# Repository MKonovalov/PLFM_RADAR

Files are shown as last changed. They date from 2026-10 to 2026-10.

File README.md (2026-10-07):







# AERIS-10: Open Source Pulse Linear Frequency Modulated Phased Array Radar








AERIS-10 is an open-source, low-cost 10.5 GHz phased array radar system featuring Pulse Linear Frequency Modulated (LFM) modulation. Available in two versions (3km and 20km range, see [Basis of the published performance numbers](#-basis-of-the-published-performance-numbers) for the detection assumptions behind the range figures), it's designed for researchers, drone developers, and serious SDR enthusiasts who want to explore and experiment with phased array radar technology.

AERIS-10 Antenna Array

## 📡 Overview

The AERIS-10 project aims to democratize radar technology by providing a fully open-source, modular, and hackable radar system. Whether you're a university researcher, a drone startup, or an advanced maker, AERIS-10 offers a platform for experimenting with beamforming, pulse compression, Doppler processing, and target tracking.

## 🔬 Key Features

- **Open Source Hardware & Software** - Complete schematics, PCB layouts, firmware, and software available
- **Dual Version Availability**:
  - **AERIS-10N (Nexus)**: 3km range with 8x16 patch antenna array
  - **AERIS-10E (Extended)**: 20km range with 32x16 dielectric-filled slotted waveguide array
- **Full Electronic Beam Steering** - ±45° electronic steering in elevation and azimuth (characterised for the 8x16 patch array in `docs/AERIS_Antenna_Report.pdf`; the 32x16 waveguide array has no published element-pattern analysis yet — see the basis section below)
- **Advanced Signal Processing** - On-board FPGA handles pulse compression, Doppler FFT, MTI, and CFAR
- **Python GUI** - User-friendly interface with map integration
- **GPS/IMU Integration** - Real-time position and attitude correction
- **Modular Design** - Separate power management, frequency synthesis, and RF boards

## 🏗️ System Architecture

AERIS-10 System Diagram

### Hardware Components

The AERIS-10 main sub-systems are:

- **Power Management Board** - Supplies all necessary voltage levels to the electronics components with proper filtering and sequencing (sequencing ensured by the microcontroller)

- **Frequency Synthesizer Board** - Uses a high-performance Low Jitter Clock Generator (AD9523-1) that supplies phase-aligned clock references for:
  - RX and TX Frequency Synthesizers (ADF4382)
  - DAC
  - ADC
  - FPGA

- **Main Board** containing:
  - **DAC** - Generates the RADAR Chirps
  - **2x Microwave Mixers (LTC5552)** - For up-conversion and IF-down-conversion
  - **4x 4-Channel Phase Shifters (ADAR1000)** - For RX and TX chain beamforming
  - **16x Front End Chips (ADTR1107)** - Used for both Low Noise Amplifying (RX) and Power Amplifying (TX) stages
  - **XC7A50T FPGA** - Handles RADAR Signal Processing on the upstream FTG256 board:
    - PLFM Chirps generation via the DAC
    - Raw ADC data read
    - Hybrid Automatic Gain Control (AGC) — cross-layer FPGA/STM32/GUI loop
    - I/Q Baseband Down-Conversion
    - Decimation
    - Filtering
    - Forward FFT
    - Pulse Compression
    - Doppler, MTI and CFAR processing
    - USB Interface
  - **STM32F746xx Microcontroller** - Used for:
    - Power-up and power-down sequencing (see Power Management Excel File)
    - FPGA communication
    - Setup and Interface with:
      - Clock Generator (AD9523-1)
      - 2x Frequency Synthesizers (ADF4382)
      - 4x 4-Channel Phase Shifters (ADAR1000) for RADAR pulse sequencing
      - 2x ADS7830 8-channel I²C ADCs (Main Board, U88 @ 0x48 / U89 @ 0x4A) for 16x Idq measurement, one per PA channel, each sensed through a 5 mΩ shunt on the PA board and an INA241A3 current-sense amplifier (x50) on the Main Board
      - 2x DAC5578 8-channel I²C DACs (Main Board, U7 @ 0x48 / U69 @ 0x49) for 16x Vg control, one per PA channel; closed-loop calibrated at boot to the target Idq
      - GPS module (UM982) for GUI map centering and per-detection position tagging
      - GY-85 IMU for pitch/roll correction of target coordinates
      - BMP180 Barometer
      - Stepper Motor
      - 1x ADS7830 8-channel I²C ADC (Main Board, U10) reading 8 thermistors for thermal monitoring; a single GPIO (EN_DIS_COOLING) switches the cooling fans on when any channel exceeds the threshold
      - RF switches

- **16x Power Amplifier Boards** - Used only for AERIS-10E version, featuring 10Watt QPA2962 GaN amplifier for extended range

- **Antenna Arrays**:
  - **AERIS-10N (Nexus)** - 8x16 patch antenna array
  - **AERIS-10X (Extended)** - 32x16 dielectric-filled slotted waveguide antenna array

- **Miscellaneous Components**:
  - Slip-Ring
  - Stepper Motor and drivers
  - Cooling Fans
  - Enclosure

### Processing Pipeline

1. **Waveform Generation** - DAC creates LFM chirps
2. **Up/Down Conversion** - LTC5552 mixers handle frequency translation
3. **Beam Steering** - ADAR1000 phase shifters control 16 elements
4. **Signal Processing (FPGA)**:
   - Raw ADC data capture
   - I/Q baseband down-conversion
   - Decimation & filtering (CIC/FIR)
   - Pulse compression
   - Doppler FFT processing
   - MTI & CFAR detection
5. **System Management (STM32)**:
   - Power sequencing
   - Peripheral configuration
   - GPS/IMU integration
   - Stepper motor control
6. **Visualization (Python GUI)**:
   - Real-time target plotting
   - Map integration
   - Radar control interface

AERIS-10 Dashboard
<!-- V6 GIF removed — V6 is deprecated. V65 Tk and V7 PyQt6 are the active GUIs. -->

## 📊 Technical Specifications

| Parameter | AERIS-10N (Nexus) | AERIS-10X (Extended) |
|---|---|---|
| **Frequency** | 10.5 GHz | 10.5 GHz |
| **Max Range** | 3 km ¹ | 20 km ¹ |
| **Antenna** | 8x16 Patch Array | 32x16 Slotted Waveguide |
| **Beam Steering** | Electronic (±45°) ² | Electronic (±45°) ² |
| **Mechanical Scan** | 360° (stepper motor) | 360° (stepper motor) |
| **Output Power** | ~1W×16 | 10W×16 (GaN amplifier) |
| **Processing** | FPGA + STM32 | FPGA + STM32 |
| **Data Interface** | FT2232H USB 2.0 — ~40 MB/s ³ | FT2232H USB 2.0 — ~40 MB/s ³ |

## 📐 Basis of the published performance numbers

The figures above are specifications the design targets, not measured results from a
built unit.  They are only meaningful with their detection assumptions attached, so:

1. **Range.** The 3 km / 20 km figures are single-pulse-budget numbers for a **1 m² RCS**
   target at long dwell (many pulses integrated coherently).  Detection range scales as the
   fourth root of RCS and as the fourth root of integration time, so the same radar sees a
   **0.01 m² target (small drone) at roughly 6 km**, not 20 km.  Quote the target RCS and
   the dwell whenever you quote a range.  The repository carries no link-budget document
   that derives these numbers; `docs/AERIS_Antenna_Report.pdf` covers antenna gain and
   element pattern only.
2. **Beam steering.** ±45° with ~2–3 dB scan loss is the characterised result for the
   **8x16 patch array** (4.72 dBi element, 21.1 dB array factor, ~25.8 dBi realised gain,
   ~75–85° element half-power beamwidth).  Applying the same figure to the 32x16
   slotted-waveguide array is an extrapolation: no element pattern, grating-lobe analysis
   or measured scan loss is published for that array yet.
3. **Data interface.** The FT2232H interface runs at 60 MHz (≈40 MB/s), while the
   400 MSPS ADC produces ≈3.2 Gbit/s raw.  The link therefore carries **processed
   detections/Doppler products only — there is no raw IQ streaming path** at full rate.
4. **The waveguide array's dimensions do not agree inside its own spec.**
   `Dielectric_Filled_Waveguide_Array_Spec.docx` states an inter-column pitch of
   λ₀/2 ≈ 14.28 mm and a **panel height (16 columns) of 223 mm**.  Sixteen columns at
   that pitch span 16 × 14.28 = **228.5 mm**, and the centre-to-centre aperture is
   15 × 14.28 = **214.2 mm** — so 223 mm matches neither convention (5.5 mm and 8.8 mm
   apart respectively).  The spec's own directivity (27.73 dBi) and EIRP (54.8 dBW) are
   derived from A = 0.173 m × 0.223 m = 0.0385 m², i.e. they use the 223 mm height.
   The fabrication drawing has to say which convention it uses before a panel is cut:
   the directivity difference is only ~0.2 dB, so the performance number stands either
   way — it is the drawing that needs reconciling with the spec table.

   **Harmonic emissions.**  Wherever EIRP is quoted above, the harmonic figure belongs with it: the
   PA's 2nd and 3rd harmonics (21.0 and 31.5 GHz) are suppressed by the inline output filter, whose
   specification is in `docs/harmonic-filter.md`.  The chosen part rejects **≥40 dB across
   19.5–32 GHz**, against a requirement of ≥20 dB below carrier at the antenna port — so the design
   carries 20 dB of margin, and the *measured* figure is a first-article item recorded in
   `docs/bring-up-acceptance.md`.

## 🚀 Getting Started

### 🧹 Repository File Placement Policy

To keep the repository root clean and make artifacts easy to find, place generated files in the following locations:

- **Published reports (tracked, GitHub Pages):** `docs/`
  - Example: `docs/AERIS_Simulation_Report_v2.pdf`
- **Simulation-generated outputs (local, gitignored):** `5_Simulations/generated/`
  - Plots, scenario outputs, temporary analysis directories
- **FPGA/Vivado generated artifacts (local, gitignored):** `9_Firmware/9_2_FPGA/reports/`
  - VCD/VVP dumps, temporary CSVs, local report snapshots
- **Reusable FPGA automation scripts (tracked):** `9_Firmware/9_2_FPGA/scripts/`
  - TCL flows, helper scripts used by build/bring-up
- **Generated board artifacts (tracked):** `4_Schematics and Boards Layout/4_7_Production Files/Board_Artifacts/`
  - BOM/CPL CSVs, the DNP list, the inter-board rail map and the accepted-discrepancy baseline,
    all regenerated by `9_Firmware/tools/` and checked in CI

**Do not leave generated artifacts in the repository root.**

### Prerequisites

- Basic understanding of radar principles
- Experience with PCB assembly (for hardware build)
- Python 3.8+ for the GUI software
- FPGA development tools (Vivado) for signal processing modifications

### Hardware Assembly

1. **Order PCBs**: Production outputs are under `/4_Schematics and Boards Layout/4_7_Production Files`
2. **Source Components**: BOM/CPL files are co-located under `/4_Schematics and Boards Layout/4_7_Production Files`
3. **Assembly**: Use the schematics in `/4_Schematics and Boards Layout/4_6_Schematics` together with the production outputs above; a standalone assembly guide is not currently tracked
4. **Antenna**: Choose appropriate array files for your target variant
5. **Enclosure**: Mechanical drawings currently live in `/8_Utils/Mechanical_Drawings`

## 📜 License

This project is open-source but uses **different licenses for hardware and software** to ensure proper legal coverage.

### Hardware Documentation
The hardware design files—including:
- Schematics and PCB layouts (in `/4_Schematics and Boards Layout`)
- Bill of Materials (BOM) files
- Gerber files and manufacturing outputs
- Mechanical drawings and enclosure designs

are licensed under the **CERN Open Hardware Licence Version 2 – Permissive (CERN-OHL-P)** .

This is a hardware-specific license that:
- ✅ Clearly defines "Hardware," "Documentation," and "Products"
- ✅ Includes explicit patent protection for contributors and users
- ✅ Provides stronger liability limitations (important for high-power RF)
- ✅ Aligns with professional open-hardware standards (CERN, OSHWA)

You may use, modify, and sell products based on these designs, provided you:
- Maintain the original copyright notices
- Distribute any modified designs under the same license
- Make your modifications available in Source format

### Software and Firmware
The software components—including:
- FPGA code (VHDL/Verilog in `/9_Firmware`)
- Microcontroller firmware (STM32)
- Python GUI and utilities

remain under the **MIT License** for maximum flexibility.

### Full License Texts
- The complete CERN-OHL-P license text is in the `Licence` file (note the spelling — there is no `LICENSE` file)
- The MIT text covering `9_Firmware` (MCU firmware, FPGA RTL, tools) and the GUI/SDK is in `9_Firmware/LICENSE`

### Why This Change?
Originally, the entire project used the MIT license. The community (special thanks to gmaynez!) pointed out that MIT lacks legal protections needed for physical hardware. The switch to CERN-OHL-P ensures the project is properly protected while maintaining the same permissive spirit.

## 📚 Documentation

Comprehensive documentation is available in the `/docs` folder and served via GitHub Pages at [https://NawfalMotii79.github.io/PLFM_RADAR/docs/](https://NawfalMotii79.github.io/PLFM_RADAR/docs/):

- [System Architecture](/docs/architecture.html)
- [Implementation Log](/docs/implementation-log.html)
- [Hardware Bring-Up Guide](/docs/bring-up.html)
- [Test Reports](/docs/reports.html)
- [Release Notes](/docs/release-notes.html)

### 🔧 Regenerating the BOM and CPL

The production BOM/CPL for each board is generated from the Eagle board files rather than
transcribed by hand, so it can be checked instead of trusted:

```bash
python3 9_Firmware/tools/regenerate_bom.py . --check
```

`--check` exits non-zero when a placed part is missing from a committed BOM spreadsheet,
when a sheet lists a designator that is not on the board, or when a placed part has no
orderable value/MPN.  Run it before ordering boards.

## 🤝 Contributing

We welcome contributions! Please see our [Contributing Guidelines](/CONTRIBUTING.md) for details on repo layout, branch workflow, and basic PR checks.

Areas where help is especially appreciated:
- **RF Engineers**: Review designs, optimize antenna performance
- **FPGA Developers**: Optimize signal processing pipeline
- **Software Developers**: Enhance Python GUI and SDK
- **Beta Testers**: University researchers, drone startups, advanced makers

## 📞 Contact & Collaboration

I welcome serious inquiries from researchers, engineers, and potential collaborators. However, due to the high volume of interest in this project, please understand that I cannot guarantee a response to every message.

- **Technical questions or bug reports**: Please [open a GitHub issue](https://github.com/NawfalMotii79/PLFM_RADAR/issues) so the whole community can benefit from the discussion.
- **Collaboration, licensing, or business inquiries**: 📧 nawfal.motii.33 [at] gmail [dot] com

## 💰 Sponsors

PCBWay Sponsor Logo

---

**Star ⭐ this repository if you're interested in open-source radar technology!**

*Note: This is an active development project. Some features are still in progress. Check the issues page for known limitations and upcoming features.*

## 19,000 stars – Thank you

This project started in a small workshop in Morocco. Today, 19,000 engineers on GitHub have starred it.

I am genuinely humbled.

**What this tells me:**

- Open source radar matters
- Affordable sensing is needed
- Engineers want to build, not just buy

Thank you to everyone who starred, forked, opened issues, submitted PRs, and shared this project.

The work continues.

**Nawfal Motii**
ABAC INDUSTRY
(http://www.abacindustry.com)

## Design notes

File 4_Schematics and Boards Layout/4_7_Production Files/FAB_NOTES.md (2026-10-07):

# Fabrication and assembly notes (per board)

**Why this file exists.** The repo carries one good document — `PCBWay_Impedance_Note_RO4350B_h0p102mm.pdf`
— and no per-board statement of material, stackup, impedance or assembly requirements. A fab
or assembly PO that does not carry those requirements explicitly is a PO that will be built to
defaults. This file is the callout to attach to the PO; the PDF stays as the detailed
impedance note it already is.

Nothing here is new engineering: the numbers are read off the existing note and the board
files, so that the PO and the design cannot drift apart.

## 1. Boards, layers and material

Copper layer counts are read from each `.brd` (layer numbers ≤ 16), and match the quotations
obtained earlier from PCBWay.

| Board | File | Copper layers | Material callout | Notes |
|---|---|---|---|---|
| Main board | `RADAR_Main_Board.brd` | **10** (1–5, 12–16) | **Rogers RO4350B**, h = 0.102 mm | the RF board: carries the 10.5 GHz TX/RX paths, the ADC LVDS and the FPGA |
| Frequency synthesizer | `Clocks_Freq_Synth_board.brd` | **6** (1–3, 14–16) | FR-4 unless a controlled-impedance run is required | clocks to 3.6 GHz internal, 300/400 MHz outputs; LVDS pairs benefit from impedance control |
| Power amplifier | `RF_PA.brd` | **4** (1, 2, 15, 16) | **Rogers RO4350B, h = 0.102 mm** (decided; see below) | carries the 10.5 GHz RF in/out and the 22 V drain network |
| Power board | `PowerBoard.brd` | **2** (1, 16) | FR-4 | DC only |
| Patch antenna array | (gerbers only) | 4 | **to be re-specified on any redraw** (see below) | the radiating surface itself is at 10.5 GHz |

**Decided: the PA board moves to RO4350B.** Both RF boards were carrying 10.5 GHz with no
laminate callout. FR-4's loss tangent is ~0.02 at 10 GHz against RO4350B's ~0.0037, and — more
important for a 16-element array — FR-4's Dk varies meaningfully lot to lot, which lands
directly in the element-to-element phase calibration budget. The PA board is 4 layers at
60 × 35 mm, so the material delta is small against the array it feeds.

The PA board therefore uses the same stackup as the main board, and the controlled-impedance
section below applies to its RF traces as well. Its RF geometry should be re-solved for the
0.102 mm core rather than copied from the main board, because the trace widths depend on the
layer's distance to the reference plane.

**The patch array cannot be changed the same way**: it ships gerbers only, with no `.brd`, so
it cannot be re-spun from this repo at all. Any redraw must carry the laminate callout, and
until then its material is whatever those gerbers were cut on. That is recorded here rather
than silently inherited.

## 2. Controlled impedance (RF boards: main board and PA board)

From `PCBWay_Impedance_Note_RO4350B_h0p102mm.pdf`:

* Material RO4350B, dielectric thickness **h = 0.102 mm**;
* design Dk **3.66**, process Dk **3.48 ± 0.05** (IPC clamped);
* copper 35 µm base, ~40–45 µm finished;
* targets: **Z0 = 50 Ω ± 10 %** single-ended, **Zdiff = 100 Ω ± 8 %** differential;
* starting geometry (maskless microstrip): w = **0.204 mm**, diff-pair gap s = 0.26 mm.

**The design agrees with the note**: the main board's dominant top-layer trace width is
**0.204 mm** (2591 segments), with 0.2 mm on a further 2079 — a 2 % difference, inside the
±10 % target. Two widths coexist, so the PO should state a tolerance that covers both rather
than a single nominal.

## 3. Requirements to put in the PO (all boards)

1. **Coupon / TDR report is a deliverable.** The note already says the geometries are
   "starting points for PCBWay CAM to field-solve and tune with coupons" — make the coupon
   report part of the deliverable, not an option.
2. **Maskless RF traces** on the laminate boards (the note: "solder mask: none, maskless RF
   traces over air"). A mask over the RF layer changes the effective Dk and therefore the
   impedance; state it explicitly.
3. **Continuous reference plane** beneath the RF and LVDS routing — no splits or slots under
   a pair (the note's routing rule).
4. **Stackup drawing in the PO**, matched to the impedance note's h = 0.102 mm; a fab that
   substitutes a different prepreg thickness invalidates the geometry.
5. **Assembly**: `BOM_*.xlsx` + `CPL.xlsx` per board are the authoritative pair (both
   generated from the `.brd`), and `Board_Artifacts/DNP_list.csv` states what must not be
   fitted. Note that the PA board's `BOM.xlsx` and `BOM_PA.xlsx` both exist — the PO must name
   which one is authoritative.

## 4. Known deviations that the PO should not silently accept

* The patch-array board ships **gerbers only** (no `.brd`), so it cannot be re-spun from this
  repo without redrawing it; any change to the array is a new design, not an edit.
* `9_Firmware/9_2_FPGA` targets **XC7A100T** while the BOM lists the XC7A50T — the fab/assembly
  must be told which part is stuffed (the 50T cannot hold the integrated firmware).

## 5. Thermal path for the PA board (issue #5)

**Re-derived for the QPA1010** (issue #21): 16 devices at 24 V / 600 mA dissipate **230 W** standing
and **~397 W under drive**, which into a 40 °C ambient with an 85 °C case ceiling is **1.81 °C/W per
device** case-to-ambient in the binding (driven) case, or **0.113 °C/W for the array**.

**What the board provides:** 128 vias at 0.15 mm drill, of which ~104 sit in the densest cluster. A
0.15 mm plated via through 1.6 mm FR-4 is commonly taken at 80–120 °C/W, so the field is worth
**0.77–1.15 °C/W per device** — which leaves **~0.7–1.0 °C/W** for the interface and heatsink. A good
forced-air heatsink is 0.5–1 °C/W, so **forced air suffices**, where the previous device needed the
same field to work with no margin at all.

So the board path is adequate and nothing about it needs changing. What it does *not* do is leave room
for the thermal interface and the heatsink, and that is what the issue's mechanical items are for.
They belong in the PO, not in the layout:

- **A pedestal to the chassis** under each PA board, so the heat leaves through metal rather than
  through the board alone. Still worth having — it is the cheapest way to buy back margin — but it is
  now margin rather than a requirement, which is the change the device migration bought.
- **A copper coin under the device paddle** if the pedestal route is not taken, or if the acceptance
  soak shows the margin has gone. It is a fab option on the PA stackup (Rogers RO4350B, per #24) and
  must be in the PO — it cannot be added after the boards are made.

**How this is verified:** the acceptance soak at 10 % duty with a baseplate thermistor. The eight
thermistor channels and the firmware's 75 °C limit are already in place — see
`docs/temperature-channels.md` and `docs/bring-up-acceptance.md`.

**On the estimate above:** the per-via figure is a common rule of thumb for a 0.15 mm plated via, not
a measurement, and the count is from the board file rather than a thermal simulation. It is stated
with its basis for that reason — **the acceptance soak is what settles it**, and the note exists so
the soak has something to be compared against.

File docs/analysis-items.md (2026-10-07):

# The three analysis items: #5 (thermal requirement), #19 (inrush), #21 (migration)

These three are not bench steps waiting on hardware — they are questions with enough data in hand
to answer now. Each answer is a number or a choice, not a procedure.

## #5 — the thermal requirement, as a specification

The issue's finding is that nothing in the design or docs states a thermal requirement: no heatsink,
no airflow figure, no duty limit. The arithmetic sets one.

Per device, from the QPA2962 brief:

```
P_DISS  = 36.96 W      (VD = 22 V, IDQ = 1680 mA, no RF)
theta_JC = 2.83 degC/W
T_CH    = 189 degC     at T_BASE = 85 degC
```

**Re-derived for the QPA1010** (issue #21; the figures above are the QPA2962's and are kept only as
the comparison). The array is sixteen devices at 24 V and 600 mA quiescent, so **230.4 W** standing —
and **396.8 W** under drive, because driven dissipation (24.8 W) exceeds quiescent (14.4 W):

| | per device | array |
|---|---|---|
| dissipation, standing | 14.4 W | 230.4 W |
| dissipation, driven | **24.8 W** | **396.8 W** |
| allowed rise (85 − 40 °C) | 45 K | 45 K |
| required case-to-ambient θ, standing | **3.13 °C/W** | **0.195 °C/W** |
| required case-to-ambient θ, **driven** | **1.81 °C/W** | **0.113 °C/W** |

**Driven is the binding case** — the opposite of the old device, where quiescent was the larger
figure. A plan written against the standing number would be planning for 1.7× less dissipation than
the part actually produces under drive.

**What that means against the board.** The via field is worth ~0.77–1.15 °C/W per device, so against
the driven requirement of 1.81 °C/W it leaves roughly **0.7–1.0 °C/W** for the thermal interface and
the heatsink. A good forced-air heatsink is 0.5–1 °C/W, so **forced air suffices under drive** — and
at the radar's 10 % transmit duty, where the drain is pulsed per the datasheet's own test conditions
(PW = 100 µs, DC = 10 %), the average load is far lower again.

The old requirement was 1.22 °C/W per device that the same field met *with no margin*, and 0.076 °C/W
for the array which needed a liquid-cooled plate. **The migration removes that** — it is the single
largest practical consequence of the device change, and it is worth stating plainly because the
issue's own framing ("the binding constraint is arithmetic not copper") stops being true.

**Airflow.** The old 69 CFM / 7 CFM figures were derived against 592 W and no longer apply. The
requirement falls by roughly the ratio of the dissipations (2.6×), which puts it in the range of a
small fan rather than a blower — but the exact figure follows the chosen heatsink's own θ-versus-flow
curve, so it is stated as a scaling here and pinned when a heatsink is chosen.

The channel limit itself is not in doubt: `PA_THERMAL.h` now carries the QPA1010's θJC of 2.60 °C/W,
which puts the channel at 150 °C for an 85 °C case at the driven dissipation, and reaches the 200 °C
design limit only at a case of 135 °C. `test_pa_thermal.c` checks the model against the datasheet.

## #19 — the inrush, bounded, with the one number that decides it

The `+3V3_XO` rail carries the OCXO plus the rest of its domain, about **1.25 A** steady, on a
**TPS7A8300 rated 2 A** — roughly **62 % loaded before any warm-up transient**. So the headroom is
about **0.75 A**.

The 88 µF of bulk on that rail does **not** cover a warm-up surge, and it is worth showing why:

```
I*t/C = 500 mA * 1 ms / 88 uF = 5.7 V of droop
```

To hold a 1 ms surge to even 100 mV would need **5000 µF** — so bulk is not the answer here; the
regulator has to source it. That makes the deciding number the OCXO's warm-up current, which is not
in the datasheet's extractable text (the tables are images) and has to be read from the document or
asked of ECS.

**The requirement, stated so it can be checked:** total rail current during warm-up must stay
**≤ 2.0 A**, i.e. the OCXO's warm-up surge must not exceed about **0.75 A** above the rest of the
domain. If it does, the fix is a higher-current regulator for that domain, not more capacitance.

## #21 — the QPA1010 migration: it is not a drop-in, and it makes #5 harder

The candidate is a real part with published numbers:

| | QPA2962 (current) | QPA1010 (candidate) |
|---|---|---|
| band | 10.5 GHz operation | **7.9 – 11 GHz** — covers it |
| saturated output | ~10 W | **15 W** |
| technology | GaN | GaN on SiC |
| gate bias | negative, VGG then VD | same class — negative, gate then drain |

So the band is covered and the bias *sequence* is the same kind of thing the firmware already
implements (`PA_BIAS_SEQUENCE`, and the ADTR1107's documented order in `docs/power-up-order.md`).

**But it is not a like-for-like swap, and the interaction matters:** 50 % more saturated output
means **more dissipation**, not less — which tightens the #5 thermal requirement above rather than
easing it. Any decision to migrate should be made with that arithmetic in hand, not after.

**What the decision actually turns on** (and why it is the owner's, not mine):

1. **Export status.** The issue's premise is that the QPA2962 is export-restricted. Both parts are
   Qorvo GaN, so this has to be established for the QPA1010 specifically rather than assumed to be
   better — that is the whole point of the migration.
2. **Sourcing.** Sixteen devices; the migration is only worth doing if the replacement is actually
   obtainable in that quantity.
3. **Thermal headroom.** Whether the array can take the extra dissipation, which is the #5 choice
   above.

The bias-table port itself is the small part of the work: `PA_GATE_BIAS.h` expresses VGG as
`-(Rf/Rin)*(code/255)*VREF` with a −1.20 V floor, and a new device needs a new table and a new
floor — the mechanism is unchanged.

## Correction: #19's numbers, from the vendor datasheet

The issue was built on "the ECOC-2522 OCXO at ~1.2 A". The datasheet gives the figure directly, and it is
much lower:

| Parameter | Datasheet | At 3.3 V |
|---|---|---|
| Power consumption, at turn on | **3.6 W** | **1.09 A** |
| Power consumption, steady state | **1.4 W** | **0.42 A** |

So the rail is **21 % loaded steady and 55 % at turn-on** — not 62 % — against a 2 A regulator. The
acceptance criterion "no rail above ~70 % of its device rating" is met with room to spare, and there is no
current-limit droop to avoid.

Sequencing the OCXO alone is also not available: the padout is 1 = Voltage Control, 2 = V Ref,
3 = Supply Voltage, 4 = Output, 5 = Ground — **no enable pin**. It would need an added load switch, which
the numbers show is unnecessary.

Two earlier claims in this repository are corrected by the same table: that no vendor data was reachable,
and that the datasheet's tables were image-based. Both were wrong; the PDF extracts cleanly.

## #5 addendum: the airflow figure the issue asks for

The issue's "what is needed" list includes "a documented airflow figure". Computed for the array
(16 devices at 36.96 W = 591 W), with a 40 °C ambient, an 85 °C case target, and a 15 K rise allowed
in the air (ρ = 1.2 kg/m³, cp = 1005 J/kg·K):

| duty | dissipated | required airflow | θ case→ambient, array | per device |
|---|---|---|---|---|
| **10 % (the acceptance case)** | 59 W | **≈ 7 CFM** | **0.76 °C/W** | 12.2 °C/W |
| continuous | 591 W | **≈ 69 CFM** | 0.076 °C/W | 1.2 °C/W |

**Re-derived for the QPA1010** with the same formula and the same 15 K air rise:

| duty | dissipated | required airflow | θ case→ambient, array | per device |
|---|---|---|---|---|
| standing, drain up, no RF | 230 W | **≈ 27 CFM** | **0.20 °C/W** | 3.1 °C/W |
| driven, 15 W RF out | 397 W | **≈ 46 CFM** | **0.11 °C/W** | 1.8 °C/W |
| **10 % duty (the acceptance case)** | 23 W | **≈ 3 CFM** | **1.96 °C/W** | 31.3 °C/W |

**What that changes.** The continuous row is the one that mattered: the previous device needed
**69 CFM** at continuous duty, which is why the earlier conclusion was that the array needed
*liquid cooling or a very large forced-air assembly*. At **27 CFM** the QPA1010 is served by an
ordinary fan on a normal heatsink, and the acceptance case falls to about **3 CFM**.

So the airflow requirement is met by the simplest possible answer, and the pedestal/copper coin
the issue also asks for stop being prerequisites and become margin. The per-device column is the
figure to compare against the board's via field (~0.77–1.15 °C/W).

The acceptance soak is specified at **10 % duty**, and that row is the practical one: **a normal
heatsink with a small fan** (12 °C/W per device, ~7 CFM) meets it with margin. The continuous row is
what forces liquid cooling or a large forced-air assembly, and it is the reason the requirement has
to be stated as a choice rather than a single number.

The baseplate thermistor the issue also asks for is already provided for: the eight NTC channels on
the main board are external flying-lead probes on 3-pin headers (JP5/JP6/JP11/JP12/JP14/JP15/JP16/JP19),
so one can be attached to the baseplate and read by the MCU with no further hardware — see
`docs/temperature-channels.md`.

## #21 CORRECTION: the QPA1010 dissipates about HALF as much, not more

The earlier analysis in this file said the migration "tightens #5 rather than easing it", reasoning
from 15 W against 10 W. **That was wrong**, and the datasheet says so plainly.

| | QPA2962 (current) | QPA1010 (candidate) |
|---|---|---|
| Drain voltage (VD) | 22 V | **24 V** |
| Quiescent drain current (IDQ) | 1680 mA | **600 mA** |
| Gate voltage range (VG) | −1.2 to −2.5 V | **−2.9 to −1.5 V** |
| **Power dissipation, driven** | **36.96 W** | **17.7 W** |
| Channel temperature at TBASE = 85 °C | 189 °C | **131 °C** |
| θJC (derived from the two rows above) | 2.83 °C/W | **2.60 °C/W** |
| Power-added efficiency | 22 % | **38 %** |
| Saturated output | ~10 W | 15 W (42 dBm at PIN = 24 dBm) |
| Package | — | 24-lead 4.5 × 5.0 × 1.72 mm air-cavity laminate |
| Compliance | — | **Lead-free and RoHS compliant** |

The reason is efficiency: 38 % PAE against 22 % means that for **more** output power it dissipates
**less**. The QPA1010's own thermal row gives PDISS = 17.7 W at 41.4 dBm output, against the
QPA2962's 36.96 W.

**What that means for the array:**

| | QPA2962 | QPA1010 |
|---|---|---|
| array dissipation (×16), standing | 592 W | **230 W** |
| array dissipation (×16), driven | 473 W | **397 W** |
| required θ case→ambient, standing | 0.076 °C/W | **0.195 °C/W** |
| required θ case→ambient, **driven (binding)** | 0.095 °C/W | **0.113 °C/W** |
| required airflow | 69 CFM at 592 W | falls ~2.6×; see the re-derivation above |

**The 283 W in the earlier version of this table was wrong** — see the correction note below, which
explains where it came from. The figures here are recomputed from the QPA1010's own bias point.

So the migration would roughly **halve** the thermal load and make the #5 requirement considerably
easier — possibly bringing continuous duty within reach of air cooling rather than liquid cooling.
It also removes a procurement constraint: the part is RoHS compliant, which the FLP-1250 filter is
not (see `docs/harmonic-filter.md`).

Two other differences worth noting for the port: IDQ drops from 1680 mA to 600 mA, which changes the
bias table's operating point, and the gate range shifts to −2.9…−1.5 V. The *sequence* is unchanged
in kind — negative gate, then drain — which is what `PA_BIAS_SEQUENCE` and the ADTR1107's documented
order already implement.

## #21 — the decision inputs, researched

The issue's question is whether to migrate the PA from the QPA2962 to the QPA1010. Three of the four
inputs turn out to point the same way, and one of them is new.

### Export classification — from Qorvo's own ECCN tool, not a distributor

Qorvo publishes an ECCN lookup and its page is backed by a public endpoint
(`/api/pim/SearchEccnData?partNumber=…`), so this is the manufacturer's own classification:

| Orderable part | ECCN | HTS |
|---|---|---|
| `QPA2962`, `QPA2962S2`, `QPA2962TR7` | **3A001.B.2.C** | 8542330001 |
| `QPA1010TR7`, `QPA1010D` | **3A001.B.2.B.2** | 8542330001 |
| `QPA2962EVB`, `QPA1010PCB4B01` (evaluation boards) | **EAR99** | 9030820000 |

**Both parts are export-controlled.** The migration does not buy an easier classification; it moves
from the general clause to the one high-power X-band GaN amplifiers carry. Evidence for how the two
paragraphs are applied in practice: Amcom's 8 W 2–18 GHz, MACOM's X-band 12 W and Qorvo's own
TGA2625 all carry `3A001.b.2.b.2`, while broadband driver MMICs (Hittite's, `CMD304`, `MMA-172135D`)
carry `3A001.b.2.c`. **Stated as the manufacturer's classification plus the vendor pattern, not as
the letter of the regulation**, which was not read in full.

Worth noting for evaluation: **the evaluation boards are EAR99** even though the devices are not.

### Availability — and this one reverses the picture

At the time of checking:

- **`QPA2962` — Mouser: "Lifecycle: Restricted. Availability: This part number is not currently
  available from Mouser."** The incumbent is hard to obtain.
- **`QPA1010TR7` — DigiKey: "Buy now, ships today."** The candidate is in stock.

So the part in the current design is the one with the availability problem. That is a stronger
argument for evaluating the migration than either the thermal or the RoHS point.

### Minimum order

- the candidate's **packaged** variant is `QPA1010TR7` only — a **250-piece reel**;
- the current part offers `S2` (2), `(25)` and `TR7` (250) — small quantities, when available;
- a die option exists (`QPA1010D`, ≈ $292 each at 10 pieces, not stocked at DigiKey).

A 16-device array therefore means buying a 250-piece reel, or using die.

### The rest, from the earlier analysis

| | QPA2962 | QPA1010 |
|---|---|---|
| dissipation per device, standing | 36.96 W | **14.4 W** (24 V × 0.6 A quiescent) |
| dissipation per device, driven | 35.5 W | **24.8 W** (P_DC 39.8 W − 15 W RF, at 37.7 % PAE) |
| array, standing (×16) | 592 W | **230 W** |
| required θ, array (40 → 85 °C) | 0.076 °C/W | **0.196 °C/W** |
| required θ per device | 1.22 °C/W | **3.13 °C/W** |
| via field provides | 0.77–1.15 °C/W | 0.77–1.15 °C/W → **2.7–4× margin** |
| channel temperature at 85 °C base | 189 °C | **150 °C** (85 + 2.60 × 24.8) |

**Correction to an earlier figure in this document.** A previous version of this table said the
QPA1010 array dissipates **283 W**. That was wrong: 16 × 24 V × 0.6 A = **230 W** standing. The
error came from scaling the old device's array figure by a ratio rather than recomputing it from
the new device's own bias point — the same shortcut that the row-by-row figures above avoid. The
direction of the conclusion is unchanged (the migration roughly halves the standing load), but the
number quoted on issue #21 was not the number the arithmetic gives, and it is corrected here.

**And the safe planning figure changes side.** For the QPA2962 the *quiescent* dissipation (36.96 W)
exceeded the driven one (35.5 W), so quiescent was conservative. Here **driven (24.8 W) is nearly
twice quiescent (14.4 W)**, so driven is the figure to plan with. Anyone carrying the old habit
across would plan against half the real load — which is why `PA_THERMAL.h` now derives
`PA_PDISS_PLAN_W` as the larger of the two rather than naming one.

The device is also specified **pulsed** (PW = 100 µs, DC = 10 %), which is the radar's own duty, so
under a 10 % transmit the drain is pulsed and the average load is far below the standing figure.
| VD / IDQ | 22 V / 1680 mA | 24 V / 600 mA |
| gate range | −1.2 … −2.5 V | −2.9 … −1.5 V |
| RoHS | — | **compliant** (the chosen filter is not) |

### What the decision actually turns on

Migrating would **halve the thermal load**, remove the RoHS gap, and use a part that is **in stock**
rather than one that is not. Against that: a **new bias operating point** (a firmware change), a
**250-piece reel** minimum, and a **different ECCN sub-paragraph** — not an easier one.

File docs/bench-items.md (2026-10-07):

# The six "bench step" items: what research changed, and what is now in the design

These six issues were each classified as "the mechanism is implemented, the number needs
hardware". Research changed that for most of them — two of the three "no data available" claims
turned out to be wrong — and the rest are now instrumented so the bench step is a readout rather
than an experiment.

## #5 PA thermal — the datasheet has the number that was assumed unavailable

The issue said Qorvo's Rth was NDA-gated. It is in the brief, in the thermal section:

```
Thermal Resistance (theta_JC)  2.60 degC/W                    <- QPA1010, the chosen device
    T_BASE -40 to +85 degC, VD = 24 V, IDQ = 600 mA
    quiescent P_DISS = 24 x 0.6 = 14.4 W
    driven  P_DISS = 39.8 - 15 = 24.8 W   (P_DC 15 W / 37.7 % PAE, minus the RF that leaves)
```

The model is one multiplication above the case, so a measured case temperature converts to a channel
temperature directly. **For this device driven is the safe planning number, not quiescent** — the
opposite of the QPA2962, whose quiescent dissipation (36.96 W) exceeded its driven figure (35.5 W).
`PA_THERMAL.h` derives `PA_PDISS_PLAN_W` as the larger of the two rather than naming one, so the
direction cannot be got wrong by habit.

**What that says about the design.** The channel limit (200 °C design) is reached at a case
temperature of **135 °C**, and the datasheet's own T_BASE maximum of 85 °C binds long before it. At
the firmware's 75 °C sensor limit the channel sits at `75 + 2.60 x 24.8 = 139 °C`, well inside.
`test_pa_thermal.c` checks the model against the datasheet, so the numbers cannot drift.

**A real bug it exposed.** The PA over-temperature check read:

```c
int Max_Temp = 25;      // ...while the comment beside it said ">75 C"
```

25 °C would trip constantly — or, since no board populates the sensors, never. It now reads 75,
which the physics supports (75 + 2.60 x 24.8 = 139 °C channel, inside the limit).

**The remaining gap is hardware, and it is specific:** the firmware declares eight sensors
(`Temperature_1..8`) and **no board has one**. That is what this issue needs: eight case
thermistors (one per PA pair, matching the firmware's eight variables) and a decision on how they
reach the MCU, because the harness has no spare position. That decision is the owner's, not mine
to guess.

## #7 harmonic filtering — the level is characterized, so it can be read rather than measured

The brief carries a harmonics section: 2nd and 3rd harmonic versus P_OUT versus temperature,
versus V_D and versus I_DQ. So the required filter order follows from plots that already exist —
the numbers are in the PDF's graphs rather than in its text layer, so they have to be read by eye,
but that is a different task from "build the board and measure it".

The requirement stands as written (≥ 35 dB at 21.0 and 31.5 GHz), and the interface is
unchanged: one inline SMA-to-SMA filter per element between `J2` and the antenna, no board
change. With the PA's own harmonic level read off the plots, the order is a calculation rather
than a bench campaign.

## #19 OCXO inrush — the vendor and the datasheet are located

The part is **ECS Inc. ECOC-2522-100.000-3HC**, and its datasheet is at
`ecsxtal.com/store/pdf/ECOC-2522.pdf`. The claim that no vendor data was reachable is no longer
true. The parameter table does not survive text extraction (the PDF's tables are image-based), so
the steady and warm-up currents have to be read from the document rather than parsed.

The design-side answer, computed: the `+3V3_XO` rail carries 88 µF of added bulk on a
TPS7A8300 rated 3 A. Inrush into that bulk is bounded by the regulator's current limit — roughly
`3 A / 88 µF = 34 V/ms`, so the rail reaches 3.3 V in about 0.1 ms. What the bulk *cannot* cover
is a sustained warm-up surge: at 500 mA for 1 ms the droop is `I·t/C = 5.7 V`. So the honest
statement is that the inrush is bounded but the OCXO's warm-up profile decides whether the bulk
is adequate — which is exactly the bench capture this issue asks for, now with a located source
and a computed requirement rather than a guess.

## #20 the supply order — verifiable in the design, once the rails can be sensed

The order is documented, cited and locked by `test_adar_power_order.c`, so what remains is
observing it on real hardware. The ADAR rails are generated by TPS562208 bucks (`U6`, `U7`,
`U13`), which have **no PG pin**, so the existing rail-good monitoring cannot see them.

Making the order self-verifying needs rail sensing: two free MCU ADC channels with dividers on
`+3V3_ADAR12` and `-5V0_ADAR12`, sampled during the sequence. That turns the scope capture into a
telemetry field. It is specified here rather than implemented because it adds two nets and a
wiring decision, and because the firmware already asserts the order that the test protects.

## #13 dropped strobe — now a self-test, not an assumption

`StrobeAck_SelfTest_*` raises a strobe at bring-up and watches for the acknowledgement, retrying
three times (a chirp already in flight will legitimately drop one). The result appears in
telemetry as `StrobeAckPath`. The *functional* case — a strobe dropped mid-chirp — remains what
the miss counter is for, and a bench check can force it by issuing two strobes back to back.

## #14 the ADC answers — now a self-test with known values

The single hopeful read of `0x2A` is replaced by a read of two registers whose defaults the
datasheet states: `0x00 CHIP_PORT_CONFIG = 0x18` and `0x2A OVR_CONFIG = 0x01`. Nothing is
written, so the test is safe at any time, and a dead bus shows up as all-zero or all-one rather
than as a plausible-looking value. Telemetry reports both readings and the verdict as
`ADC_SPI` / `ADC_OVR`.

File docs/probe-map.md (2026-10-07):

# Probe map

Generated by `9_Firmware/tools/probe_map.py` from the board netlists - do not edit.

No board in this repo carries a test point (issue #15), so the access points
below are **existing pins**: a harness connector where one is on the net,
otherwise the part pin. Rail nominals are parsed from the net names; signal
levels come from the bank the driving pin sits in.

Rail tolerance used for acceptance: **+/-5 % (probe acceptance; the regulators themselves are tighter)**.

## Main board

| Rail | Nominal | Probe at |
|---|---|---|
| `+1V0_FPGA` | +1.0 V | X8 pin S (harness connector) |
| `+1V8_CLOCK` | +1.8 V | X17 pin S (harness connector) |
| `+1V8_CLOCK_F` | +1.8 V | L1.2 |
| `+1V8_FPGA` | +1.8 V | X10 pin S (harness connector) |
| `+2V5_FPGA` | +2.5 V | X57 pin S (harness connector) |
| `+3V3` | +3.3 V | X24 pin S (harness connector) |
| `+3V3_ADAR12` | +3.3 V | X20 pin S (harness connector) |
| `+3V3_ADAR1_F` | +3.3 V | L11.2 |
| `+3V3_ADAR2_F` | +3.3 V | L12.2 |
| `+3V3_ADAR34` | +3.3 V | X21 pin S (harness connector) |
| `+3V3_ADAR3_F` | +3.3 V | L13.2 |
| `+3V3_ADAR4_F` | +3.3 V | L14.2 |
| `+3V3_ADTR` | +3.3 V | X4 pin S (harness connector) |
| `+3V3_AN` | +3.3 V | X9 pin S (harness connector) |
| `+3V3_AN1_F` | +3.3 V | L15.2 |
| `+3V3_AN2_F` | +3.3 V | L16.2 |
| `+3V3_AN3_F` | +3.3 V | L17.2 |
| `+3V3_AN4_F` | +3.3 V | L18.2 |
| `+3V3_AN5_F` | +3.3 V | L21.2 |
| `+3V3_AN6_F` | +3.3 V | L23.2 |
| `+3V3_FPGA` | +3.3 V | X16 pin S (harness connector) |
| `+3V3_VDD_SW` | +3.3 V | X12 pin S (harness connector) |
| `+3V4` | +3.4 V | X54 pin S (harness connector) |
| `+5V0_0` | +5.0 V | X18 pin S (harness connector) |
| `+5V0_PA_1` | +5.0 V | X14 pin S (harness connector) |
| `+5V0_PA_2` | +5.0 V | X5 pin S (harness connector) |
| `+5V0_PA_3` | +5.0 V | X7 pin S (harness connector) |
| `+5V5_PA` | +5.5 V | X55 pin S (harness connector) |
| `-3V3_SW` | -3.3 V | X6 pin S (harness connector) |
| `-3V4` | -3.4 V | X11 pin S (harness connector) |
| `-5V0_ADAR12` | -5.0 V | X13 pin S (harness connector) |
| `-5V0_ADAR34` | -5.0 V | X15 pin S (harness connector) |
| `-5V5_PA` | -5.5 V | X19 pin S (harness connector) |

| Signal | Levels | Driven by | Probe at | Note |
|---|---|---|---|---|
| `ADC_PWRD` | 0 / 2.5 V | U42 (bank 14, LVCMOS25) via R36 | U42.IO_L23N_T3_A02_D18_14 | ADC power-down; bank 14 is 2.5 V after the bank-14 change |
| `M3S_VCTRL` | 0 / 3.3 V | U42 (bank 15, LVCMOS33) | U42.IO_L24N_T3_RS0_15 | common control for 16 RF switch VCTRL pins |
| `VG_1 ... VG_16` | -4.99 V at reset (DAC code 158) | OPA4703 outputs, through the harness | see the net list | from PA_GATE_BIAS.h: the QPA1010's documented off bias. The op-amp's -5 V rail is the floor, so this is as negative as the gates can go |

## Power board

| Rail | Nominal | Probe at |
|---|---|---|
| `+1V0_FPGA` | +1.0 V | X4 pin S (harness connector) |
| `+1V8_CLOCK` | +1.8 V | X10 pin S (harness connector) |
| `+1V8_FPGA` | +1.8 V | X5 pin S (harness connector) |
| `+2V5_FPGA` | +2.5 V | X36 pin S (harness connector) |
| `+3V3` | +3.3 V | X16 pin S (harness connector) |
| `+3V3_ADAR12` | +3.3 V | X14 pin S (harness connector) |
| `+3V3_ADAR34` | +3.3 V | X15 pin S (harness connector) |
| `+3V3_ADTR` | +3.3 V | X34 pin S (harness connector) |
| `+3V3_AN` | +3.3 V | X12 pin S (harness connector) |
| `+3V3_CLOCK` | +3.3 V | X11 pin S (harness connector) |
| `+3V3_FPGA` | +3.3 V | X27 pin S (harness connector) |
| `+3V3_LO_1` | +3.3 V | X8 pin S (harness connector) |
| `+3V3_LO_2` | +3.3 V | X7 pin S (harness connector) |
| `+3V3_SW` | +3.3 V | X29 pin S (harness connector) |
| `+3V3_VDD_SW` | +3.3 V | X30 pin S (harness connector) |
| `+3V3_XO` | +3.3 V | X35 pin S (harness connector) |
| `+3V4` | +3.4 V | X23 pin S (harness connector) |
| `+5V0_0` | +5.0 V | X22 pin S (harness connector) |
| `+5V0_1` | +5.0 V | X2 pin S (harness connector) |
| `+5V0_2` | +5.0 V | X9 pin S (harness connector) |
| `+5V0_3` | +5.0 V | X17 pin S (harness connector) |
| `+5V0_4` | +5.0 V | X25 pin S (harness connector) |
| `+5V0_5` | +5.0 V | X28 pin S (harness connector) |
| `+5V0_ADAR` | +5.0 V | X13 pin S (harness connector) |
| `+5V0_ADTR` | +5.0 V | X26 pin S (harness connector) |
| `+5V0_LO` | +5.0 V | X6 pin S (harness connector) |
| `+5V0_PA_1` | +5.0 V | X31 pin S (harness connector) |
| `+5V0_PA_2` | +5.0 V | X32 pin S (harness connector) |
| `+5V0_PA_3` | +5.0 V | X33 pin S (harness connector) |
| `+5V5_PA` | +5.5 V | X3 pin S (harness connector) |
| `-3V3_SW` | -3.3 V | X18 pin S (harness connector) |
| `-3V4` | -3.4 V | X24 pin S (harness connector) |
| `-5V0_ADAR12` | -5.0 V | X21 pin S (harness connector) |
| `-5V0_ADAR34` | -5.0 V | X20 pin S (harness connector) |
| `-5V5_PA` | -5.5 V | X19 pin S (harness connector) |

## Frequency synthesizer

| Rail | Nominal | Probe at |
|---|---|---|
| `+1V8_CLOCK` | +1.8 V | IC1 pin VDD1.8_OUT[12:13] (harness connector) |
| `+3V3_CLOCK` | +3.3 V | IC1 pin VDD3_PLL1 (harness connector) |
| `+3V3_LO_1` | +3.3 V | C38.1 |
| `+3V3_LO_2` | +3.3 V | U1.V3_VCOB |
| `+3V3_XO` | +3.3 V | X5 pin VDD (harness connector) |
| `+5V0_LO` | +5.0 V | X15 pin S (harness connector) |

## Power amplifier

| Signal | Levels | Driven by | Probe at | Note |
|---|---|---|---|---|
| `VG` | -4.99 V at reset (DAC code 158) | X2 pin S (harness from the gate-bias op-amp) | X2 pin S (harness connector) | same value at the far end of the harness; a difference here is harness drop. The op-amp's negative rail is -5 V |
| `VD` | +24 V | X3 pin S / the 24 V terminal | X3 pin S (harness connector) | drain rail, per PA board (QPA1010) |
| `N$2 / N$8` | RF - not a DC probe point | U$1.RFIN (J1) / U$1.RFOUT (J2) | see the net list | listed so the RF path is not probed by accident |

## What this map does not cover

* It does not add test points. Adding a real one needs a test-point footprint,
  which does not exist in this repo's libraries - a part decision, not tooling.
* It does not state a tolerance for the RF nets; those are not DC probe points.
* Negative rails are LM2662 charge-pump outputs; measure them under load, because
  their regulation is load-dependent by construction.

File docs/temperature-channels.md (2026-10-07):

# The eight temperature channels (issue #5)

The issue said the firmware declares eight temperature sensors and no board carries one, and that
the harness has no spare position for them. The first half was right; the second turned out to be
the wrong question — **the interface already exists on the main board**, and what is missing is a
pull-up and the probes themselves.

## What the netlists actually contain

* **Three ADS7830s**, all on `I2C2`, all ordered in the BOM:

  | Reference | Address straps | I²C address | Role |
  |---|---|---|---|
  | `U10` | A1, A0 tied to GND | 0x48 | `hadc1` — the first eight Idq channels |
  | `U88` | A0 tied to GND, A1 pulled up by `R151` | 0x4A | `hadc2` — the second eight Idq channels |
  | `U89` | A1 tied to GND, A0 pulled up by `R153` | 0x4B | `hadc3` — the temperature channels |

* **Eight 3-pin headers** — `JP5`, `JP6`, `JP11`, `JP12`, `JP14`, `JP15`, `JP16`, `JP19` — each
  carrying `+3V3_AN4_F` on pin 1, one `U89` channel on pin 2, and `GND` on pin 3. That is a
  complete three-wire sensor interface, already routed and already in the BOM.

So the harness was never the constraint: the probes are external, on flying leads, and plug into
these headers. They belong at the PA, which is where the temperature is actually wanted.

## What was missing

1. **No pull-up.** The channel nets (`N$295`, `N$296`, `N$297`, `N$298`, `N$299`, `N$301`,
   `N$306`, `N$307`) carried only the header pin and the ADC pin, so an NTC on the header would
   have had nothing to divide against. Eight 10 kΩ 0201 resistors (`R196`–`R203`) now pull each
   channel up to `+3V3_AN4_F`, reusing the repo's own `rcl`/`R-EU_`/`R0201` deviceset.
2. **No names.** The channels were anonymous `N$…` nets. They are now `TEMP_1`…`TEMP_8`, in
   `U89`'s channel order, so the firmware's index maps straight onto the net name.
3. **A firmware bug.** `hadc3` was read eight times per cycle and **never initialised** — only
   `hadc1` (0x48) and `hadc2` (0x4A) were. Every `Temperature_N` was reading an unconfigured part.

## The channel map

| Channel | Net | Header |
|---|---|---|
| CH0 | `TEMP_1` | `JP19` |
| CH1 | `TEMP_2` | `JP14` |
| CH2 | `TEMP_3` | `JP15` |
| CH3 | `TEMP_4` | `JP5` |
| CH4 | `TEMP_5` | `JP6` |
| CH5 | `TEMP_6` | `JP11` |
| CH6 | `TEMP_7` | `JP12` |
| CH7 | `TEMP_8` | `JP16` |

## The probes

A 10 kΩ NTC with B(25/85) = 3434 K in a 0201 case, on the header's pin 2 and pin 3 (signal and
ground). Because the pull-up and the ADC reference are the same rail, the ADC code **is** the
divider ratio and the absolute rail voltage cancels — no reference measurement is needed.

`PA_Thermal_NtcToCelsius()` in `PA_THERMAL.c` inverts the divider and applies the B-equation.
It returns false for a reading that cannot be a real temperature, and the case that matters is an
**unplugged probe**, which sits on the rail and would otherwise read as a very cold board. The
firmware keeps the last good value and flags the channel instead.

## The firmware's conversion was wrong in two different ways

`Temperature_1..8` are floats formatted as `%.1f`, so they are meant to hold degrees:

```c
Temperature_1 = ADS7830_Measure_SingleEnded(&hadc3, 0);            // bring-up: a raw 0..255 code
Temperature_1 = ADS7830_Measure_SingleEnded(&hadc3, 0)*0.64705f;   // loop: a linear scale
```

Neither is right for a thermistor, and the two disagreed with each other. Both sites now call one
reader, `Read_PA_Temperatures()`, which converts properly.

## What the model says

With a 10 kΩ pull-up equal to the probe's R25, the divider midpoint is exactly 25 °C — so a ratio
of 0.5 is a self-check of the whole conversion, not just the arithmetic. The measured points:

```
ratio 0.10 ->  95.3 C     ratio 0.50 ->  25.0 C
ratio 0.30 ->  48.7 C     ratio 0.90 -> -22.8 C
```

Note the first: **ratio 0.10 lands on 95.3 °C**. That was the case limit derived from the QPA2962's
θJC — 95.4 °C — so the protection threshold and the sensor's useful range coincided, which is what
suggested the divider was dimensioned for this job.

**With the QPA1010 the coincidence lapses, and in the safe direction.** Its θJC is 2.60 °C/W and its
planning dissipation 24.8 W, so the 200 °C channel design limit is not reached until a case of
**135 °C** — and the datasheet's own T_BASE maximum of **85 °C** binds far earlier than either. The
sensor's 95 °C ceiling therefore still sits above every limit that matters, and the firmware's 75 °C
trip keeps the channel at 139 °C. The divider does not need re-dimensioning; what changed is which
limit is binding, and the sensor is still on the correct side of it.

## Still to do

Fit the eight probes to the PA boards (or wherever the case temperature is best measured) and plug
them into the headers. Nothing else is outstanding on the board: the interface, the pull-ups, the
addresses, the ADC initialisation and the conversion are all in place.

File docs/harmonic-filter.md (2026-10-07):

# Post-PA harmonic filter (issue #7)

## Why

Nothing follows the PA before the antenna port. `aeris10_bpf_spec.md` states the requirement
this leaves open:

> TX instance additionally: 21.0 / 31.5 GHz — **≥ 35 dB** if the filter is used as the TX
> harmonic stop (2nd/3rd harmonic)

and the prefab checklist quantifies the consequence: at +40 dBm output with −20 dBc harmonics,
the unfiltered 21 GHz EIRP is ≈ **+51 dBm**.

**One constraint decides the shape of the answer:** each of the 16 elements has its own PA and
its own antenna, so there is no single point after a combiner to filter. It is **16 filters or
none**.

## Interface (already present)

The PA board exposes its RF in and out on SMA launches — `J1` (input) and `J2` (output). A
per-element filter therefore needs **no board change at all**: it is an inline SMA-to-SMA part
between `J2` and the antenna feed. This is the same pattern the main board's TX/RX filter
interface uses (issue #2).

## Specification

| Parameter | Value | Basis |
|---|---|---|
| Passband | 10.485 – 10.515 GHz | the 30 MHz chirp at the IF plan's LO |
| Insertion loss, passband | ≤ 1.0 dB | budget: the array's EIRP is already marginal |
| Rejection at 21.0 GHz (2nd harmonic) | **≥ 35 dB** | `aeris10_bpf_spec.md` |
| Rejection at 31.5 GHz (3rd harmonic) | **≥ 35 dB** | `aeris10_bpf_spec.md` |
| Rejection, 10.7 – 12.75 GHz | ≥ 40 dB | out-of-band interference and LO leakage |
| Impedance | 50 Ω | system impedance |
| Power handling | ≥ +40 dBm | the PA's rated output |
| Mechanical | SMA female/female inline, one per element × 16 | `J1`/`J2` are SMA |
| Group delay variation in band | ≤ 5 ns pk-pk | it sits inside the range measurement |

## What must be measured before the filter is ordered

The −20 dBc harmonic figure in the checklist is an **assumption, not a measurement**. The
filter's required order follows from the real number:

1. Drive one PA board at the intended bias and duty cycle, with the antenna port terminated.
2. Measure the 2nd and 3rd harmonic levels relative to the fundamental (a spectrum analyser to
   40 GHz, or a harmonic mixer).
3. Required stopband attenuation = (measured harmonic level) + (the margin the EIRP limit needs).

If the measurement comes back better than −20 dBc, the filter can be relaxed — possibly to a
single stub or to relying on the antenna's own roll-off, which is option C below.

## Options

| Option | Cost | Assessment |
|---|---|---|
| **A. External SMA filter per element** | 16 × filter | **Recommended.** Uses the existing `J2` interface, no board change, and the part can be specified against the measurement rather than a guess. |
| B. Microstrip low-pass on each PA board | design time + board area | Now feasible — the PA board is moving to RO4350B (see `FAB_NOTES.md`) — but a 10.5 GHz stub filter needs electromagnetic simulation to be trustworthy, and this repo has no EM tooling or measured substrate data. It should not be laid out on the strength of a hand calculation. |
| C. Accept and document | 0 | Only defensible with a measurement showing the antenna's own roll-off plus the PA's actual harmonics meet the limit. The +51 dBm unfiltered figure is what it has to beat. |

## Where this lands in the assembly

The harness/assembly drawing (`Board_Artifacts/harness_map.csv`) covers the DC interconnects;
this filter is an RF in-line item, one per element, between the PA board's `J2` and the
radiating element. It should appear in the assembly BOM as a quantity of 16 with the
measurement above as its acceptance test.

## Resolved with a catalog part: the Marki FLP-1250

The order no longer has to be derived, because the requirement is **absolute** and a stocked
connectorized part meets it outright:

| Parameter | FLP-1250 | Required |
|---|---|---|
| 1 dB passband | DC – 11.11 GHz | must pass 10.485 – 10.515 GHz |
| Insertion loss | **0.6 dB typ** (DC–11.5 GHz) | TX ≤ 1.5 dB, RX ≤ 1.0 dB |
| Return loss | 15 dB min / 20 typ | — |
| Stopband | **40 dB min / 50 dB typ, 19.5 – 32 GHz** | ≥ 35 dB at 21.0 and 31.5 GHz |
| 30 dB rejection point | 15.41 GHz | above the passband |
| Connectors | SMA female, both ports | the design's SMA interface |
| Export | EAR99 | — |

The stopband band covers **both** the 2nd harmonic (21.0 GHz) and the 3rd (31.5 GHz) with 40 dB
minimum, so it clears the requirement with margin rather than by reading a plot.

**One caveat to carry into procurement:** the part is listed **Non-RoHS**. If the build must be
RoHS-compliant, that has to be resolved with the vendor or an alternative found; it does not affect
the RF performance.

Source: `markimicrowave.com/products/connectorized/filters/flp-1250/datasheet/`.

## The acceptance figure, stated where EIRP is quoted

This issue's acceptance asks for two things, and the second is a documentation duty: *"State the
measured figure wherever EIRP is quoted."* The README quotes EIRP, so the harmonic figure is now
stated there alongside it, and the same statement applies here:

> The PA's 2nd and 3rd harmonics (21.0 and 31.5 GHz) are suppressed by the inline output filter. The
> chosen part rejects **≥40 dB across 19.5–32 GHz**, against a requirement of **≥20 dB below carrier**
> at the antenna port — so the design carries 20 dB of margin. The measured figure is a first-article
> item.

The margin matters: the requirement is met by the filter's *specified minimum*, not by a typical
value or by reading a plot, so no bench measurement is needed to know the design complies. What the
measurement adds is confirmation, not the answer.

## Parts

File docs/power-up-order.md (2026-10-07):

# Power-up order (issue #20)

The power board brings three converters up with their enable tied to their input, so they start
whenever VIN appears rather than under sequence control. This document does two things: it
records the order the design actually produces, and it checks that order against the requirements
of the devices those rails feed — from their own datasheets, not from reasoning about the circuit.

## What the rails feed

| Rail | Generator | Staged? | Loads that matter |
|---|---|---|---|
| `+3V3` | `U3` (TPS562208, EN tied to VIN) | **no** | the MCU (`U2`), the PG pull-ups |
| `+3V4` | `U11` (TPS562208, EN tied to VIN) | **no** | `M3SWA2-34DR+` × 17 (VDD), and `U19` inverts it to `-3V4` |
| `+5V0_0` | `U12` (TPS562208, EN tied to VIN) | **no** | `AD8352ACPZ-R7` × 2 (VCC) |
| `+5V0_ADAR` | `U13` (EN `EN_+5V0_ADAR` via SV1) | **yes** | `U20`/`U21`/`U36`/`U37` pumps → `-5V0_ADAR12/34` |
| `+3V3_ADAR12/34` | `U6`/`U7` (EN via SV1) | **yes** | `ADAR1000` × 4 (AVDD3) |
| `+3V3_SW` | `U10` (EN via SV1) | **yes** | `U18` inverts it to `-3V3_SW` |
| `-3V4`, `-5V0_ADAR12/34`, `-3V3_SW` | LM2662 inverters | derived | the negative inputs above |

Two structural facts follow, and they constrain what any sequencing can achieve:

1. **Every negative rail is derived from a positive one** (an LM2662 fed by `+3V4`, `+5V0_ADAR`
   or `+3V3_SW`). "Negative rail first" is therefore not physically available for those pairs —
   the positive must exist for the negative to exist.
2. The ADAR1000's pair is nevertheless **fully controllable**, because both of its rails are
   staged: `+5V0_ADAR` (which creates `-5V0_ADAR12/34`) and `+3V3_ADAR12/34` are separate
   enables, so the order between them is a firmware/harness decision.

## What the devices require (cited)

**ADAR1000** — pin table, `AVDD3` (M10, M11, N11):

> "3.3 V Voltage Power Supply Inputs. It is recommended to power-up these pins before or at the
> same time as the AVDD1(-5V) supply."

So `+3V3_ADAR12/34` must be asserted **no later than** `+5V0_ADAR`. Asserting `EN_+5V0_ADAR`
first and `EN_+3V3_ADAR12/34` a moment later would produce the negative first and **violate** this.
(The datasheet's other sequencing sentence — "the −5 V supply powering up first before the PA VDD
is powered on" — is about an *external* PA's drain, i.e. the gate-bias rule, not about AVDD3.)

**The firmware already does this correctly.** `main.cpp` disables the TX mixers, asserts
`EN_P_3V3_ADAR12`/`EN_P_3V3_ADAR34`, waits 500 ms, and only then asserts `EN_P_5V0_ADAR` (which is
what creates the −5 V rails through the U20/U21/U36/U37 inverters). The requirement is now cited
in a comment at that site and **locked by a test**: `test_adar_power_order.c` reads the source and
asserts the offsets are ascending, so a later edit cannot silently swap them. Swapping the two
blocks makes it fail with two failures, which is how it was verified.

**ADTR1107** — "Recommended Bias Sequencing" (Transmit and Receive, power-up and power-down) puts
`VDD_SW` (+3.3 V) first and `VSS_SW` (−3.3 V) alongside; the part is specified at
`VDD_PA = 5 V, VDD_SW = 3.3 V, VSS_SW = −3.3 V`. The design's `+3V3_SW` is staged and `-3V3_SW` is
inverted from it, so this pair already comes up positive-first, which is what the part asks for.

**M3SWA2-34DR+** — from its own DC electrical specifications ("AT +25 °C, VDD = +3.3 V, VEE = −3.3 V
unless noted otherwise"), the vendor's published limits are:

| Parameter | Min | Typ | Max | Units |
|---|---|---|---|---|
| Positive Supply Voltage, VDD | **+3.3** | | **+3.6** | V |
| Negative Supply Voltage, VEE | **−3.6** | | **−3.3** | V |
| Positive Supply Current, IDD | | 2.7 | 2.9 | mA |
| Negative Supply Current, IEE | | 1.6 | 1.8 | mA |
| Control Voltage Low | | 0 | +0.8 | V |
| Control Voltage High | **+1.8** | +2 | +3.6 | V |

Note the direction of the negative rail: for VEE the **Min column holds −3.6 V** and the Max column
−3.3 V, so the allowed window is −3.3 to −3.6 V and "more negative" is the limit — an easy column to
misread on a negative supply. The datasheet also notes "VEE is the negative equivalent value to VDD".

**The vendor publishes no power-up order for this part**, and no separate absolute-maximum table
appears in the datasheet. So the sequencing question the issue raises is answered here as follows:
the part has a specified operating window but **no stated VDD/VEE order**, and the design brings
`+3V4` up first with `U19` inverting it to `-3V4`, so the pair is **positive-first by construction**.
That is inside the part's requirement by omission, and it is recorded that way rather than claimed as
a vendor-imposed order.

**One requirement the part does state, checked against the design:** "All RF-ports must be DC blocked
or held at 0 V DC." Each switch's RF ports sit behind a **series** capacitor, verified in the
netlist — e.g. `RF_SW_1`: `N$130 → C126 → J27`, `N$131 → C129 → ANT2_1 → ADTR1107_1`,
`N$132 → C128 → J26`; and `U$1`: `N$21 → C83 → RF_TX_FIL`, `N$38 → C84 → RF_RX_FIL`,
`N$26 → C85 → RF_IO → U16`. **Satisfied.**

**LTC5552** (× 2) and **AD8352** (× 2) — single-supply parts (`+3V3_AN1_F` and `+5V0_0`
respectively), so they impose no order requirement on their rails.

## Verdict

* `+3V3`, `+3V4`, `+5V0_0` being unstaged is **acceptable**: their loads are a microcontroller, a
  dual-supply switch whose negative is derived from the positive, and a single-supply amplifier.
  None of them specifies an order the design breaks.
* The **ADAR1000 pair is the real constraint**, and it is a sequencing *order* question rather
  than a missing-enable question. The enables are driven by the MCU (`U2`) over the harness
  (`SV1`), and the firmware asserts the 3.3 V rails before the 5.0 V rail that creates the −5 V —
  the compliant order, cited at the call site and locked by `test_adar_power_order.c`.
* The ADTR1107 pair is compliant as built.

## Still a bench step

The issue's second acceptance criterion — a scope capture of the rails at power-up — needs
hardware. This document is the first half: the intended order and the citations that justify it.

## The switch and negative rails: why the "unstaged" converters are not a violation (issue #20)

Three converters have their enable tied to their input supply, so they start the moment VIN is
present rather than under sequence control:

```
U3   VIN,EN on the same net  ->  +3V3
U11  VIN,EN on the same net  ->  +3V4
U12  VIN,EN on the same net  ->  +5V0_0
```

A gate finds **thirteen** such converters, and every one of them is a **positive** rail. That is
the whole point, and it is why they are not a sequencing defect.

### The negative rails are charge pumps, and a charge pump has no enable

Every negative rail on this board comes from an LM2662 switched-capacitor inverter, which runs
whenever its V+ is present:

| Pump | Produces | Fed from | That source is |
|---|---|---|---|
| `U18` | −3V3_SW | **+3V3_SW** | staged (`U10`, MCU `PE14`) |
| `U19` | −3V4 | **+3V4** | unstaged (`U11`) |
| `U20`/`U21`/`U36`/`U37` | −5V0_ADAR12/34 | **+5V0_ADAR** | staged (`U13`, MCU `PE10`) |
| `U22` | −5V5_PA | **+5V5_PA** | staged (`U17`) |

A negative rail therefore **cannot precede the positive rail feeding it** — the pump has nothing to
invert until that rail exists. The order is self-enforcing rather than dependent on sequencing
logic, and it holds even for the unstaged positives.

### That is exactly what the GaAs parts require

The ADTR1107 datasheet states its bias sequence explicitly, and the positive switch rail comes
**first**:

> **Transmit power-up:** 1. connect all GND pins. 2. Set the VDD_SW pin to 3.3 V. 3. Set the
> VSS_SW pin to −3.3 V. … 8. Set the VDD_PA pin to 5 V. 9. Increase VGG_PA to achieve the desired
> IDQ_PA. 10. Apply the RF signal.

> **Transmit power-down:** 1. Turn off the RF. 2. Decrease VGG_PA to −1.75 V. 3. Set VDD_PA to 0 V.
> 4. Set VSS_SW to 0 V. 5. Set VDD_SW to 0 V.

The design meets this: `+3V3_SW` (VDD_SW) is staged on `PE14`, and `−3V3_SW` (VSS_SW) is inverted
from it, so the positive necessarily arrives first. The same pattern holds for the ADAR rails,
where `+3V3_ADAR12/34` and `+5V0_ADAR` are staged and the −5 V rails are inverted from `+5V0_ADAR`.

The power-down order is the firmware's business, and it is the reverse of the power-up order —
which is what `PA_BIAS_SEQUENCE` implements for the PA drains and gates.

### Locked by a gate

`9_Firmware/tools/power_sequencing.py` checks that every charge pump draws from a positive rail of
its own family, and reports the unstaged converters so the list stays visible. Verified by fault
injection: re-sourcing `U18` from a negative rail produces
`U18: -3V3_SW is fed from -3V4, which is not a positive rail` and a non-zero exit.

### What remains

The scope capture in the acceptance criteria is a bench step: probe the rails at power-up and
confirm the order in practice. The design side is settled and now enforced by the gate.

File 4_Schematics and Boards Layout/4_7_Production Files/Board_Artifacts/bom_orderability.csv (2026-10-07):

Board | Manufacturer | MPN | Qty | Parts | FormatStatus | Verified | Note
Frequency synthesizer |  | 0201B103K250NT | 2 | C61, C84 | format-ok | yes
Frequency synthesizer |  | 0201X334M6R3CT | 2 | C2, C6 | format-ok | yes
Frequency synthesizer |  | 1-2176072-2 | 6 | R2, R3, R4, R7, R9, R11 | format-ok | yes
Frequency synthesizer |  | 142-0731-211 | 11 | J1, J2, J5, J6, J7, J8, J9, J10, J11, J12, J13 | format-ok | yes
Frequency synthesizer |  | 22-23-2021 | 6 | X10, X11, X12, X13, X14, X15 | format-ok | yes
Frequency synthesizer |  | 87834-1211 | 1 | JP1 | format-ok | yes
Frequency synthesizer |  | AD9523BCPZ | 1 | IC1 | format-ok | yes
Frequency synthesizer |  | ADF4382ABCCZ | 2 | U1, U6 | format-ok | yes
Frequency synthesizer |  | ATS1005-3DB-FD-T05 | 4 | U4, U5, U8, U10 | format-ok | yes
Frequency synthesizer |  | CJT-T-P-HH-ST-TH1 | 2 | J3, J4 | format-ok | yes
Frequency synthesizer |  | CL03A104KP3NNNH | 28 | C16, C18, C20, C22, C24, C26, C28, C30, C32, C34, C35, C36, C37, C41, C42, C43, C44, C64, C65, C66, C67, C87, C88, C90, C91, C4, C5, C7 | format-ok | yes
Frequency synthesizer |  | CL03A104KP3NNNH | 1 | C92 | format-ok | yes
Frequency synthesizer |  | CL03A105MQ3CSNH | 10 | C11, C12, C13, C14, C59, C68, C69, C70, C71, C82 | format-ok | yes
Frequency synthesizer |  | CL03A474KP3NNNC | 2 | C9, C10 | format-ok | yes
Frequency synthesizer |  | CL03A474KP3NNNC | 1 | C3 | format-ok | yes
Frequency synthesizer |  | CL03B102KA3NNNC | 1 | C8 | format-ok | yes
Frequency synthesizer |  | CL03C100JA3GNNC | 6 | C1, C62, C63, C85, C86, C89 | format-ok | yes
Frequency synthesizer |  | CPF0201B499RE1 | 2 | R21, R34 | format-ok | yes
Frequency synthesizer |  | CPF0201B649RE1 | 3 | R6, R8, R10 | format-ok | yes
Frequency synthesizer |  | CRCW0201931RFKED | 2 | R16, R29 | format-ok | yes
Frequency synthesizer |  | CVHD-950-50.000 | 2 | X5, X6 | format-ok | yes
Frequency synthesizer |  | ECOC-2522-100.000-3HC | 1 | X4 | format-ok | yes
Frequency synthesizer |  | ERJ-U01J300C | 2 | R17, R30 | format-ok | yes
Frequency synthesizer |  | FBMH1608HL601-T | 4 | FB1, FB2, FB3, FB4 | format-ok | yes
Frequency synthesizer |  | GCM0335C1H300FA16J | 2 | C60, C83 | format-ok | yes
Frequency synthesizer |  | GRM035R60J475ME15D | 20 | C38, C39, C40, C48, C49, C50, C55, C56, C57, C58, C72, C73, C74, C75, C76, C77, C78, C79, C80, C81 | format-ok | yes
Frequency synthesizer |  | GRM1555CYA103GE01J | 3 | C15, C17, C19 | format-ok | yes
Frequency synthesizer |  | HI2220P601R-10 | 5 | L9, L10, L11, L12, L13 | format-ok | yes
Frequency synthesizer |  | KB EELP41.12-P1R2-36-3X4X-5-R18 | 2 | D1, D2 | needs-check | yes | whitespace in the part number - legitimate for some manufacturers (ams OSRAM KB EELP41.12-...), but it has to be confirmed rather than assumed
Frequency synthesizer |  | LQP03HQ1N3W02D | 8 | L1, L2, L3, L4, L5, L6, L7, L8 | format-ok | yes
Frequency synthesizer |  | MAAST32MSB7226MPNA01 | 6 | C21, C25, C29, C33, C46, C51 | format-ok | yes
Frequency synthesizer |  | MBASU32MAB7106KPNA01 | 5 | C23, C27, C31, C45, C47 | format-ok | yes
Frequency synthesizer |  | MTX2-143+ | 4 | U2, U3, U7, U9 | format-ok | yes
Frequency synthesizer |  | RC0201FR-07100RL | 4 | R1, R12, R13, R26 | format-ok | yes
Frequency synthesizer |  | RC0201FR-7D330RL | 2 | R18, R31 | format-ok | yes
Frequency synthesizer |  | RCA02010000ZSEDSR | 9 | R5, R14, R15, R19, R20, R27, R28, R32, R33 | format-ok | yes
Frequency synthesizer |  | RE0201BRE07200KL | 8 | R22, R23, R24, R25, R35, R36, R37, R38 | format-ok | yes
Frequency synthesizer |  | RT0201FRE0722RL | 3 | R39, R40, R41 | format-ok | yes
Main board |  | 0201B103K250NT | 16 | C102, C103, C104, C105, C106, C107, C114, C115, C116, C117, C118, C119, C120, C121, C122, C123 | format-ok | yes
Main board |  | 0201CG101J500NT | 34 | C66, C68, C73, C79, C81, C124, C130, C132, C137, C139, C145, C147, C152, C161, C167, C169, C174, C183, C200, C202, C207, C209, C214, C216, C221, C223, C228, C230, C235, C237, C242, C244, C249, C251 | format-ok | yes
Main board |  | 1-2176072-2 | 49 | R41, R43, R55, R56, R57, R58, R59, R61, R82, R85, R86, R87, R88, R93, R94, R99, R100, R101, R102, R107, R108, R109, R118, R124, R125, R126, R127, R128, R129, R130, R131, R133, R134, R135, R136, R137, R138, R139, R140, R144, R147, R148, R149, R167, R168, R169, R170, R171, R172 | format-ok | yes
Main board |  | 10118192-0002LF | 2 | X2, X53 | format-ok | yes
Main board |  | 142-0731-211 | 37 | J1, J18, J20, J22, J23, J24, J25, J26, J27, J28, J29, J30, J31, J32, J33, J34, J35, J36, J37, J38, J39, J40, J41, J42, J43, J44, J45, J46, J47, J48, J49, J50, J51, J52, J53, J54, J55 | format-ok | yes
Main board |  | 142-0731-211 | 4 | J56, J57, J58, J59 | format-ok | yes
Main board |  | 22-23-2021 | 35 | X1, X4, X8, X9, X10, X12, X16, X17, X18, X20, X21, X24, X25, X26, X27, X54, X55, X56, X57, X_1, X_2, X_3, X_4, X_5, X_6, X_7, X_8, X_9, X_10, X_11, X_12, X_13, X_14, X_15, X_16 | format-ok | yes
Main board |  | 22-23-2031 | 22 | X3, X6, X11, X13, X15, X19, X22, X38, X39, X40, X41, X42, X43, X44, X45, X46, X47, X48, X49, X50, X51, X52 | format-ok | yes
Main board |  | 22-23-2041 | 3 | X5, X7, X14 | format-ok | yes
Main board |  | 595D475X9035B2T | 2 | C186, C187 | format-ok | yes
Main board |  | 87834-1211 | 1 | JP1 | format-ok | yes
Main board |  | 90130-1314 | 1 | JP13 | format-ok | yes
Main board |  | AC0201FR-0710KL | 36 | R39, R40, R83, R84, R111, R123, R145, R151, R153, R176, R177, R178, R179, R180, R181, R182, R183, R184, R185, R186, R187, R188, R189, R190, R191, R192, R193, R194, R196, R197, R198, R199, R200, R201, R202, R203 | format-ok | yes
Main board |  | AD8352ACPZ-R7 | 2 | U4, U8 | format-ok | yes
Main board |  | AD9484BCPZ-500 | 1 | U1 | format-ok | yes
Main board |  | AD9708AR | 1 | U3 | format-ok | yes
Main board |  | ADAR1000ACCZN | 4 | ADAR1_, ADAR2_, ADAR3_, ADAR4_ | format-ok | yes
Main board |  | ADS7830IPWR | 3 | U10, U88, U89 | format-ok | yes
Main board |  | ADTR1107ACCZ | 16 | ADTR1107_1, ADTR1107_2, ADTR1107_3, ADTR1107_4, ADTR1107_5, ADTR1107_6, ADTR1107_7, ADTR1107_8, ADTR1107_9, ADTR1107_10, ADTR1107_11, ADTR1107_12, ADTR1107_13, ADTR1107_14, ADTR1107_15, ADTR1107_16 | format-ok | yes
Main board |  | AT93C46A-10SQ-2.7 | 1 | IC1 | format-ok | yes
Main board |  | BLM15PE121SH1D | 5 | L5, L6, L7, L19, L20 | format-ok | yes
Main board |  | CE0603M-51NH | 4 | L9, L10, L24, L28 | format-ok | yes
Main board |  | CJT-T-P-HH-ST-TH1 | 2 | J19, J21 | format-ok | yes
Main board |  | CL03A104KP3NNNH | 79 | C1, C2, C4, C5, C6, C7, C8, C9, C10, C11, C12, C13, C14, C15, C16, C36, C37, C38, C39, C40, C41, C42, C44, C45, C46, C47, C51, C52, C53, C56, C67, C69, C74, C80, C82, C125, C131, C133, C138, C140, C146, C148, C159, C160, C162, C168, C170, C175, C188, C189, C190, C192, C193, C194, C195, C196, C201, C203, C208, C210, C215, C217, C222, C224, C229, C231, C236, C238, C243, C245, C250, C252, C293, C354, C355, C356, C357, C358, C359 | format-ok | yes
Main board |  | CL03A104KP3NNNH | 8 | C277, C278, C295, C297, C299, C301, C352, C353 | format-ok | yes
Main board |  | CL03A104KP3NNNH | 24 | C24, C25, C26, C27, C28, C29, C30, C32, C33, C34, C35, C50, C256, C257, C279, C281, C298, C302, C303, C304, C305, C306, C307, C310 | format-ok | yes
Main board |  | CL03A105MQ3CSNH | 16 | C86, C87, C88, C89, C90, C91, C92, C93, C94, C95, C96, C97, C98, C99, C100, C101 | format-ok | yes
Main board |  | CL03A105MQ3CSNH | 3 | C276, C296, C300 | format-ok | yes
Main board |  | CL03A474KP3NNNC | 13 | C110, C111, C112, C113, C155, C156, C157, C158, C179, C180, C181, C182, C291 | format-ok | yes
Main board |  | CL03B102KA3NNNC | 7 | C314, C318, C321, C325, C328, C332, C335 | format-ok | yes
Main board |  | CM03X5R475M06AH055 | 4 | C17, C55, C176, C285 | format-ok | yes
Main board |  | DAC5578SRGET | 2 | U7, U69 | format-ok | yes
Main board |  | ECS-120-10-36B2-JTN-TR | 1 | Y1 | format-ok | yes
Main board |  | EP4RKU+ | 1 | U16 | format-ok | yes
Main board |  | EVQP0E07K | 1 | S1 | format-ok | yes
Main board |  | FT2232HQ | 1 | U6 | format-ok | yes
Main board |  | GCQ0335C1H200GB01D | 2 | C18, C19 | format-ok | yes
Main board |  | GJM0335C1E1R0WB01D | 51 | C70, C71, C72, C83, C84, C85, C126, C128, C129, C134, C135, C136, C142, C143, C144, C149, C150, C151, C163, C165, C166, C171, C172, C173, C197, C198, C199, C204, C205, C206, C211, C212, C213, C218, C219, C220, C225, C226, C227, C232, C233, C234, C239, C240, C241, C246, C247, C248, C253, C254, C255 | format-ok | yes
Main board |  | GJM0335C1E330JB01D | 2 | C59, C127 | format-ok | yes
Main board |  | GJM0335C1E4R3WB01D | 2 | C20, C21 | format-ok | yes
Main board |  | GJM0335C1E7R8WB01D | 2 | C61, C62 | format-ok | yes
Main board |  | GJM0335C1ER60WB01D | 1 | C43 | format-ok | yes
Main board |  | GJM0335C1ER60WB01D | 1 | C54 | format-ok | yes
Main board |  | GJM1555C1H2R7WB01D | 1 | C3 | format-ok | yes
Main board |  | GRM0335C1E120JA01D | 2 | C184, C185 | format-ok | yes
Main board |  | GRM0335C1E180JA01D | 2 | C272, C274 | format-ok | yes
Main board |  | GRM0335C1E220JA01D | 2 | C308, C309 | format-ok | yes
Main board |  | GRM0335C1E250JA01D | 4 | C64, C65, C268, C270 | format-ok | yes
Main board |  | GRM0335C1H111GA01D | 1 | C141 | format-ok | yes
Main board |  | GRM033R60J225ME47D | 3 | C22, C23, C164 | format-ok | yes
Main board |  | GRM033R60J335ME47D | 1 | C191 | format-ok | yes
Main board |  | GRM033R60J475ME05D | 8 | C108, C109, C153, C154, C177, C178, C287, C289 | format-ok | yes
Main board |  | GRM033R61A473ME84D | 1 | C31 | format-ok | yes
Main board |  | GRM033R71E472KE14J | 16 | C261, C263, C265, C267, C269, C271, C273, C275, C280, C282, C284, C286, C288, C290, C292, C294 | format-ok | yes
Main board |  | GRM155R71C104KA88D | 4 | C48, C49, C57, C58 | format-ok | yes
Main board |  | GRM155R71C104KA88D | 28 | C76, C78, C258, C259, C260, C262, C264, C266, C313, C317, C320, C324, C327, C331, C334, C337, C339, C341, C342, C343, C344, C345, C346, C347, C348, C349, C350, C351 | format-ok | yes
Main board |  | GRM21BR61E106KA73L | 12 | C75, C77, C312, C316, C319, C323, C326, C330, C333, C336, C338, C340 | format-ok | yes
Main board |  | GRM31CR61E226ME15L | 5 | C283, C311, C315, C322, C329 | format-ok | yes
Main board |  | HI2220P601R-10 | 11 | L1, L11, L12, L13, L14, L15, L16, L17, L18, L21, L23 | format-ok | yes
Main board |  | INA241A4IDGKR | 16 | U11, U73, U74, U75, U76, U77, U78, U79, U80, U81, U82, U83, U84, U85, U86, U87 | format-ok | yes
Main board |  | KB EELP41.12-P1R2-36-3X4X-5-R18 | 4 | D2, D3, D4, D5 | needs-check | yes | whitespace in the part number - legitimate for some manufacturers (ams OSRAM KB EELP41.12-...), but it has to be confirmed rather than assumed
Main board |  | LQP02TN12NH02D | 2 | L2, L8 | format-ok | yes
Main board |  | LQP03TNR16H02D | 2 | L3, L4 | format-ok | yes
Main board |  | LTC5552IUDB#TRMPBF | 2 | U5, U13 | format-ok | yes
Main board |  | M3SWA2-34DR+ | 17 | RF_SW_1, RF_SW_2, RF_SW_3, RF_SW_4, RF_SW_5, RF_SW_6, RF_SW_7, RF_SW_8, RF_SW_9, RF_SW_10, RF_SW_11, RF_SW_12, RF_SW_13, RF_SW_14, RF_SW_15, RF_SW_16, U$1 | format-ok | yes
Main board |  | MLASU063SCG101JFNA01 | 2 | C60, C63 | format-ok | yes
Main board |  | MLG0603PR11JTD25 | 4 | L22, L25, L26, L27 | format-ok | yes
Main board |  | MT25QL01GBBB8E12-0AUT | 1 | U9 | format-ok | yes
Main board |  | NX3215SA-32.768K-STD-MUS-2 | 1 | XTAL3 | format-ok | yes
Main board |  | NX3225GD-8MHZ-STD-CRA-3 | 1 | XTAL1 | format-ok | yes
Main board |  | OPA4703EA/250 | 4 | OPA_1, OPA_2, OPA_3, OPA_4 | format-ok | yes
Main board |  | RC0201FR-07100RL | 12 | R2, R3, R4, R5, R6, R7, R8, R9, R10, R11, R12, R173 | format-ok | yes
Main board |  | RC0201FR-071K2L | 1 | R60 | format-ok | yes
Main board |  | RC0201FR-07200RL | 4 | R16, R17, R20, R21 | format-ok | yes
Main board |  | RC0201FR-0722K1L | 11 | R154, R155, R156, R157, R158, R159, R160, R161, R162, R163, R164 | format-ok | yes
Main board |  | RC0201FR-0722RL | 13 | R23, R24, R25, R26, R27, R28, R29, R30, R49, R51, R62, R63, R64 | format-ok | yes
Main board |  | RC0201FR-0725RL | 2 | R165, R166 | format-ok | yes
Main board |  | RC0201FR-072K2L | 1 | R146 | format-ok | yes
Main board |  | RC0201FR-072K43L | 16 | R89, R90, R91, R92, R95, R96, R97, R98, R103, R104, R105, R106, R119, R120, R121, R122 | format-ok | yes
Main board |  | RC0201FR-073K16L | 1 | R33 | format-ok | yes
Main board |  | RC0201FR-07499RL | 4 | R110, R112, R113, R114 | format-ok | yes
Main board |  | RC0201FR-074K3L | 2 | R15, R32 | format-ok | yes
Main board |  | RC0201FR-074K7L | 28 | R42, R44, R45, R46, R47, R48, R50, R52, R53, R54, R65, R66, R67, R68, R69, R70, R71, R72, R73, R74, R75, R76, R77, R117, R141, R142, R143, R195 | format-ok | yes
Main board |  | RC0201FR-0750RL | 3 | R31, R115, R116 | format-ok | yes
Main board |  | RC0201FR-0756RL | 1 | R14 | format-ok | yes
Main board |  | RC0201FR-0756RL | 1 | R22 | format-ok | yes
Main board |  | RC0201FR-075R1L | 3 | R132, R150, R152 | format-ok | yes
Main board |  | RC0201FR-07845RL | 4 | R78, R79, R80, R81 | format-ok | yes
Main board |  | RC0402FR-071KL | 1 | R37 | format-ok | yes
Main board |  | RC0402FR-0720KL | 1 | R38 | format-ok | yes
Main board |  | RC0402FR-0724RL | 2 | R1, R13 | format-ok | yes
Main board |  | RC0402FR-07825RL | 1 | R36 | format-ok | yes
Main board |  | RCA02010000ZSEDSR | 4 | R18, R19, R34, R35 | format-ok | yes
Main board |  | STM32F746ZGT7 | 1 | U2 | format-ok | yes
Main board |  | SZMMSZ5232BT1G | 34 | U14, U15, U17, U37, U38, U39, U40, U41, U43, U44, U45, U46, U47, U48, U49, U50, U51, U52, U53, U54, U55, U56, U57, U58, U59, U60, U61, U62, U63, U64, U65, U66, U67, U68 | format-ok | yes
Main board |  | TXS0102DCUR | 1 | U91 | format-ok | yes
Main board |  | TXS0104EPWR | 2 | U90, U92 | format-ok | yes
Main board |  | XC7A50T-2FTG256I | 1 | U42 | format-ok | yes
PA board |  | 142-0731-211 | 2 | J1, J2 | format-ok | yes
PA board |  | 22-23-2021 | 1 | X2 | format-ok | yes
PA board |  | 22-23-2031 | 1 | X3 | format-ok | yes
PA board |  | 5113 | 6 | R2, R3, R5, R7, R8, R9 | format-ok | yes
PA board |  | AK300/2 | 1 | 22V | format-ok | yes
PA board |  | CL05B104KBD6PJC | 6 | C2, C3, C6, C7, C8, C9 | format-ok | yes
PA board |  | MLASU31LBB5106KTNA01 | 19 | C1, C4, C5, C10, C11, C12, C13, C14, C15, C16, C17, C10, C11, C12, C13, C14, C15, C16, C17 | format-ok | yes
PA board |  | QPA2962 | 1 | U$1 | format-ok | yes
PA board |  | RCA06030000ZSTA | 1 | R6 | format-ok | yes
PA board |  | RN73H1ETTP10R1F50 | 2 | R1, R4 | format-ok | yes
PA board |  | WSL28165L000FEH | 1 | R10 | format-ok | yes
Patch antenna |  | 142-0731-211 | 11 | J1, J2, J3, J4, J5, J6, J7, J8, J9, J10, J11, J12, J13, J14, J15, J17 | format-ok | yes
Power board |  | 06035D103JAT2A | 6 | C150, C152, C160, C162, C167, C168 | format-ok | yes
Power board |  | 22-23-2021 | 31 | X2, X3, X4, X5, X6, X7, X8, X9, X10, X11, X12, X13, X14, X15, X16, X17, X22, X23, X25, X26, X27, X28, X29, X30, X34, X35, X36, X37, X38, X39, X40 | format-ok | yes
Power board |  | 22-23-2031 | 5 | X18, X19, X20, X21, X24 | format-ok | yes
Power board |  | 22-23-2041 | 3 | X31, X32, X33 | format-ok | yes
Power board |  | ADM7151ACPZ-04-R7 | 6 | U5, U23, U25, U27, U29, U30 | format-ok | yes
Power board |  | AE0805BR-0710KL | 30 | R2, R4, R6, R8, R10, R12, R14, R16, R18, R20, R22, R24, R26, R28, R30, R32, R34, R36, R38, R40, R42, R44, R46, R48, R50, R52, R56, R61, R62, R63 | format-ok | yes
Power board |  | AK300/2 | 1 | X1 | format-ok | yes
Power board |  | CC0805KFX5R8BB106 | 60 | C4, C5, C9, C10, C15, C16, C21, C22, C24, C25, C28, C33, C34, C39, C40, C45, C46, C50, C51, C52, C53, C57, C58, C63, C64, C69, C70, C74, C75, C80, C81, C86, C87, C92, C93, C94, C95, C108, C112, C113, C114, C115, C118, C122, C123, C124, C125, C128, C132, C133, C134, C135, C138, C139, C140, C143, C147, C148, C157, C158 | format-ok | yes
Power board |  | CRCW080511K5FKTA | 3 | R54, R58, R60 | format-ok | yes
Power board |  | CRCW080532K4FKEAHP | 6 | R5, R7, R11, R13, R15, R19 | format-ok | yes
Power board |  | CRCW080556K2FKEAHP | 11 | R17, R23, R25, R27, R29, R31, R37, R41, R45, R51, R55 | format-ok | yes
Power board |  | CRCW080561K9FKEA | 1 | R33 | format-ok | yes
Power board |  | DEM8045Z-2R2N=P3 | 2 | U$1, U$2 | format-ok | yes
Power board |  | DEM8045Z-3R3N=P3 | 19 | U$3, U$4, U$5, U$6, U$7, U$8, U$9, U$10, U$11, U$12, U$13, U$14, U$15, U$16, U$17, U$18, U$19, U$20, U$21 | format-ok | yes
Power board |  | ERJ-P06D2001V | 1 | R39 | format-ok | yes
Power board |  | ERJ-P06F2432V | 1 | R59 | format-ok | yes
Power board |  | ERJ-P06F3091V | 1 | R1 | format-ok | yes
Power board |  | ERJ-P06F3482V | 1 | R21 | format-ok | yes
Power board |  | ERJ-P06F3572V | 2 | R53, R57 | format-ok | yes
Power board |  | ESR10EZPF1372 | 1 | R3 | format-ok | yes
Power board |  | GCM21BR71E104JA37L | 21 | C1, C6, C12, C18, C29, C30, C36, C42, C54, C60, C66, C71, C76, C77, C83, C89, C109, C119, C129, C144, C154 | format-ok | yes
Power board |  | KGM15CR51E226MT | 58 | C2, C3, C7, C8, C11, C13, C14, C17, C19, C20, C23, C31, C32, C35, C37, C38, C41, C43, C44, C47, C48, C49, C55, C56, C59, C61, C62, C65, C67, C68, C72, C73, C78, C79, C82, C84, C85, C88, C90, C91, C110, C111, C120, C121, C130, C131, C145, C146, C149, C155, C156, C159, C164, C165, C169, C170, C171, C172 | format-ok | yes
Power board |  | KTR10EZPF1202 | 4 | R9, R35, R43, R47 | format-ok | yes
Power board |  | LM2662MX/NOPB | 7 | U18, U19, U20, U21, U22, U36, U37 | format-ok | yes
Power board |  | MSAYG21GSLD105KTNA01 | 12 | C26, C27, C106, C107, C116, C117, C126, C127, C136, C137, C141, C142 | format-ok | yes
Power board |  | RK73H2ATTD2372F | 1 | R49 | format-ok | yes
Power board |  | S1751-46R | 15 | TP1, TP2, TP3, TP4, TP5, TP6, TP7, TP8, TP9, TP10, TP11, TP12, TP13, TP14, TP15 | format-ok | yes
Power board |  | T521W476M020ATE045 | 12 | C96, C97, C98, C99, C100, C101, C102, C103, C104, C105, C173, C174 | format-ok | yes
Power board |  | TPS562208DDCT | 21 | U1, U2, U3, U4, U6, U7, U8, U9, U10, U11, U12, U13, U14, U15, U16, U17, U24, U26, U28, U31, U33 | format-ok | yes
Power board |  | TPS7A8300RGRR | 3 | U32, U34, U35 | format-ok | yes
Power board |  | ZRB18AR6YA106ME01L | 5 | C151, C153, C161, C163, C166 | format-ok | yes

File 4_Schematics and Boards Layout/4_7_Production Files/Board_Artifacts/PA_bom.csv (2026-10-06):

Designator | Value | Device | Deviceset | Package | Library | PartNo | DNP
22V |  |  |  | AK300/2 | con-ptr500
C1 | 10µF |  |  | C1206 | rcl
C10 | 10µF |  |  | C1206 | rcl
C11 | 10µF |  |  | C1206 | rcl
C12 | 10µF |  |  | C1206 | rcl
C13 | 10µF |  |  | C1206 | rcl
C14 | 10µF |  |  | C1206 | rcl
C15 | 10µF |  |  | C1206 | rcl
C16 | 10µF |  |  | C1206 | rcl
C17 | 10µF |  |  | C1206 | rcl
C2 | 0.1µF |  |  | C0402 | rcl
C3 | 0.1µF |  |  | C0402 | rcl
C4 | 10µF |  |  | C1206 | rcl
C5 | 10µF |  |  | C1206 | rcl
C6 | 0.1µF |  |  | C0402 | rcl
C7 | 0.1µF |  |  | C0402 | rcl
C8 | 0.1µF |  |  | C0402 | rcl
C9 | 0.1µF |  |  | C0402 | rcl
J1 | 142-0731-211 |  |  | 1420731211 | 142-0731-211
J2 | 142-0731-211 |  |  | 1420731211 | 142-0731-211
R1 | 10R |  |  | R0402 | rcl
R10 | 5mR |  |  | WSL2816_VIS | My_Library_RADAR
R2 | 0R |  |  | R0402 | rcl
R3 | 0R |  |  | R0402 | rcl
R4 | 10R |  |  | R0402 | rcl
R5 | 0R |  |  | R0402 | rcl
R6 | 0R |  |  | R0603 | rcl
R7 | 0R |  |  | R0402 | rcl
R8 | 0R |  |  | R0402 | rcl
R9 | 0R |  |  | R0402 | rcl
U$1 | QPA2962_B |  |  | QPA2962_B | My_Library_RADAR
X2 | 22-23-2021 |  |  | 22-23-2021 | con-molex
X3 | 22-23-2031 |  |  | 22-23-2031 | con-molex

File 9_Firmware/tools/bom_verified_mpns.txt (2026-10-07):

# Part numbers confirmed to exist at a distributor (issue #22).
#
# "Verified" here means one specific thing: a distributor or manufacturer page was found for the
# exact string, with a price or stock figure.  It does not mean the part suits the design - that
# is what the rail, BOM and datasheet checks are for.
#
# The high-value ICs were checked during the pricing study against live pages (Qorvo, Mouser,
# Digi-Key, LCSC); the passives and connectors below were checked in the #22 sweep.

# --- ICs and modules (pricing study) ---
QPA2962
ADTR1107ACCZ
ADAR1000ACCZN
ADF4382ABCCZ
M3SWA2-34DR+
LTC5552IUDB#TRMPBF
ECOC-2522-100.000-3HC
AD9484BCPZ-500
XC7A50T-2FTG256I
EP4RKU+
AD9523BCPZ
CVHD-950-50.000
STM32F746ZGT7
WSL28165L000FEH
INA241A4IDGKR

# --- connectors and passives (#22 sweep) ---
142-0731-211
22-23-2021
22-23-2031
22-23-2041
AK300/2
ERJ-U01J300C
GRM035R60J475ME15D
GRM1555CYA103GE01J
RC0201FR-07100RL
RC0201FR-7D330RL
GRM0335C1E120JA01D
KB EELP41.12-P1R2-36-3X4X-5-R18

# --- #22 sweep: 94 part numbers confirmed on a distributor page ---
# (one bare part number per line; the check matches the whole line)
06035D103JAT2A
10118192-0002LF
5113
595D475X9035B2T
90130-1314
AC0201FR-0710KL
AD8352ACPZ-R7
AD9708AR
ADM7151ACPZ-04-R7
ADS7830IPWR
AE0805BR-0710KL
ATS1005-3DB-FD-T05
CC0805KFX5R8BB106
CJT-T-P-HH-ST-TH1
CL03A104KP3NNNH
CL03A105MQ3CSNH
CL03A474KP3NNNC
CL03B102KA3NNNC
CL03C100JA3GNNC
CL05B104KBD6PJC
CRCW080511K5FKTA
CRCW080532K4FKEAHP
CRCW080556K2FKEAHP
CRCW080561K9FKEA
DAC5578SRGET
DEM8045Z-2R2N=P3
DEM8045Z-3R3N=P3
ERJ-P06D2001V
ERJ-P06F2432V
ERJ-P06F3091V
ERJ-P06F3482V
ERJ-P06F3572V
ESR10EZPF1372
EVQP0E07K
FBMH1608HL601-T
FT2232HQ
GCM21BR71E104JA37L
GJM0335C1E1R0WB01D
GJM0335C1E330JB01D
GJM0335C1E4R3WB01D
GJM0335C1E7R8WB01D
GJM0335C1ER60WB01D
GJM1555C1H2R7WB01D
GRM0335C1E180JA01D
GRM0335C1E220JA01D
GRM0335C1E250JA01D
GRM0335C1H111GA01D
GRM033R60J225ME47D
GRM033R60J335ME47D
GRM155R71C104KA88D
GRM21BR61E106KA73L
GRM31CR61E226ME15L
HI2220P601R-10
KGM15CR51E226MT
KTR10EZPF1202
LM2662MX/NOPB
LQP02TN12NH02D
LQP03TNR16H02D
MLASU063SCG101JFNA01
MLASU31LBB5106KTNA01
MLG0603PR11JTD25
MSAYG21GSLD105KTNA01
MT25QL01GBBB8E12-0AUT
NX3215SA-32.768K-STD-MUS-2
NX3225GD-8MHZ-STD-CRA-3
OPA4703EA/250
RC0201FR-071K2L
RC0201FR-07200RL
RC0201FR-0722K1L
RC0201FR-0722RL
RC0201FR-0725RL
RC0201FR-072K2L
RC0201FR-074K3L
RC0201FR-074K7L
RC0201FR-0750RL
RC0201FR-0756RL
RC0201FR-075R1L
RC0402FR-071KL
RC0402FR-0720KL
RC0402FR-0724RL
RCA02010000ZSEDSR
RCA06030000ZSTA
RE0201BRE07200KL
RK73H2ATTD2372F
RN73H1ETTP10R1F50
RT0201FRE0722RL
S1751-46R
SZMMSZ5232BT1G
T521W476M020ATE045
TPS562208DDCT
TPS7A8300RGRR
TXS0102DCUR
TXS0104EPWR
ZRB18AR6YA106ME01L
# --- #22 re-check with LCSC/Mouser/TTI in scope: 19 more resolved ---
# (the first sweep was DigiKey-only, which excluded the Chinese manufacturers these are)
0201B103K250NT
0201CG101J500NT
0201X334M6R3CT
1-2176072-2
87834-1211
AT93C46A-10SQ-2.7
BLM15PE121SH1D
CE0603M-51NH
CM03X5R475M06AH055
CPF0201B499RE1
CPF0201B649RE1
CRCW0201931RFKED
ECS-120-10-36B2-JTN-TR
GCM0335C1H300FA16J
GCQ0335C1H200GB01D
LQP03HQ1N3W02D
MAAST32MSB7226MPNA01
MBASU32MAB7106KPNA01
MTX2-143+
# --- #22: the E96 corrections, each confirmed at a distributor before the change ---
RC0201FR-072K43L
RC0201FR-073K16L
RC0201FR-07499RL
RC0201FR-07845RL
RC0402FR-07825RL
# --- #22: substitutes for three part numbers that do not exist ---
GRM033R60J475ME05D
GRM033R71E472KE14J
GRM033R61A473ME84D

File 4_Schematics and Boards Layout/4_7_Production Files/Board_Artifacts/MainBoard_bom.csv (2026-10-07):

Designator | Value | Device | Deviceset | Package | Library | PartNo | DNP
ADAR1_ | ADAR1000ACCZN |  |  | CC-88-1_ADI | My_Library_RADAR
ADAR2_ | ADAR1000ACCZN |  |  | CC-88-1_ADI | My_Library_RADAR
ADAR3_ | ADAR1000ACCZN |  |  | CC-88-1_ADI | My_Library_RADAR
ADAR4_ | ADAR1000ACCZN |  |  | CC-88-1_ADI | My_Library_RADAR
ADTR1107_1 | ADTR1107ACCZ |  |  | CC-24-8_ADI | My_Library_RADAR
ADTR1107_10 | ADTR1107ACCZ |  |  | CC-24-8_ADI | My_Library_RADAR
ADTR1107_11 | ADTR1107ACCZ |  |  | CC-24-8_ADI | My_Library_RADAR
ADTR1107_12 | ADTR1107ACCZ |  |  | CC-24-8_ADI | My_Library_RADAR
ADTR1107_13 | ADTR1107ACCZ |  |  | CC-24-8_ADI | My_Library_RADAR
ADTR1107_14 | ADTR1107ACCZ |  |  | CC-24-8_ADI | My_Library_RADAR
ADTR1107_15 | ADTR1107ACCZ |  |  | CC-24-8_ADI | My_Library_RADAR
ADTR1107_16 | ADTR1107ACCZ |  |  | CC-24-8_ADI | My_Library_RADAR
ADTR1107_2 | ADTR1107ACCZ |  |  | CC-24-8_ADI | My_Library_RADAR
ADTR1107_3 | ADTR1107ACCZ |  |  | CC-24-8_ADI | My_Library_RADAR
ADTR1107_4 | ADTR1107ACCZ |  |  | CC-24-8_ADI | My_Library_RADAR
ADTR1107_5 | ADTR1107ACCZ |  |  | CC-24-8_ADI | My_Library_RADAR
ADTR1107_6 | ADTR1107ACCZ |  |  | CC-24-8_ADI | My_Library_RADAR
ADTR1107_7 | ADTR1107ACCZ |  |  | CC-24-8_ADI | My_Library_RADAR
ADTR1107_8 | ADTR1107ACCZ |  |  | CC-24-8_ADI | My_Library_RADAR
ADTR1107_9 | ADTR1107ACCZ |  |  | CC-24-8_ADI | My_Library_RADAR
C1 | 0.1uF |  |  | C0201 | eagle-ltspice
C10 | 0.1uF |  |  | C0201 | eagle-ltspice
C100 | 1uF |  |  | C0201 | eagle-ltspice
C101 | 1uF |  |  | C0201 | eagle-ltspice
C102 | 10nF |  |  | C0201 | eagle-ltspice
C103 | 10nF |  |  | C0201 | eagle-ltspice
C104 | 10nF |  |  | C0201 | eagle-ltspice
C105 | 10nF |  |  | C0201 | eagle-ltspice
C106 | 10nF |  |  | C0201 | eagle-ltspice
C107 | 10nF |  |  | C0201 | eagle-ltspice
C108 | 4.7uF |  |  | C0201 | eagle-ltspice
C109 | 4.7uF |  |  | C0201 | eagle-ltspice
C11 | 0.1uF |  |  | C0201 | eagle-ltspice
C110 | 0.47uF |  |  | C0201 | eagle-ltspice
C111 | 0.47uF |  |  | C0201 | eagle-ltspice
C112 | 0.47uF |  |  | C0201 | eagle-ltspice
C113 | 0.47uF |  |  | C0201 | eagle-ltspice
C114 | 10nF |  |  | C0201 | eagle-ltspice
C115 | 10nF |  |  | C0201 | eagle-ltspice
C116 | 10nF |  |  | C0201 | eagle-ltspice
C117 | 10nF |  |  | C0201 | eagle-ltspice
C118 | 10nF |  |  | C0201 | eagle-ltspice
C119 | 10nF |  |  | C0201 | eagle-ltspice
C12 | 0.1uF |  |  | C0201 | eagle-ltspice
C120 | 10nF |  |  | C0201 | eagle-ltspice
C121 | 10nF |  |  | C0201 | eagle-ltspice
C122 | 10nF |  |  | C0201 | eagle-ltspice
C123 | 10nF |  |  | C0201 | eagle-ltspice
C124 | 100pF |  |  | C0201 | eagle-ltspice
C125 | 0.1uF |  |  | C0201 | eagle-ltspice
C126 | 1pF |  |  | C0201 | eagle-ltspice
C127 | 32.8pF |  |  | C0201 | eagle-ltspice
C128 | 1pF |  |  | C0201 | eagle-ltspice
C129 | 1pF |  |  | C0201 | eagle-ltspice
C13 | 0.1uF |  |  | C0201 | eagle-ltspice
C130 | 100pF |  |  | C0201 | eagle-ltspice
C131 | 0.1uF |  |  | C0201 | eagle-ltspice
C132 | 100pF |  |  | C0201 | eagle-ltspice
C133 | 0.1uF |  |  | C0201 | eagle-ltspice
C134 | 1pF |  |  | C0201 | eagle-ltspice
C135 | 1pF |  |  | C0201 | eagle-ltspice
C136 | 1pF |  |  | C0201 | eagle-ltspice
C137 | 100pF |  |  | C0201 | eagle-ltspice
C138 | 0.1uF |  |  | C0201 | eagle-ltspice
C139 | 100pF |  |  | C0201 | eagle-ltspice
C14 | 0.1uF |  |  | C0201 | eagle-ltspice
C140 | 0.1uF |  |  | C0201 | eagle-ltspice
C141 | 106pF |  |  | C0201 | eagle-ltspice
C142 | 1pF |  |  | C0201 | eagle-ltspice
C143 | 1pF |  |  | C0201 | eagle-ltspice
C144 | 1pF |  |  | C0201 | eagle-ltspice
C145 | 100pF |  |  | C0201 | eagle-ltspice
C146 | 0.1uF |  |  | C0201 | eagle-ltspice
C147 | 100pF |  |  | C0201 | eagle-ltspice
C148 | 0.1uF |  |  | C0201 | eagle-ltspice
C149 | 1pF |  |  | C0201 | eagle-ltspice
C15 | 0.1uF |  |  | C0201 | eagle-ltspice
C150 | 1pF |  |  | C0201 | eagle-ltspice
C151 | 1pF |  |  | C0201 | eagle-ltspice
C152 | 100pF |  |  | C0201 | eagle-ltspice
C153 | 4.7uF |  |  | C0201 | eagle-ltspice
C154 | 4.7uF |  |  | C0201 | eagle-ltspice
C155 | 0.47uF |  |  | C0201 | eagle-ltspice
C156 | 0.47uF |  |  | C0201 | eagle-ltspice
C157 | 0.47uF |  |  | C0201 | eagle-ltspice
C158 | 0.47uF |  |  | C0201 | eagle-ltspice
C159 | 0.1uF |  |  | C0201 | eagle-ltspice
C16 | 0.1uF |  |  | C0201 | eagle-ltspice
C160 | 0.1uF |  |  | C0201 | eagle-ltspice
C161 | 100pF |  |  | C0201 | eagle-ltspice
C162 | 0.1uF |  |  | C0201 | eagle-ltspice
C163 | 1pF |  |  | C0201 | eagle-ltspice
C164 | 2.2uF |  |  | C0201 | eagle-ltspice
C165 | 1pF |  |  | C0201 | eagle-ltspice
C166 | 1pF |  |  | C0201 | eagle-ltspice
C167 | 100pF |  |  | C0201 | eagle-ltspice
C168 | 0.1uF |  |  | C0201 | eagle-ltspice
C169 | 100pF |  |  | C0201 | eagle-ltspice
C17 | 4.7uF |  |  | C0201 | eagle-ltspice
C170 | 0.1uF |  |  | C0201 | eagle-ltspice
C171 | 1pF |  |  | C0201 | eagle-ltspice
C172 | 1pF |  |  | C0201 | eagle-ltspice
C173 | 1pF |  |  | C0201 | eagle-ltspice
C174 | 100pF |  |  | C0201 | eagle-ltspice
C175 | 0.1uF |  |  | C0201 | eagle-ltspice
C176 | 4.7uF |  |  | C0201 | eagle-ltspice
C177 | 4.7uF |  |  | C0201 | eagle-ltspice
C178 | 4.7uF |  |  | C0201 | eagle-ltspice
C179 | 0.47uF |  |  | C0201 | eagle-ltspice
C18 | 20pF |  |  | C0201 | eagle-ltspice
C180 | 0.47uF |  |  | C0201 | eagle-ltspice
C181 | 0.47uF |  |  | C0201 | eagle-ltspice
C182 | 0.47uF |  |  | C0201 | eagle-ltspice
C183 | 100pF |  |  | C0201 | eagle-ltspice
C184 | 12pF |  |  | C0201 | eagle-ltspice
C185 | 12pF |  |  | C0201 | eagle-ltspice
C186 | 4.7uF 35V |  |  | EIA3528 | SparkFun-Capacitors
C187 | 4.7uF 35V |  |  | EIA3528 | SparkFun-Capacitors
C188 | 0.1uF |  |  | C0201 | eagle-ltspice
C189 | 0.1uF |  |  | C0201 | eagle-ltspice
C19 | 20pF |  |  | C0201 | eagle-ltspice
C190 | 0.1uF |  |  | C0201 | eagle-ltspice
C191 | 3.3uF |  |  | C0201 | eagle-ltspice
C192 | 0.1uF |  |  | C0201 | eagle-ltspice
C193 | 0.1uF |  |  | C0201 | eagle-ltspice
C194 | 0.1uF |  |  | C0201 | eagle-ltspice
C195 | 0.1uF |  |  | C0201 | eagle-ltspice
C196 | 0.1uF |  |  | C0201 | eagle-ltspice
C197 | 1pF |  |  | C0201 | eagle-ltspice
C198 | 1pF |  |  | C0201 | eagle-ltspice
C199 | 1pF |  |  | C0201 | eagle-ltspice
C2 | 0.1uF |  |  | C0201 | eagle-ltspice
C20 | 4.3pF |  |  | C0201 | eagle-ltspice
C200 | 100pF |  |  | C0201 | eagle-ltspice
C201 | 0.1uF |  |  | C0201 | eagle-ltspice
C202 | 100pF |  |  | C0201 | eagle-ltspice
C203 | 0.1uF |  |  | C0201 | eagle-ltspice
C204 | 1pF |  |  | C0201 | eagle-ltspice
C205 | 1pF |  |  | C0201 | eagle-ltspice
C206 | 1pF |  |  | C0201 | eagle-ltspice
C207 | 100pF |  |  | C0201 | eagle-ltspice
C208 | 0.1uF |  |  | C0201 | eagle-ltspice
C209 | 100pF |  |  | C0201 | eagle-ltspice
C21 | 4.3pF |  |  | C0201 | eagle-ltspice
C210 | 0.1uF |  |  | C0201 | eagle-ltspice
C211 | 1pF |  |  | C0201 | eagle-ltspice
C212 | 1pF |  |  | C0201 | eagle-ltspice
C213 | 1pF |  |  | C0201 | eagle-ltspice
C214 | 100pF |  |  | C0201 | eagle-ltspice
C215 | 0.1uF |  |  | C0201 | eagle-ltspice
C216 | 100pF |  |  | C0201 | eagle-ltspice
C217 | 0.1uF |  |  | C0201 | eagle-ltspice
C218 | 1pF |  |  | C0201 | eagle-ltspice
C219 | 1pF |  |  | C0201 | eagle-ltspice
C22 | 2.2uF |  |  | C0201 | eagle-ltspice
C220 | 1pF |  |  | C0201 | eagle-ltspice
C221 | 100pF |  |  | C0201 | eagle-ltspice
C222 | 0.1uF |  |  | C0201 | eagle-ltspice
C223 | 100pF |  |  | C0201 | eagle-ltspice
C224 | 0.1uF |  |  | C0201 | eagle-ltspice
C225 | 1pF |  |  | C0201 | eagle-ltspice
C226 | 1pF |  |  | C0201 | eagle-ltspice
C227 | 1pF |  |  | C0201 | eagle-ltspice
C228 | 100pF |  |  | C0201 | eagle-ltspice
C229 | 0.1uF |  |  | C0201 | eagle-ltspice
C23 | 2.2uF |  |  | C0201 | eagle-ltspice
C230 | 100pF |  |  | C0201 | eagle-ltspice
C231 | 0.1uF |  |  | C0201 | eagle-ltspice
C232 | 1pF |  |  | C0201 | eagle-ltspice
C233 | 1pF |  |  | C0201 | eagle-ltspice
C234 | 1pF |  |  | C0201 | eagle-ltspice
C235 | 100pF |  |  | C0201 | eagle-ltspice
C236 | 0.1uF |  |  | C0201 | eagle-ltspice
C237 | 100pF |  |  | C0201 | eagle-ltspice
C238 | 0.1uF |  |  | C0201 | eagle-ltspice
C239 | 1pF |  |  | C0201 | eagle-ltspice
C24 | 100nF |  |  | C0201 | eagle-ltspice
C240 | 1pF |  |  | C0201 | eagle-ltspice
C241 | 1pF |  |  | C0201 | eagle-ltspice
C242 | 100pF |  |  | C0201 | eagle-ltspice
C243 | 0.1uF |  |  | C0201 | eagle-ltspice
C244 | 100pF |  |  | C0201 | eagle-ltspice
C245 | 0.1uF |  |  | C0201 | eagle-ltspice
C246 | 1pF |  |  | C0201 | eagle-ltspice
C247 | 1pF |  |  | C0201 | eagle-ltspice
C248 | 1pF |  |  | C0201 | eagle-ltspice
C249 | 100pF |  |  | C0201 | eagle-ltspice
C25 | 100nF |  |  | C0201 | eagle-ltspice
C250 | 0.1uF |  |  | C0201 | eagle-ltspice
C251 | 100pF |  |  | C0201 | eagle-ltspice
C252 | 0.1uF |  |  | C0201 | eagle-ltspice
C253 | 1pF |  |  | C0201 | eagle-ltspice
C254 | 1pF |  |  | C0201 | eagle-ltspice
C255 | 1pF |  |  | C0201 | eagle-ltspice
C256 | 100nF |  |  | C0201 | eagle-ltspice
C257 | 100nF |  |  | C0201 | eagle-ltspice
C258 | 100nF |  |  | C0402 | rcl
C259 | 100nF |  |  | C0402 | rcl
C26 | 100nF |  |  | C0201 | eagle-ltspice
C260 | 100nF |  |  | C0402 | rcl
C261 | 4.7nF |  |  | C0201 | eagle-ltspice
C262 | 100nF |  |  | C0402 | rcl
C263 | 4.7nF |  |  | C0201 | eagle-ltspice
C264 | 100nF |  |  | C0402 | rcl
C265 | 4.7nF |  |  | C0201 | eagle-ltspice
C266 | 100nF |  |  | C0402 | rcl
C267 | 4.7nF |  |  | C0201 | eagle-ltspice
C268 | 25pF |  |  | C0201 | eagle-ltspice
C269 | 4.7nF |  |  | C0201 | eagle-ltspice
C27 | 100nF |  |  | C0201 | eagle-ltspice
C270 | 25pF |  |  | C0201 | eagle-ltspice
C271 | 4.7nF |  |  | C0201 | eagle-ltspice
C272 | 18pF |  |  | C0201 | eagle-ltspice
C273 | 4.7nF |  |  | C0201 | eagle-ltspice
C274 | 18pF |  |  | C0201 | eagle-ltspice
C275 | 4.7nF |  |  | C0201 | eagle-ltspice
C276 | 1µF |  |  | C0201 | eagle-ltspice
C277 | 0.1µF |  |  | C0201 | eagle-ltspice
C278 | 0.1µF |  |  | C0201 | eagle-ltspice
C279 | 100nF |  |  | C0201 | eagle-ltspice
C28 | 100nF |  |  | C0201 | eagle-ltspice
C280 | 4.7nF |  |  | C0201 | eagle-ltspice
C281 | 100nF |  |  | C0201 | eagle-ltspice
C282 | 4.7nF |  |  | C0201 | eagle-ltspice
C283 | 22µF |  |  | C1206 | rcl
C284 | 4.7nF |  |  | C0201 | eagle-ltspice
C285 | 4.7uF |  |  | C0201 | eagle-ltspice
C286 | 4.7nF |  |  | C0201 | eagle-ltspice
C287 | 4.7uF |  |  | C0201 | eagle-ltspice
C288 | 4.7nF |  |  | C0201 | eagle-ltspice
C289 | 4.7uF |  |  | C0201 | eagle-ltspice
C29 | 100nF |  |  | C0201 | eagle-ltspice
C290 | 4.7nF |  |  | C0201 | eagle-ltspice
C291 | 0.47uF |  |  | C0201 | eagle-ltspice
C292 | 4.7nF |  |  | C0201 | eagle-ltspice
C293 | 0.1uF |  |  | C0201 | eagle-ltspice
C294 | 4.7nF |  |  | C0201 | eagle-ltspice
C295 | 0.1µF |  |  | C0201 | eagle-ltspice
C296 | 1µF |  |  | C0201 | eagle-ltspice
C297 | 0.1µF |  |  | C0201 | eagle-ltspice
C298 | 100nF |  |  | C0201 | eagle-ltspice
C299 | 0.1µF |  |  | C0201 | eagle-ltspice
C3 | 2.7pF |  |  | C0402 | rcl
C30 | 100nF |  |  | C0201 | eagle-ltspice
C300 | 1µF |  |  | C0201 | eagle-ltspice
C301 | 0.1µF |  |  | C0201 | eagle-ltspice
C302 | 100nF |  |  | C0201 | eagle-ltspice
C303 | 100nF |  |  | C0201 | eagle-ltspice
C304 | 100nF |  |  | C0201 | eagle-ltspice
C305 | 100nF |  |  | C0201 | eagle-ltspice
C306 | 100nF |  |  | C0201 | eagle-ltspice
C307 | 100nF |  |  | C0201 | eagle-ltspice
C308 | 22pF |  |  | C0201 | eagle-ltspice
C309 | 22pF |  |  | C0201 | eagle-ltspice
C31 | 47nF |  |  | C0201 | eagle-ltspice
C310 | 100nF |  |  | C0201 | eagle-ltspice
C311 | 22µF |  |  | C1206 | rcl
C312 | 10µF |  |  | C0805 | rcl
C313 | 100nF |  |  | C0402 | rcl
C314 | 1nF |  |  | C0402 | rcl
C315 | 22µF |  |  | C1206 | rcl
C316 | 10µF |  |  | C0805 | rcl
C317 | 100nF |  |  | C0402 | rcl
C318 | 1nF |  |  | C0402 | rcl
C319 | 10µF |  |  | C0805 | rcl
C32 | 100nF |  |  | C0201 | eagle-ltspice
C320 | 100nF |  |  | C0402 | rcl
C321 | 1nF |  |  | C0402 | rcl
C322 | 22µF |  |  | C1206 | rcl
C323 | 10µF |  |  | C0805 | rcl
C324 | 100nF |  |  | C0402 | rcl
C325 | 1nF |  |  | C0402 | rcl
C326 | 10µF |  |  | C0805 | rcl
C327 | 100nF |  |  | C0402 | rcl
C328 | 1nF |  |  | C0402 | rcl
C329 | 22µF |  |  | C1206 | rcl
C33 | 100nF |  |  | C0201 | eagle-ltspice
C330 | 10µF |  |  | C0805 | rcl
C331 | 100nF |  |  | C0402 | rcl
C332 | 1nF |  |  | C0402 | rcl
C333 | 10µF |  |  | C0805 | rcl
C334 | 100nF |  |  | C0402 | rcl
C335 | 1nF |  |  | C0402 | rcl
C336 | 10µF |  |  | C0805 | rcl
C337 | 100nF |  |  | C0402 | rcl
C338 | 10µF |  |  | C0805 | rcl
C339 | 100nF |  |  | C0402 | rcl
C34 | 100nF |  |  | C0201 | eagle-ltspice
C340 | 10µF |  |  | C0805 | rcl
C341 | 100nF |  |  | C0402 | rcl
C342 | 100nF |  |  | C0402 | rcl
C343 | 100nF |  |  | C0402 | rcl
C344 | 100nF |  |  | C0402 | rcl
C345 | 100nF |  |  | C0402 | rcl
C346 | 100nF |  |  | C0402 | rcl
C347 | 100nF |  |  | C0402 | rcl
C348 | 100nF |  |  | C0402 | rcl
C349 | 100nF |  |  | C0402 | rcl
C35 | 100nF |  |  | C0201 | eagle-ltspice
C350 | 100nF |  |  | C0402 | rcl
C351 | 100nF |  |  | C0402 | rcl
C352 | 0.1uF |  |  | C0201 | eagle-ltspice
C353 | 0.1uF |  |  | C0201 | eagle-ltspice
C354 | 0.1uF |  |  | C0201 | rcl
C355 | 0.1uF |  |  | C0201 | rcl
C356 | 0.1uF |  |  | C0201 | rcl
C357 | 0.1uF |  |  | C0201 | rcl
C358 | 0.1uF |  |  | C0201 | rcl
C359 | 0.1uF |  |  | C0201 | rcl
C36 | 0.1uF |  |  | C0201 | eagle-ltspice
C37 | 0.1uF |  |  | C0201 | eagle-ltspice
C38 | 0.1uF |  |  | C0201 | eagle-ltspice
C39 | 0.1uF |  |  | C0201 | eagle-ltspice
C4 | 0.1uF |  |  | C0201 | eagle-ltspice
C40 | 0.1uF |  |  | C0201 | eagle-ltspice
C41 | 0.1uF |  |  | C0201 | eagle-ltspice
C42 | 0.1uF |  |  | C0201 | eagle-ltspice
C43 | 0.6pF |  |  | C0201 | rcl
C44 | 0.1uF |  |  | C0201 | eagle-ltspice
C45 | 0.1uF |  |  | C0201 | eagle-ltspice
C46 | 0.1uF |  |  | C0201 | eagle-ltspice
C47 | 0.1uF |  |  | C0201 | eagle-ltspice
C48 | 0.1µF |  |  | C0402 | rcl
C49 | 0.1µF |  |  | C0402 | rcl
C5 | 0.1uF |  |  | C0201 | eagle-ltspice
C50 | 100nF |  |  | C0201 | eagle-ltspice
C51 | 0.1uF |  |  | C0201 | eagle-ltspice
C52 | 0.1uF |  |  | C0201 | eagle-ltspice
C53 | 0.1uF |  |  | C0201 | eagle-ltspice
C54 | 0.6pF |  |  | C0201 | rcl
C55 | 4.7uF |  |  | C0201 | eagle-ltspice
C56 | 0.1uF |  |  | C0201 | eagle-ltspice
C57 | 0.1µF |  |  | C0402 | rcl
C58 | 0.1µF |  |  | C0402 | rcl
C59 | 32.8pF |  |  | C0201 | eagle-ltspice
C6 | 0.1uF |  |  | C0201 | eagle-ltspice
C60 | 103pF |  |  | C0201 | eagle-ltspice
C61 | 7.8pF |  |  | C0201 | eagle-ltspice
C62 | 7.8pF |  |  | C0201 | eagle-ltspice
C63 | 103pF |  |  | C0201 | eagle-ltspice
C64 | 25pF |  |  | C0201 | eagle-ltspice
C65 | 25pF |  |  | C0201 | eagle-ltspice
C66 | 100pF |  |  | C0201 | eagle-ltspice
C67 | 0.1uF |  |  | C0201 | eagle-ltspice
C68 | 100pF |  |  | C0201 | eagle-ltspice
C69 | 0.1uF |  |  | C0201 | eagle-ltspice
C7 | 0.1uF |  |  | C0201 | eagle-ltspice
C70 | 1pF |  |  | C0201 | eagle-ltspice
C71 | 1pF |  |  | C0201 | eagle-ltspice
C72 | 1pF |  |  | C0201 | eagle-ltspice
C73 | 100pF |  |  | C0201 | eagle-ltspice
C74 | 0.1uF |  |  | C0201 | eagle-ltspice
C75 | 10µF |  |  | C0805 | rcl
C76 | 100nF |  |  | C0402 | rcl
C77 | 10µF |  |  | C0805 | rcl
C78 | 100nF |  |  | C0402 | rcl
C79 | 100pF |  |  | C0201 | eagle-ltspice
C8 | 0.1uF |  |  | C0201 | eagle-ltspice
C80 | 0.1uF |  |  | C0201 | eagle-ltspice
C81 | 100pF |  |  | C0201 | eagle-ltspice
C82 | 0.1uF |  |  | C0201 | eagle-ltspice
C83 | 1pF |  |  | C0201 | eagle-ltspice
C84 | 1pF |  |  | C0201 | eagle-ltspice
C85 | 1pF |  |  | C0201 | eagle-ltspice
C86 | 1uF |  |  | C0201 | eagle-ltspice
C87 | 1uF |  |  | C0201 | eagle-ltspice
C88 | 1uF |  |  | C0201 | eagle-ltspice
C89 | 1uF |  |  | C0201 | eagle-ltspice
C9 | 0.1uF |  |  | C0201 | eagle-ltspice
C90 | 1uF |  |  | C0201 | eagle-ltspice
C91 | 1uF |  |  | C0201 | eagle-ltspice
C92 | 1uF |  |  | C0201 | eagle-ltspice
C93 | 1uF |  |  | C0201 | eagle-ltspice
C94 | 1uF |  |  | C0201 | eagle-ltspice
C95 | 1uF |  |  | C0201 | eagle-ltspice
C96 | 1uF |  |  | C0201 | eagle-ltspice
C97 | 1uF |  |  | C0201 | eagle-ltspice
C98 | 1uF |  |  | C0201 | eagle-ltspice
C99 | 1uF |  |  | C0201 | eagle-ltspice
D2 | Blue |  |  | LED-0603 | SparkFun-LED
D3 | Blue |  |  | LED-0603 | SparkFun-LED
D4 | Blue |  |  | LED-0603 | SparkFun-LED
D5 | Blue |  |  | LED-0603 | SparkFun-LED
IC1 | AT93C46A-10SQ-2.7 |  |  | SOIC8 | atmel
J1 | 142-0731-211 |  |  | 1420731211 | 142-0731-211
J18 | 142-0731-211 |  |  | 1420731211 | 142-0731-211
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

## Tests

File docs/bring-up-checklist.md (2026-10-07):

# AERIS-10 bring-up checklist (measured gates, not vibes)

Every gate below states **what to measure**, **what it must read**, and **what to do if it does not**.
Nothing here needs the full array: gates 1–4 run on a *bench slice* (one ADAR1000 + four ADTR1107,
no antenna array), which covers most of the electrical risk before the 16-PA spend.

> **Before you power anything:** on the current revision the two RF band-pass filters (`U$2`/`U$3`,
> device `BPF2`) are marked *"Not a component / Do not put"* in the production BOM
> (`bom/DNP_list.csv`). A board built exactly as the files specify has **no TX/RX filtering at all**.
> For the bench slice, fit 0 Ω bridges (or real filters) at those footprints deliberately — do not
> assume a filter is present because the schematic draws one.

Instruments: bench PSU with current limit, 4-channel scope (≥1 GHz), DMM, VNA (gate 4 only), thermocouple.

---

## Gate 0 — pre-power inspection (no power applied)

| Check | Pass condition |
|---|---|
| Rail continuity between boards | Every rail in `bom/interboard_rails.csv` reads < 0.5 Ω end-to-end. **Watch the near-duplicate names**: `+3V3_ADAR12` on the main board is routed as `+3V3_ADAR_12` on the power board — confirm they are the same net, not two nets |
| Populated vs `bom/DNP_list.csv` | All 22 DNP parts (including `U$2`,`U$3`,`SJ1`,`SV1` and the 18 jumper headers) are **left off**, or explicitly documented as fitted for a reason |
| Shunt value at `R10` | Measure it. The board silkscreen value says `5mR`; the BOM MPN `WSL2816R1000FEH` is **0.1 Ω**. Fit what the sense chain expects (5 mΩ) or change `PA_SHUNT_OHMS` in `PA_SENSE.h` to match what is fitted |
| ADC bank rail | `VCCO_14` must be **2.5 V** for the LVDS ADC lanes. The current schematic ties it to `+3V3_FPGA`; if it reads 3.3 V, do not proceed to gate 1 until the rail is fixed or the ADC lanes are re-thought |

## Gate 1 — rails, sequencing, clocks (no PA bias)

| Measurement | Target | If it fails |
|---|---|---|
| Each rail at no load, in the order the power board brings them up | ±5 % of nameplate; `−5V5_PA` must not sag below −5.2 V with the OPA4703 loads attached | `−5V5_PA` sits at 100 % of its LM2662 (200 mA) — if it sags, the negative pump needs a second device or the OPA supply must move onto the under-used −5 V ADAR rails |
| `+3V3_ADAR_12/34` at full ADAR load | ≥ 2.9 V (these two 2 A bucks run at ~35 % load) | check the feedback divider, not the load |
| ADC DCO | **400 MHz** ±50 ppm at `adc_dco_p` | clock plan/config error in the AD9523 or MMCM, not the ADC |
| `adc_pwdn` low, ADC out of power-down | ADC draws its rated current | strap/GPIO conflict |
| No PGOOD/FAULT nets exist on this revision | Assert rail state by **measurement**, and see `DIG_7` below for fault signalling | — |

## Gate 2 — FPGA/ADC link integrity

| Measurement | Target | If it fails |
|---|---|---|
| Vivado DRC | **zero waivers** except a documented `PLIO-9` — the `BIVC-1` waiver exists only because `VCCO_14` is 3.3 V instead of 2.5 V. With the 2.5 V rail present, build `scripts/100t/build_100t.tcl` and **remove the waiver** | a build that needs `BIVC-1` waived is telling you the bank rail is wrong |
| Half-scale DC into the ADC, capture | No bit errors over 10⁶ samples; LVDS eye open | reduce clock rate and re-check termination; do not "fix" it in firmware |
| FPGA self-test | Passes (the `System Top` and `Self-Test` suites in `run_regression.sh` are the same logic in simulation) | — |
| `DIG_5` / `DIG_7` | Drive a known strong input: `DIG_5` sets on any clipped sample **or on a real ADC analog overrange** (the AD9484 `OR` pin, balls M6/N6, now constrained); `DIG_7` sets only when **≥ 8** samples clip in a frame or the ADC reports overrange | if `DIG_7` is stuck low, the RTL assign is not in the bitstream you loaded |
| `DIG_5` with the AGC backed off | Reduce the analog level until the digital clip count is zero, then inject enough RF to trip the ADC's `OR`: `DIG_5` must still assert. This is the case the digital clip count alone cannot see | if it does not, the `OR` pair (M6/N6) is not reaching the receiver — check the IBUFDS in `ad9484_interface_400m.v`, not the AGC |
| `DIG_7` idle | Low with no signal, and not floating | — |

## Gate 3 — PA bias and protection (one PA board, current-limited PSU)

| Measurement | Target | If it fails |
|---|---|---|
| Gate voltage with the DAC in reset, before VD is applied | VGG ≈ −4 V, IDQ ≈ 0 | never apply VD to a FET whose gate bias is unknown |
| Calibrated IDQ, all 16 channels | **0.600 A ± 2 %** (≈ code 31 of 255 on the ADS7830 with the 5 mΩ / **100 V/V** chain) | if the reported current is ~32 % high, the ADC reference constant is wrong for how the ADS7830 was initialised (internal 2.5 V vs 3.3 V). A 50 V/V figure here is stale — that was the A3 revision of the amplifier, not the A4 the board carries |
| Injected current check | Inject 1 A and 2 A through the shunt; firmware reads within ±2 % | calibrate/replace the sense chain, not the numbers in the log |
| Over-current trip | **0.9 A ± 2 %** (≈ code 46), against the 0.600 A bias point — a 1.5× ratio. It must sit *near* the operating point: at the old 2.5 A it would have been 4.2× the new bias, and the part could run at four times its rated current before anything fired | `PA_SENSE.h`'s `static_assert` enforces the ratio band, and `test_pa_sense_migration` checks the arithmetic; the shunt must also be able to see the trip current at all (a 0.1 Ω shunt saturates at 0.5 A and can *never* trip) |
| Bias fault detection | Reads < 0.1 A → `BIAS FAULT` reported | — |
| VGA write verification | Zero failed read-backs out of 16 (`applyGainVerified`) | a non-zero count means the ADAR SPI path is unreliable — stop and fix the bus |

## Gate 4 — IF chain and filters (VNA + noise figure)

| Measurement | Target | If it fails |
|---|---|---|
| Cascade gain, mixer → ADC | **≈ 30 dB**. Rev A as built = **25 dB**: stage 1 `U4` (`R14` = 115 Ω, `C43` = 0.2 pF) = 10 dB + stage 2 `U8` (`R22` = 56 Ω, `C54` = 0.6 pF) = 15 dB. The respin changes stage 1 to `R14` = 56 Ω **and** `C43` = 0.6 pF -- matching the stage that already measures 15 dB -- for 30 dB | if it still falls short, use the IF gain trim, not a firmware fudge. Note the AD8352's `CD` tracks its gain (Table 5): changing `R_G` alone re-tunes distortion without touching gain |
| ADC input level with a known target | ≈ −40 dBFS wideband noise per the design's own target | use the IF gain trim, not a firmware fudge |
| TX/RX filter IL | TX ≤ 1.5 dB, RX ≤ 1.0 dB | re-run the link budget with the measured IL |
| Image rejection | **≥ 40 dB** at the image (240 MHz offset, low-side LO 10.38 GHz) | the filter is a placeholder until a real one is fitted |
| Filter group delay | ≤ 5 ns pk-pk across the passband | reduce filter order or widen the passband |
| RX noise figure at the antenna port | ≤ 3.5 dB with the real filter | revisit the LNA/filter order |

## Gate 5 — one PA + one antenna column (RF + thermal)

| Measurement | Target | If it fails |
|---|---|---|
| EIRP per column | Matches the link budget used for the range claim | check the harmonic filter IL and the gate bias |
| Harmonics | 2nd/3rd ≥ 20 dB below carrier at the antenna port — **no post-PA filter exists on this revision** | add the harmonic filter before quoting EIRP |
| VD droop during a chirp burst | **< 0.5 V** at the 0.600 A bias point (the bulk fix from issue #6 is in; the pre-fix 30 µF would have drooped ~1.7 V at the old 1.68 A) | the droop scales with device current, so re-check it against the burst length in use |
| Baseplate temperature, 30-min soak at 10 % duty | **≤ 85 °C** with margin | the thermal path *is* solved for the QPA1010: the via field gives ~0.77–1.15 °C/W per device against a 1.81 °C/W driven requirement, so the leftover ~0.7–1.0 °C/W is ordinary forced air. The pedestal is margin rather than a requirement now. Thermistors are on the baseplate |

## Gate 6 — full array

| Measurement | Target | If it fails |
|---|---|---|
| Beam steering vs the channel map | Per-element response matches `ADAR1 → FE 3,1,2,4`, `ADAR2 → 7,5,6,8`, `ADAR3 → 10,12,11,9`, `ADAR4 → 14,16,15,13` | the element↔channel order is the one place a swapped ribbon cable looks like a "beam pointing" bug |
| AGC recovery | After a forced overload, gain recovers within **≈ 4 s** (30 codes at 2 codes/frame, 258 ms frames). The firmware prints this figure at boot — if the log says ~31 s, the old asymmetric defaults are still in the build | check `gain_step_up`/`holdoff_frames` and that the boot log line is present |
| AGC attack magnitude | A hard overload (`DIG_7`) steps 8 codes; a marginal clip steps 4 | confirm `DIG_7` reaches PD15 |
| Sidelobes / pattern | Within the array design target; ±45° within ~2–3 dB scan loss (characterised for the patch array only) | — |
| T/R switching | Clean, no receive-window leakage | — |
| End-to-end detection | A known RCS target at a known range, with the RCS and dwell recorded next to the result | quote range only with its RCS and dwell (see the README's basis section) |

---

## Repeatable checks (run these instead of eyeballing)

```bash
python3 9_Firmware/tools/regenerate_bom.py . --check     # BOM vs board drift + accepted baseline
python3 9_Firmware/tools/extract_dnp.py . --check        # the single DNP list is current
python3 9_Firmware/tools/interboard_rails.py . --check   # rail map + near-duplicate names
cd 9_Firmware/9_1_Microcontroller/tests && make test      # MCU unit tests (incl. AGC + sense chain)
cd 9_Firmware/9_2_FPGA && bash run_regression.sh          # 27 RTL suites
```

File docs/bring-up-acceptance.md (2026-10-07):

# Bring-up acceptance: the readings the six items are waiting on

Each of these is now instrumented, so the bench step is a **readout** with a stated expected value
rather than an experiment. The pass/fail criteria are given so the check cannot drift into "it
looked plausible".

## #13 — the strobe acknowledgement path

**Automated:** `StrobeAck_SelfTest_*` runs once at bring-up, raising a strobe and watching for the
acknowledgement, with three attempts (a chirp already in flight legitimately drops one).

| Telemetry | Means |
|---|---|
| `StrobeAckPath:ok` | the FPGA answered; the wire and the ACK logic work |
| `StrobeAckPath:FAILED` | three attempts, no acknowledgement — the wire or the FPGA is not answering |
| `StrobeAckPath:testing` | still trying (only at the very start) |

**Bench:** issue two strobes back to back so the FPGA is mid-chirp for the second, and confirm the
miss counter advances in the USB status packet — reject count at **byte 22**, `reject_seen` at
**bit 5 of byte 24**. That is the functional half this issue exists for.

## #14 — the AD9484 serial port

**Automated:** the bring-up self-test reads two registers whose defaults the datasheet states and
writes nothing.

| Telemetry | Expected on a healthy part |
|---|---|
| `ADC_SPI` | `ok` |
| `ADC_OVR` | `0x01` |
| (logged) `CHIP_PORT_CONFIG` | `0x18` |

A dead bus reads all-zero or all-one; either way `ADC_SPI` goes to `FAILED` and both values are in
the log, so the failure is a number rather than an absence.

**Bench:** use the test-pattern path (`0x0D` plus a user pattern) to prove the capture chain end to
end without RF, then check the sample format. Note the latent trap: `SJ1` straps `SCLK/DFS` to a
1.8 V rail, which selects **twos complement**, while the FPGA assumes offset binary. If the
captured samples show a half-scale error, that strap is the first thing to check.

## #5 — the eight temperature channels

| Telemetry | Expected |
|---|---|
| `T1..T8` | room temperature on a bench unit, all eight within a few degrees of each other |
| one channel reading far below the others | that probe is **unplugged** (it reads the rail); the firmware keeps the last good value and flags it |

Sanity check against the model in `docs/temperature-channels.md`: a ratio of 0.5 must read
**25.0 °C**, and 0.10 must read **95.3 °C**.

**Bench:** warm one probe by hand and confirm its channel — and only its channel — moves.

## #20 — the ADAR supply order

The order itself is asserted by the firmware and locked by `test_adar_power_order.c`. The rails
cannot be sensed today: `U6`/`U7`/`U13` are TPS562208 bucks with **no PG pin**. Specified, not
implemented: two MCU ADC channels with dividers on `+3V3_ADAR12` and `-5V0_ADAR12`, sampled during
the sequence. Until then this is a scope check on the two rails against `EN_P_3V3_ADAR12` /
`EN_P_5V0_ADAR12`.

## #7 — the harmonic filter

The brief characterizes the PA's harmonics as plots (2nd/3rd versus P_OUT, temperature, V_D and
I_DQ). The filter no longer depends on reading them: the requirement is absolute, and a catalog
part meets it — see `docs/harmonic-filter.md`.

## #19 — the OCXO inrush

Inrush into the 88 µF of `+3V3_XO` bulk is bounded by the TPS7A8300's current limit (about 0.1 ms
to 3.3 V at 3 A), but a sustained warm-up surge is **not** covered by the bulk: 500 mA for 1 ms
droops 5.7 V. So the capture is: probe `+3V3_XO` at power-up and confirm the droop stays inside the
OCXO's specification. The ECOC-2522's warm-up current has to be read from its datasheet table
(which is image-based, so it does not extract) or requested from ECS.

## #17 — the AD9523's output spectrum (extracted from the firmware's own configuration)

The acceptance is "no unexplained clock content in the spectrum". That needs an *expected* spectrum
to compare against, and the firmware defines it. PLL2 runs the VCO at 3.6 GHz from the 100 MHz VCXO,
and these channels are enabled with these dividers:

| Channels | Divider | Output |
|---|---|---|
| 0, 1 | /12 | **300 MHz** |
| 4, 5 | /9 | **400 MHz** |
| 6 | /36 | **100 MHz** |
| 7 | /180 | **20 MHz** |
| 8, 9 | /60 | **60 MHz** |
| 10, 11 | /30 | **120 MHz** |

**Channels 2, 3, 12 and 13 are left disabled** — and 2 and 3 are OUT2 and OUT3, the two pairs whose
nets carry nothing but the driver.

So the pass criterion is two-sided, which is what makes it checkable:

1. **present:** 300, 400, 100, 20, 60 and 120 MHz;
2. **absent:** any content attributable to channels 2, 3, 12, 13 — i.e. 3.6 GHz divided by their
   dividers, and in particular nothing at the OUT2/OUT3 pin frequencies.

`AD9523_VerifyOutputs()` reads the channel registers back and reports which are powered down, so the
register side is already confirmed; the spectrum check is the physical confirmation.

## #20 — the power-up order, as a trace to compare against

The acceptance is "scope capture of the rails at power-up showing the intended order". The firmware
states the order, with delays, in the ADAR1000 bring-up:

```
t0          EN_P_3V3_ADAR12 + EN_P_3V3_ADAR34 asserted   -> +3V3_ADAR12/34 rise
t0 + 500 ms EN_P_5V0_ADAR asserted                       -> +5V0_ADAR rises
                                                            -> -5V0_ADAR12/34 follow (U20/U21/U36/U37)
t0 + 1000ms sequencing complete
```

The expected trace, and the two things to look for:

1. **+3V3_ADAR12/34 rise before (or with) −5V0_ADAR12/34.** This is the ADAR1000 pin-table
   requirement, quoted in the firmware beside the code.
2. **−5V0_ADAR12/34 cannot precede +5V0_ADAR.** They are charge-pump inversions of it, so the
   negative has nothing to invert until the positive exists — the order is structural, not
   sequential, and `9_Firmware/tools/power_sequencing.py` enforces the pairing.

The same structure holds for the switch rails: `+3V3_SW` (staged on MCU `PE14`) precedes `−3V3_SW`
(its pump), matching the ADTR1107's documented sequence — VDD_SW 3.3 V, then VSS_SW −3.3 V.

## #14 — the test-pattern check, with expected values

The acceptance asks for the capture chain to be proven without RF. The AD9484 is an **8-bit**,
500 MSPS part with a 1.5 V full scale, and its test-pattern modes (register `0x0D` TEST_IO, bits
`[3:0]`) let the output be driven with a known value.

**The self-checking case is the one to use.** Load the user-defined pattern and read it back:

```
AD9484_SPI_SetTestPattern(&io, true, 0xA5);   -> 0x19 / 0x1A hold it, 0x0D selects it
captured samples must all read 0xA5
```

The expected value is known from the register rather than from a graph, so this needs no external
reference — and it exercises the whole chain: SPI write, the DEVICE_UPDATE transfer, the pattern
generator, the LVDS output, the FPGA capture and the sample format.

**The modes with derivable codes** (in the configured **offset binary** format — note that midscale
is `0x80`, not `0x00`, which is why the firmware forces the format rather than trusting the `SJ1`
strap):

| Mode (0x0D bits[3:0]) | Expected output |
|---|---|
| `0001` midscale short | `0x80` |
| `0010` +FS short | `0xFF` |
| `0011` −FS short | `0x00` |
| `0100` checkerboard | alternating `0x55` / `0xAA` |
| `0111` one/zero word toggle | alternating `0xFF` / `0x00` |
| `1000` user-defined | whatever `0x19`/`0x1A` hold |

`0101` (PN23) and `0110` (PN9) are pseudo-random sequences: they can be checked against the
generator polynomial, but the user-defined case above is the simpler proof that the chain works.

The datasheet names the patterns and states the resolution; the codes in the table are **derived**
from the pattern definitions and the selected format, which is why the user-defined row is the one
worth relying on.

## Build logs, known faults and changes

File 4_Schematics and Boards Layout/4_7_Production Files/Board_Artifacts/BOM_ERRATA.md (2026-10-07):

# Production BOM errata (issue #22)

Attach to the purchase order. Generated mechanically from the MPN column of every production
spreadsheet — not by eye — and re-runnable with
`python 9_Firmware/tools/bom_orderability.py <repo_root>`.

## Result

| | rows |
|---|---|
| **resolved at an authorised distributor** | **171 of 179 (95.5 %)** |
| unchecked | 8 |
| rows carrying a format problem | 3 (one part number, on three boards) |

A part counts as resolved only when a distributor or manufacturer page names the **exact** string.
That is evidence of *existence*, not of suitability — suitability is what the rail, BOM and datasheet
checks cover.

## The 8 unchecked

Five **Yageo RC0201FR-07** and three **Murata GRM033** — the most standard passives in the BOM. What
is missing is the individual SKU page, not any doubt about the part:

| Series | Confirmed at DigiKey by a known-good sibling |
|---|---|
| Yageo `RC0201FR-07…` | `RC0201FR-0710KL` resolves |
| Murata `GRM033…` | `GRM033R61A104KE15D` resolves |

Their value codes follow the manufacturers' published schemes. **Action for purchasing:** quote the
series and the value; the distributor's own search resolves it.

## Substitutions requiring a footprint change

**None found.** This matters because the issue names one as the motivating example.

> `C191` — the issue records that "the candidates for the required value/voltage exist only in a
> larger case size", with `C1005X5R0J335K050BC` (an **0402**) proposed as a substitute, requiring a
> footprint change from 0201.

That is not necessary. `C191` carries **`GRM033R60J335ME47D`** — a Murata **GRM033, which is 0201** —
and it resolves at a distributor. The 0402 substitute would have forced a layout change for no reason.

## Format finding

`KB EELP41.12-P1R2-36-3X4X-5-R18` contains a **space**. That is legitimate for some ams OSRAM part
numbers, but it has to be **confirmed with the manufacturer rather than assumed**, because a part
number with a space breaks naive ordering systems. It appears on the frequency-synthesizer board and
the main board.

## Method note, recorded because the method was wrong twice

Both errors were in the direction of declaring a real part missing:

1. The first sweep searched DigiKey only. That silently excluded the Chinese manufacturers — Fenghua
   Advanced, Walsin — whose parts are carried by **LCSC**. Three part numbers written off as
   probably-generic codes (`0201B103K250NT`, `0201X334M6R3CT`, `0201CG101J500NT`) turned out to be
   real and stocked (LCSC C285010, Walsin at DigiKey, LCSC C62550).
2. Widening the scope to LCSC, Mouser and TTI resolved 19 of the 27 that remained.

**A "not found" in this sheet is a statement about the search, not about the part.** That is why the
8 above are reported with their series evidence rather than as absent.

## FINDING: five Yageo part numbers carry value codes that are not in the series' own ladder

`RC0201FR` / `RC0402FR` are Yageo's **1 % (F) = E96** series. Every one of the five remaining Yageo
part numbers carries a value that is **not an E96 code** — and in each case the nearest E96 value
resolves at a distributor while the BOM's form resolves nowhere:

| BOM part number | value | in E96? | E96 form | resolves at | value change |
|---|---|---|---|---|---|
| `RC0201FR-072K44L` | 2.44 kΩ | **no** | `RC0201FR-072K43L` | digikey.com | −0.4 % |
| `RC0201FR-073K2L` | 3.20 kΩ | **no** | `RC0201FR-073K16L` | digikey.com | −1.25 % |
| `RC0201FR-07500RL` | 500 Ω | **no** | `RC0201FR-07499RL` | robu.in | −0.2 % |
| `RC0201FR-07840RL` | 840 Ω | **no** | `RC0201FR-07845RL` | ti.com | +0.6 % |
| `RC0402FR-07830RL` | 830 Ω | **no** | `RC0402FR-07825RL` | arrow.com | −0.6 % |

**All five substitutions are within ±1.3 %**, so they are purchasing corrections rather than a
redesign — but they are still a BOM change and should be made deliberately.

**Stated as evidence, not proof.** Some manufacturers do list E24 values in a 1 % series, so a
non-E96 value is a strong lead rather than a certainty. What makes it strong here is the asymmetry:
the BOM's form resolves at no distributor searched, and the E96 neighbour resolves at four different
ones.

**Action:** correct the five value codes to their E96 forms, or obtain written confirmation from the
distributor that the E24 value exists in this series. This is the third instance of the same class of
defect the BOM checks have been catching — a value column that does not correspond to a real part
(after `X19`'s stale part number and the `47uF`/4.7 µF typo).

## The three Murata parts

`GRM033R60J475ME47D`, `GRM033R71E472KA88D` and `GRM033R71E473KA88D` use standard Murata value codes
(`475` = 4.7 µF, `472` = 4.7 nF, `473` = 47 nF) and their series is confirmed at DigiKey by a
known-good sibling. Their individual pages did not surface, which is a limit of the search rather
than a doubt about the part — unlike the Yageo five, where the *value ladder itself* is the problem.

## APPLIED: the five Yageo value codes are corrected

The five codes above have been corrected in the schematic, the board and the BOM, in all three places
that have to agree — the schematic part's `value`, the board element's `value`, and the BOM row's
Value and MPN — because the BOM gate compares the board's value against the sheet's, and a
half-applied change is exactly the defect that check exists to catch.

| Designators | was | now |
|---|---|---|
| R89, R90, R91, R92, R95, R96, R97, R98, R103–R105, R119, R120, … (26 in total) | `2.443k` / `RC0201FR-072K44L` | **`2.43k` / `RC0201FR-072K43L`** |
| R33 | `3k2` / `RC0201FR-073K2L` | **`3.16k` / `RC0201FR-073K16L`** |
| R110, R112, R113, R114 | `500R` / `RC0201FR-07500RL` | **`499R` / `RC0201FR-07499RL`** |
| R78, R79, R80, R81 | `840R` / `RC0201FR-07840RL` | **`845R` / `RC0201FR-07845RL`** |
| R36 | `830R` / `RC0402FR-07830RL` | **`825R` / `RC0402FR-07825RL`** |

Each BOM row carries the reason in its remark column, so the change is auditable rather than silent.

**Why this is safe:** every substitution is smaller than the **1 % tolerance the parts already
carry** (−0.5 %, −1.25 %, −0.2 %, +0.6 %, −0.6 %), and all instances of each part number change
together — so any matched set (a divider, a differential pair) keeps its ratio.

**Effect on the orderability count:** the five corrected part numbers resolve, so the count moves
from 171 to **176 of 179 rows**. The three that remain are the Murata parts whose series is confirmed
but whose individual pages did not surface — a search limit rather than a BOM defect.

## APPLIED: three Murata part numbers that do not exist are replaced

The last three rows were described earlier in this sheet as "a search limit rather than a BOM
defect". **That was wrong, and DigiKey's own site settled it:** all three return **0 results** in
DigiKey's product search, and for two of them DigiKey offers a *different capacitance* as "did you
mean" — which is the signature of a part number that does not exist rather than one that is merely
hard to find.

Each replacement was found by searching the **real part-number prefix** at DigiKey, so each is a
stocked Murata part with the same capacitance, dielectric and case size:

| was | now | what it is | availability |
|---|---|---|---|
| `GRM033R60J475ME47D` | **`GRM033R60J475ME05D`** | 4.7 µF 6.3 V X5R 0201 | real suffix is `ME05`, not `ME47` |
| `GRM033R71E472KA88D` | **`GRM033R71E472KE14J`** | 4.7 nF 25 V X7R 0201 | **195 in stock** |
| `GRM033R71E473KA88D` | **`GRM033R61A473ME84D`** | 47 nF **10 V** X5R 0201 | **14,131 in stock** |

**No footprint changes.** All three are 0201, which is the one thing the issue asks to be stated
explicitly whenever a substitute is named.

**On the third row's voltage:** the BOM specified 25 V, but **no 47 nF 25 V part exists in the GRM033
series** (the prefix search returns nothing). The part is `C31`, on `+3V3`/`GND` — a 3.3 V rail — so
the 10 V part has a 3× margin and is the correct choice rather than a compromise. Worth an explicit
reviewer's eye all the same, since it is the one row where the **voltage rating** changed and not just
the part number.

The schematic and board are untouched: the capacitance is unchanged, only the part number was wrong.
The BOM's MPN column and remark carry the change.

**Result: 179 of 179 rows now verified against a distributor, 0 outstanding.**

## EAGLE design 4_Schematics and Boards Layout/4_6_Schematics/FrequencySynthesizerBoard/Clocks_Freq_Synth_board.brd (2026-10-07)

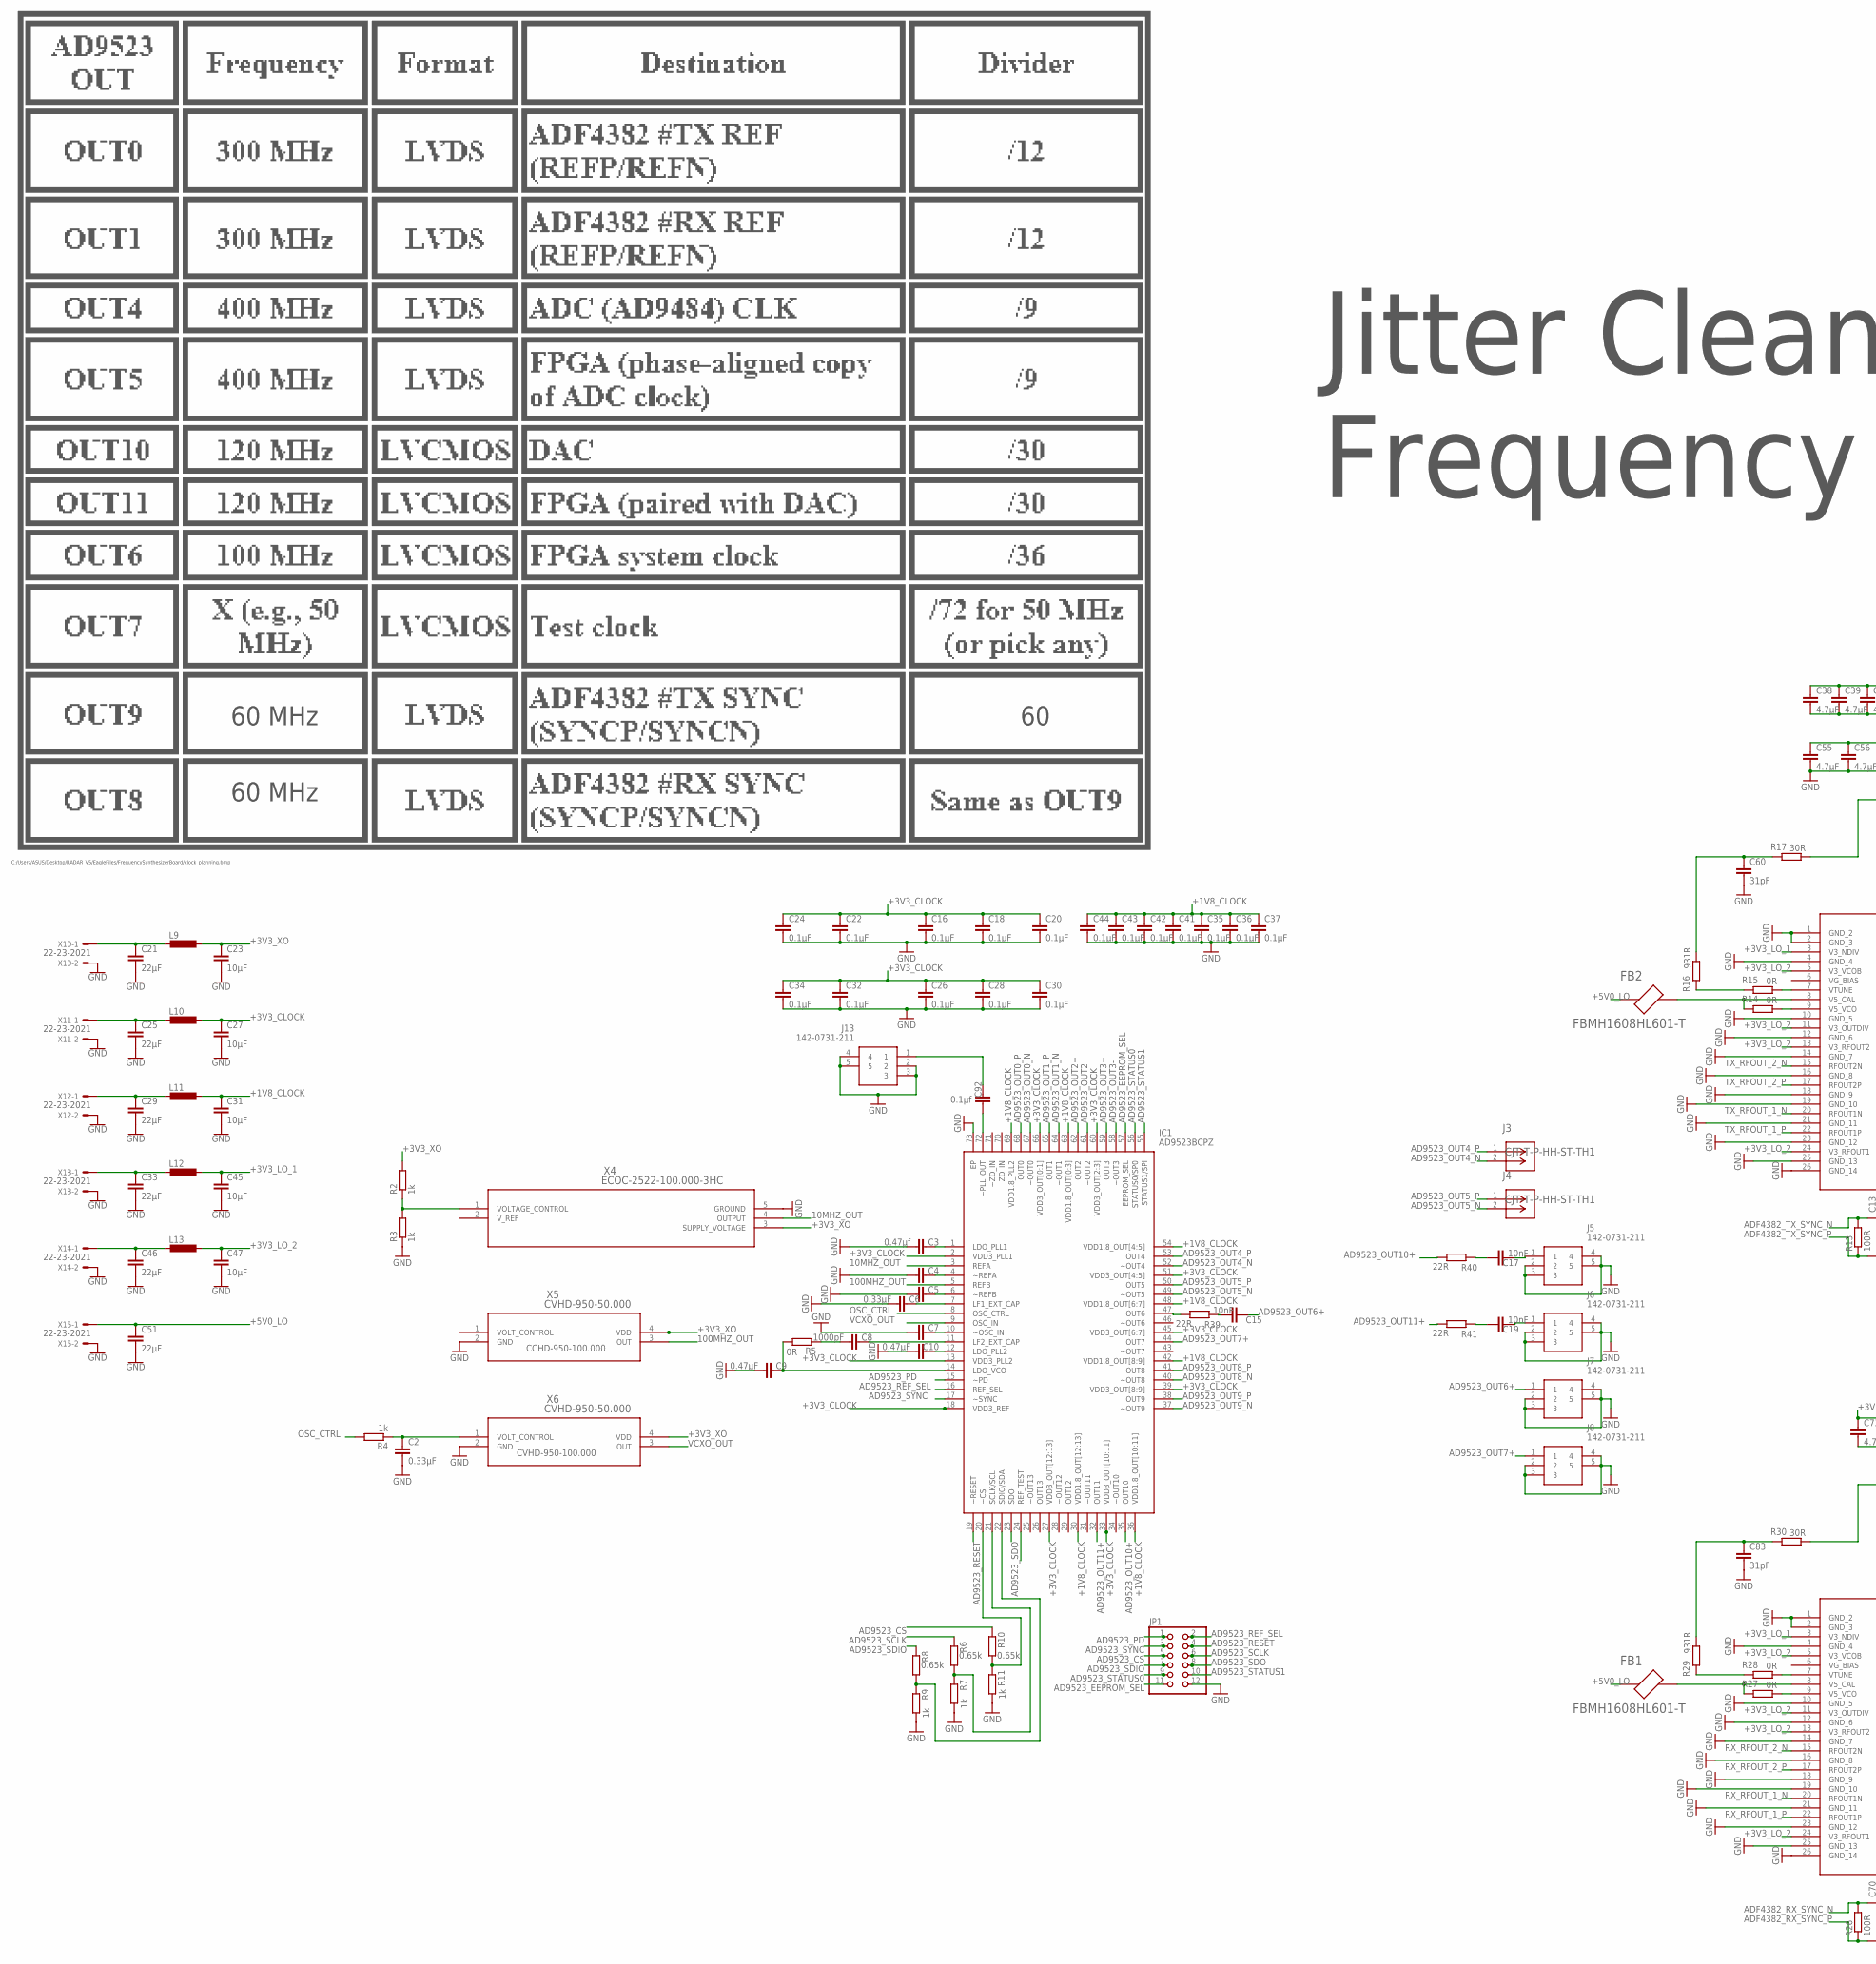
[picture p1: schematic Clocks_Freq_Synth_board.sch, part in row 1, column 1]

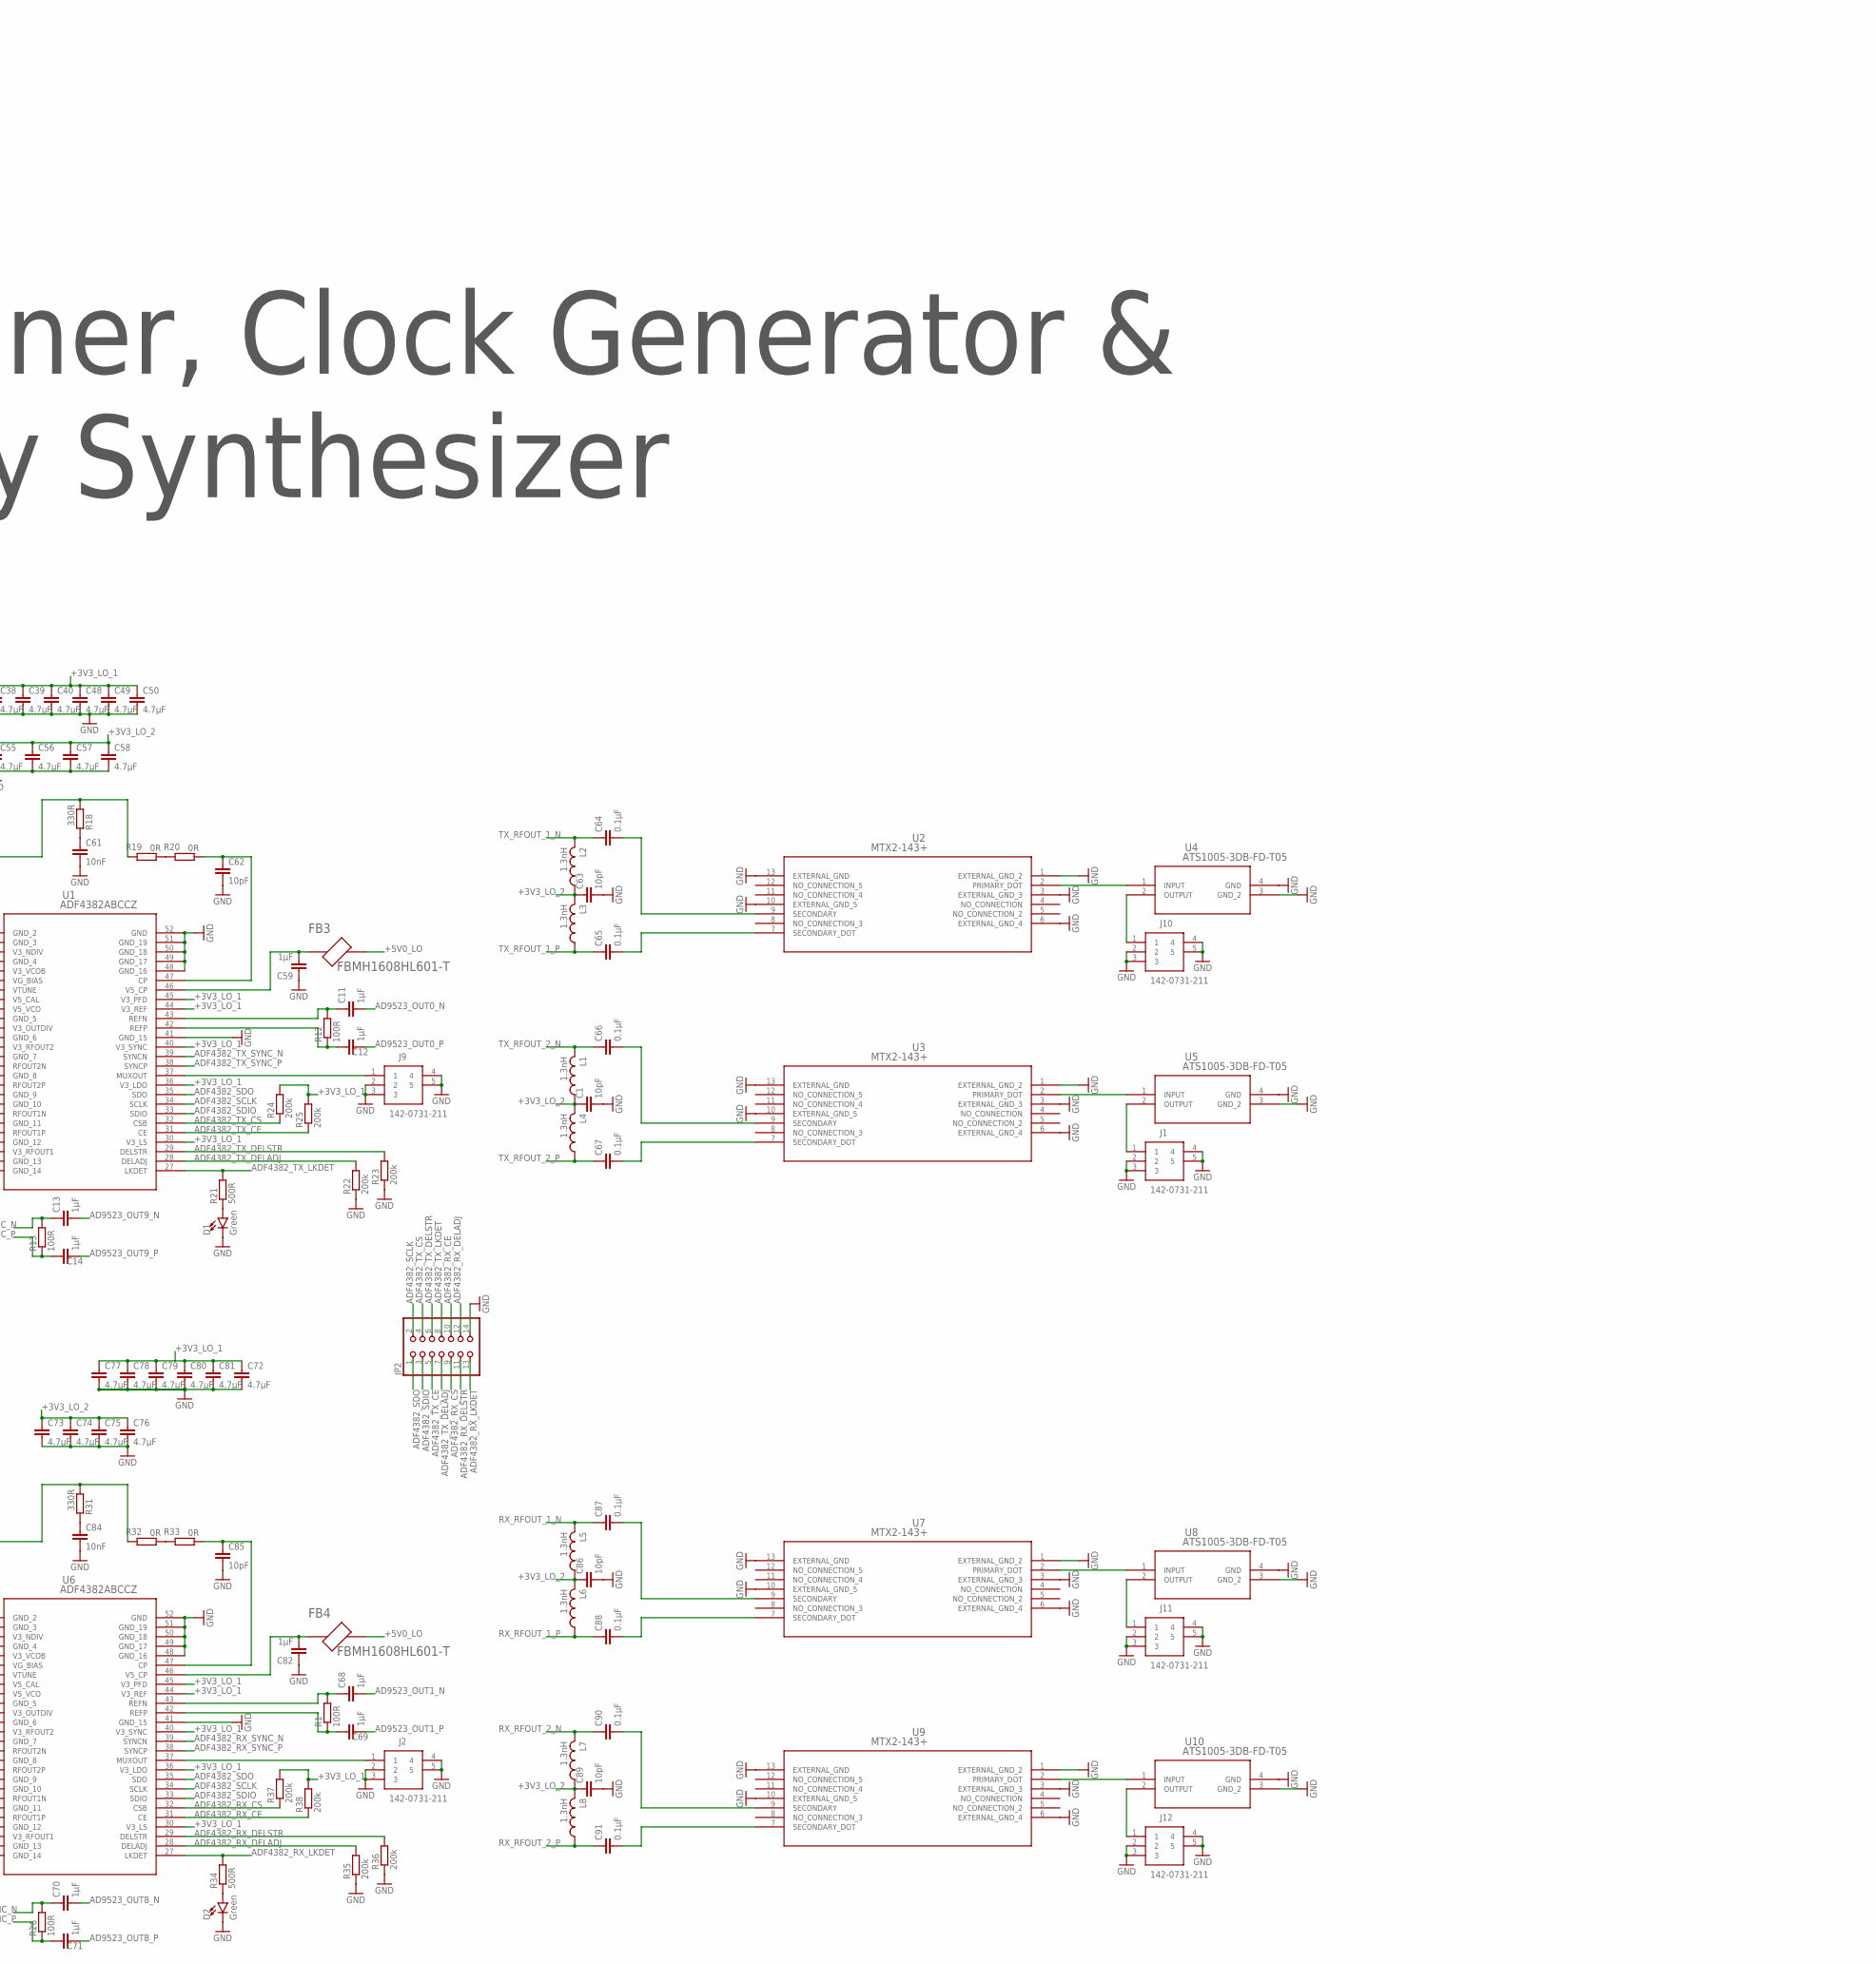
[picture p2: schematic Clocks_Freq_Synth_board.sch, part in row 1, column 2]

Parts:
C1, C62, C63, C85, C86, C89: 10pF; C0201
C2, C6: 0.33µF; C0201
C3: 0.47µf; C0201
C4, C5, C7: C-EUC0201; C0201
C8: 1000pF; C0201
C9, C10: 0.47µF; C0201
C11, C12, C13, C14, C59, C68, C69, C70, C71, C82: 1µF; C0201
C15, C17, C19: 10nF; C0402
C16, C18, C20, C22, C24, C26, C28, C30, C32, C34, C35, C36, C37, C41, C42, C43, C44, C64, C65, C66, C67, C87, C88, C90, C91: 0.1µF; C0201
C21, C25, C29, C33, C46, C51: 22µF; C1210
C23, C27, C31, C45, C47: 10µF; C1210
C38, C39, C40, C48, C49, C50, C55, C56, C57, C58, C72, C73, C74, C75, C76, C77, C78, C79, C80, C81: 4.7µF; C0201
C60, C83: 31pF; C0201
C61, C84: 10nF; C0201
C92: 0.1µf; C0201
D1, D2: Green; LED-0603
FB1, FB2, FB3, FB4: FBMH1608HL601-T; BEADC1608X90N
IC1: AD9523BCPZ; QFN50P1000X1000X100-73N
J1, J2, J5, J6, J7, J8, J9, J10, J11, J12, J13: 142-0731-211; 1420731211
J3, J4: CJT-T-P-HH-ST-TH1; CONN_CJT-T-P-XX-ST-TH1_SAI
JP1: PINHD-2X6; 2X06
JP2: PINHD-2X7; 2X07
L1, L2, L3, L4, L5, L6, L7, L8: 1.3nH; L0201
L9, L10, L11, L12, L13: L-EUL5650M; L5650M
R1, R12, R13, R26: 100R; R0201
R2, R3, R4, R7, R9, R11: 1k; R0201
R5, R14, R15, R19, R20, R27, R28, R32, R33: 0R; R0201
R6, R8, R10: 0.65k; R0201
R16, R29: 931R; R0201
R17, R30: 30R; R0201
R18, R31: 330R; R0201
R21, R34: 500R; R0201
R22, R23, R24, R25, R35, R36, R37, R38: 200k; R0201
R39, R40, R41: 22R; R0201
U1, U6: ADF4382ABCCZ; CC-48-10_ADI
U2, U3, U7, U9: MTX2-143+; DQ1225_MNC
U4, U5, U8, U10: ATS1005-3DB-FD-T05; SMT_DB-FD-T05_SUS
X4: ECOC-2522-100.000-3HC; SMD5_ECOC-2522_25P4X22_ECS
X5, X6: CVHD-950-50.000; SMD4_CVHD-950_CRX
X10, X11, X12, X13, X14, X15: 22-23-2021

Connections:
10MHZ_OUT: IC1.3 (REFA), X4.4 (OUTPUT)
100MHZ_OUT: IC1.5 (REFB), X5.3 (OUT)
+1V8_CLOCK: C31.1, C35.1, C36.1, C37.1, C41.1, C42.1, C43.1, C44.1, IC1.30 (VDD1.8_OUT[12:13]), IC1.36 (VDD1.8_OUT[10:11]), IC1.42 (VDD1.8_OUT[8:9]), IC1.48 (VDD1.8_OUT[6:7]), IC1.54 (VDD1.8_OUT[4:5]), IC1.63 (VDD1.8_OUT[0:3]), IC1.69 (VDD1.8_PLL2), L11.1
+3V3_CLOCK: C16.1, C18.1, C20.1, C22.1, C24.1, C26.1, C27.1, C28.1, C30.1, C32.1, C34.1, IC1.2 (VDD3_PLL1), IC1.13 (VDD3_PLL2), IC1.18 (VDD3_REF), IC1.27 (VDD3_OUT[12:13]), IC1.33 (VDD3_OUT[10:11]), IC1.39 (VDD3_OUT[8:9]), IC1.45 (VDD3_OUT[6:7]), IC1.51 (VDD3_OUT[4:5]), IC1.60 (VDD3_OUT[2:3]), IC1.66 (VDD3_OUT[0:1]), L10.1
+3V3_LO_1: C38.1, C39.1, C40.1, C45.1, C48.1, C49.1, C50.1, C72.1, C77.1, C78.1, C79.1, C80.1, C81.1, L12.1, R24.2, R25.2, R37.2, R38.2, U1.3 (V3_NDIV), U1.30 (V3_LS), U1.36 (V3_LDO), U1.40 (V3_SYNC), U1.44 (V3_REF), U1.45 (V3_PFD), U6.3 (V3_NDIV), U6.30 (V3_LS), U6.36 (V3_LDO), U6.40 (V3_SYNC), U6.44 (V3_REF), U6.45 (V3_PFD)
+3V3_LO_2: C1.1, C47.1, C55.1, C56.1, C57.1, C58.1, C63.1, C73.1, C74.1, C75.1, C76.1, C86.1, C89.1, L1.1, L2.1, L3.2, L4.2, L5.1, L6.2, L7.1, L8.2, L13.1, U1.5 (V3_VCOB), U1.11 (V3_OUTDIV), U1.13 (V3_RFOUT2), U1.24 (V3_RFOUT1), U6.5 (V3_VCOB), U6.11 (V3_OUTDIV), U6.13 (V3_RFOUT2), U6.24 (V3_RFOUT1)
+3V3_XO: C23.1, L9.1, R2.2, X4.3 (SUPPLY_VOLTAGE), X5.4 (VDD), X6.4 (VDD)
+5V0_LO: C51.1, FB1.1, FB2.1, FB3.2, FB4.2, X15.1
AD9523_CS: JP1.5, R10.1
AD9523_EEPROM_SEL: IC1.57 (EEPROM_SEL), JP1.11
AD9523_OUT0_N: C11.2, IC1.67 (~OUT0)
AD9523_OUT0_P: C12.2, IC1.68 (OUT0)
AD9523_OUT1_N: C68.2, IC1.64 (~OUT1)
AD9523_OUT1_P: C69.2, IC1.65 (OUT1)
AD9523_OUT2+: IC1.62 (OUT2)
AD9523_OUT2-: IC1.61 (~OUT2)
AD9523_OUT3+: IC1.59 (OUT3)
AD9523_OUT3-: IC1.58 (~OUT3)
AD9523_OUT4_N: IC1.52 (~OUT4), J3.2
AD9523_OUT4_P: IC1.53 (OUT4), J3.1
AD9523_OUT5_N: IC1.49 (~OUT5), J4.2
AD9523_OUT5_P: IC1.50 (OUT5), J4.1
AD9523_OUT6+: C15.2, J7.1
AD9523_OUT6_DRV: IC1.47 (OUT6), R39.1
AD9523_OUT6_SER: C15.1, R39.2
AD9523_OUT7+: IC1.44 (OUT7), J8.1
AD9523_OUT8_N: C70.2, IC1.40 (~OUT8)
AD9523_OUT8_P: C71.2, IC1.41 (OUT8)
AD9523_OUT9_N: C13.2, IC1.37 (~OUT9)
AD9523_OUT9_P: C14.2, IC1.38 (OUT9)
AD9523_OUT10+: IC1.35 (OUT10), R40.1
AD9523_OUT10_SER: C17.1, R40.2
AD9523_OUT11+: IC1.32 (OUT11), R41.1
AD9523_OUT11_SER: C19.1, R41.2
AD9523_PD: IC1.15 (~PD), JP1.1
AD9523_REF_SEL: IC1.16 (REF_SEL), JP1.2
AD9523_RESET: IC1.19 (~RESET), JP1.4
AD9523_SCLK: JP1.6, R6.1
AD9523_SDIO: JP1.7, R8.1
AD9523_SDO: IC1.23 (SDO), JP1.8
AD9523_STATUS0: IC1.56 (STATUS0/SP0), JP1.9
AD9523_STATUS1: IC1.55 (STATUS1/SPI), JP1.10
AD9523_SYNC: IC1.17 (~SYNC), JP1.3
ADF4382_RX_CE: JP2.10, R38.1, U6.31 (CE)
ADF4382_RX_CS: JP2.9, R37.1, U6.32 (CSB)
ADF4382_RX_DELADJ: JP2.12, R35.2, U6.28 (DELADJ)
ADF4382_RX_DELSTR: JP2.11, R36.2, U6.29 (DELSTR)
ADF4382_RX_LKDET: JP2.13, R34.2, U6.27 (LKDET)
ADF4382_RX_SYNC_N: C70.1, R26.2, U6.39 (SYNCN)
ADF4382_RX_SYNC_P: C71.1, R26.1, U6.38 (SYNCP)
ADF4382_SCLK: JP2.2, U1.34 (SCLK), U6.34 (SCLK)
ADF4382_SDIO: JP2.3, U1.33 (SDIO), U6.33 (SDIO)
ADF4382_SDO: JP2.1, U1.35 (SDO), U6.35 (SDO)
ADF4382_TX_CE: JP2.5, R25.1, U1.31 (CE)
ADF4382_TX_CS: JP2.4, R24.1, U1.32 (CSB)
ADF4382_TX_DELADJ: JP2.7, R22.2, U1.28 (DELADJ)
ADF4382_TX_DELSTR: JP2.6, R23.2, U1.29 (DELSTR)
ADF4382_TX_LKDET: JP2.8, R21.2, U1.27 (LKDET)
ADF4382_TX_SYNC_N: C13.1, R13.2, U1.39 (SYNCN)
ADF4382_TX_SYNC_P: C14.1, R13.1, U1.38 (SYNCP)
GND: C1.2, C2.2, C3.1, C4.1, C5.1, C6.1, C7.1, C9.1, C10.1, C16.2, C18.2, C20.2, C21.2, C22.2, C23.2, C24.2, C25.2, C26.2, C27.2, C28.2, C29.2, C30.2, C31.2, C32.2, C33.2, C34.2, C35.2, C36.2, C37.2, C38.2, C39.2, C40.2, C41.2, C42.2, C43.2, C44.2, C45.2, C46.2, C47.2, C48.2, C49.2, C50.2, C51.2, C55.2, C56.2, C57.2, C58.2, C59.1, C60.2, C61.2, C62.2, C63.2, C72.2, C73.2, C74.2, C75.2, C76.2, C77.2, C78.2, C79.2, C80.2, C81.2, C82.1, C83.2, C84.2, C85.2, C86.2, C89.2, D1.C, D2.C, IC1.73 (EP), J1.2, J1.3, J1.4, J1.5, J2.2, J2.3, J2.4, J2.5, J5.2, J5.3, J5.4, J5.5, J6.2, J6.3, J6.4, J6.5, J7.2, J7.3, J7.4, J7.5, J8.2, J8.3, J8.4, J8.5, J9.2, J9.3, J9.4, J9.5, J10.2, J10.3, J10.4, J10.5, J11.2, J11.3, J11.4, J11.5, J12.2, J12.3, J12.4, J12.5, J13.2, J13.3, J13.4, J13.5, JP1.12, JP2.14, R3.1, R7.2, R9.2, R11.2, R22.1, R23.1, R35.1, R36.1, U1.1 (GND_2), U1.2 (GND_3), U1.4 (GND_4), U1.10 (GND_5), U1.12 (GND_6), U1.14 (GND_7), U1.16 (GND_8), U1.18 (GND_9), U1.19 (GND_10), U1.21 (GND_11), U1.23 (GND_12), U1.25 (GND_13), U1.26 (GND_14), U1.41 (GND_15), U1.48 (GND_16), U1.49 (GND_17), U1.50 (GND_18), U1.51 (GND_19), U1.52 (GND), U2.1 (EXTERNAL_GND_2), U2.3 (EXTERNAL_GND_3), U2.6 (EXTERNAL_GND_4), U2.10 (EXTERNAL_GND_5), U2.13 (EXTERNAL_GND), U3.1 (EXTERNAL_GND_2), U3.3 (EXTERNAL_GND_3), U3.6 (EXTERNAL_GND_4), U3.10 (EXTERNAL_GND_5), U3.13 (EXTERNAL_GND), U4.3 (GND_2), U4.4 (GND), U5.3 (GND_2), U5.4 (GND), U6.1 (GND_2), U6.2 (GND_3), U6.4 (GND_4), U6.10 (GND_5), U6.12 (GND_6), U6.14 (GND_7), U6.16 (GND_8), U6.18 (GND_9), U6.19 (GND_10), U6.21 (GND_11), U6.23 (GND_12), U6.25 (GND_13), U6.26 (GND_14), U6.41 (GND_15), U6.48 (GND_16), U6.49 (GND_17), U6.50 (GND_18), U6.51 (GND_19), U6.52 (GND), U7.1 (EXTERNAL_GND_2), U7.3 (EXTERNAL_GND_3), U7.6 (EXTERNAL_GND_4), U7.10 (EXTERNAL_GND_5), U7.13 (EXTERNAL_GND), U8.3 (GND_2), U8.4 (GND), U9.1 (EXTERNAL_GND_2), U9.3 (EXTERNAL_GND_3), U9.6 (EXTERNAL_GND_4), U9.10 (EXTERNAL_GND_5), U9.13 (EXTERNAL_GND), U10.3 (GND_2), U10.4 (GND), X4.5 (GROUND), X5.2 (GND), X6.2 (GND), X10.2, X11.2, X12.2, X13.2, X14.2, X15.2
unnamed: R2.1, R3.2, X4.1 (VOLTAGE_CONTROL)
unnamed: C2.1, R4.1, X6.1 (VOLT_CONTROL)
unnamed: C3.2, IC1.1 (LDO_PLL1)
unnamed: C6.2, IC1.7 (LF1_EXT_CAP)
unnamed: C4.2, IC1.4 (~REFA)
unnamed: C5.2, IC1.6 (~REFB)
unnamed: C7.2, IC1.10 (~OSC_IN)
unnamed: C8.2, IC1.11 (LF2_EXT_CAP)
unnamed: C8.1, R5.1
unnamed: C9.2, IC1.14 (LDO_VCO), R5.2
unnamed: C10.2, IC1.12 (LDO_PLL2)
unnamed: IC1.21 (SCLK/SCL), R6.2, R7.1
unnamed: IC1.22 (SDIO/SDA), R8.2, R9.1
unnamed: IC1.20 (~CS), R10.2, R11.1
unnamed: C11.1, R12.2, U1.43 (REFN)
unnamed: C12.1, R12.1, U1.42 (REFP)
unnamed: C61.1, R18.2
unnamed: R14.1, U1.9 (V5_VCO)
unnamed: FB2.2, R14.2, U1.8 (V5_CAL)
unnamed: C59.2, FB3.1, U1.46 (V5_CP)
unnamed: R19.1, R20.2
unnamed: R15.1, U1.7 (VTUNE)
unnamed: R15.2, R16.2
unnamed: C60.1, R16.1, R17.2
unnamed: R17.1, R18.1, R19.2
unnamed: C62.1, R20.1, U1.47 (CP)
unnamed: U2.2 (PRIMARY_DOT), U4.1 (INPUT)
unnamed: C65.2, U2.7 (SECONDARY_DOT)
unnamed: J10.1, U4.2 (OUTPUT)
unnamed: C64.2, U2.9 (SECONDARY)
unnamed: C67.2, U3.7 (SECONDARY_DOT)
unnamed: C66.2, U3.9 (SECONDARY)
unnamed: U3.2 (PRIMARY_DOT), U5.1 (INPUT)
unnamed: J1.1, U5.2 (OUTPUT)
unnamed: D1.A, R21.1
unnamed: J9.1, U1.37 (MUXOUT)
unnamed: C68.1, R1.2, U6.43 (REFN)
unnamed: C69.1, R1.1, U6.42 (REFP)
unnamed: R27.1, U6.9 (V5_VCO)
unnamed: FB1.2, R27.2, U6.8 (V5_CAL)
unnamed: C82.2, FB4.1, U6.46 (V5_CP)
unnamed: C84.1, R31.2
unnamed: R32.1, R33.2
unnamed: R28.1, U6.7 (VTUNE)
unnamed: R28.2, R29.2
unnamed: C83.1, R29.1, R30.2
unnamed: R30.1, R31.1, R32.2
unnamed: C85.1, R33.1, U6.47 (CP)
unnamed: D2.A, R34.1
unnamed: J2.1, U6.37 (MUXOUT)
unnamed: C88.2, U7.7 (SECONDARY_DOT)
unnamed: C87.2, U7.9 (SECONDARY)
unnamed: U7.2 (PRIMARY_DOT), U8.1 (INPUT)
unnamed: J11.1, U8.2 (OUTPUT)
unnamed: C91.2, U9.7 (SECONDARY_DOT)
unnamed: C90.2, U9.9 (SECONDARY)
unnamed: U9.2 (PRIMARY_DOT), U10.1 (INPUT)
unnamed: J12.1, U10.2 (OUTPUT)
unnamed: C92.1, IC1.72 (~PLL_OUT)
unnamed: C92.2, J13.1
unnamed: C17.2, J5.1
unnamed: C19.2, J6.1
unnamed: C21.1, L9.2, X10.1
unnamed: C25.1, L10.2, X11.1
unnamed: C29.1, L11.2, X12.1
unnamed: C33.1, L12.2, X13.1
unnamed: C46.1, L13.2, X14.1
OSC_CTRL: IC1.8 (OSC_CTRL), R4.2
RX_RFOUT_1_N: C87.1, L5.2, U6.20 (RFOUT1N)
RX_RFOUT_1_P: C88.1, L6.1, U6.22 (RFOUT1P)
RX_RFOUT_2_N: C90.1, L7.2, U6.15 (RFOUT2N)
RX_RFOUT_2_P: C91.1, L8.1, U6.17 (RFOUT2P)
TX_RFOUT_1_N: C64.1, L2.2, U1.20 (RFOUT1N)
TX_RFOUT_1_P: C65.1, L3.1, U1.22 (RFOUT1P)
TX_RFOUT_2_N: C66.1, L1.2, U1.15 (RFOUT2N)
TX_RFOUT_2_P: C67.1, L4.1, U1.17 (RFOUT2P)
VCXO_OUT: IC1.9 (OSC_IN), X6.3 (OUT)

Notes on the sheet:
CCHD-950-100.000
CVHD-950-100.000
Jitter Cleaner, Clock Generator & Frequency Synthesizer
C:/Users/ASUS/Desktop/RADAR_V5/EagleFiles/FrequencySynthesizerBoard/clock_planning.bmp
60 MHz

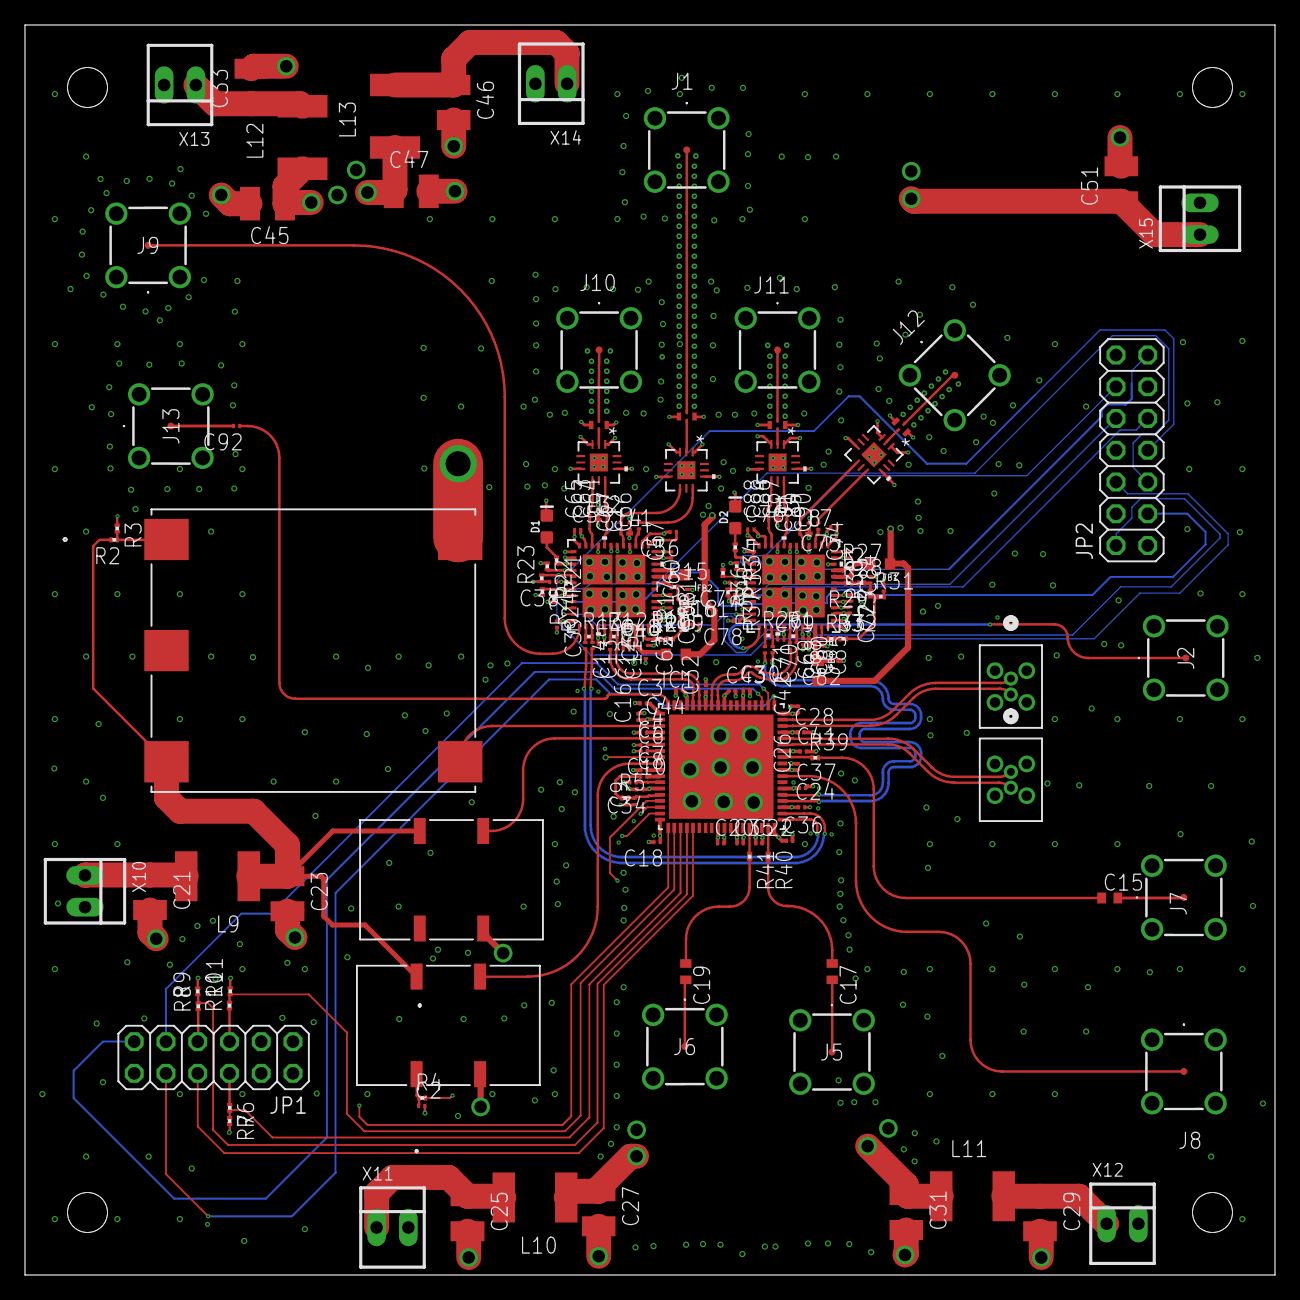
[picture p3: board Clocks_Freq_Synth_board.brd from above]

Board: 6 copper layers, 100.0 x 100.0 mm, 184 parts (0 on the bottom side), 134 nets.

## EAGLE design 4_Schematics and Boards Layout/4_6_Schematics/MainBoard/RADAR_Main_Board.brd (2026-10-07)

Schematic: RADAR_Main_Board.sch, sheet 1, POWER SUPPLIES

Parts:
C75, C77, C312, C316, C319, C323, C326, C330, C333, C336, C338, C340: 10µF; C0805
C76, C78, C258, C259, C260, C262, C264, C266, C313, C317, C320, C324, C327, C331, C334, C337, C339, C341, C342, C343, C344, C345, C346, C347, C348, C349, C350, C351: 100nF; C0402
C283, C311, C315, C322, C329: 22µF; C1206
C314, C318, C321, C325, C328, C332, C335: 1nF; C0402
J56, J57, J58, J59: 142-0731-211; 1420731211
L1, L11, L12, L13, L14, L15, L16, L17, L18, L21, L23: L-EUL5650M; L5650M
R174, R175: 0R; R0201
X1, X4, X8, X9, X10, X12, X16, X17, X18, X20, X21, X24, X54, X55, X56: 22-23-2021

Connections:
+1V0_FPGA: X8.1; also elsewhere on the board
+1V8_CLOCK: C311.1, L1.1, X17.1
+1V8_FPGA: X10.1; also elsewhere on the board
+3V3: X24.1; also elsewhere on the board
+3V3_ADAR1_F: C316.1, C317.1, C318.1, L11.2; also elsewhere on the board
+3V3_ADAR2_F: C319.1, C320.1, C321.1, L12.2; also elsewhere on the board
+3V3_ADAR3_F: C323.1, C324.1, C325.1, L13.2; also elsewhere on the board
+3V3_ADAR4_F: C326.1, C327.1, C328.1, L14.2; also elsewhere on the board
+3V3_ADAR12: C315.1, L11.1, L12.1, X20.1
+3V3_ADAR34: C322.1, L13.1, L14.1, X21.1
+3V3_ADTR: X4.1; also elsewhere on the board
+3V3_AN: C283.1, C329.1, L15.1, L16.1, L17.1, L18.1, L21.1, L23.1, X9.1, X56.1; also elsewhere on the board
+3V3_AN1_F: C330.1, C331.1, C332.1, L15.2; also elsewhere on the board
+3V3_AN2_F: C333.1, C334.1, C335.1, L16.2; also elsewhere on the board
+3V3_AN3_F: C75.1, C76.1, C336.1, C337.1, L17.2; also elsewhere on the board
+3V3_AN4_F: C77.1, C78.1, C338.1, C339.1, C340.1, C341.1, L18.2; also elsewhere on the board
+3V3_AN5_F: C258.1, C259.1, C260.1, C262.1, C342.1, C343.1, C344.1, C345.1, L21.2; also elsewhere on the board
+3V3_AN6_F: C264.1, C266.1, C346.1, C347.1, C348.1, C349.1, C350.1, C351.1, L23.2; also elsewhere on the board
+3V3_FPGA: X16.1; also elsewhere on the board
+3V3_VDD_SW: X12.1; also elsewhere on the board
+3V4: X1.1, X54.1; also elsewhere on the board
+5V0_0: X18.1; also elsewhere on the board
+5V5_PA: X55.1; also elsewhere on the board

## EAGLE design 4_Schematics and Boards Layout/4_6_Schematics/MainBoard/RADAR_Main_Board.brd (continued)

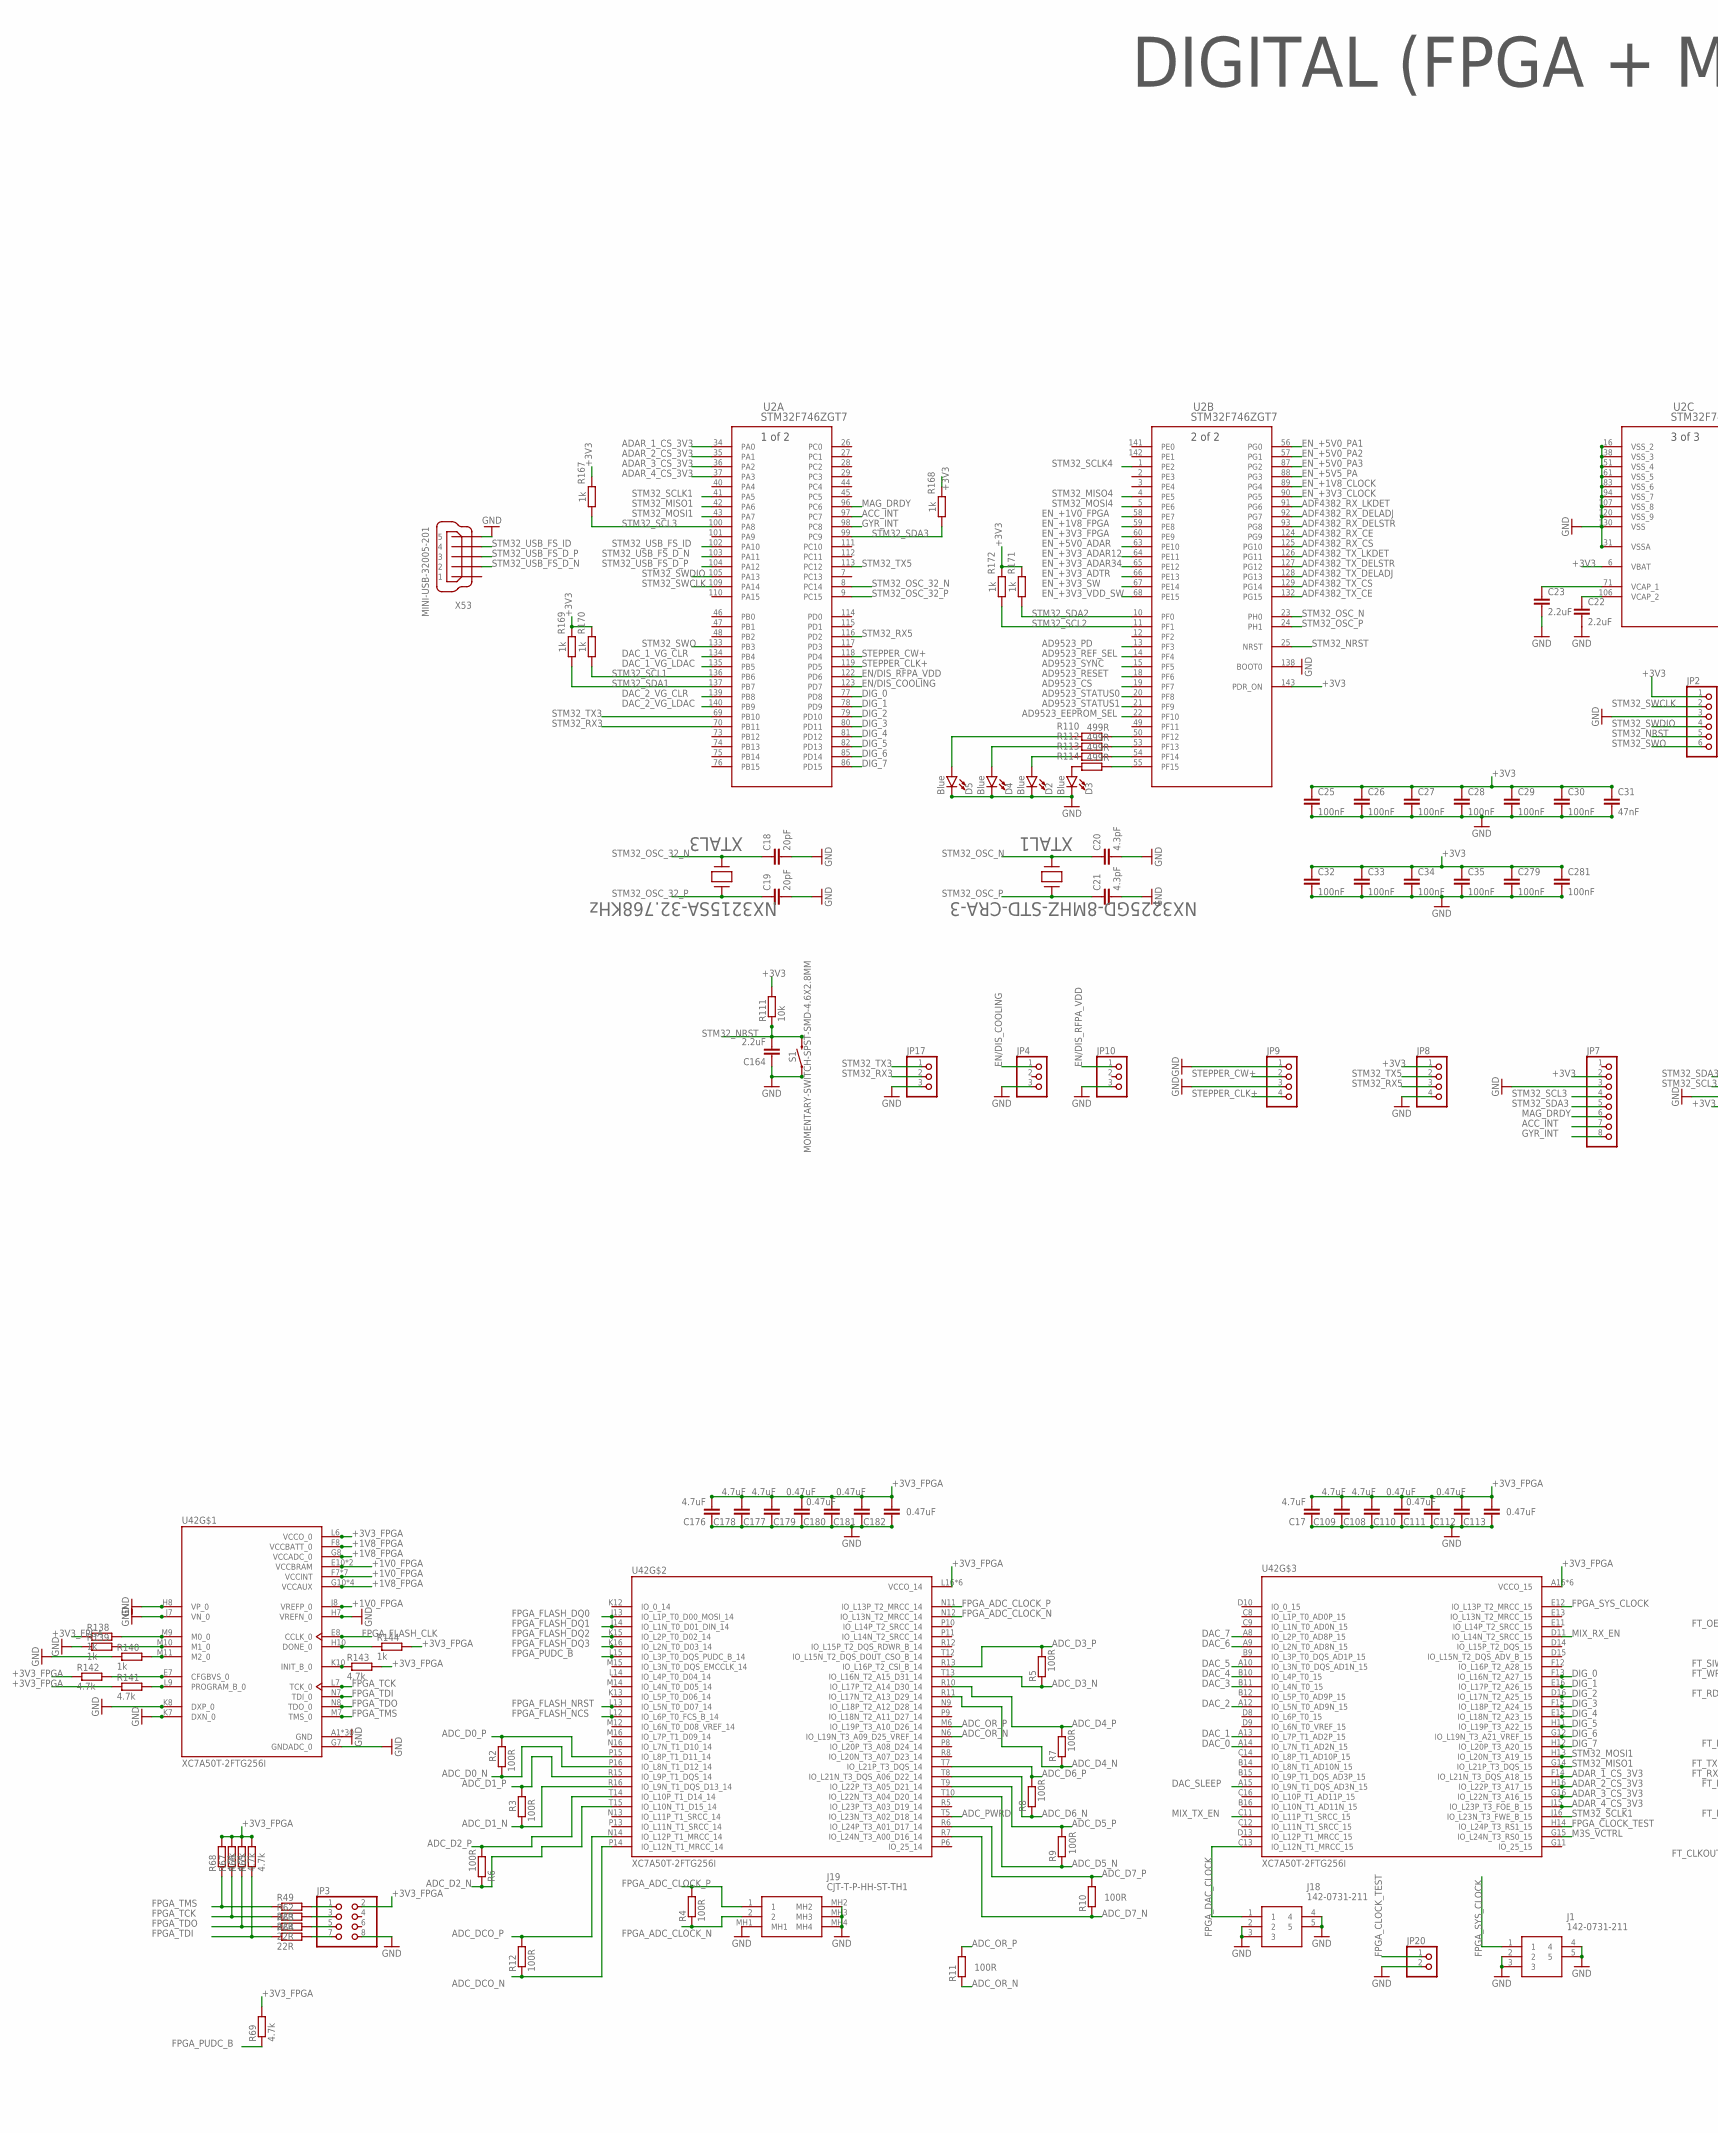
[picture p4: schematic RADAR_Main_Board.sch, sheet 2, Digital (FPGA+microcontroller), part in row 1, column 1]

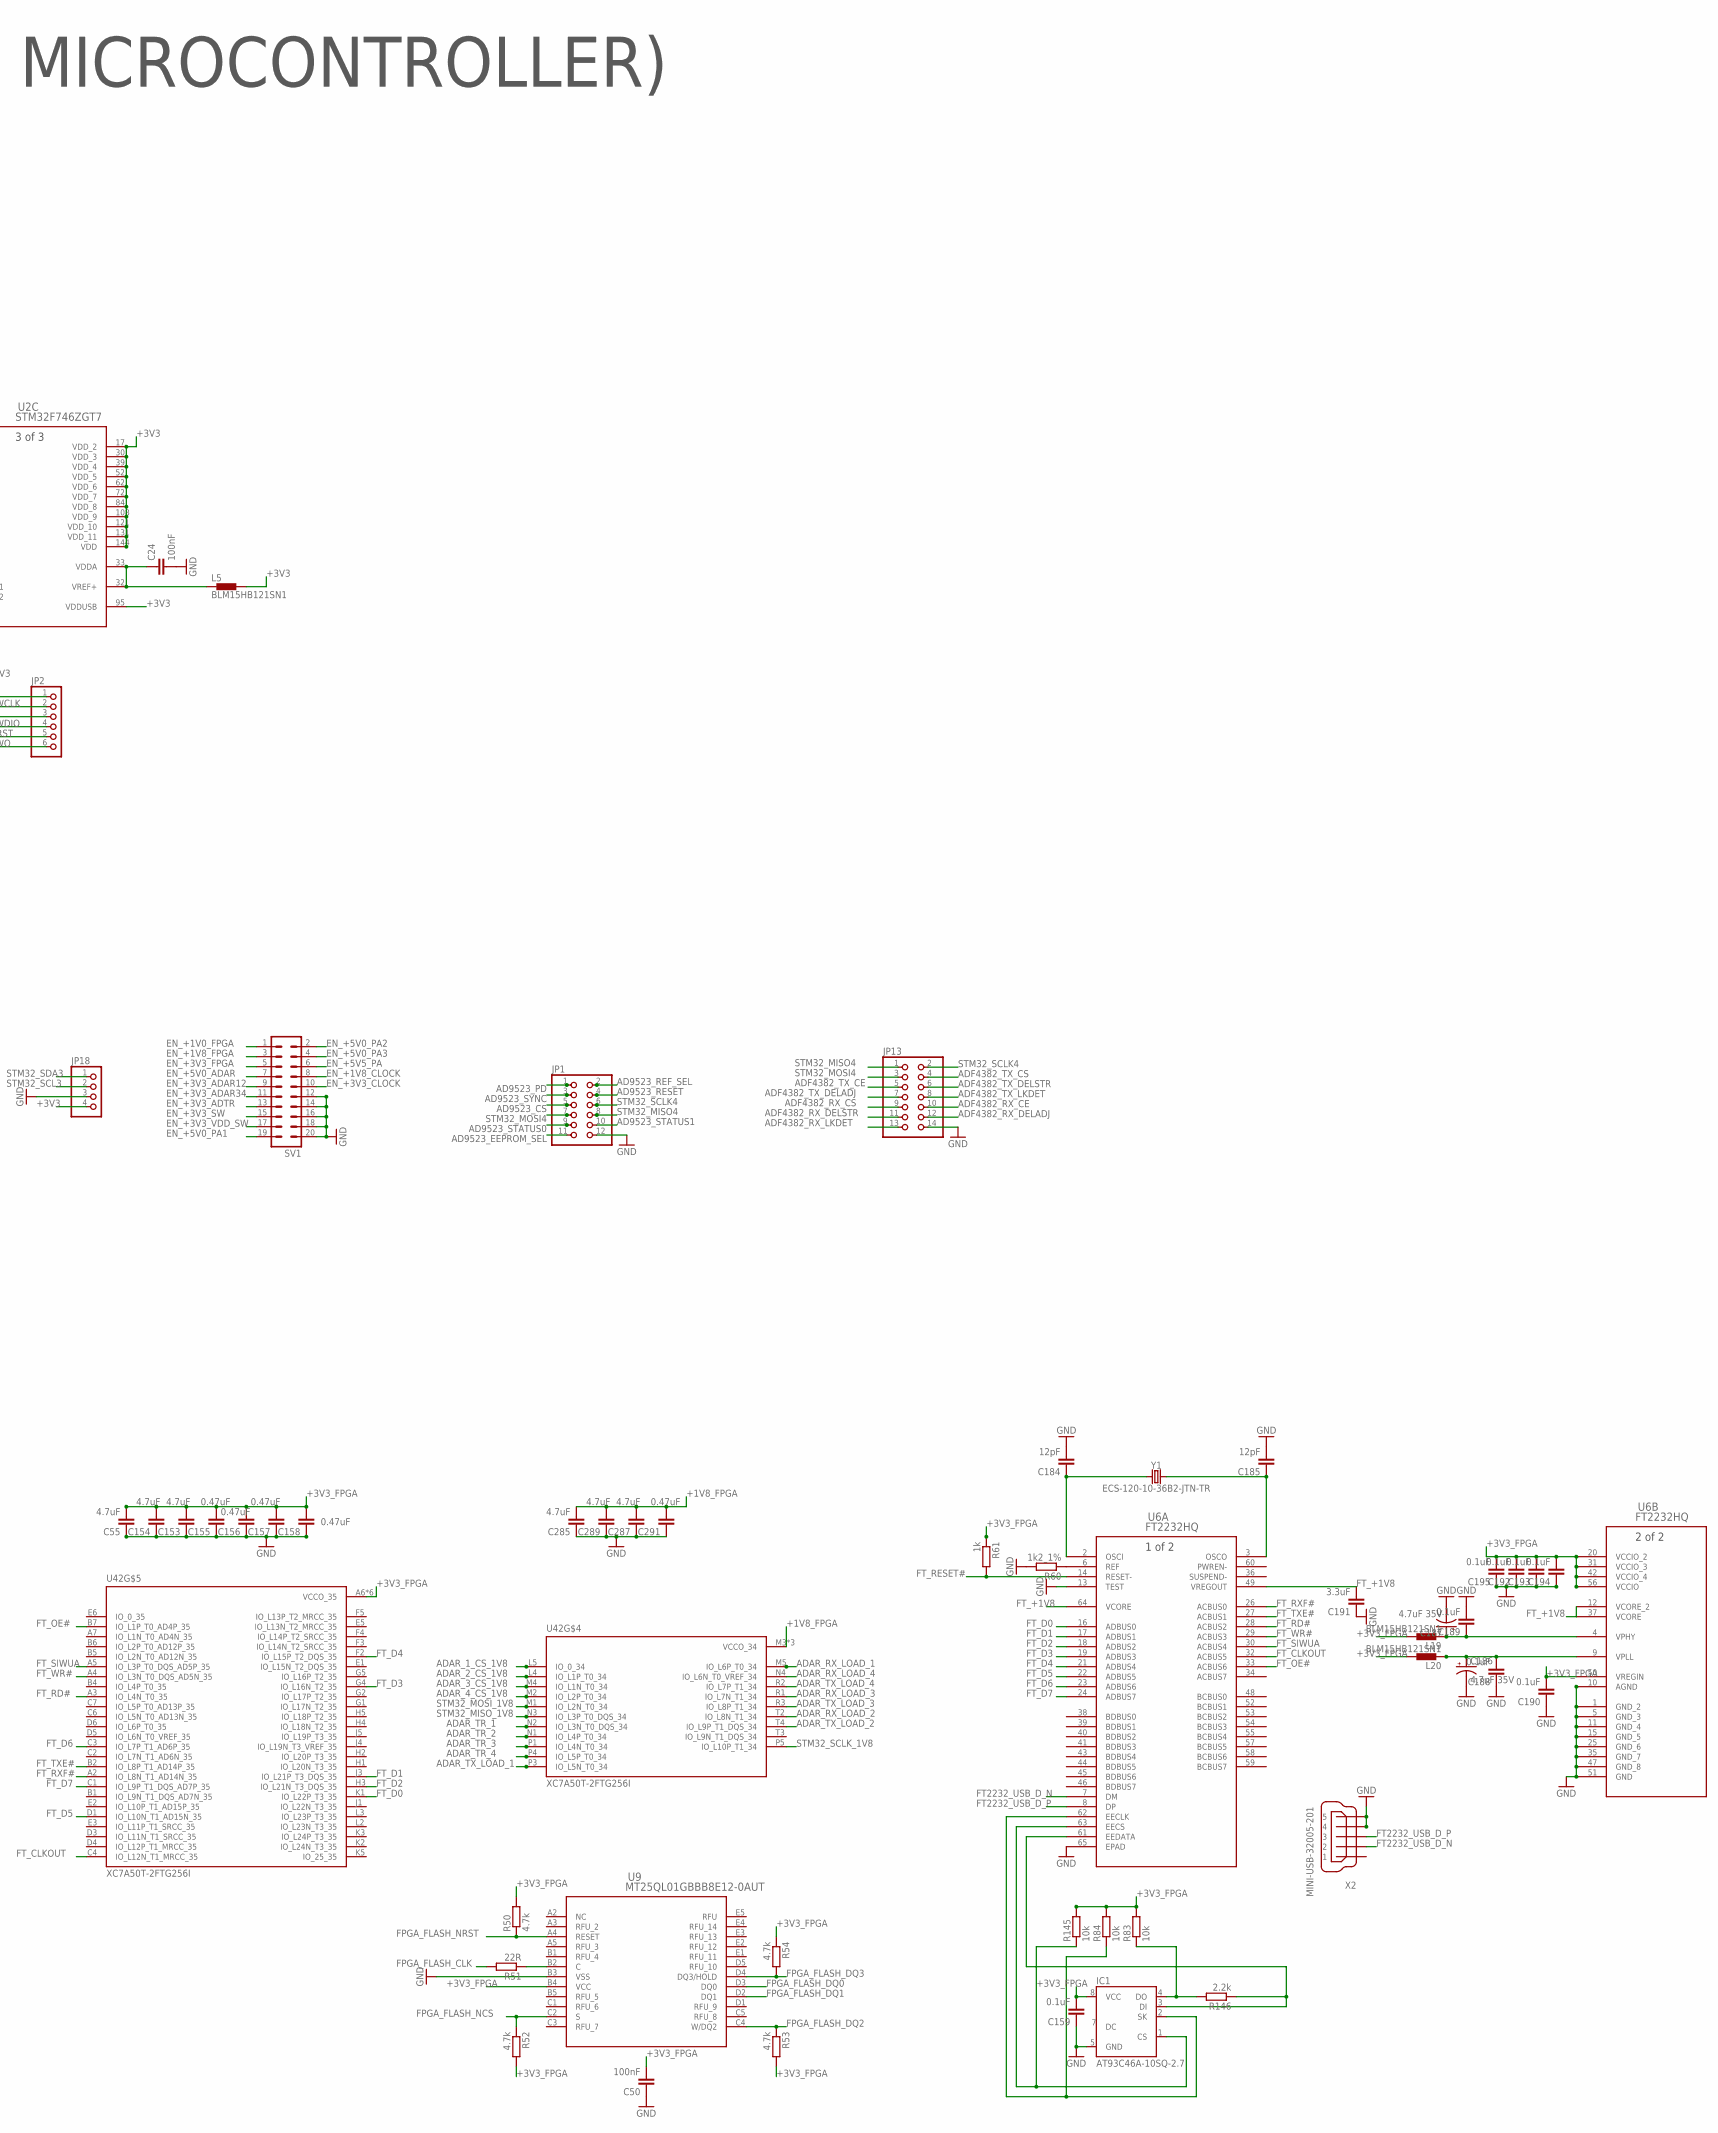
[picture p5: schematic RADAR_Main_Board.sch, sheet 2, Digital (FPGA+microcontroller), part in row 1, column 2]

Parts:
C17, C55, C108, C109, C153, C154, C176, C177, C178, C285, C287, C289: 4.7uF; C0201
C18, C19: 20pF; C0201
C20, C21: 4.3pF; C0201
C22, C23, C164: 2.2uF; C0201
C24, C25, C26, C27, C28, C29, C30, C32, C33, C34, C35, C50, C279, C281: 100nF; C0201
C31: 47nF; C0201
C110, C111, C112, C113, C155, C156, C157, C158, C179, C180, C181, C182, C291: 0.47uF; C0201
C159, C188, C189, C190, C192, C193, C194, C195: 0.1uF; C0201
C184, C185: 12pF; C0201
C186, C187: 4.7uF 35V; EIA3528
C191: 3.3uF; C0201
D2, D3, D4, D5: Blue; LED-0603
IC1: AT93C46A-10SQ-2.7; SOIC8
J1, J18: 142-0731-211; 1420731211
J19: CJT-T-P-HH-ST-TH1; CJTTPHHSTTH1
JP1: PINHD-2X6; 2X06
JP2: PINHD-1X6; 1X06
JP3: PINHD-2X4; 2X04
JP4, JP10, JP17: PINHD-1X3; 1X03
JP7: PINHD-1X8; 1X08
JP8, JP9, JP18: PINHD-1X4; 1X04
JP13: PINHD-2X7; 2X07
JP20: PINHD-1X2; 1X02
L5, L19, L20: BLM15HB121SN1; 0402
R2, R3, R4, R5, R6, R7, R8, R9, R10, R11, R12: 100R; R0201
R49, R51, R62, R63, R64: 22R; R0201
R50, R52, R53, R54, R65, R66, R67, R68, R69, R141, R142, R143: 4.7k; R0201
R60: 1k2_1%; R0201
R61, R138, R139, R140, R144, R167, R168, R169, R170, R171, R172: 1k; R0201
R83, R84, R111, R145: 10k; R0201
R110, R112, R113, R114: 499R; R0201
R146: 2.2k; R0201
S1: MOMENTARY-SWITCH-SPST-SMD-4.6X2.8MM; TACTILE_SWITCH_SMD_4.6X2.8MM
SV1: MA10-2
U2: STM32F746ZGT7; LQFP-144_STM
U6: FT2232HQ; 64QFN_FT2232HQ_FTD
U9: MT25QL01GBBB8E12-0AUT; BGA24_MT25QL_MRN
U42: XC7A50T-2FTG256I; BGA256C100P16X16_1700X1700X155
X2, X53: MINI-USB-32005-201; 32005-201
XTAL1: NX3225GD-8MHZ-STD-CRA-3; XTAL_NX3225GD-8MHZ-STD-CRA-3_N
XTAL3: NX3215SA-32.768KHz; XTAL_NX3225GD-8MHZ-STD-CRA-3_N
Y1: ECS-120-10-36B2-JTN-TR; CRYSTAL-SMD-2X2.5MM

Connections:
+1V0_FPGA: U42.E10 (VCCBRAM), U42.F7 (VCCINT), U42.F9 (VCCINT), U42.F11 (VCCBRAM), U42.G6 (VCCINT), U42.H9 (VCCINT), U42.J6 (VCCINT), U42.J8 (VREFP_0), U42.K9 (VCCINT), U42.L8 (VCCINT); also elsewhere on the board
+1V8_FPGA: C285.2, C287.2, C289.2, C291.2, U42.F8 (VCCBATT_0), U42.G8 (VCCADC_0), U42.G10 (VCCAUX), U42.J10 (VCCAUX), U42.K11 (VCCAUX), U42.L10 (VCCAUX), U42.M3 (VCCO_34), U42.R4 (VCCO_34), U42.T1 (VCCO_34); also elsewhere on the board
+3V3: C25.1, C26.1, C27.1, C28.1, C29.1, C30.1, C31.1, C32.1, C33.1, C34.1, C35.1, C279.1, C281.1, JP2.1, JP7.2, JP8.1, JP18.4, L5.2, R111.2, R167.1, R168.1, R169.1, R170.1, R171.1, R172.1, U2.6 (VBAT), U2.17 (VDD_2), U2.30 (VDD_3), U2.39 (VDD_4), U2.52 (VDD_5), U2.62 (VDD_6), U2.72 (VDD_7), U2.84 (VDD_8), U2.95 (VDDUSB), U2.108 (VDD_9), U2.121 (VDD_10), U2.131 (VDD_11), U2.143 (PDR_ON), U2.144 (VDD); also elsewhere on the board
+3V3_FPGA: C17.2, C50.2, C55.2, C108.2, C109.2, C110.2, C111.2, C112.2, C113.2, C153.2, C154.2, C155.2, C156.2, C157.2, C158.2, C159.2, C176.2, C177.2, C178.2, C179.2, C180.2, C181.2, C182.2, C190.2, C192.2, C193.2, C194.2, C195.2, IC1.8 (VCC), JP3.2, L19.2, L20.2, R50.2, R52.2, R53.2, R54.1, R61.1, R65.2, R66.2, R67.2, R68.2, R69.2, R83.2, R84.2, R138.1, R141.1, R142.1, R143.2, R144.2, R145.2, U6.20 (VCCIO_2), U6.31 (VCCIO_3), U6.42 (VCCIO_4), U6.50 (VREGIN), U6.56 (VCCIO), U9.B4 (VCC), U42.A6 (VCCO_35), U42.A16 (VCCO_15), U42.B3 (VCCO_35), U42.B13 (VCCO_15), U42.C10 (VCCO_15), U42.D7 (VCCO_35), U42.E4 (VCCO_35), U42.E14 (VCCO_15), U42.F1 (VCCO_35), U42.H15 (VCCO_15), U42.J2 (VCCO_35), U42.J12 (VCCO_15), U42.L6 (VCCO_0); also elsewhere on the board
ACC_INT: JP7.7, U2.97 (PC7)
AD9523_CS: JP1.5, U2.19 (PF7)
AD9523_EEPROM_SEL: JP1.11, U2.22 (PF10)
AD9523_PD: JP1.1, U2.13 (PF3)
AD9523_REF_SEL: JP1.2, U2.14 (PF4)
AD9523_RESET: JP1.4, U2.18 (PF6)
AD9523_STATUS0: JP1.9, U2.20 (PF8)
AD9523_STATUS1: JP1.10, U2.21 (PF9)
AD9523_SYNC: JP1.3, U2.15 (PF5)
ADAR_1_CS_1V8: U42.L5 (IO_0_34); also elsewhere on the board
ADAR_1_CS_3V3: U2.34 (PA0), U42.F14 (IO_L21N_T3_DQS_A18_15)
ADAR_2_CS_1V8: U42.L4 (IO_L1P_T0_34); also elsewhere on the board
ADAR_2_CS_3V3: U2.35 (PA1), U42.H16 (IO_L22P_T3_A17_15)
ADAR_3_CS_1V8: U42.M4 (IO_L1N_T0_34); also elsewhere on the board
ADAR_3_CS_3V3: U2.36 (PA2), U42.G16 (IO_L22N_T3_A16_15)
ADAR_4_CS_1V8: U42.M2 (IO_L2P_T0_34); also elsewhere on the board
ADAR_4_CS_3V3: U2.37 (PA3), U42.J15 (IO_L23P_T3_FOE_B_15)
ADAR_RX_LOAD_1: U42.M5 (IO_L6P_T0_34); also elsewhere on the board
ADAR_RX_LOAD_2: U42.T2 (IO_L8N_T1_34); also elsewhere on the board
ADAR_RX_LOAD_3: U42.R1 (IO_L7N_T1_34); also elsewhere on the board
ADAR_RX_LOAD_4: U42.N4 (IO_L6N_T0_VREF_34); also elsewhere on the board
ADAR_TR_1: U42.N2 (IO_L3N_T0_DQS_34); also elsewhere on the board
ADAR_TR_2: U42.N1 (IO_L4P_T0_34); also elsewhere on the board
ADAR_TR_3: U42.P1 (IO_L4N_T0_34); also elsewhere on the board
ADAR_TR_4: U42.P4 (IO_L5P_T0_34); also elsewhere on the board
ADAR_TX_LOAD_1: U42.P3 (IO_L5N_T0_34); also elsewhere on the board
ADAR_TX_LOAD_2: U42.T4 (IO_L9P_T1_DQS_34); also elsewhere on the board
ADAR_TX_LOAD_3: U42.R3 (IO_L8P_T1_34); also elsewhere on the board
ADAR_TX_LOAD_4: U42.R2 (IO_L7P_T1_34); also elsewhere on the board
ADC_D0_N: R2.1, U42.P16 (IO_L8N_T1_D12_14); also elsewhere on the board
ADC_D0_P: R2.2, U42.P15 (IO_L8P_T1_D11_14); also elsewhere on the board
ADC_D1_N: R3.1, U42.R16 (IO_L9N_T1_DQS_D13_14); also elsewhere on the board
ADC_D1_P: R3.2, U42.R15 (IO_L9P_T1_DQS_14); also elsewhere on the board
ADC_D2_N: R6.1, U42.T15 (IO_L10N_T1_D15_14); also elsewhere on the board
ADC_D2_P: R6.2, U42.T14 (IO_L10P_T1_D14_14); also elsewhere on the board
ADC_D3_N: R5.1, U42.T13 (IO_L16N_T2_A15_D31_14); also elsewhere on the board
ADC_D3_P: R5.2, U42.R13 (IO_L16P_T2_CSI_B_14); also elsewhere on the board
ADC_D4_N: R7.1, U42.R11 (IO_L17N_T2_A13_D29_14); also elsewhere on the board
ADC_D4_P: R7.2, U42.R10 (IO_L17P_T2_A14_D30_14); also elsewhere on the board
ADC_D5_N: R9.1, U42.T10 (IO_L22N_T3_A04_D20_14); also elsewhere on the board
ADC_D5_P: R9.2, U42.T9 (IO_L22P_T3_A05_D21_14); also elsewhere on the board
ADC_D6_N: R8.1, U42.T8 (IO_L21N_T3_DQS_A06_D22_14); also elsewhere on the board
ADC_D6_P: R8.2, U42.T7 (IO_L21P_T3_DQS_14); also elsewhere on the board
ADC_D7_N: R10.1, U42.R7 (IO_L24N_T3_A00_D16_14); also elsewhere on the board
ADC_D7_P: R10.2, U42.R6 (IO_L24P_T3_A01_D17_14); also elsewhere on the board
ADC_DCO_N: R12.1, U42.P14 (IO_L12N_T1_MRCC_14); also elsewhere on the board
ADC_DCO_P: R12.2, U42.N14 (IO_L12P_T1_MRCC_14); also elsewhere on the board
ADC_OR_N: R11.1, U42.N6 (IO_L19N_T3_A09_D25_VREF_14); also elsewhere on the board
ADC_OR_P: R11.2, U42.M6 (IO_L19P_T3_A10_D26_14); also elsewhere on the board
ADC_PWRD: U42.T5 (IO_L23N_T3_A02_D18_14); also elsewhere on the board
ADF4382_RX_CE: JP13.10, U2.124 (PG9)
ADF4382_RX_CS: JP13.9, U2.125 (PG10)
ADF4382_RX_DELADJ: JP13.12, U2.92 (PG7)
ADF4382_RX_DELSTR: JP13.11, U2.93 (PG8)
ADF4382_RX_LKDET: JP13.13, U2.91 (PG6)
ADF4382_TX_CE: JP13.5, U2.132 (PG15)
ADF4382_TX_CS: JP13.4, U2.129 (PG14)
ADF4382_TX_DELADJ: JP13.7, U2.128 (PG13)
ADF4382_TX_DELSTR: JP13.6, U2.127 (PG12)
ADF4382_TX_LKDET: JP13.8, U2.126 (PG11)
DAC_0: U42.A14 (IO_L7N_T1_AD2N_15); also elsewhere on the board
DAC_1: U42.A13 (IO_L7P_T1_AD2P_15); also elsewhere on the board
DAC_1_VG_CLR: U2.134 (PB4); also elsewhere on the board
DAC_1_VG_LDAC: U2.135 (PB5); also elsewhere on the board
DAC_2: U42.A12 (IO_L5N_T0_AD9N_15); also elsewhere on the board
DAC_2_VG_CLR: U2.139 (PB8); also elsewhere on the board
DAC_2_VG_LDAC: U2.140 (PB9); also elsewhere on the board
DAC_3: U42.B11 (IO_L4N_T0_15); also elsewhere on the board
DAC_4: U42.B10 (IO_L4P_T0_15); also elsewhere on the board
DAC_5: U42.A10 (IO_L3N_T0_DQS_AD1N_15); also elsewhere on the board
DAC_6: U42.A9 (IO_L2N_T0_AD8N_15); also elsewhere on the board
DAC_7: U42.A8 (IO_L2P_T0_AD8P_15); also elsewhere on the board
DAC_SLEEP: U42.A15 (IO_L9N_T1_DQS_AD3N_15); also elsewhere on the board
DIG_0: U2.77 (PD8), U42.F13 (IO_L16N_T2_A27_15)
DIG_1: U2.78 (PD9), U42.E16 (IO_L17P_T2_A26_15)
DIG_2: U2.79 (PD10), U42.D16 (IO_L17N_T2_A25_15)
DIG_3: U2.80 (PD11), U42.F15 (IO_L18P_T2_A24_15)
DIG_4: U2.81 (PD12), U42.E15 (IO_L18N_T2_A23_15)
DIG_5: U2.82 (PD13), U42.H11 (IO_L19P_T3_A22_15)
DIG_6: U2.85 (PD14), U42.G12 (IO_L19N_T3_A21_VREF_15)
DIG_7: U2.86 (PD15), U42.H12 (IO_L20P_T3_A20_15)
EN/DIS_COOLING: JP4.1, U2.123 (PD7)
EN/DIS_RFPA_VDD: JP10.1, U2.122 (PD6)
EN_+1V0_FPGA: SV1.1, U2.58 (PE7)
EN_+1V8_CLOCK: SV1.8, U2.89 (PG4)
EN_+1V8_FPGA: SV1.3, U2.59 (PE8)
EN_+3V3_ADAR12: SV1.9, U2.64 (PE11)
EN_+3V3_ADAR34: SV1.11, U2.65 (PE12)
EN_+3V3_ADTR: SV1.13, U2.66 (PE13)
EN_+3V3_CLOCK: SV1.10, U2.90 (PG5)
EN_+3V3_FPGA: SV1.5, U2.60 (PE9)
EN_+3V3_SW: SV1.15, U2.67 (PE14)
EN_+3V3_VDD_SW: SV1.17, U2.68 (PE15)
EN_+5V0_ADAR: SV1.7, U2.63 (PE10)
EN_+5V0_PA1: SV1.19, U2.56 (PG0)
EN_+5V0_PA2: SV1.2, U2.57 (PG1)
EN_+5V0_PA3: SV1.4, U2.87 (PG2)
EN_+5V5_PA: SV1.6, U2.88 (PG3)
FPGA_ADC_CLOCK_N: J19.2, R4.1, U42.N12 (IO_L13N_T2_MRCC_14)
FPGA_ADC_CLOCK_P: J19.1, R4.2, U42.N11 (IO_L13P_T2_MRCC_14)
FPGA_CLOCK_TEST: JP20.1, U42.H14 (IO_L24P_T3_RS1_15)
FPGA_DAC_CLOCK: J18.1, U42.C13 (IO_L12N_T1_MRCC_15)
FPGA_DONE: R144.1, U2.44 (PC4), U42.H10 (DONE_0)
FPGA_FLASH_CLK: R51.2, U42.E8 (CCLK_0)
FPGA_FLASH_DQ0: U42.J13 (IO_L1P_T0_D00_MOSI_14); also elsewhere on the board
FPGA_FLASH_DQ1: U42.J14 (IO_L1N_T0_D01_DIN_14); also elsewhere on the board
FPGA_FLASH_DQ2: R53.1, U42.K15 (IO_L2P_T0_D02_14); also elsewhere on the board
FPGA_FLASH_DQ3: R54.2, U42.K16 (IO_L2N_T0_D03_14); also elsewhere on the board
FPGA_FLASH_NCS: R52.1, U42.L12 (IO_L6P_T0_FCS_B_14); also elsewhere on the board
FPGA_FLASH_NRST: R50.1, U42.L13 (IO_L5N_T0_D07_14); also elsewhere on the board
FPGA_PUDC_B: R69.1, U42.L15 (IO_L3P_T0_DQS_PUDC_B_14)
FPGA_SYS_CLOCK: J1.1, U42.E12 (IO_L13P_T2_MRCC_15)
FPGA_TCK: R62.1, R67.1, U42.L7 (TCK_0)
FPGA_TDI: R64.1, R65.1, U42.N7 (TDI_0)
FPGA_TDO: R63.1, R66.1, U42.N8 (TDO_0)
FPGA_TMS: R49.1, R68.1, U42.M7 (TMS_0)
FT2232_USB_D_N: U6.7 (DM), X2.2
FT2232_USB_D_P: U6.8 (DP), X2.3
FT_+1V8: C191.2, U6.12 (VCORE_2), U6.37 (VCORE), U6.49 (VREGOUT), U6.64 (VCORE)
FT_CLKOUT: U6.32 (ACBUS5), U42.C4 (IO_L12N_T1_MRCC_35)
FT_D0: U6.16 (ADBUS0), U42.K1 (IO_L22P_T3_35)
FT_D1: U6.17 (ADBUS1), U42.J3 (IO_L21P_T3_DQS_35)
FT_D2: U6.18 (ADBUS2), U42.H3 (IO_L21N_T3_DQS_35)
FT_D3: U6.19 (ADBUS3), U42.G4 (IO_L16N_T2_35)
FT_D4: U6.21 (ADBUS4), U42.F2 (IO_L15P_T2_DQS_35)
FT_D5: U6.22 (ADBUS5), U42.D1 (IO_L10N_T1_AD15N_35)
FT_D6: U6.23 (ADBUS6), U42.C3 (IO_L7P_T1_AD6P_35)
FT_D7: U6.24 (ADBUS7), U42.C1 (IO_L9P_T1_DQS_AD7P_35)
FT_OE#: U6.33 (ACBUS6), U42.B7 (IO_L1P_T0_AD4P_35)
FT_RD#: U6.28 (ACBUS2), U42.A3 (IO_L4N_T0_35)
FT_RESET#: R61.2, U6.14 (RESET-)
FT_RXF#: U6.26 (ACBUS0), U42.A2 (IO_L8N_T1_AD14N_35)
FT_SIWUA: U6.30 (ACBUS4), U42.A5 (IO_L3P_T0_DQS_AD5P_35)
FT_TXE#: U6.27 (ACBUS1), U42.B2 (IO_L8P_T1_AD14P_35)
FT_WR#: U6.29 (ACBUS3), U42.A4 (IO_L3N_T0_DQS_AD5N_35)
GYR_INT: JP7.8, U2.98 (PC8)
M3S_VCTRL: U42.G15 (IO_L24N_T3_RS0_15); also elsewhere on the board
MAG_DRDY: JP7.6, U2.96 (PC6)
MIX_RX_EN: U42.D11 (IO_L14N_T2_SRCC_15); also elsewhere on the board
MIX_TX_EN: U42.C11 (IO_L11P_T1_SRCC_15); also elsewhere on the board
unnamed: C23.1, U2.71 (VCAP_1)
unnamed: C22.1, U2.106 (VCAP_2)
unnamed: C24.1, L5.1, U2.32 (VREF+), U2.33 (VDDA)
unnamed: R51.1, U9.B2 (C)
unnamed: JP3.1, R49.2
unnamed: JP3.3, R62.2
unnamed: JP3.5, R63.2
unnamed: JP3.7, R64.2
unnamed: R110.2, U2.50 (PF12)
unnamed: IC1.4 (DO), R83.1, R146.2
unnamed: R112.2, U2.53 (PF13)
unnamed: D3.A, R114.1
unnamed: R113.2, U2.54 (PF14)
unnamed: R114.2, U2.55 (PF15)
unnamed: D2.A, R113.1
unnamed: D4.A, R112.1
unnamed: D5.A, R110.1
unnamed: R138.2, U42.M9 (M0_0)
unnamed: R139.2, U42.M10 (M1_0)
unnamed: R140.2, U42.M11 (M2_0)
unnamed: R141.2, U42.L9 (PROGRAM_B_0)
unnamed: R142.2, U42.E7 (CFGBVS_0)
unnamed: R143.1, U42.K10 (INIT_B_0)
unnamed: R60.1, U6.6 (REF)
unnamed: C184.1, U6.2 (OSCI), Y1.P1 (1)
unnamed: C185.1, U6.3 (OSCO), Y1.P3 (2)
unnamed: C186.A (+), C188.2, L20.1, U6.9 (VPLL)
unnamed: C187.A (+), C189.1, L19.1, U6.4 (VPHY)
unnamed: IC1.1 (CS), R145.1, U6.63 (EECS)
unnamed: IC1.2 (SK), R84.1, U6.62 (EECLK)
unnamed: IC1.3 (DI), R146.1, U6.61 (EEDATA)
STEPPER_CLK+: JP9.4, U2.119 (PD5)
STEPPER_CW+: JP9.2, U2.118 (PD4)
STM32_MISO1: U2.42 (PA6), U42.G14 (IO_L21P_T3_DQS_15)
STM32_MISO4: JP1.8, JP13.1, U2.4 (PE5)
STM32_MISO_1V8: U42.N3 (IO_L3P_T0_DQS_34); also elsewhere on the board
STM32_MOSI1: U2.43 (PA7), U42.H13 (IO_L20N_T3_A19_15)
STM32_MOSI4: JP1.7, JP13.3, U2.5 (PE6)
STM32_MOSI_1V8: U42.M1 (IO_L2N_T0_34); also elsewhere on the board
STM32_NRST: C164.2, JP2.5, R111.1, S1.3 (2), S1.4 (2), U2.25 (NRST)
STM32_OSC_32_N: C18.1, U2.8 (PC14), XTAL3.2
STM32_OSC_32_P: C19.1, U2.9 (PC15), XTAL3.1
STM32_OSC_N: C20.1, U2.23 (PH0), XTAL1.2
STM32_OSC_P: C21.1, U2.24 (PH1), XTAL1.1
STM32_RX3: JP17.2, U2.70 (PB11)
STM32_RX5: JP8.3, U2.116 (PD2)
STM32_SCL1: R170.2, U2.136 (PB6); also elsewhere on the board
STM32_SCL2: R172.2, U2.11 (PF1); also elsewhere on the board
STM32_SCL3: JP7.4, JP18.2, R167.2, U2.100 (PA8)
STM32_SCLK1: U2.41 (PA5), U42.J16 (IO_L23N_T3_FWE_B_15)
STM32_SCLK4: JP1.6, JP13.2, U2.1 (PE2)
STM32_SCLK_1V8: U42.P5 (IO_L10P_T1_34); also elsewhere on the board
STM32_SDA1: R169.2, U2.137 (PB7); also elsewhere on the board
STM32_SDA2: R171.2, U2.10 (PF0); also elsewhere on the board
STM32_SDA3: JP7.5, JP18.1, R168.2, U2.99 (PC9)
STM32_SWCLK: JP2.2, U2.109 (PA14)
STM32_SWDIO: JP2.4, U2.105 (PA13)
STM32_SWO: JP2.6, U2.133 (PB3)
STM32_TX3: JP17.1, U2.69 (PB10)
STM32_TX5: JP8.2, U2.113 (PC12)
STM32_USB_FS_D_N: U2.103 (PA11), X53.2
STM32_USB_FS_D_P: U2.104 (PA12), X53.3
STM32_USB_FS_ID: U2.102 (PA10), X53.4

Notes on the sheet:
DIGITAL (FPGA + MICROCONTROLLER)

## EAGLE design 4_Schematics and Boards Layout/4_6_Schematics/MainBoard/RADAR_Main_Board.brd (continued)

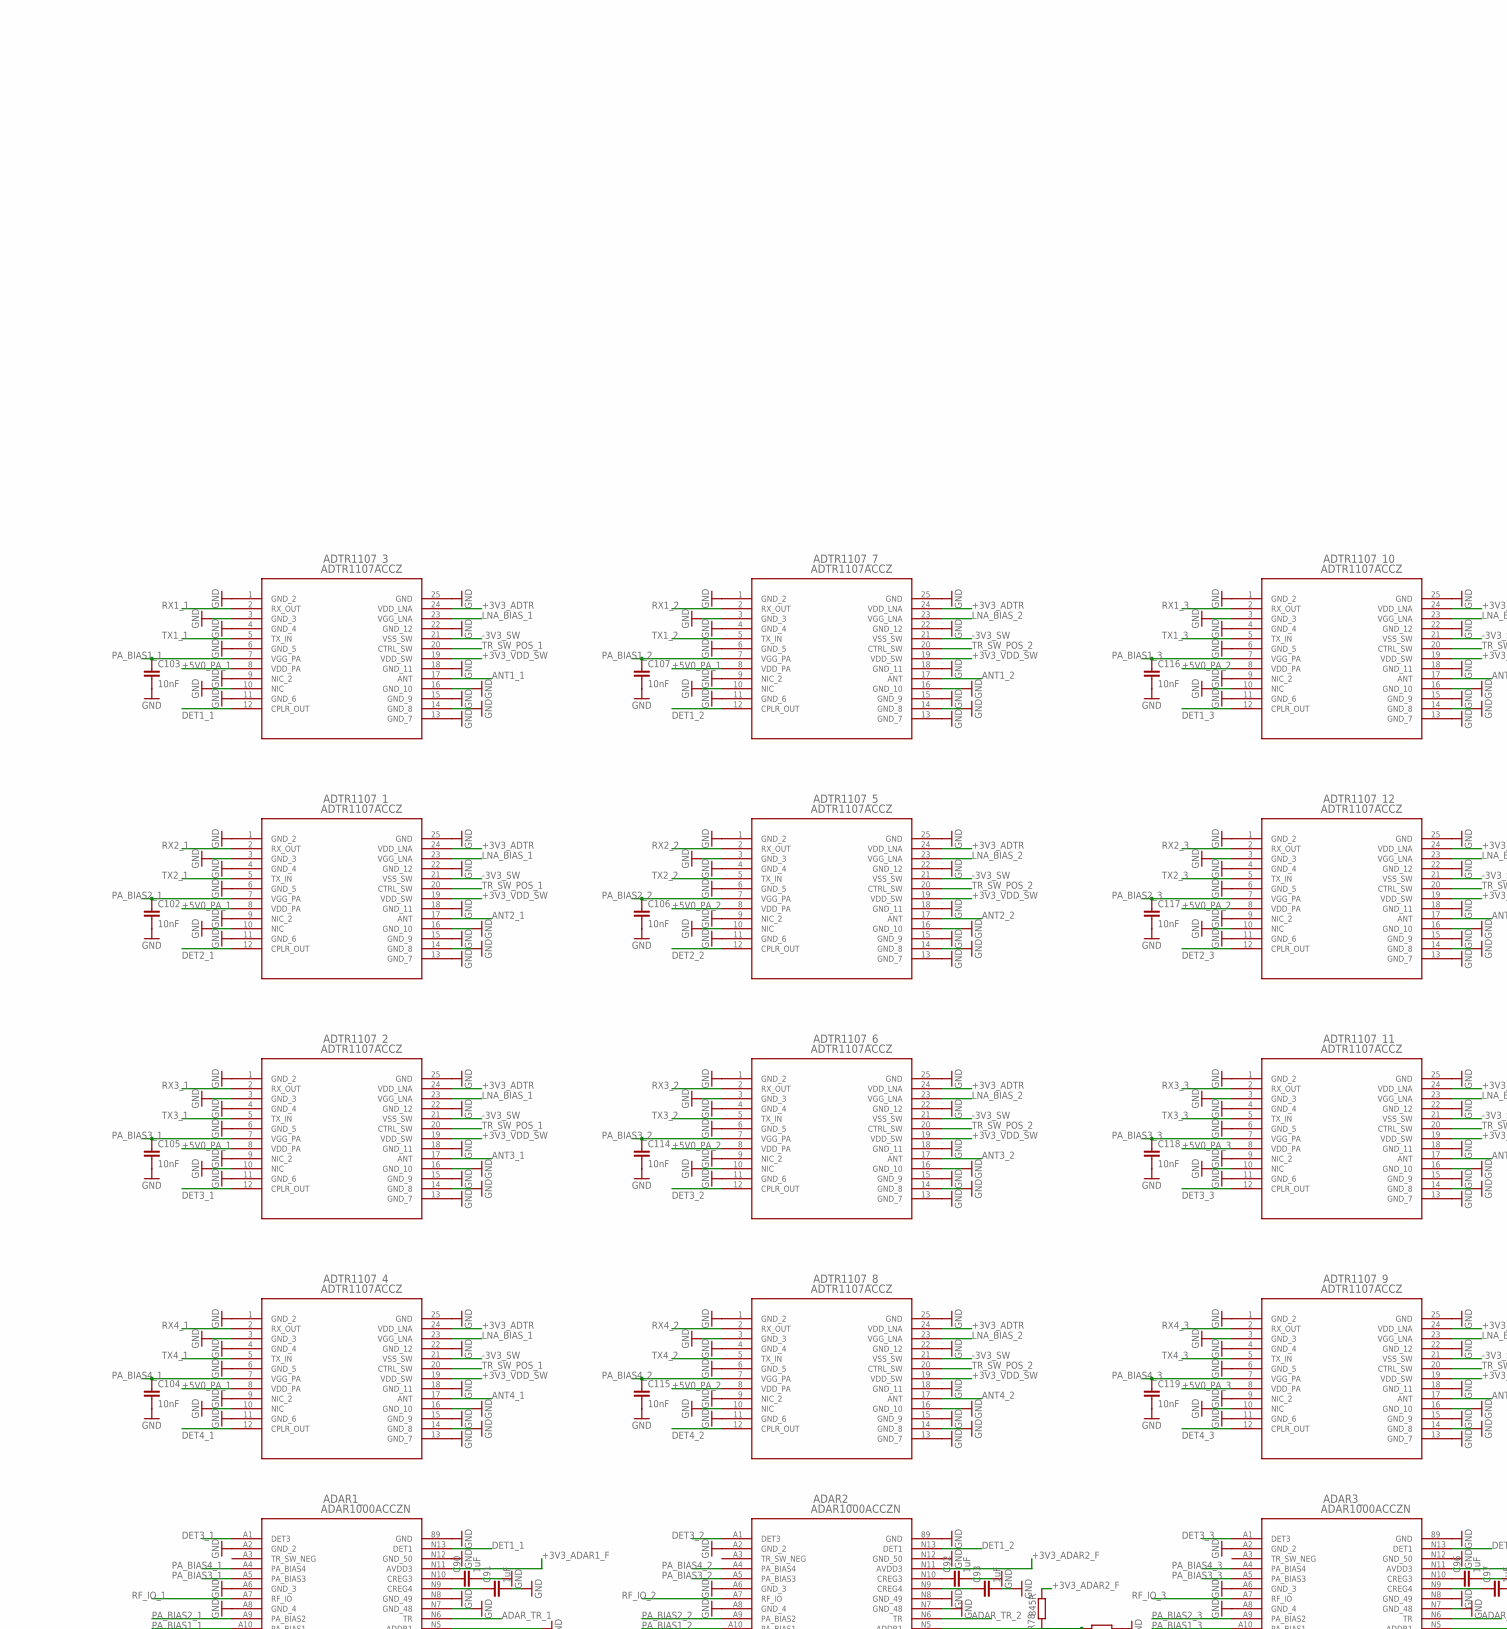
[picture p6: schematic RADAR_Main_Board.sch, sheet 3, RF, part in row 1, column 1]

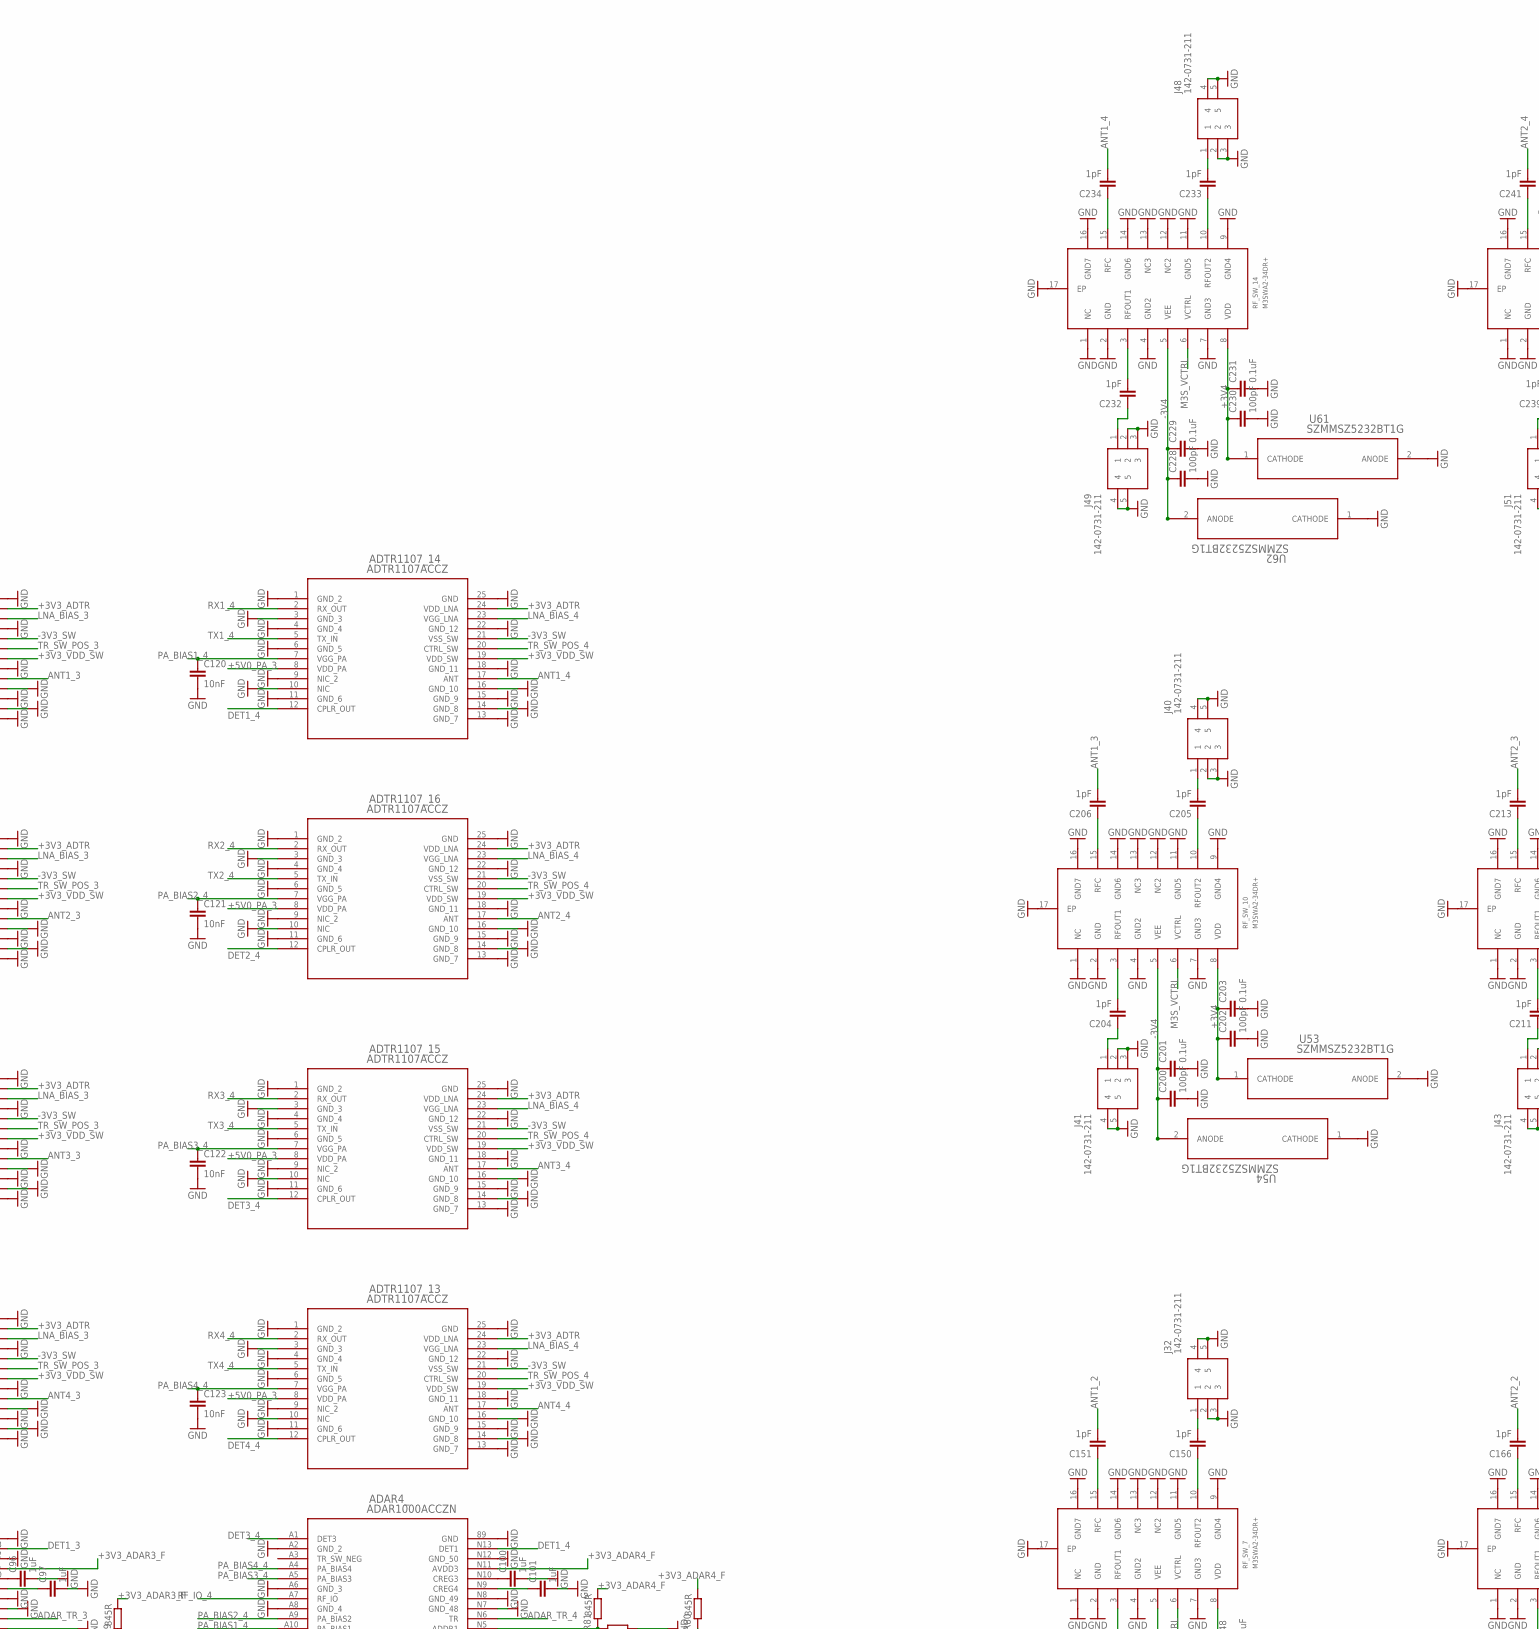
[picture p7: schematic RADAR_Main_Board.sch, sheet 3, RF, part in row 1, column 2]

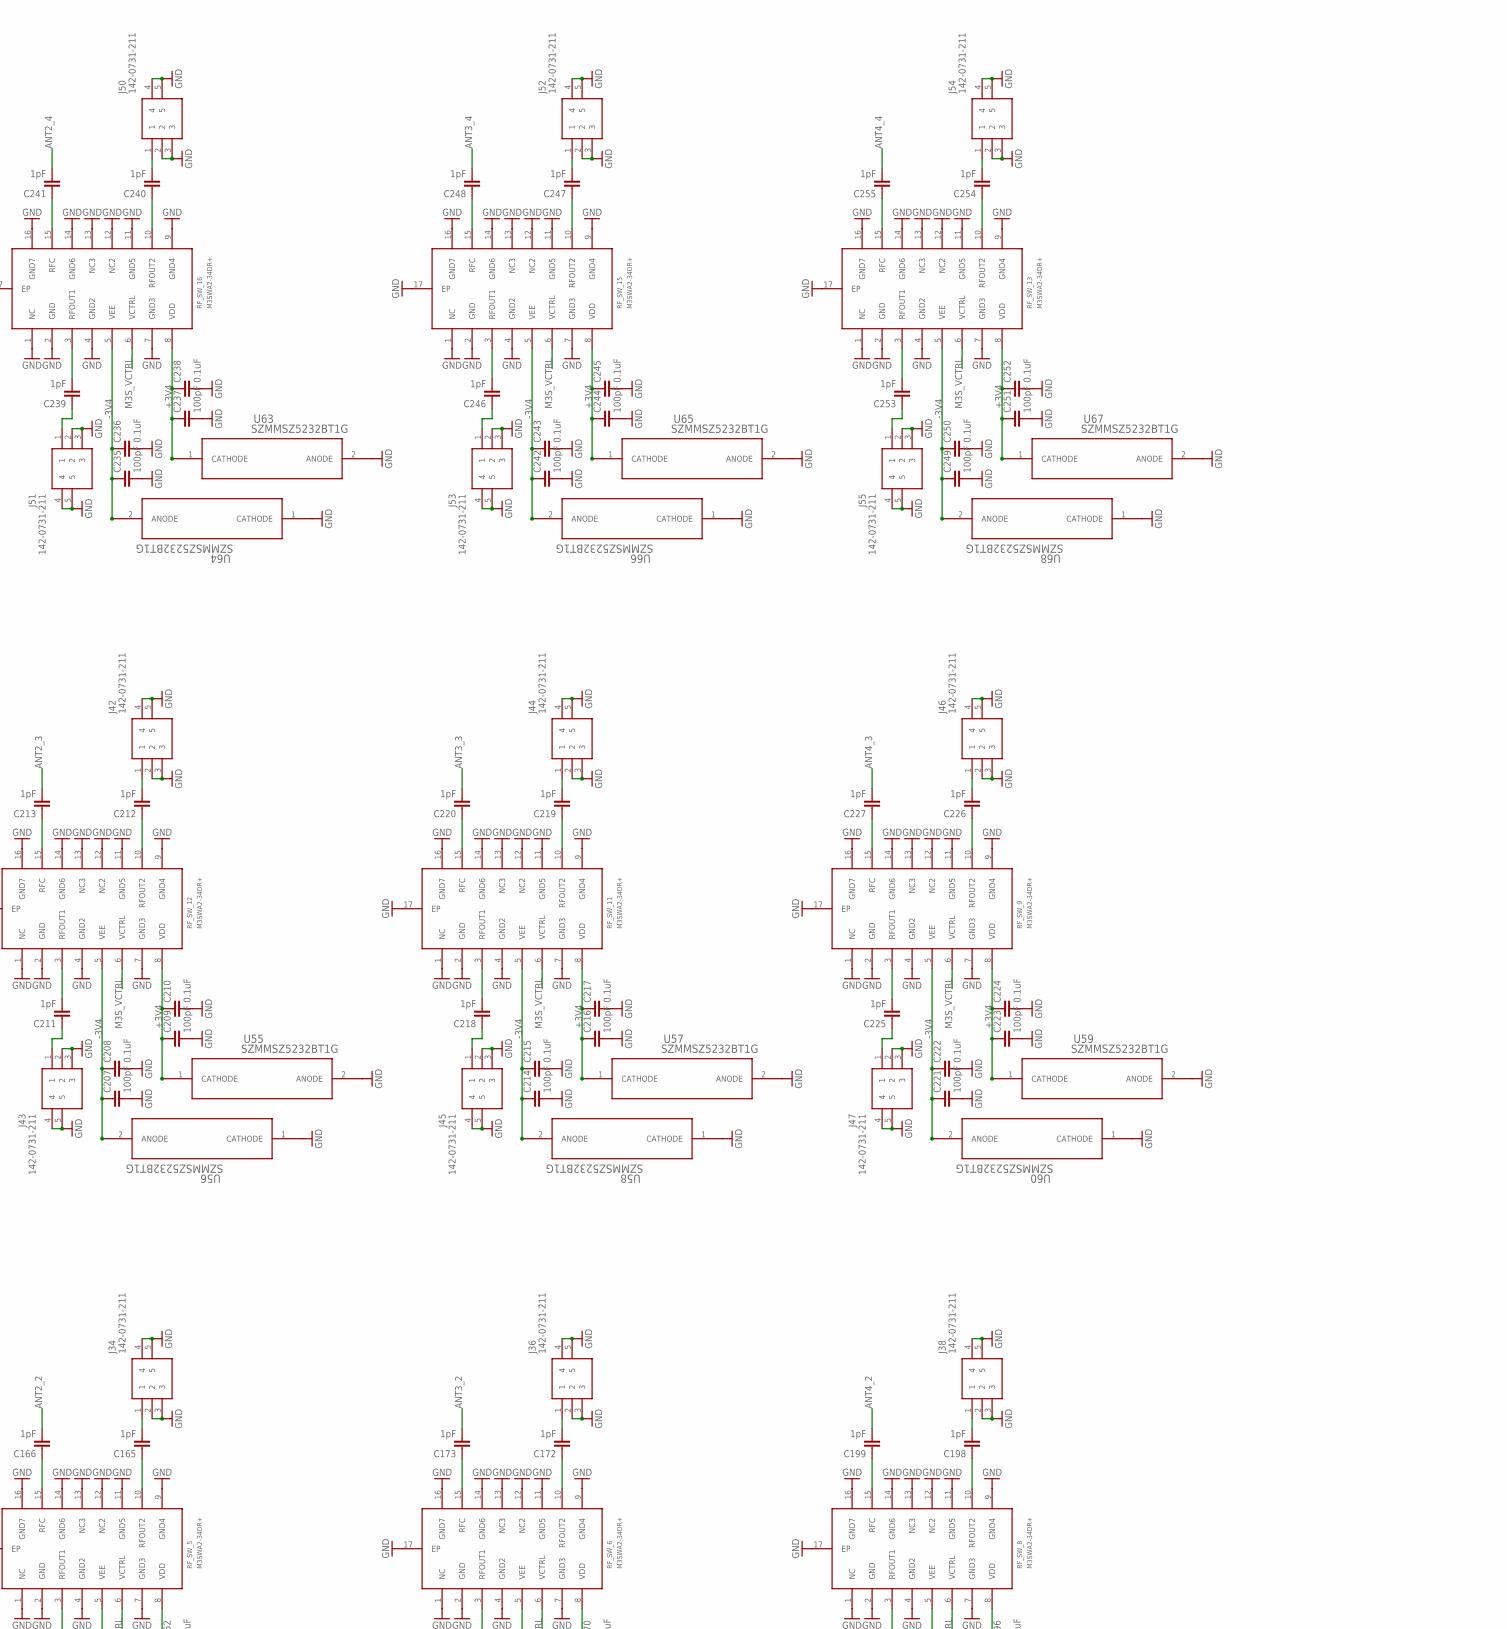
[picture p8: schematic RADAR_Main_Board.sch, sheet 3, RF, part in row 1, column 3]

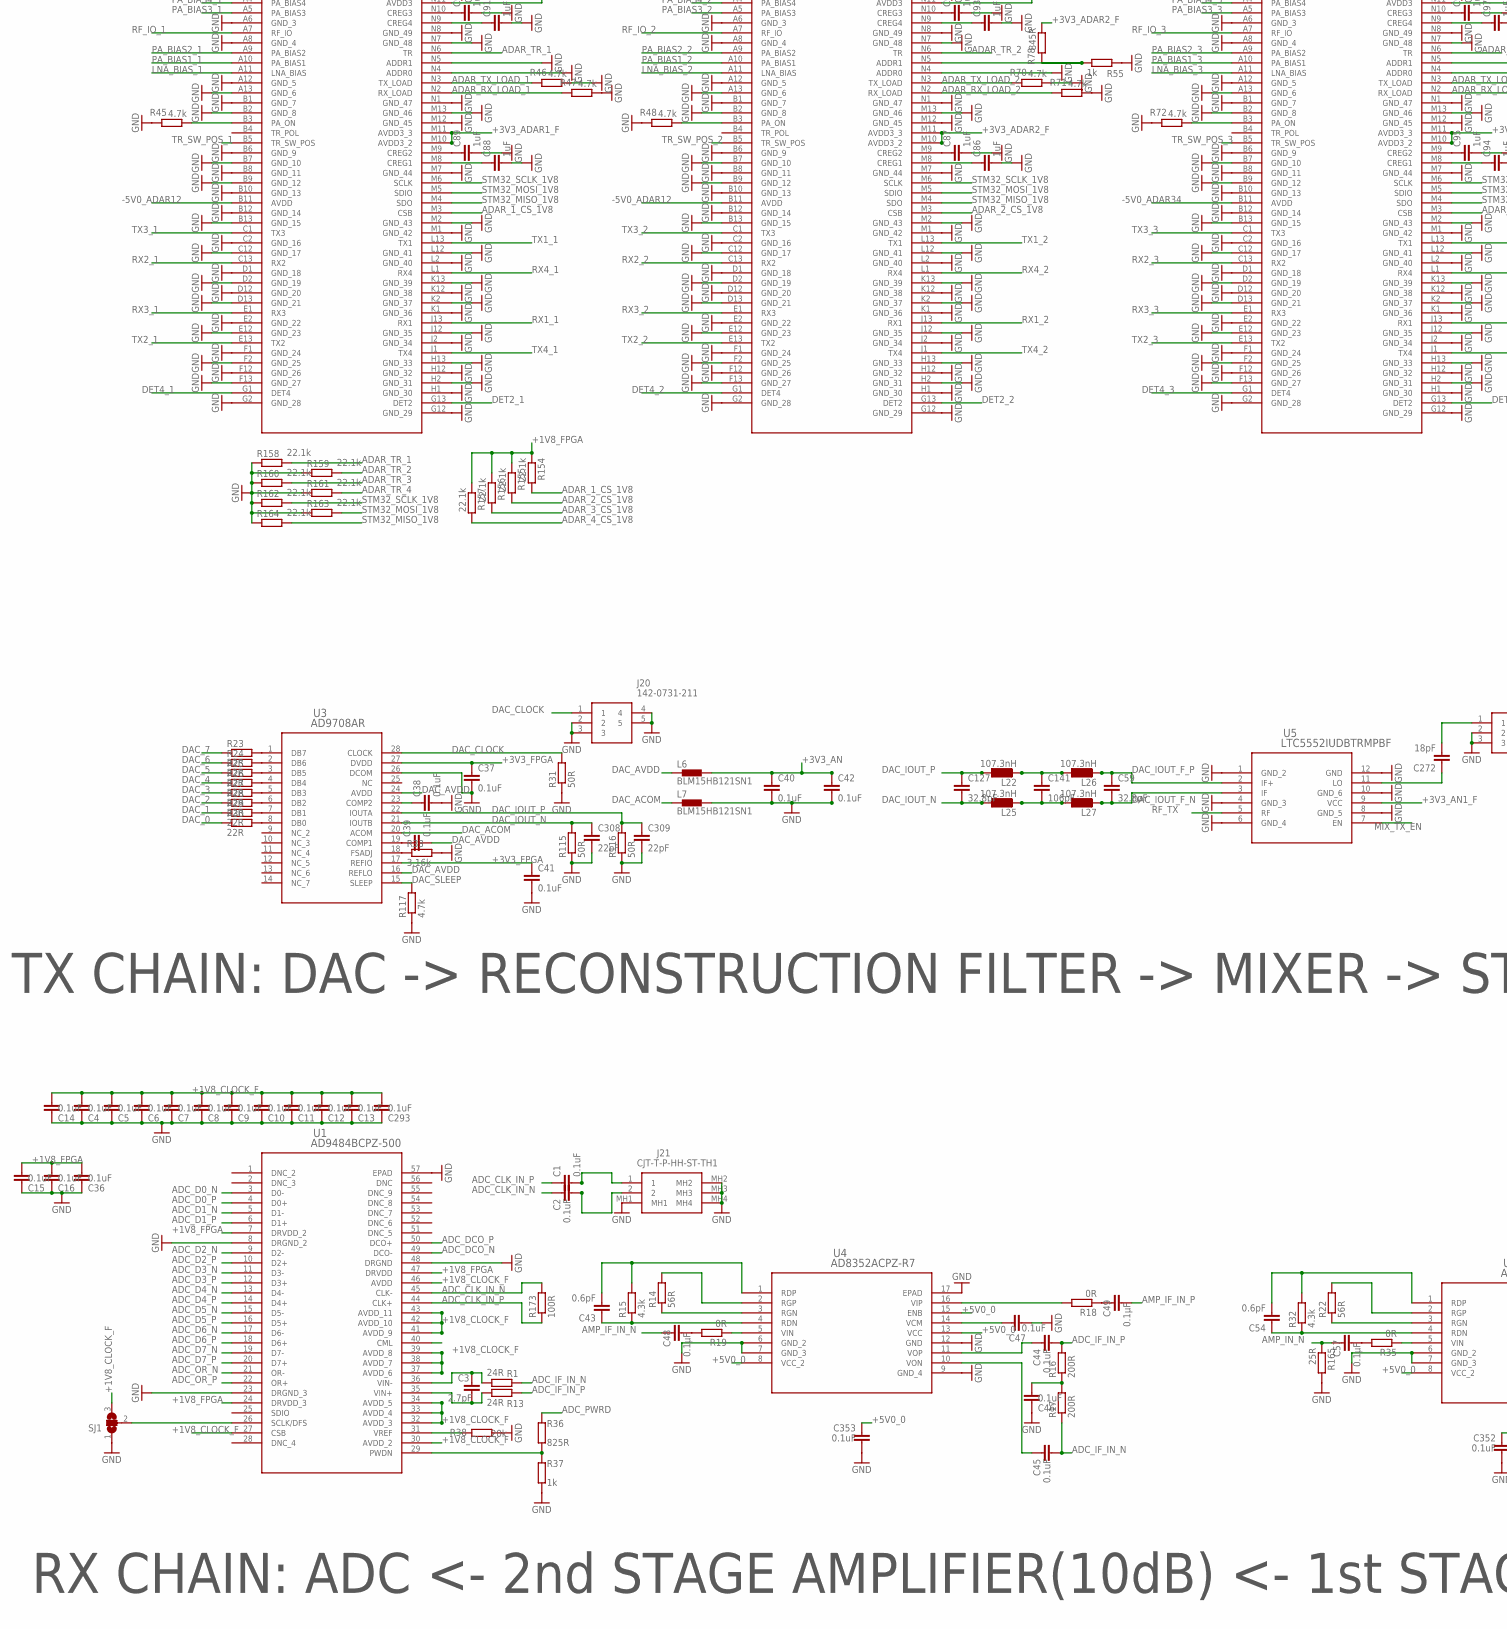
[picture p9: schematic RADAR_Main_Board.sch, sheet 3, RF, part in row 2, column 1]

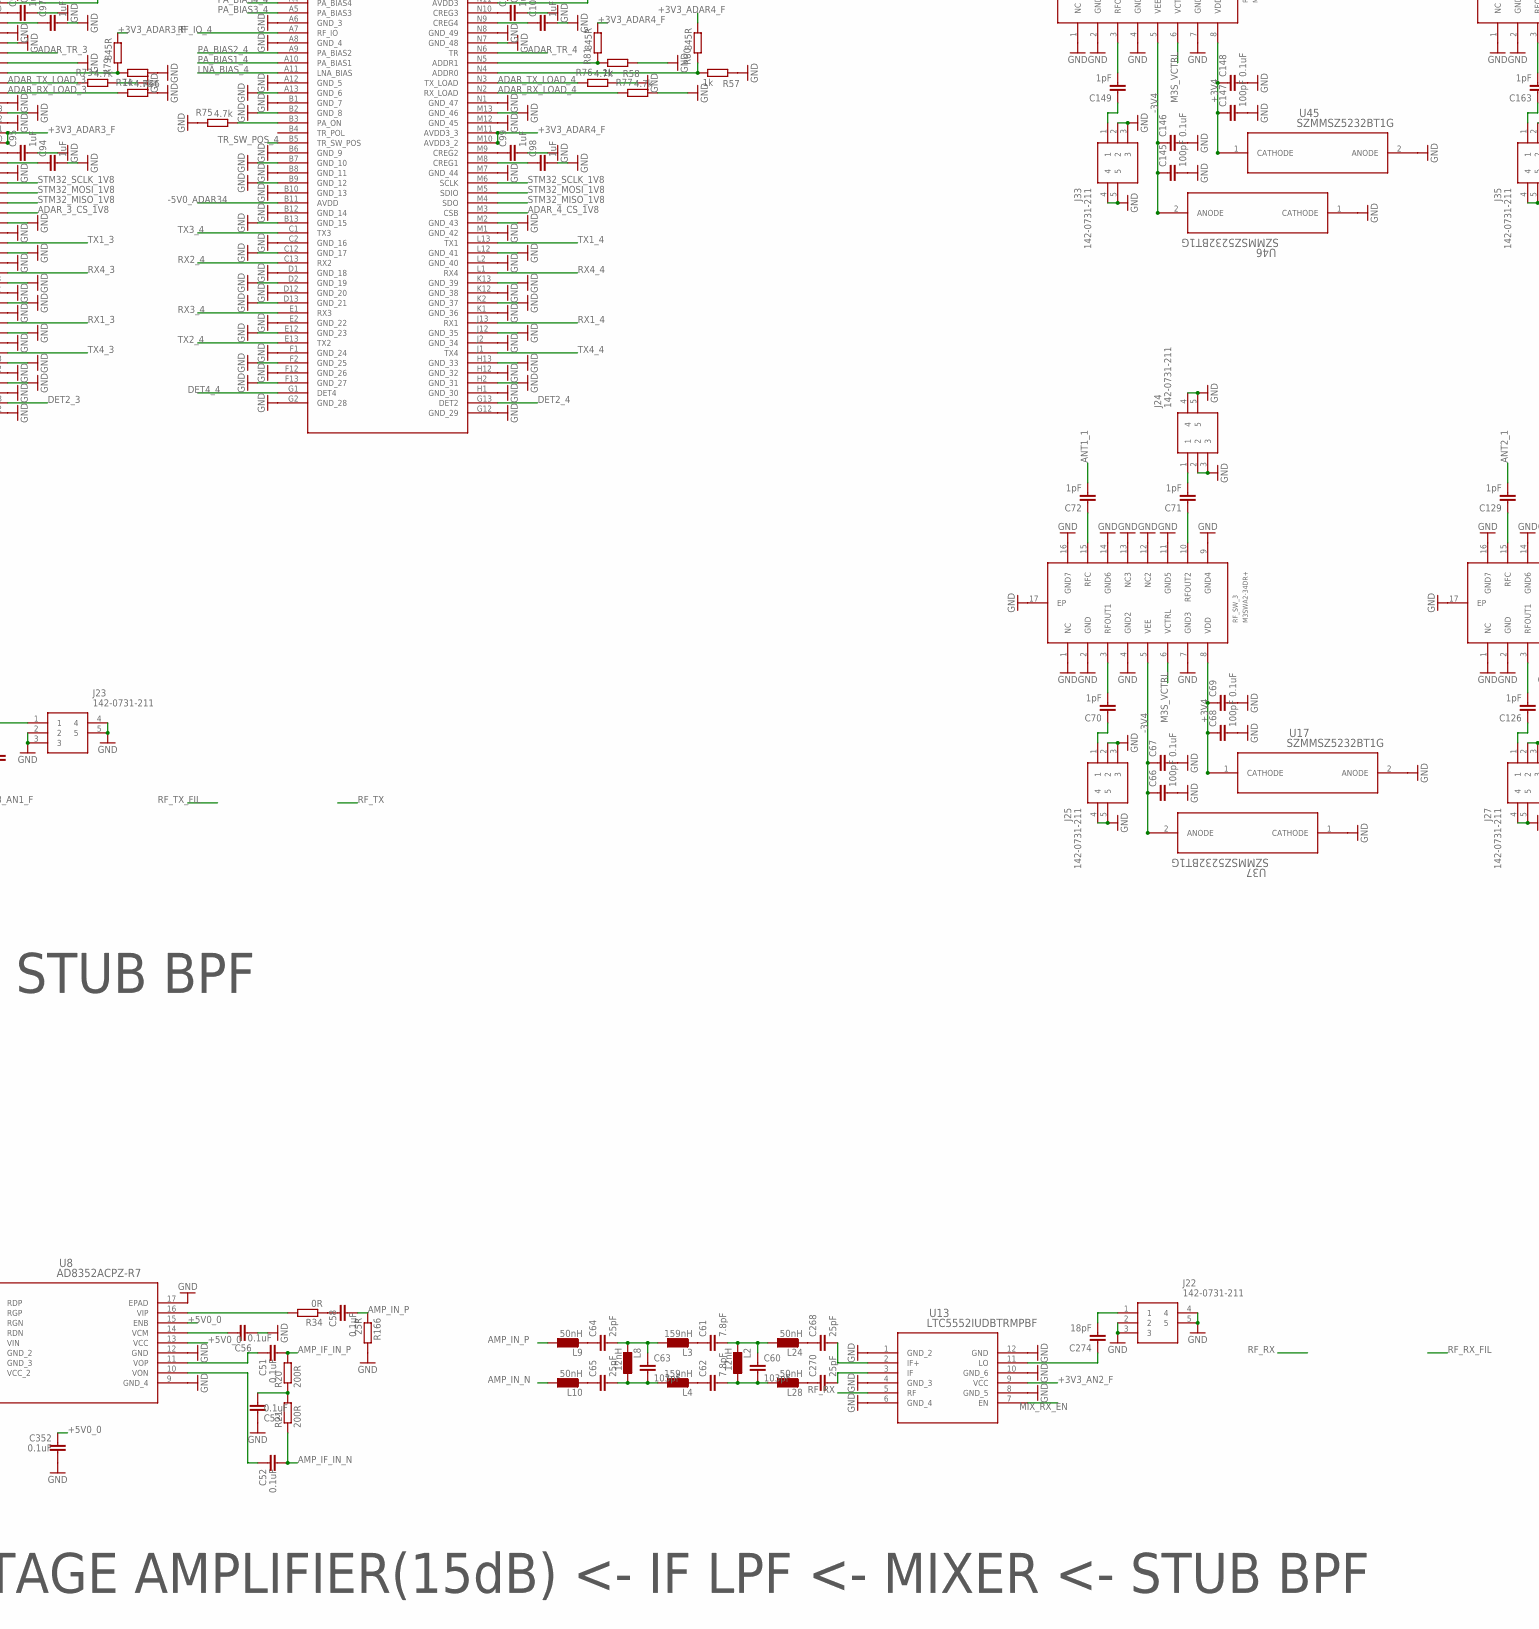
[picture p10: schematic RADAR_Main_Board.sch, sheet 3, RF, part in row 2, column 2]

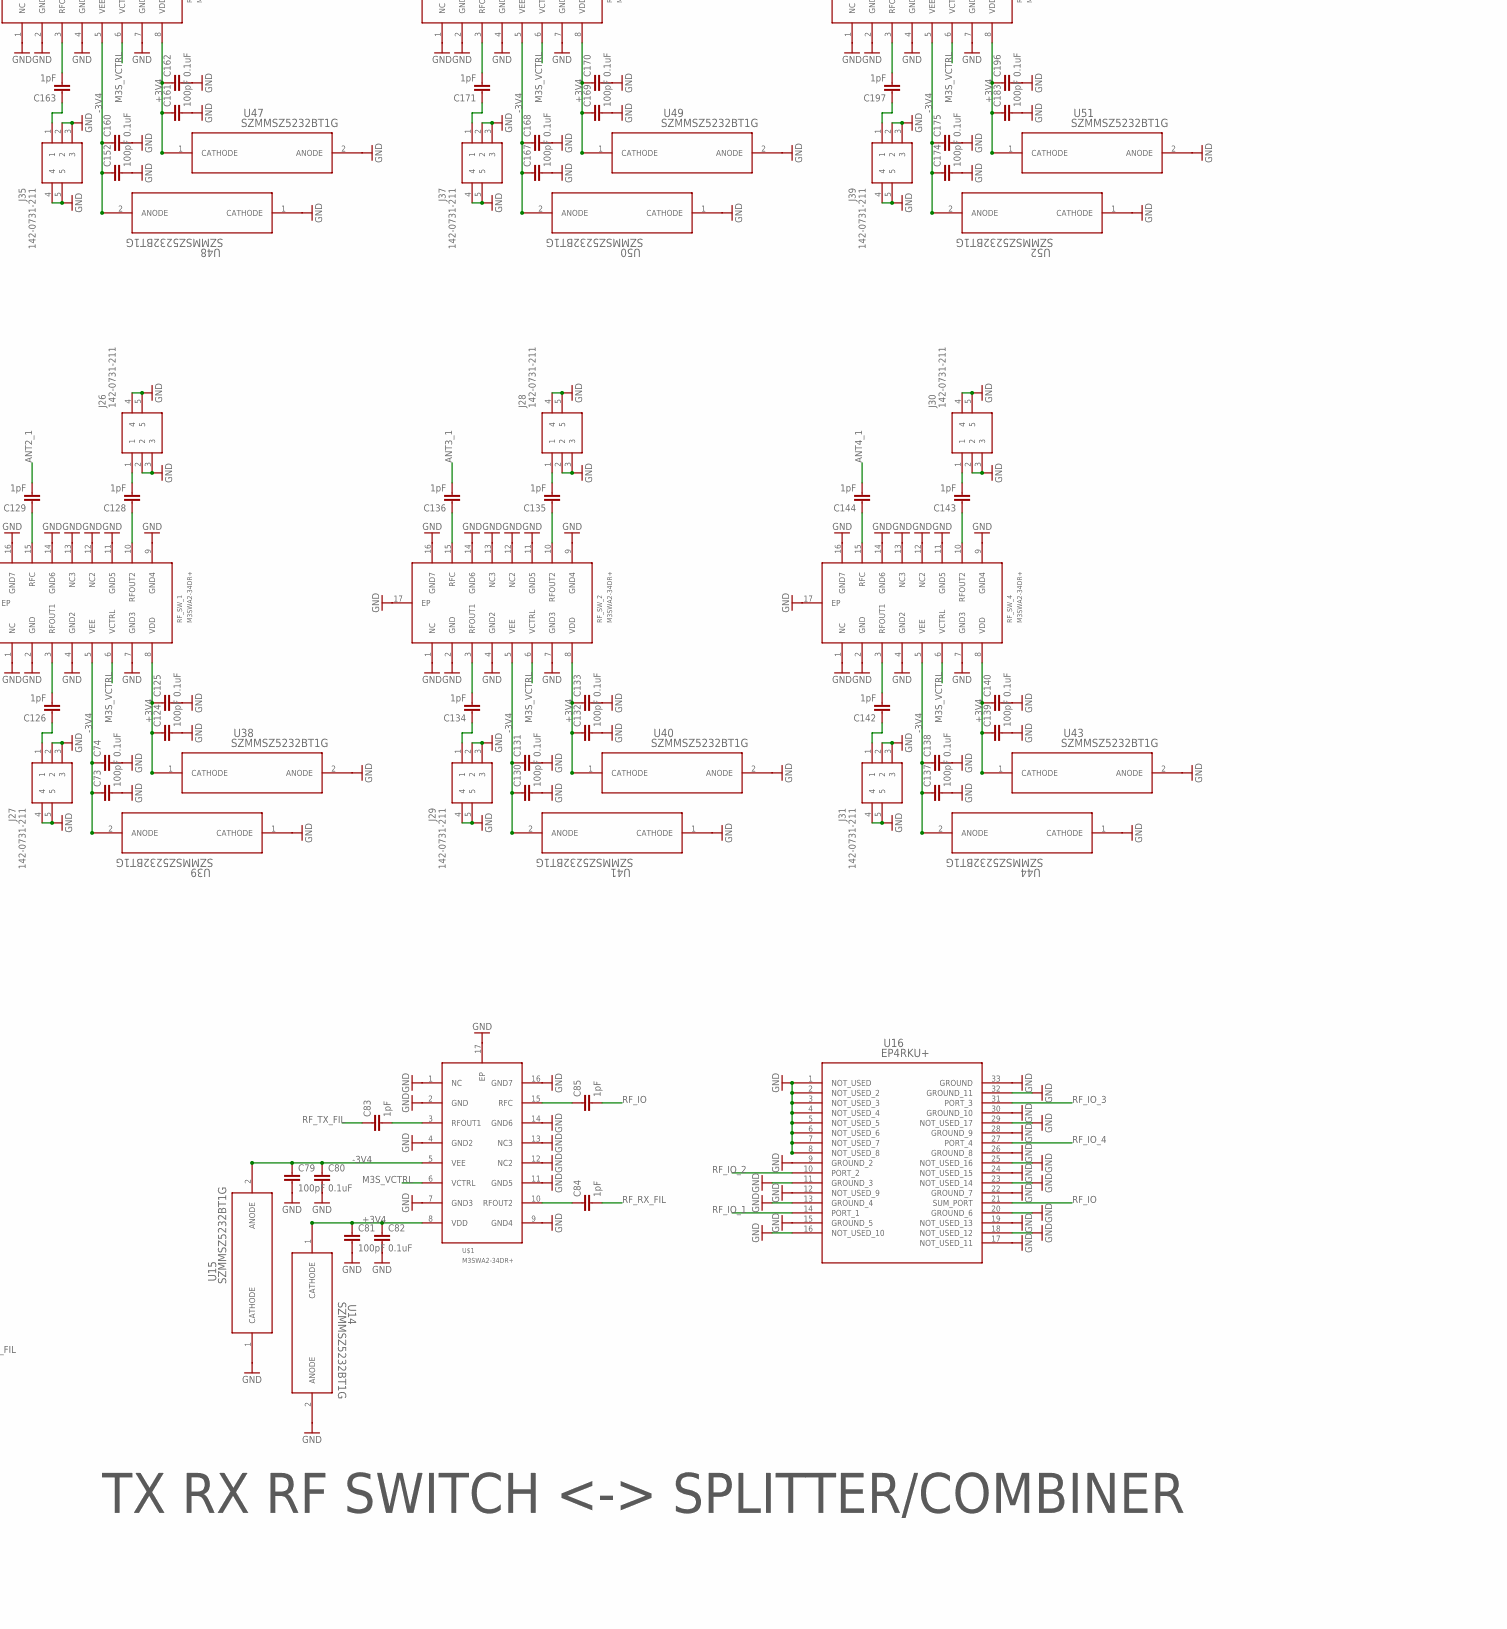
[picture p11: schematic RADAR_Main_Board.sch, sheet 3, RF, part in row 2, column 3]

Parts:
ADAR1_, ADAR2_, ADAR3_, ADAR4_: ADAR1000ACCZN; CC-88-1_ADI
ADTR1107_1, ADTR1107_2, ADTR1107_3, ADTR1107_4, ADTR1107_5, ADTR1107_6, ADTR1107_7, ADTR1107_8, ADTR1107_9, ADTR1107_10, ADTR1107_11, ADTR1107_12, ADTR1107_13, ADTR1107_14, ADTR1107_15, ADTR1107_16: ADTR1107ACCZ; CC-24-8_ADI
C1, C2, C4, C5, C6, C7, C8, C9, C10, C11, C12, C13, C14, C15, C16, C36, C37, C38, C39, C40, C41, C42, C44, C45, C46, C47, C51, C52, C53, C56, C67, C69, C74, C80, C82, C125, C131, C133, C138, C140, C146, C148, C160, C162, C168, C170, C175, C196, C201, C203, C208, C210, C215, C217, C222, C224, C229, C231, C236, C238, C243, C245, C250, C252, C293, C352, C353: 0.1uF; C0201
C3: 2.7pF; C0402
C43, C54: 0.6pF; C0201
C48, C49, C57, C58: 0.1µF; C0402
C59, C127: 32.8pF; C0201
C60, C63: 103pF; C0201
C61, C62: 7.8pF; C0201
C64, C65, C268, C270: 25pF; C0201
C66, C68, C73, C79, C81, C124, C130, C132, C137, C139, C145, C147, C152, C161, C167, C169, C174, C183, C200, C202, C207, C209, C214, C216, C221, C223, C228, C230, C235, C237, C242, C244, C249, C251: 100pF; C0201
C70, C71, C72, C83, C84, C85, C126, C128, C129, C134, C135, C136, C142, C143, C144, C149, C150, C151, C163, C165, C166, C171, C172, C173, C197, C198, C199, C204, C205, C206, C211, C212, C213, C218, C219, C220, C225, C226, C227, C232, C233, C234, C239, C240, C241, C246, C247, C248, C253, C254, C255: 1pF; C0201
C86, C87, C88, C89, C90, C91, C92, C93, C94, C95, C96, C97, C98, C99, C100, C101: 1uF; C0201
C102, C103, C104, C105, C106, C107, C114, C115, C116, C117, C118, C119, C120, C121, C122, C123: 10nF; C0201
C141: 106pF; C0201
C272, C274: 18pF; C0201
C308, C309: 22pF; C0201
J20, J22, J23, J24, J25, J26, J27, J28, J29, J30, J31, J32, J33, J34, J35, J36, J37, J38, J39, J40, J41, J42, J43, J44, J45, J46, J47, J48, J49, J50, J51, J52, J53, J54, J55: 142-0731-211; 1420731211
J21: CJT-T-P-HH-ST-TH1; CJTTPHHSTTH1
L2, L8: 12nH; L0201
L3, L4: 159nH; L0201
L6, L7: BLM15HB121SN1; 0402
L9, L10, L24, L28: 50nH; L0201
L22, L25, L26, L27: 107.3nH; L0201
R1, R13: 24R; R0402
R14, R22: 56R; R0201
R15, R32: 4.3k; R0201
R16, R17, R20, R21: 200R; R0201
R18, R19, R34, R35: 0R; R0201
R23, R24, R25, R26, R27, R28, R29, R30: 22R; R0201
R31, R115, R116: 50R; R0201
R33: 3.16k; R0201
R36: 825R; R0402
R37: 1k; R0402
R38: 20k; R0402
R45, R46, R47, R48, R70, R71, R72, R73, R74, R75, R76, R77, R117: 4.7k; R0201
R55, R56, R57, R58: 1k; R0201
R78, R79, R80, R81: 845R; R0201
R154, R155, R156, R157, R158, R159, R160, R161, R162, R163, R164: 22.1k; R0201
R165, R166: 25R; R0201
R173: 100R; R0201
RF_SW_1, RF_SW_2, RF_SW_3, RF_SW_4, RF_SW_5, RF_SW_6, RF_SW_7, RF_SW_8, RF_SW_9, RF_SW_10, RF_SW_11, RF_SW_12, RF_SW_13, RF_SW_14, RF_SW_15, RF_SW_16: M3SWA2-34DR+; 16_QFN
SJ1: SJ2W; SJ_2
U1: AD9484BCPZ-500; CP_56_5_ADI
U3: AD9708AR; RW_28_ADI
U4, U8: AD8352ACPZ-R7; CP_16_3_ADI
U5, U13: LTC5552IUDBTRMPBF; UDB_12_ADI
U14, U15, U17, U37, U38, U39, U40, U41, U43, U44, U45, U46, U47, U48, U49, U50, U51, U52, U53, U54, U55, U56, U57, U58, U59, U60, U61, U62, U63, U64, U65, U66, U67, U68: SZMMSZ5232BT1G; SOD-123_ONS
U16: EP4RKU+; DG1677-2_MNC
U$1: M3SWA2-34DR+; 16_QFN

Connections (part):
+1V8_FPGA: C15.2, C16.2, C36.2, R154.1, R155.1, R156.1, R157.1, U1.7 (DRVDD_2), U1.24 (DRVDD_3), U1.47 (DRVDD); also elsewhere on the board
+3V3_ADAR1_F: ADAR1_.M10 (AVDD3_2), ADAR1_.M11 (AVDD3_3), ADAR1_.N11 (AVDD3); also elsewhere on the board
+3V3_ADAR2_F: ADAR2_.M10 (AVDD3_2), ADAR2_.M11 (AVDD3_3), ADAR2_.N11 (AVDD3), R78.1; also elsewhere on the board
+3V3_ADAR3_F: ADAR3_.M10 (AVDD3_2), ADAR3_.M11 (AVDD3_3), ADAR3_.N11 (AVDD3), R79.1; also elsewhere on the board
+3V3_ADAR4_F: ADAR4_.M10 (AVDD3_2), ADAR4_.M11 (AVDD3_3), ADAR4_.N11 (AVDD3), R80.1, R81.1; also elsewhere on the board
+3V3_ADTR: ADTR1107_1.24 (VDD_LNA), ADTR1107_2.24 (VDD_LNA), ADTR1107_3.24 (VDD_LNA), ADTR1107_4.24 (VDD_LNA), ADTR1107_5.24 (VDD_LNA), ADTR1107_6.24 (VDD_LNA), ADTR1107_7.24 (VDD_LNA), ADTR1107_8.24 (VDD_LNA), ADTR1107_9.24 (VDD_LNA), ADTR1107_10.24 (VDD_LNA), ADTR1107_11.24 (VDD_LNA), ADTR1107_12.24 (VDD_LNA), ADTR1107_13.24 (VDD_LNA), ADTR1107_14.24 (VDD_LNA), ADTR1107_15.24 (VDD_LNA), ADTR1107_16.24 (VDD_LNA); also elsewhere on the board
+3V3_AN: C40.1, C42.1, L6.2; also elsewhere on the board
+3V3_AN1_F: U5.9 (VCC); also elsewhere on the board
+3V3_AN2_F: U13.9 (VCC); also elsewhere on the board
+3V3_FPGA: C37.1, C41.1, U3.17 (REFIO), U3.27 (DVDD); also elsewhere on the board
+3V3_VDD_SW: ADTR1107_1.19 (VDD_SW), ADTR1107_2.19 (VDD_SW), ADTR1107_3.19 (VDD_SW), ADTR1107_4.19 (VDD_SW), ADTR1107_5.19 (VDD_SW), ADTR1107_6.19 (VDD_SW), ADTR1107_7.19 (VDD_SW), ADTR1107_8.19 (VDD_SW), ADTR1107_9.19 (VDD_SW), ADTR1107_10.19 (VDD_SW), ADTR1107_11.19 (VDD_SW), ADTR1107_12.19 (VDD_SW), ADTR1107_13.19 (VDD_SW), ADTR1107_14.19 (VDD_SW), ADTR1107_15.19 (VDD_SW), ADTR1107_16.19 (VDD_SW); also elsewhere on the board
+3V4: C68.1, C69.1, C81.1, C82.1, C124.1, C125.1, C132.1, C133.1, C139.1, C140.1, C147.1, C148.1, C161.1, C162.1, C169.1, C170.1, C183.1, C196.1, C202.1, C203.1, C209.1, C210.1, C216.1, C217.1, C223.1, C224.1, C230.1, C231.1, C237.1, C238.1, C244.1, C245.1, C251.1, C252.1, RF_SW_1.8 (VDD), RF_SW_2.8 (VDD), RF_SW_3.8 (VDD), RF_SW_4.8 (VDD), RF_SW_5.8 (VDD), RF_SW_6.8 (VDD), RF_SW_7.8 (VDD), RF_SW_8.8 (VDD), RF_SW_9.8 (VDD), RF_SW_10.8 (VDD), RF_SW_11.8 (VDD), RF_SW_12.8 (VDD), RF_SW_13.8 (VDD), RF_SW_14.8 (VDD), RF_SW_15.8 (VDD), RF_SW_16.8 (VDD), U14.1 (CATHODE), U17.1 (CATHODE), U38.1 (CATHODE), U40.1 (CATHODE), U43.1 (CATHODE), U45.1 (CATHODE), U47.1 (CATHODE), U49.1 (CATHODE), U51.1 (CATHODE), U53.1 (CATHODE), U55.1 (CATHODE), U57.1 (CATHODE), U59.1 (CATHODE), U61.1 (CATHODE), U63.1 (CATHODE), U65.1 (CATHODE), U67.1 (CATHODE), U$1.8 (VDD); also elsewhere on the board
+5V0_0: C352.1, C353.1, U4.8 (VCC_2), U4.13 (VCC), U4.15 (ENB), U8.8 (VCC_2), U8.13 (VCC), U8.15 (ENB); also elsewhere on the board
+5V0_PA_1: ADTR1107_1.8 (VDD_PA), ADTR1107_2.8 (VDD_PA), ADTR1107_3.8 (VDD_PA), ADTR1107_4.8 (VDD_PA), ADTR1107_7.8 (VDD_PA); also elsewhere on the board
+5V0_PA_2: ADTR1107_5.8 (VDD_PA), ADTR1107_6.8 (VDD_PA), ADTR1107_8.8 (VDD_PA), ADTR1107_10.8 (VDD_PA), ADTR1107_12.8 (VDD_PA); also elsewhere on the board
+5V0_PA_3: ADTR1107_9.8 (VDD_PA), ADTR1107_11.8 (VDD_PA), ADTR1107_13.8 (VDD_PA), ADTR1107_14.8 (VDD_PA), ADTR1107_15.8 (VDD_PA), ADTR1107_16.8 (VDD_PA); also elsewhere on the board
-3V3_SW: ADTR1107_1.21 (VSS_SW), ADTR1107_2.21 (VSS_SW), ADTR1107_3.21 (VSS_SW), ADTR1107_4.21 (VSS_SW), ADTR1107_5.21 (VSS_SW), ADTR1107_6.21 (VSS_SW), ADTR1107_7.21 (VSS_SW), ADTR1107_8.21 (VSS_SW), ADTR1107_9.21 (VSS_SW), ADTR1107_10.21 (VSS_SW), ADTR1107_11.21 (VSS_SW), ADTR1107_12.21 (VSS_SW), ADTR1107_13.21 (VSS_SW), ADTR1107_14.21 (VSS_SW), ADTR1107_15.21 (VSS_SW), ADTR1107_16.21 (VSS_SW); also elsewhere on the board
-3V4: C66.1, C67.1, C73.1, C74.1, C79.1, C80.1, C130.1, C131.1, C137.1, C138.1, C145.1, C146.1, C152.1, C160.1, C167.1, C168.1, C174.1, C175.1, C200.1, C201.1, C207.1, C208.1, C214.1, C215.1, C221.1, C222.1, C228.1, C229.1, C235.1, C236.1, C242.1, C243.1, C249.1, C250.1, RF_SW_1.5 (VEE), RF_SW_2.5 (VEE), RF_SW_3.5 (VEE), RF_SW_4.5 (VEE), RF_SW_5.5 (VEE), RF_SW_6.5 (VEE), RF_SW_7.5 (VEE), RF_SW_8.5 (VEE), RF_SW_9.5 (VEE), RF_SW_10.5 (VEE), RF_SW_11.5 (VEE), RF_SW_12.5 (VEE), RF_SW_13.5 (VEE), RF_SW_14.5 (VEE), RF_SW_15.5 (VEE), RF_SW_16.5 (VEE), U15.2 (ANODE), U37.2 (ANODE), U39.2 (ANODE), U41.2 (ANODE), U44.2 (ANODE), U46.2 (ANODE), U48.2 (ANODE), U50.2 (ANODE), U52.2 (ANODE), U54.2 (ANODE), U56.2 (ANODE), U58.2 (ANODE), U60.2 (ANODE), U62.2 (ANODE), U64.2 (ANODE), U66.2 (ANODE), U68.2 (ANODE), U$1.5 (VEE); also elsewhere on the board
-5V0_ADAR12: ADAR1_.B11 (AVDD), ADAR2_.B11 (AVDD); also elsewhere on the board
-5V0_ADAR34: ADAR3_.B11 (AVDD), ADAR4_.B11 (AVDD); also elsewhere on the board
ADAR_1_CS_1V8: ADAR1_.M3 (CSB), R154.2; also elsewhere on the board
ADAR_2_CS_1V8: ADAR2_.M3 (CSB), R155.2; also elsewhere on the board
ADAR_3_CS_1V8: ADAR3_.M3 (CSB), R156.2; also elsewhere on the board
ADAR_4_CS_1V8: ADAR4_.M3 (CSB), R157.2; also elsewhere on the board
ADAR_RX_LOAD_1: ADAR1_.N2 (RX_LOAD), R47.2; also elsewhere on the board
ADAR_RX_LOAD_2: ADAR2_.N2 (RX_LOAD), R71.2; also elsewhere on the board
ADAR_RX_LOAD_3: ADAR3_.N2 (RX_LOAD), R74.2; also elsewhere on the board
ADAR_RX_LOAD_4: ADAR4_.N2 (RX_LOAD), R77.2; also elsewhere on the board
ADAR_TR_1: ADAR1_.N6 (TR), R158.2; also elsewhere on the board
ADAR_TR_2: ADAR2_.N6 (TR), R159.2; also elsewhere on the board
ADAR_TR_3: ADAR3_.N6 (TR), R160.2; also elsewhere on the board
ADAR_TR_4: ADAR4_.N6 (TR), R161.2; also elsewhere on the board
ADAR_TX_LOAD_1: ADAR1_.N3 (TX_LOAD), R46.2; also elsewhere on the board
ADAR_TX_LOAD_2: ADAR2_.N3 (TX_LOAD), R70.2; also elsewhere on the board
ADAR_TX_LOAD_3: ADAR3_.N3 (TX_LOAD), R73.2; also elsewhere on the board
ADAR_TX_LOAD_4: ADAR4_.N3 (TX_LOAD), R76.2; also elsewhere on the board
ADC_CLK_IN_N: C2.1, R173.2, U1.45 (CLK-)
ADC_CLK_IN_P: C1.1, R173.1, U1.44 (CLK+)
ADC_D0_N: U1.3 (D0-); also elsewhere on the board
ADC_D0_P: U1.4 (D0+); also elsewhere on the board
ADC_D1_N: U1.5 (D1-); also elsewhere on the board
ADC_D1_P: U1.6 (D1+); also elsewhere on the board
ADC_D2_N: U1.9 (D2-); also elsewhere on the board
ADC_D2_P: U1.10 (D2+); also elsewhere on the board
ADC_D3_N: U1.11 (D3-); also elsewhere on the board
ADC_D3_P: U1.12 (D3+); also elsewhere on the board
ADC_D4_N: U1.13 (D4-); also elsewhere on the board
ADC_D4_P: U1.14 (D4+); also elsewhere on the board
ADC_D5_N: U1.15 (D5-); also elsewhere on the board
ADC_D5_P: U1.16 (D5+); also elsewhere on the board
ADC_D6_N: U1.17 (D6-); also elsewhere on the board
ADC_D6_P: U1.18 (D6+); also elsewhere on the board
ADC_D7_N: U1.19 (D7-); also elsewhere on the board
ADC_D7_P: U1.20 (D7+); also elsewhere on the board
ADC_DCO_N: U1.49 (DCO-); also elsewhere on the board
ADC_DCO_P: U1.50 (DCO+); also elsewhere on the board
ADC_IF_IN_N: C45.2, R1.2, R17.1
ADC_IF_IN_P: C44.2, R13.2, R16.2
ADC_OR_N: U1.21 (OR-); also elsewhere on the board
ADC_OR_P: U1.22 (OR+); also elsewhere on the board
ADC_PWRD: R36.2; also elsewhere on the board
AMP_IF_IN_N: C48.1, C52.2, R21.1
AMP_IF_IN_P: C49.2, C51.2, R20.2
AMP_IN_N: C57.1, L10.1, R165.1
AMP_IN_P: C58.2, L9.1, R166.1
ANT1_1: ADTR1107_3.17 (ANT), C72.2
ANT1_2: ADTR1107_7.17 (ANT), C151.2
ANT1_3: ADTR1107_10.17 (ANT), C206.2
ANT1_4: ADTR1107_14.17 (ANT), C234.2
ANT2_1: ADTR1107_1.17 (ANT), C129.2
ANT2_2: ADTR1107_5.17 (ANT), C166.2
ANT2_3: ADTR1107_12.17 (ANT), C213.2
ANT2_4: ADTR1107_16.17 (ANT), C241.2
ANT3_1: ADTR1107_2.17 (ANT), C136.2
ANT3_2: ADTR1107_6.17 (ANT), C173.2
ANT3_3: ADTR1107_11.17 (ANT), C220.2
ANT3_4: ADTR1107_15.17 (ANT), C248.2
ANT4_1: ADTR1107_4.17 (ANT), C144.2
ANT4_2: ADTR1107_8.17 (ANT), C199.2
ANT4_3: ADTR1107_9.17 (ANT), C227.2
ANT4_4: ADTR1107_13.17 (ANT), C255.2
DAC_0: R30.1; also elsewhere on the board
DAC_1: R29.1; also elsewhere on the board
DAC_2: R28.1; also elsewhere on the board
DAC_3: R27.1; also elsewhere on the board
DAC_4: R26.1; also elsewhere on the board
DAC_5: R25.1; also elsewhere on the board
DAC_6: R24.1; also elsewhere on the board
DAC_7: R23.1; also elsewhere on the board
DAC_ACOM: L7.1, U3.20 (ACOM)
DAC_AVDD: C39.2, L6.1, U3.16 (REFLO), U3.24 (AVDD)
DAC_CLOCK: J20.1, R31.2, U3.28 (CLOCK)
DAC_IOUT_F_N: C59.2, L27.2, U5.3 (IF)
DAC_IOUT_F_P: C59.1, L26.2, U5.2 (IF+)
DAC_IOUT_N: C127.2, C308.1, L25.1, R115.2, U3.21 (IOUTB)
DAC_IOUT_P: C127.1, C309.1, L22.1, R116.2, U3.22 (IOUTA)
DAC_SLEEP: R117.2, U3.15 (SLEEP); also elsewhere on the board
DET1_1: ADAR1_.N13 (DET1), ADTR1107_3.12 (CPLR_OUT)
DET1_2: ADAR2_.N13 (DET1), ADTR1107_7.12 (CPLR_OUT)
DET1_3: ADAR3_.N13 (DET1), ADTR1107_10.12 (CPLR_OUT)
DET1_4: ADAR4_.N13 (DET1), ADTR1107_14.12 (CPLR_OUT)
DET2_1: ADAR1_.G13 (DET2), ADTR1107_1.12 (CPLR_OUT)
DET2_2: ADAR2_.G13 (DET2), ADTR1107_5.12 (CPLR_OUT)
DET2_3: ADAR3_.G13 (DET2), ADTR1107_12.12 (CPLR_OUT)
DET2_4: ADAR4_.G13 (DET2), ADTR1107_16.12 (CPLR_OUT)
DET3_1: ADAR1_.A1 (DET3), ADTR1107_2.12 (CPLR_OUT)
DET3_2: ADAR2_.A1 (DET3), ADTR1107_6.12 (CPLR_OUT)
DET3_3: ADAR3_.A1 (DET3), ADTR1107_11.12 (CPLR_OUT)
DET3_4: ADAR4_.A1 (DET3), ADTR1107_15.12 (CPLR_OUT)
DET4_1: ADAR1_.G1 (DET4), ADTR1107_4.12 (CPLR_OUT)
DET4_2: ADAR2_.G1 (DET4), ADTR1107_8.12 (CPLR_OUT)
DET4_3: ADAR3_.G1 (DET4), ADTR1107_9.12 (CPLR_OUT)
DET4_4: ADAR4_.G1 (DET4), ADTR1107_13.12 (CPLR_OUT)
LNA_BIAS_1: ADAR1_.A11 (LNA_BIAS), ADTR1107_1.23 (VGG_LNA), ADTR1107_2.23 (VGG_LNA), ADTR1107_3.23 (VGG_LNA), ADTR1107_4.23 (VGG_LNA)
LNA_BIAS_2: ADAR2_.A11 (LNA_BIAS), ADTR1107_5.23 (VGG_LNA), ADTR1107_6.23 (VGG_LNA), ADTR1107_7.23 (VGG_LNA), ADTR1107_8.23 (VGG_LNA)
LNA_BIAS_3: ADAR3_.A11 (LNA_BIAS), ADTR1107_9.23 (VGG_LNA), ADTR1107_10.23 (VGG_LNA), ADTR1107_11.23 (VGG_LNA), ADTR1107_12.23 (VGG_LNA)
LNA_BIAS_4: ADAR4_.A11 (LNA_BIAS), ADTR1107_13.23 (VGG_LNA), ADTR1107_14.23 (VGG_LNA), ADTR1107_15.23 (VGG_LNA), ADTR1107_16.23 (VGG_LNA)
M3S_VCTRL: RF_SW_1.6 (VCTRL), RF_SW_2.6 (VCTRL), RF_SW_3.6 (VCTRL), RF_SW_4.6 (VCTRL), RF_SW_5.6 (VCTRL), RF_SW_6.6 (VCTRL), RF_SW_7.6 (VCTRL), RF_SW_8.6 (VCTRL), RF_SW_9.6 (VCTRL), RF_SW_10.6 (VCTRL), RF_SW_11.6 (VCTRL), RF_SW_12.6 (VCTRL), RF_SW_13.6 (VCTRL), RF_SW_14.6 (VCTRL), RF_SW_15.6 (VCTRL), RF_SW_16.6 (VCTRL), U$1.6 (VCTRL); also elsewhere on the board
MIX_RX_EN: U13.7 (EN); also elsewhere on the board
MIX_RX_N: C270.2, U13.3 (IF)
MIX_RX_P: C268.2, U13.2 (IF+)
MIX_TX_EN: U5.7 (EN); also elsewhere on the board
unnamed: C2.2, J21.2
unnamed: C1.2, J21.1
unnamed: C3.1, R1.1, U1.36 (VIN-)
unnamed: C43.2, R15.2, U4.1 (RDP)
unnamed: R23.2, U3.1 (DB7)
unnamed: R24.2, U3.2 (DB6)
unnamed: R25.2, U3.3 (DB5)
unnamed: R26.2, U3.4 (DB4)
unnamed: R27.2, U3.5 (DB3)
unnamed: C43.1, R15.1, U4.4 (RDN)
unnamed: R28.2, U3.6 (DB2)
unnamed: R38.2, U1.31 (VREF)
unnamed: R29.2, U3.7 (DB1)
unnamed: R30.2, U3.8 (DB0)
unnamed: C272.1, U5.11 (LO)
unnamed: C83.2, U$1.3 (RFOUT1)
unnamed: R33.1, U3.18 (FSADJ)
unnamed: C272.2, J23.1
unnamed: C274.2, J22.1
unnamed: C85.1, U$1.15 (RFC)
unnamed: R14.1, U4.3 (RGN)
unnamed: C38.1, U3.23 (COMP2)
unnamed: C84.1, U$1.10 (RFOUT2)
unnamed: ADAR1_.B3 (PA_ON), R45.1
unnamed: ADAR2_.B3 (PA_ON), R48.1
unnamed: R36.1, R37.2, U1.29 (PWDN)
unnamed: ADAR2_.M9 (CREG2), C87.1
unnamed: C3.2, R13.1, U1.35 (VIN+)
unnamed: ADAR2_.M8 (CREG1), C86.1
unnamed: ADAR2_.N10 (CREG3), C92.1
unnamed: R14.2, U4.2 (RGP)
unnamed: R19.1, U4.5 (VIN)
unnamed: R18.2, U4.16 (VIP)
unnamed: C47.2, U4.14 (VCM)
unnamed: ADAR2_.N9 (CREG4), C93.1
unnamed: C44.1, U4.11 (VOP)
unnamed: ADAR3_.B3 (PA_ON), R72.1
unnamed: C61.1, L3.2
unnamed: ADAR3_.M9 (CREG2), C95.1
unnamed: ADAR3_.M8 (CREG1), C94.1
unnamed: ADAR3_.N10 (CREG3), C96.1
unnamed: C62.1, L4.2
unnamed: ADAR3_.N9 (CREG4), C97.1
unnamed: ADAR4_.B3 (PA_ON), R75.1
unnamed: C45.1, U4.10 (VON)
unnamed: ADAR1_.N9 (CREG4), C91.1
unnamed: C46.2, R16.1, R17.2
unnamed: ADAR4_.M9 (CREG2), C99.1
unnamed: ADAR4_.M8 (CREG1), C98.1
unnamed: ADAR4_.N10 (CREG3), C100.1
unnamed: C64.1, L9.2
unnamed: C274.1, U13.11 (LO)
unnamed: C48.2, R19.2
unnamed: C70.2, RF_SW_3.3 (RFOUT1)
unnamed: ADAR4_.N9 (CREG4), C101.1
unnamed: ADAR1_.M9 (CREG2), C89.1
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

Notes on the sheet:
TX CHAIN: DAC -> RECONSTRUCTION FILTER -> MIXER -> STUB BPF
RX CHAIN: ADC <- 2nd STAGE AMPLIFIER(10dB) <- 1st STAGE AMPLIFIER(15dB) <- IF LPF <- MIXER <- STUB BPF
TX RX RF SWITCH <-> SPLITTER/COMBINER

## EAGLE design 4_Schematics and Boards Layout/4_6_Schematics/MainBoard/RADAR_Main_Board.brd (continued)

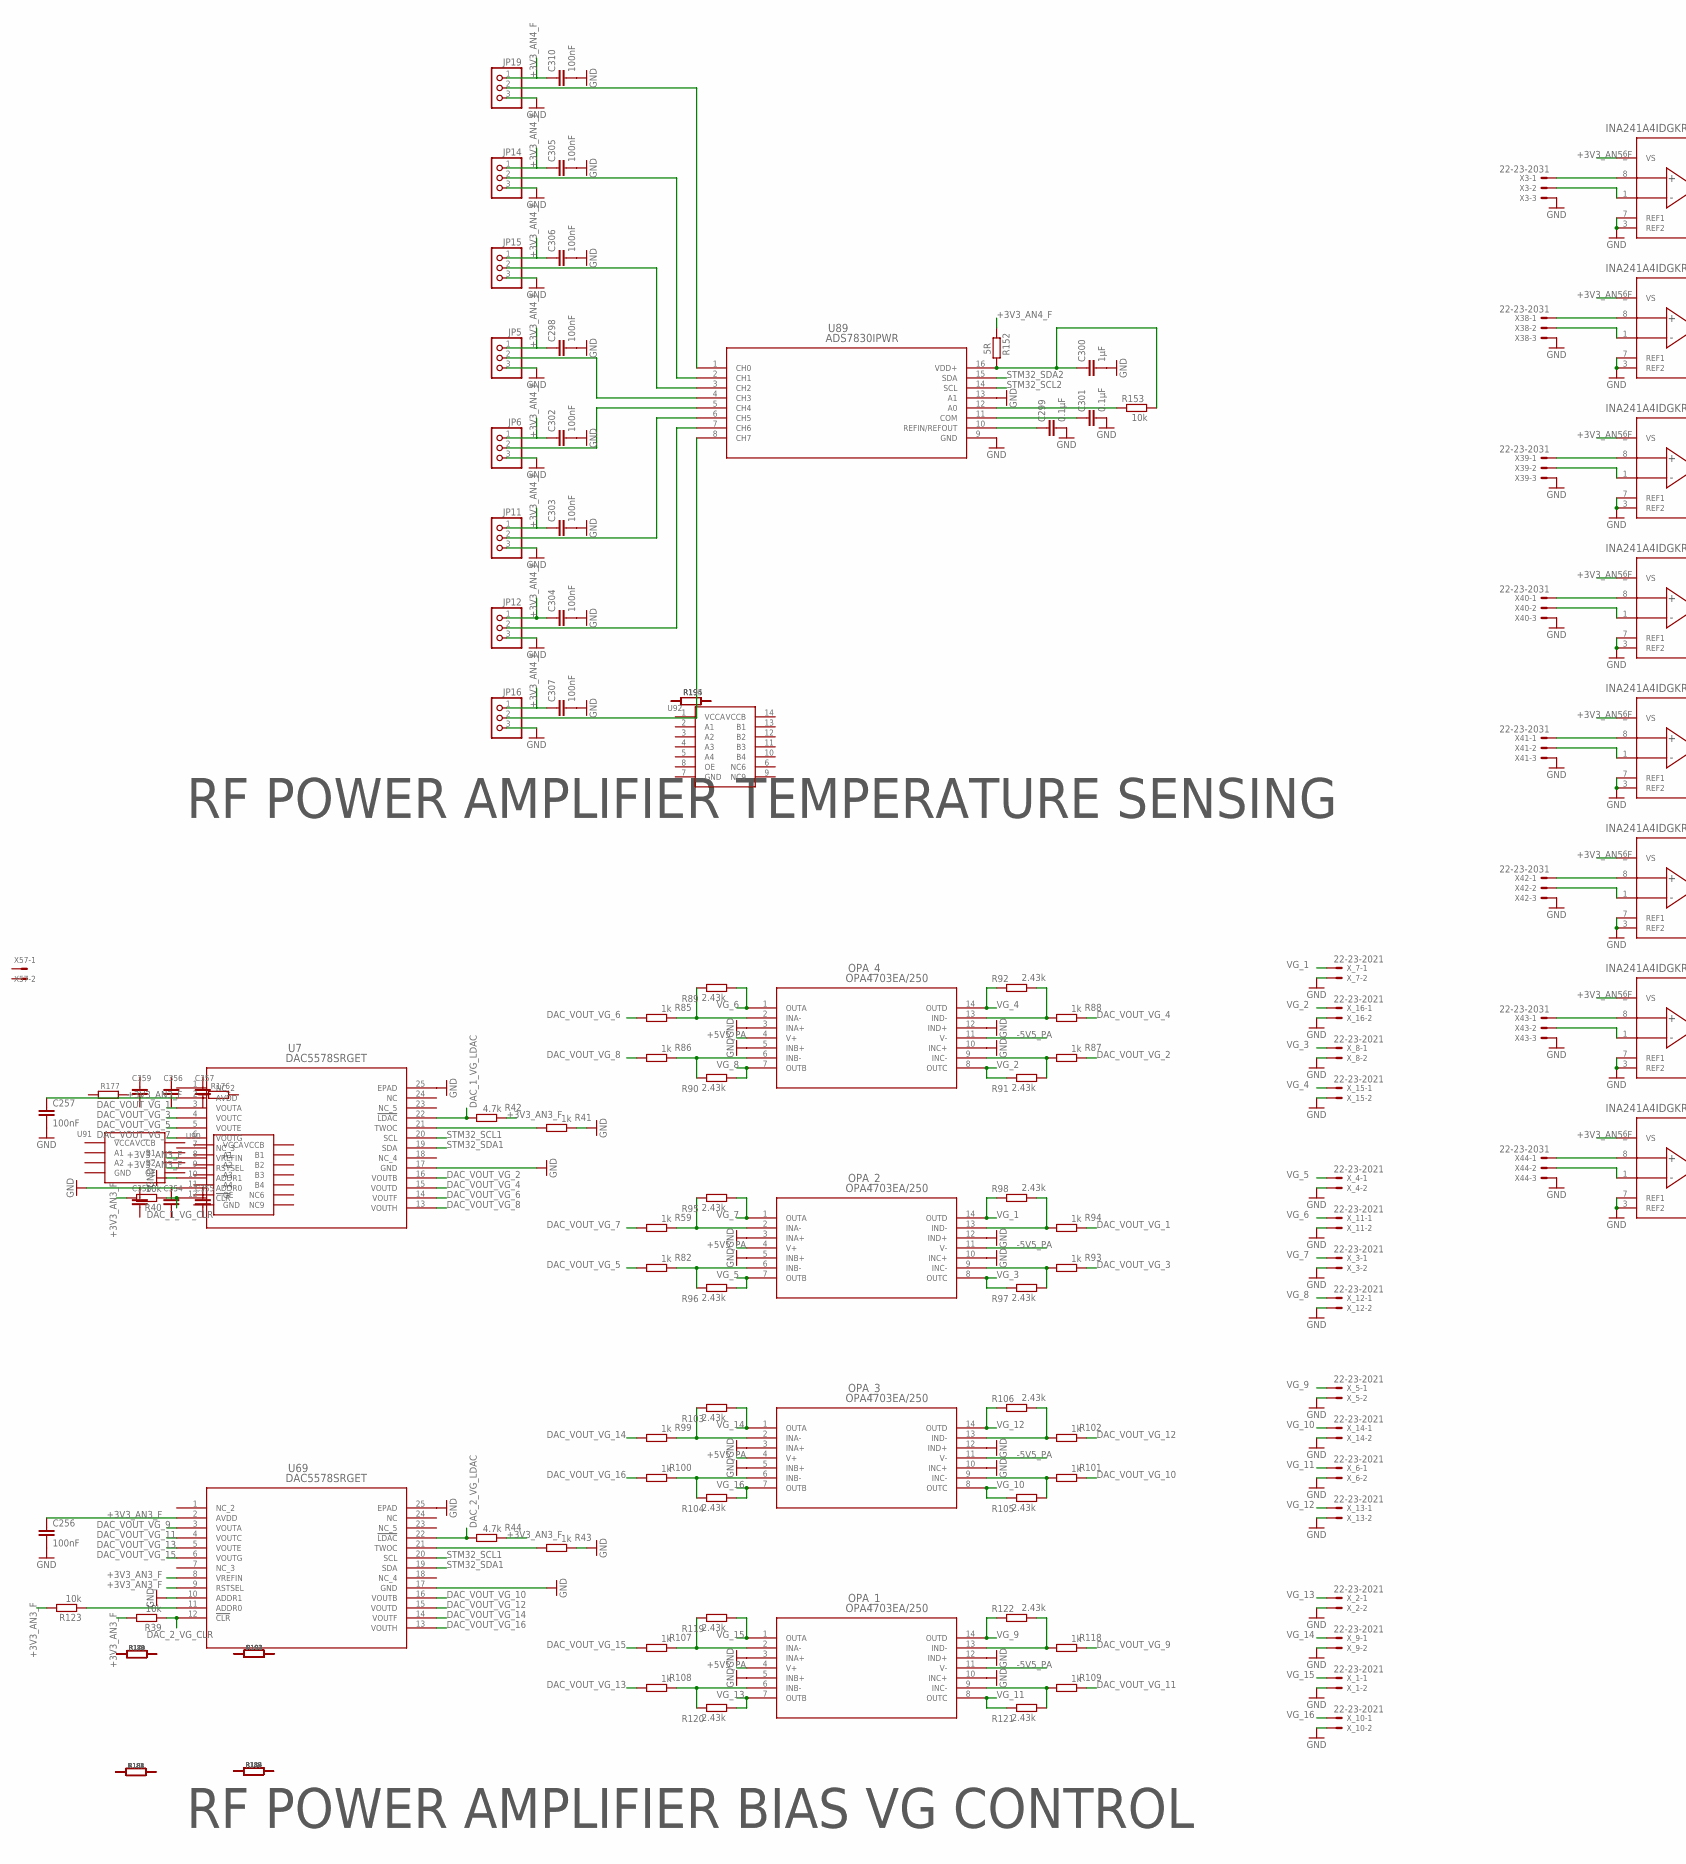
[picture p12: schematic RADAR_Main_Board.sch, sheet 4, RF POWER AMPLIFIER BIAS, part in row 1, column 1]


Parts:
C256, C257, C298, C302, C303, C304, C305, C306, C307, C310: 100nF; C0201
C261, C263, C265, C267, C269, C271, C273, C275, C280, C282, C284, C286, C288, C290, C292, C294: 4.7nF; C0201
C276, C296, C300: 1µF; C0201
C277, C278, C295, C297, C299, C301: 0.1µF; C0201
C354, C355, C356, C357, C358, C359: 0.1uF; C0201
JP5, JP6, JP11, JP12, JP14, JP15, JP16, JP19: PINHD-1X3; 1X03
OPA_1, OPA_2, OPA_3, OPA_4: OPA4703EA/250; PW14
R39, R40, R123, R151, R153, R176, R177, R178, R179, R180, R181, R182, R183, R184, R185, R186, R187, R188, R189, R190, R191, R192, R193, R194: 10k; R0201
R41, R43, R59, R82, R85, R86, R87, R88, R93, R94, R99, R100, R101, R102, R107, R108, R109, R118, R124, R125, R126, R127, R128, R129, R130, R131, R133, R134, R135, R136, R137, R147, R148, R149: 1k; R0201
R42, R44, R195: 4.7k; R0201
R89, R90, R91, R92, R95, R96, R97, R98, R103, R104, R105, R106, R119, R120, R121, R122: 2.43k; R0201
R132, R150, R152: 5R; R0201
U7, U69: DAC5578SRGET; RGE24_2P7X2P7
U10, U88, U89: ADS7830IPWR; PW16
U11, U73, U74, U75, U76, U77, U78, U79, U80, U81, U82, U83, U84, U85, U86, U87: INA241A4IDGKRDGK0008A-MFG; DGK0008A-MFG
U92: TXS0104EPWR; PW0014A-MFG
X3, X38, X39, X40, X41, X42, X43, X44, X45, X46, X47, X48, X49, X50, X51, X52: 22-23-2031
X_1, X_2, X_3, X_4, X_5, X_6, X_7, X_8, X_9, X_10, X_11, X_12, X_13, X_14, X_15, X_16: 22-23-2021

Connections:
+1V8_FPGA: U92.VCCA; also elsewhere on the board
+3V3: U92.VCCB; also elsewhere on the board
+3V3_AN3_F: C256.1, C257.1, R39.2, R40.2, R42.1, R44.1, R123.2, U7.2 (AVDD), U7.8 (VREFIN), U7.9 (RSTSEL), U69.2 (AVDD), U69.8 (VREFIN), U69.9 (RSTSEL); also elsewhere on the board
+3V3_AN4_F: C298.1, C302.1, C303.1, C304.1, C305.1, C306.1, C307.1, C310.1, JP5.1, JP6.1, JP11.1, JP12.1, JP14.1, JP15.1, JP16.1, JP19.1, R132.1, R150.1, R152.1; also elsewhere on the board
+3V3_AN5_F: U11.6 (VS), U73.6 (VS), U74.6 (VS), U75.6 (VS), U76.6 (VS), U77.6 (VS), U78.6 (VS), U79.6 (VS); also elsewhere on the board
+3V3_AN6_F: U80.6 (VS), U81.6 (VS), U82.6 (VS), U83.6 (VS), U84.6 (VS), U85.6 (VS), U86.6 (VS), U87.6 (VS); also elsewhere on the board
+5V5_PA: OPA_1.4 (V+), OPA_2.4 (V+), OPA_3.4 (V+), OPA_4.4 (V+); also elsewhere on the board
ADC_SPI_CSB: U92.A1; also elsewhere on the board
ADC_SPI_SDIO: U92.A3; also elsewhere on the board
DAC_1_VG_CLR: R40.1, U7.12 (!CLR); also elsewhere on the board
DAC_1_VG_LDAC: R42.2, U7.22 (!LDAC); also elsewhere on the board
DAC_2_VG_CLR: R39.1, U69.12 (!CLR); also elsewhere on the board
DAC_2_VG_LDAC: R44.2, U69.22 (!LDAC); also elsewhere on the board
DAC_VOUT_VG_1: R94.1, U7.3 (VOUTA)
DAC_VOUT_VG_2: R87.1, U7.16 (VOUTB)
DAC_VOUT_VG_3: R93.1, U7.4 (VOUTC)
DAC_VOUT_VG_4: R88.1, U7.15 (VOUTD)
DAC_VOUT_VG_5: R82.2, U7.5 (VOUTE)
DAC_VOUT_VG_6: R85.2, U7.14 (VOUTF)
DAC_VOUT_VG_7: R59.2, U7.6 (VOUTG)
DAC_VOUT_VG_8: R86.2, U7.13 (VOUTH)
DAC_VOUT_VG_9: R118.1, U69.3 (VOUTA)
DAC_VOUT_VG_10: R101.1, U69.16 (VOUTB)
DAC_VOUT_VG_11: R109.1, U69.4 (VOUTC)
DAC_VOUT_VG_12: R102.1, U69.15 (VOUTD)
DAC_VOUT_VG_13: R108.2, U69.5 (VOUTE)
DAC_VOUT_VG_14: R99.2, U69.14 (VOUTF)
DAC_VOUT_VG_15: R107.2, U69.6 (VOUTG)
DAC_VOUT_VG_16: R100.2, U69.13 (VOUTH)
MCU_ADC_CSB: U92.B1; also elsewhere on the board
MCU_ADC_SCLK: U92.B2; also elsewhere on the board
MCU_ADC_SDIO: U92.B3; also elsewhere on the board
unnamed: R123.1, U69.11 (ADDR0)
unnamed: R43.2, U69.21 (TWOC)
unnamed: OPA_4.2 (INA-), R85.1, R89.1
unnamed: U11.8 (IN+), X3.1
unnamed: OPA_4.6 (INB-), R86.1, R90.1
unnamed: U11.1 (IN-), X3.2
unnamed: R124.2, U11.5 (OUT)
unnamed: C261.2, R124.1, U10.1 (CH0)
unnamed: U73.8 (IN+), X38.1
unnamed: OPA_4.9 (INC-), R87.2, R91.2
unnamed: U73.1 (IN-), X38.2
unnamed: R125.2, U73.5 (OUT)
unnamed: OPA_4.13 (IND-), R88.2, R92.2
unnamed: C263.2, R125.1, U10.2 (CH1)
unnamed: U74.8 (IN+), X39.1
unnamed: U74.1 (IN-), X39.2
unnamed: R126.2, U74.5 (OUT)
unnamed: R41.2, U7.21 (TWOC)
unnamed: OPA_2.2 (INA-), R59.1, R95.1
unnamed: C265.2, R126.1, U10.3 (CH2)
unnamed: OPA_2.6 (INB-), R82.1, R96.1
unnamed: U75.8 (IN+), X40.1
unnamed: U75.1 (IN-), X40.2
unnamed: R127.2, U75.5 (OUT)
unnamed: OPA_2.9 (INC-), R93.2, R97.2
unnamed: C267.2, R127.1, U10.4 (CH3)
unnamed: U76.8 (IN+), X41.1
unnamed: OPA_2.13 (IND-), R94.2, R98.2
unnamed: U76.1 (IN-), X41.2
unnamed: R128.2, U76.5 (OUT)
unnamed: C269.2, R128.1, U10.5 (CH4)
unnamed: U77.8 (IN+), X42.1
unnamed: U77.1 (IN-), X42.2
unnamed: R129.2, U77.5 (OUT)
unnamed: OPA_3.2 (INA-), R99.1, R103.1
unnamed: C271.2, R129.1, U10.6 (CH5)
unnamed: OPA_3.6 (INB-), R100.1, R104.1
unnamed: U78.8 (IN+), X43.1
unnamed: U78.1 (IN-), X43.2
unnamed: R130.2, U78.5 (OUT)
unnamed: OPA_3.9 (INC-), R101.2, R105.2
unnamed: C273.2, R130.1, U10.7 (CH6)
unnamed: U79.8 (IN+), X44.1
unnamed: OPA_3.13 (IND-), R102.2, R106.2
unnamed: U79.1 (IN-), X44.2
unnamed: R131.2, U79.5 (OUT)
unnamed: C275.2, R131.1, U10.8 (CH7)
unnamed: C277.1, U10.10 (REFIN/REFOUT)
unnamed: C276.1, R132.2, U10.16 (VDD+)
unnamed: C278.1, U10.11 (COM)
unnamed: OPA_1.2 (INA-), R107.1, R119.1
unnamed: U80.8 (IN+), X45.1
unnamed: OPA_1.6 (INB-), R108.1, R120.1
unnamed: U80.1 (IN-), X45.2
unnamed: R133.2, U80.5 (OUT)
unnamed: C280.2, R133.1, U88.1 (CH0)
unnamed: OPA_1.9 (INC-), R109.2, R121.2
unnamed: U81.8 (IN+), X46.1
unnamed: U81.1 (IN-), X46.2
unnamed: OPA_1.13 (IND-), R118.2, R122.2
unnamed: R134.2, U81.5 (OUT)
unnamed: C282.2, R134.1, U88.2 (CH1)
unnamed: U82.8 (IN+), X47.1
unnamed: U82.1 (IN-), X47.2
unnamed: R135.2, U82.5 (OUT)
unnamed: C284.2, R135.1, U88.3 (CH2)
unnamed: U83.8 (IN+), X48.1
unnamed: U83.1 (IN-), X48.2
unnamed: R136.2, U83.5 (OUT)
unnamed: C286.2, R136.1, U88.4 (CH3)
unnamed: U84.8 (IN+), X49.1
unnamed: U84.1 (IN-), X49.2
unnamed: R137.2, U84.5 (OUT)
unnamed: C288.2, R137.1, U88.5 (CH4)
unnamed: U85.8 (IN+), X50.1
unnamed: U85.1 (IN-), X50.2
unnamed: R147.2, U85.5 (OUT)
unnamed: C290.2, R147.1, U88.6 (CH5)
unnamed: U86.8 (IN+), X51.1
unnamed: U86.1 (IN-), X51.2
unnamed: R148.2, U86.5 (OUT)
unnamed: C292.2, R148.1, U88.7 (CH6)
unnamed: U87.8 (IN+), X52.1
unnamed: U87.1 (IN-), X52.2
unnamed: R149.2, U87.5 (OUT)
unnamed: C294.2, R149.1, U88.8 (CH7)
unnamed: C295.1, U88.10 (REFIN/REFOUT)
unnamed: C296.1, R150.2, R151.2, U88.16 (VDD+)
unnamed: C297.1, U88.11 (COM)
unnamed: R151.1, U88.13 (A1)
unnamed: R153.1, U89.12 (A0)
unnamed: C299.1, U89.10 (REFIN/REFOUT)
unnamed: C300.1, R152.2, R153.2, U89.16 (VDD+)
unnamed: C301.1, U89.11 (COM)
N$U92_OE: U92.OE; also elsewhere on the board
STM32_SCL1: U7.20 (SCL), U69.20 (SCL); also elsewhere on the board
STM32_SCL2: U10.14 (SCL), U88.14 (SCL), U89.14 (SCL); also elsewhere on the board
STM32_SDA1: U7.19 (SDA), U69.19 (SDA); also elsewhere on the board
STM32_SDA2: U10.15 (SDA), U88.15 (SDA), U89.15 (SDA); also elsewhere on the board
TEMP_1: JP19.2, U89.1 (CH0); also elsewhere on the board
TEMP_2: JP14.2, U89.2 (CH1); also elsewhere on the board
TEMP_3: JP15.2, U89.3 (CH2); also elsewhere on the board
TEMP_4: JP5.2, U89.4 (CH3); also elsewhere on the board
TEMP_5: JP6.2, U89.5 (CH4); also elsewhere on the board
TEMP_6: JP11.2, U89.6 (CH5); also elsewhere on the board
TEMP_7: JP12.2, U89.7 (CH6); also elsewhere on the board
TEMP_8: JP16.2, U89.8 (CH7); also elsewhere on the board
VG_1: OPA_2.14 (OUTD), R98.1, R178.1, X_7.1
VG_2: OPA_4.8 (OUTC), R91.1, R190.1, X_16.1
VG_3: OPA_2.8 (OUTC), R97.1, R179.1, X_8.1
VG_4: OPA_4.14 (OUTD), R92.1, R191.1, X_15.1
VG_5: OPA_2.7 (OUTB), R96.2, R180.1, X_4.1
VG_6: OPA_4.1 (OUTA), R89.2, R192.1, X_11.1
VG_7: OPA_2.1 (OUTA), R95.2, R181.1, X_3.1
VG_8: OPA_4.7 (OUTB), R90.2, R193.1, X_12.1
VG_9: OPA_1.14 (OUTD), R122.1, R182.1, X_5.1
VG_10: OPA_3.8 (OUTC), R105.1, R186.1, X_14.1
VG_11: OPA_1.8 (OUTC), R121.1, R183.1, X_6.1
VG_12: OPA_3.14 (OUTD), R106.1, R187.1, X_13.1
VG_13: OPA_1.7 (OUTB), R120.2, R184.1, X_2.1
VG_14: OPA_3.1 (OUTA), R103.2, R188.1, X_9.1
VG_15: OPA_1.1 (OUTA), R119.2, R185.1, X_1.1
VG_16: OPA_3.7 (OUTB), R104.2, R189.1, X_10.1

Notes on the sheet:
RF POWER AMPLIFIER IDQ_ID CURRENT SENSOR
RF POWER AMPLIFIER BIAS VG CONTROL
RF POWER AMPLIFIER TEMPERATURE SENSING

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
Board: 10 copper layers, 836 parts (0 on the bottom side), 668 nets.

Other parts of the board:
R196, R197, R198, R199, R200, R201, R202, R203: 10k; R0201
U90: TXS0104EPWR; PW0014A-MFG
U91: TXS0102DCUR; DCU0008A-MFG
X5, X7, X14: 22-23-2041
X6, X11, X13, X15, X19, X22: 22-23-2031
X25, X26, X27, X57: 22-23-2021

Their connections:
+2V5_FPGA: U90.1, U91.3, X57.1; also elsewhere on the board
+3V3_AN4_F: R196.2, R197.2, R198.2, R199.2, R200.2, R201.2, R202.2, R203.2; also elsewhere on the board
+3V3_FPGA: U90.14, U91.7; also elsewhere on the board
+5V0_PA_1: X14.1; also elsewhere on the board
+5V0_PA_2: X5.1; also elsewhere on the board
+5V0_PA_3: X7.1; also elsewhere on the board
-3V3_SW: X6.1; also elsewhere on the board
-3V4: X11.1, X22.1; also elsewhere on the board
-5V0_ADAR12: X13.1; also elsewhere on the board
-5V0_ADAR34: X15.1; also elsewhere on the board
-5V5_PA: X19.1; also elsewhere on the board
FLASH_DQ0_F: U90.13; also elsewhere on the board
FLASH_DQ1_F: U90.12; also elsewhere on the board
FLASH_DQ2_F: U90.11; also elsewhere on the board
FLASH_DQ3_F: U90.10; also elsewhere on the board
FLASH_NCS_F: U91.8; also elsewhere on the board
FLASH_NRST_F: U91.1; also elsewhere on the board
FPGA_FLASH_DQ0: U90.2; also elsewhere on the board
FPGA_FLASH_DQ1: U90.3; also elsewhere on the board
FPGA_FLASH_DQ2: U90.4; also elsewhere on the board
FPGA_FLASH_DQ3: U90.5; also elsewhere on the board
FPGA_FLASH_NCS: U91.5; also elsewhere on the board
FPGA_FLASH_NRST: U91.4; also elsewhere on the board
N$U90_OE: U90.8; also elsewhere on the board
N$U91_OE: U91.6; also elsewhere on the board
PG_2V5_FPGA: X27.1; also elsewhere on the board
PG_3V3_ADTR: X25.1; also elsewhere on the board
PG_3V3_XO: X26.1; also elsewhere on the board
TEMP_1: R196.1; also elsewhere on the board
TEMP_2: R197.1; also elsewhere on the board
TEMP_3: R198.1; also elsewhere on the board
TEMP_4: R199.1; also elsewhere on the board
TEMP_5: R200.1; also elsewhere on the board
TEMP_6: R201.1; also elsewhere on the board
TEMP_7: R202.1; also elsewhere on the board
TEMP_8: R203.1; also elsewhere on the board

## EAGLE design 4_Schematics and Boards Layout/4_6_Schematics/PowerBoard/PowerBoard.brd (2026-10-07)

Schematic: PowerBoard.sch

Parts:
C1, C6, C12, C18, C29, C30, C36, C42, C54, C60, C66, C71, C76, C77, C83, C89, C109, C119, C129, C144, C154: 0.1µF; C0805
C2, C3, C7, C8, C11, C13, C14, C17, C19, C20, C23, C31, C32, C35, C37, C38, C41, C43, C44, C47, C48, C49, C55, C56, C59, C61, C62, C65, C67, C68, C72, C73, C78, C79, C82, C84, C85, C88, C90, C91, C110, C111, C120, C121, C130, C131, C145, C146, C149, C155, C156, C159, C164, C165, C169, C170, C171, C172: 22µF; C0603
C4, C5, C9, C10, C15, C16, C21, C22, C24, C25, C28, C33, C34, C39, C40, C45, C46, C50, C51, C52, C53, C57, C58, C63, C64, C69, C70, C74, C75, C80, C81, C86, C87, C92, C93, C94, C95, C108, C112, C113, C114, C115, C118, C122, C123, C124, C125, C128, C132, C133, C134, C135, C138, C139, C140, C143, C147, C148, C157, C158: 10µF; C0805
C26, C27, C106, C107, C116, C117, C126, C127, C136, C137, C141, C142: 1µF; C0805
C96, C97, C98, C99, C100, C101, C102, C103, C104, C105, C173, C174: T521W476M020ATE045; T521W
C150, C152, C160, C162, C167, C168: 10nF; C0603
C151, C153, C161, C163, C166: 10µF; C0603
R1: 3.09k; M0805
R2, R4, R6, R8, R10, R12, R14, R16, R18, R20, R22, R24, R26, R28, R30, R32, R34, R36, R38, R40, R42, R44, R46, R48, R50, R52, R56, R61, R62, R63: 10k; M0805
R3: 13.7k; M0805
R5, R7, R11, R13, R15, R19: 32.2k; M0805
R9, R35, R43, R47: 12k; M0805
R17, R23, R25, R27, R29, R31, R37, R41, R45, R51, R55: 56.2k; M0805
R21: 34.8k; M0805
R33: 61.9k; M0805
R39: 2k; M0805
R49: 23.4k; M0805
R53, R57: 35.7k; M0805
R54, R58, R60: 11.5k; M0805
R59: 24.3k; M0805
SV1: MA10-2
TP1, TP2, TP3, TP4, TP5, TP6, TP7, TP8, TP9, TP10, TP11, TP12, TP13, TP14, TP15: S1751-46
U1, U2, U3, U4, U6, U7, U8, U9, U10, U11, U12, U13, U14, U15, U16, U17, U24, U26, U28, U31, U33: TPS562208DDCT; DDC0006A_N
U5, U23, U25, U27, U29, U30: ADM7151ACPZ-04-R7; CP_8_11_ADI
U18, U19, U20, U21, U22: LM2662MX/NOPB; M08A
U32, U34, U35: TPS7A8300RGRR; RGR20_2P05X2P05_TEX
U$1, U$2: 2.2µH; IND_VLP8040T-1R0N_TDK
U$3, U$4, U$5, U$6, U$7, U$8, U$9, U$10, U$11, U$12, U$13, U$14, U$15, U$16, U$17, U$18, U$19, U$20, U$21: 3.3µH; IND_VLP8040T-1R0N_TDK
X1: AK300/2
X2, X3, X4, X5, X6, X7, X8, X9, X10, X11, X12, X13, X14, X15, X16, X17, X22, X23, X25, X26, X27, X28, X29, X30, X34, X35: 22-23-2021

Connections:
+1V0_FPGA: C2.1, C3.1, R1.2, TP1.1, TP1.2, U$1.1, X4.1
+1V8_CLOCK: C115.2, U25.2 (VOUT), X10.1
+1V8_FPGA: C7.1, C8.1, C11.1, R3.2, TP2.1, TP2.2, U$2.1, X5.1
+2V5_FPGA: C165.1, R59.1, TP3.1, TP3.2, U35.1 (OUT_2), U35.19 (OUT_3), U35.20 (OUT); also elsewhere on the board
+3V3: C13.1, C14.1, C17.1, R5.2, R61.2, R62.2, R63.2, TP4.1, TP4.2, U$3.1, X16.1
+3V3_ADAR12: C31.1, C32.1, C35.1, R11.2, TP8.1, TP8.2, U$6.1, X14.1
+3V3_ADAR34: C37.1, C38.1, C41.1, R13.2, U$7.1, X15.1
+3V3_ADTR: C149.1, R53.2, TP6.1, TP6.2, U32.1 (OUT_2), U32.19 (OUT_3), U32.20 (OUT), X34.1
+3V3_AN: C25.2, TP5.1, TP5.2, U5.2 (VOUT), X12.1
+3V3_CLOCK: C53.2, U23.2 (VOUT), X11.1
+3V3_FPGA: C19.1, C20.1, C23.1, R7.2, U$4.1, X27.1
+3V3_LO_1: C125.2, U27.2 (VOUT), X8.1
+3V3_LO_2: C135.2, U29.2 (VOUT), X7.1
+3V3_SW: C55.1, C56.1, C59.1, R19.2, U18.8 (V+), U$10.1, X29.1
+3V3_VDD_SW: C43.1, C44.1, C47.1, R15.2, U$8.1, X30.1
+3V3_XO: C159.1, C169.1, C170.1, C171.1, C172.1, R57.2, TP7.1, TP7.2, U34.1 (OUT_2), U34.19 (OUT_3), U34.20 (OUT), X35.1
+3V4: C61.1, C62.1, C65.1, R21.2, TP10.1, TP10.2, U19.8 (V+), U$11.1, X23.1
+5V0_0: C28.2, C67.1, C68.1, R23.2, U5.7 (EN), U5.8 (VIN), U$12.1, X22.1
+5V0_1: C48.1, C49.1, C108.2, R17.2, U23.8 (VIN), U$5.1, X2.1
+5V0_2: C110.1, C111.1, C118.2, R37.2, U25.8 (VIN), U$9.1, X9.1
+5V0_3: C120.1, C121.1, C128.2, R41.2, U27.7 (EN), U27.8 (VIN), U$18.1, X17.1
+5V0_4: C130.1, C131.1, C138.2, R45.2, U29.7 (EN), U29.8 (VIN), U$19.1, X25.1
+5V0_5: C155.1, C156.1, C163.1, C164.1, R55.2, U34.14 (EN), U34.15 (IN_2), U34.16 (IN_3), U34.17 (IN), U35.14 (EN), U35.15 (IN_2), U35.16 (IN_3), U35.17 (IN), U$21.1, X28.1
+5V0_ADAR: C72.1, C73.1, R25.2, U20.8 (V+), U21.8 (V+), U$13.1, X13.1; also elsewhere on the board
+5V0_ADTR: C145.1, C146.1, C153.1, R51.2, U32.15 (IN_2), U32.16 (IN_3), U32.17 (IN), U$20.1, X26.1
+5V0_LO: C140.2, U30.2 (VOUT), X6.1; also elsewhere on the board
+5V0_PA_1: C78.1, C79.1, R27.2, U$14.1; also elsewhere on the board
+5V0_PA_2: C84.1, C85.1, R29.2, U$15.1; also elsewhere on the board
+5V0_PA_3: C90.1, C91.1, R31.2, U$16.1; also elsewhere on the board
+5V5_PA: C82.1, C88.1, R33.2, TP12.1, TP12.2, U22.8 (V+), U$17.1, X3.1
-3V3_SW: C97.2 (-), U18.5 (OUT); also elsewhere on the board
-3V4: C99.2 (-), TP11.1, TP11.2, U19.5 (OUT); also elsewhere on the board
-5V0_ADAR12: C101.2 (-), TP9.1, TP9.2, U20.5 (OUT); also elsewhere on the board
-5V0_ADAR34: C103.2 (-), U21.5 (OUT); also elsewhere on the board
-5V5_PA: C105.2 (-), U22.5 (OUT); also elsewhere on the board
EN_+1V0_FPGA: SV1.1, U1.5 (EN)
EN_+1V8_CLOCK: SV1.8, U25.7 (EN)
EN_+1V8_FPGA: SV1.3, U2.5 (EN)
EN_+3V3_ADAR12: SV1.9, U6.5 (EN)
EN_+3V3_ADAR34: SV1.11, U7.5 (EN)
EN_+3V3_ADTR: SV1.13, U32.14 (EN)
EN_+3V3_CLOCK: SV1.10, U23.7 (EN)
EN_+3V3_FPGA: SV1.5, U4.5 (EN)
EN_+3V3_SW: SV1.15, U10.5 (EN)
EN_+3V3_VDD_SW: SV1.17, U8.5 (EN)
EN_+5V0_ADAR: SV1.7, U13.5 (EN)
EN_+5V0_PA1: SV1.19, U14.5 (EN)
EN_+5V0_PA2: SV1.2, U15.5 (EN)
EN_+5V0_PA3: SV1.4, U16.5 (EN)
EN_+5V5_PA: SV1.6, U17.5 (EN)
GND: C2.2, C3.2, C4.2, C5.2, C7.2, C8.2, C9.2, C10.2, C11.2, C13.2, C14.2, C15.2, C16.2, C17.2, C19.2, C20.2, C21.2, C22.2, C23.2, C24.1, C25.1, C26.1, C27.1, C28.1, C31.2, C32.2, C33.2, C34.2, C35.2, C37.2, C38.2, C39.2, C40.2, C41.2, C43.2, C44.2, C45.2, C46.2, C47.2, C48.2, C49.2, C50.2, C51.2, C52.1, C53.1, C55.2, C56.2, C57.2, C58.2, C59.2, C61.2, C62.2, C63.2, C64.2, C65.2, C67.2, C68.2, C69.2, C70.2, C72.2, C73.2, C74.2, C75.2, C78.2, C79.2, C80.2, C81.2, C82.2, C84.2, C85.2, C86.2, C87.2, C88.2, C90.2, C91.2, C92.2, C93.2, C94.2, C95.2, C97.1 (+), C99.1 (+), C101.1 (+), C103.1 (+), C105.1 (+), C106.1, C107.1, C108.1, C110.2, C111.2, C112.2, C113.2, C114.1, C115.1, C116.1, C117.1, C118.1, C120.2, C121.2, C122.2, C123.2, C124.1, C125.1, C126.1, C127.1, C128.1, C130.2, C131.2, C132.2, C133.2, C134.1, C135.1, C136.1, C137.1, C138.1, C139.1, C140.1, C141.1, C142.1, C143.1, C145.2, C146.2, C147.2, C148.2, C149.2, C151.2, C152.2, C153.2, C155.2, C156.2, C157.2, C158.2, C159.2, C161.2, C162.2, C163.2, C164.2, C165.2, C166.2, C167.2, C169.2, C170.2, C171.2, C172.2, R2.1, R4.1, R6.1, R8.1, R10.1, R12.1, R14.1, R16.1, R18.1, R20.1, R22.1, R24.1, R26.1, R28.1, R30.1, R32.1, R34.1, R36.1, R38.1, R40.1, R42.1, R44.1, R46.1, R48.1, R50.1, R52.1, R54.1, R56.1, R58.1, R60.2, SV1.12, SV1.14, SV1.16, SV1.18, SV1.20, U1.1 (GND), U2.1 (GND), U3.1 (GND), U4.1 (GND), U5.4 (GND), U5.9 (EPAD), U6.1 (GND), U7.1 (GND), U8.1 (GND), U9.1 (GND), U10.1 (GND), U11.1 (GND), U12.1 (GND), U13.1 (GND), U14.1 (GND), U15.1 (GND), U16.1 (GND), U17.1 (GND), U18.3 (GND), U18.6 (LV), U19.3 (GND), U19.6 (LV), U20.3 (GND), U20.6 (LV), U21.3 (GND), U21.6 (LV), U22.3 (GND), U22.6 (LV), U23.4 (GND), U23.9 (EPAD), U24.1 (GND), U25.4 (GND), U25.9 (EPAD), U26.1 (GND), U27.4 (GND), U27.9 (EPAD), U28.1 (GND), U29.4 (GND), U29.9 (EPAD), U30.4 (GND), U30.9 (EPAD), U31.1 (GND), U32.8 (GND_2), U32.18 (GND), U32.21 (EPAD), U33.1 (GND), U34.8 (GND_2), U34.18 (GND), U34.21 (EPAD), U35.8 (GND_2), U35.18 (GND), U35.21 (EPAD), X1.2, X2.2, X3.2, X4.2, X5.2, X6.2, X7.2, X8.2, X9.2, X10.2, X11.2, X12.2, X13.2, X14.2, X15.2, X16.2, X17.2, X22.2, X23.2, X25.2, X26.2, X27.2, X28.2, X29.2, X30.2, X34.2, X35.2; also elsewhere on the board
unnamed: C1.2, U1.2 (SW), U$1.2
unnamed: C1.1, U1.6 (VBST)
unnamed: C166.1, U35.12 (BIAS)
unnamed: C168.2, R59.2, R60.1, U35.3 (FB)
unnamed: C167.1, U35.13 (NR/SS)
unnamed: C168.1, U35.2 (SNS)
unnamed: C6.2, U2.2 (SW), U$2.2
unnamed: R1.1, R2.2, U1.4 (VFB)
unnamed: C6.1, U2.6 (VBST)
unnamed: R3.1, R4.2, U2.4 (VFB)
unnamed: C12.2, U3.2 (SW), U$3.2
unnamed: C12.1, U3.6 (VBST)
unnamed: R5.1, R6.2, U3.4 (VFB)
unnamed: C18.2, U4.2 (SW), U$4.2
unnamed: C18.1, U4.6 (VBST)
unnamed: R7.1, R8.2, U4.4 (VFB)
unnamed: C24.2, U5.1 (VREG)
unnamed: C139.2, U30.1 (VREG)
unnamed: C26.2, U5.3 (BYP)
unnamed: C30.2, U6.2 (SW), U$6.2
unnamed: C30.1, U6.6 (VBST)
unnamed: R11.1, R12.2, U6.4 (VFB)
unnamed: C36.2, U7.2 (SW), U$7.2
unnamed: C36.1, U7.6 (VBST)
unnamed: R13.1, R14.2, U7.4 (VFB)
unnamed: C42.2, U8.2 (SW), U$8.2
unnamed: C42.1, U8.6 (VBST)
unnamed: R15.1, R16.2, U8.4 (VFB)
unnamed: R9.1, R10.2, U5.5 (REF_SENSE)
unnamed: C29.2, U9.2 (SW), U$5.2
unnamed: C27.2, R9.2, U5.6 (REF)
unnamed: C54.2, U10.2 (SW), U$10.2
unnamed: C54.1, U10.6 (VBST)
unnamed: R19.1, R20.2, U10.4 (VFB)
unnamed: C60.2, U11.2 (SW), U$11.2
unnamed: C60.1, U11.6 (VBST)
unnamed: R21.1, R22.2, U11.4 (VFB)
unnamed: C66.2, U12.2 (SW), U$12.2
unnamed: C66.1, U12.6 (VBST)
unnamed: R23.1, R24.2, U12.4 (VFB)
unnamed: C71.2, U13.2 (SW), U$13.2
unnamed: C71.1, U13.6 (VBST)
unnamed: R25.1, R26.2, U13.4 (VFB)
unnamed: C77.2, U14.2 (SW), U$14.2
unnamed: C77.1, U14.6 (VBST)
unnamed: R27.1, R28.2, U14.4 (VFB)
unnamed: C83.2, U15.2 (SW), U$15.2
unnamed: C83.1, U15.6 (VBST)
unnamed: R29.1, R30.2, U15.4 (VFB)
unnamed: C89.2, U16.2 (SW), U$16.2
unnamed: C89.1, U16.6 (VBST)
unnamed: R31.1, R32.2, U16.4 (VFB)
unnamed: C76.2, U17.2 (SW), U$17.2
unnamed: C76.1, U17.6 (VBST)
unnamed: R33.1, R34.2, U17.4 (VFB)
unnamed: C98.1 (+), U19.2 (C1+)
unnamed: C98.2 (-), U19.4 (C1-)
unnamed: C96.1 (+), U18.2 (C1+)
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

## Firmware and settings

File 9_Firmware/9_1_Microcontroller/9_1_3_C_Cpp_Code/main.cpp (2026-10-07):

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
/* Includes ------------------------------------------------------------------*/
#include "main.h"
#include "usb_device.h"
#include "USBHandler.h"
#include "usbd_cdc_if.h"
#include "ADAR1000_Manager.h"
#include "ADAR1000_AGC.h"
#include "PA_SENSE.h"
#include "PA_BIAS_CAL.h"
#include "AgcPulseCounter.h"
extern "C" {
#include "ad9523.h"
#include "AD9523_VERIFY.h"
}
#include "no_os_delay.h"
#include "no_os_alloc.h"
#include "no_os_print_log.h"
#include "no_os_error.h"
#include "no_os_units.h"
#include "no_os_dma.h"
#include "no_os_spi.h"
#include "no_os_uart.h"
#include "no_os_util.h"
#include <stdint.h>
#include <errno.h>
#include <math.h>
#include <stdio.h>
#include <string.h>
#include <inttypes.h>
#include <iostream>
#include <vector>
#include "stm32_spi.h"
#include "stm32_delay.h"
extern "C" {
#include "um982_gps.h"
}
extern "C" {
#include "GY_85_HAL.h"
}
#include "BMP180.h"
extern "C" {
#include "platform_noos_stm32.h"
}
extern "C" {

#include "adf4382a_manager.h"
#include "adf4382.h"
#include "no_os_delay.h"
#include "no_os_error.h"
#include "diag_log.h"
}
#include <cmath>
#include "DAC5578.h"
#include "PA_GATE_BIAS.h"
#include "PA_BIAS_SEQUENCE.h"
#include "RAIL_FAULT.h"
#include "STROBE_ACK.h"
#include "FPGA_CONFIG.h"
#include "AD9484_SPI.h"
#include "PA_THERMAL.h"
#include "PA_SOAK.h"
#include "ADS7830.h"
#include "gps_handler.h"

#include "stm32f7xx_hal.h"




/* USER CODE BEGIN PD */


/* -------- GPIO index mapping for no-OS interface -------- */
#define GPIO_IDX_TX_CS       0
#define GPIO_IDX_RX_CS       1
#define GPIO_IDX_TX_DELSTR   2
#define GPIO_IDX_TX_DELADJ   3
#define GPIO_IDX_RX_DELSTR   4
#define GPIO_IDX_RX_DELADJ   5
#define GPIO_IDX_TX_CE       6
#define GPIO_IDX_RX_CE       7
#define GPIO_IDX_SW_SYNC     8

/* USER CODE END PD */


I2C_HandleTypeDef hi2c1;
I2C_HandleTypeDef hi2c2;
I2C_HandleTypeDef hi2c3;

SPI_HandleTypeDef hspi1;
SPI_HandleTypeDef hspi4;

TIM_HandleTypeDef htim1;
TIM_HandleTypeDef htim3;  // B15 fix: DELADJ PWM timer (CH2=TX, CH3=RX)

UART_HandleTypeDef huart5;
UART_HandleTypeDef huart3;

/* USER CODE BEGIN PV */
// UM982 dual-antenna GPS receiver
UM982_GPS_t um982;

// Global data structures
GPS_Data_t current_gps_data = {0};

// Global USB handler
USBHandler usbHandler;
extern USBD_HandleTypeDef hUsbDeviceFS;

// Buffer for USB reception
uint8_t usb_rx_buffer[64];

//IMU variable
GY85_t imu;

float Pitch_Sensor, Yaw_Sensor, Roll_Sensor;

float abias[3] = {-0.108, -0.038, -0.006}, gbias[3] = {-10, 6, -12}, mbias[3]={0.0,0.0,0.0};
float M11=1.0,  M12=-0.0,  M13=0.0,
      M21=0.0,  M22=1.0,   M23=0.0,
      M31=0.0,  M32=-0.0,  M33=1.0;
float ax, ay, az, gx, gy, gz, mx, my, mz,mxc,myc,mzc; // variables to hold latest sensor data values
float q[4] = {1.0f, 0.0f, 0.0f, 0.0f};    // vector to hold quaternion
float temperature;
float Mag_Declination = -0.61; //0°

float RxAcc,RyAcc,RzAcc;
float Rate_Ayz_1,Rate_Axz_1,Rate_Axy_1;
float Axz_1,Ayz_1,Axy_1, Axz_0,Ayz_0,Axy_0;
float RxEst_0,RyEst_0,RzEst_0, RxEst_1,RyEst_1,RzEst_1,Azr_Est;
float RxGyro,RyGyro,RzGyro, R_Est;

unsigned long now_timeperiod;
unsigned long lasttime_timeperiod = 0;
int Time_Period = 0;

//Barometer BMP180

/*resolution:
BMP180_ULTRALOWPOWER - pressure oversampled 1 time  & power consumption 3μA
BMP180_STANDARD      - pressure oversampled 2 times & power consumption 5μA
BMP180_HIGHRES       - pressure oversampled 4 times & power consumption 7μA
BMP180_ULTRAHIGHRES  - pressure oversampled 8 times & power consumption 12μA, library default
*/
BMP180 myBMP(BMP180_ULTRAHIGHRES);
float RADAR_Altitude;

//GPS
double RADAR_Longitude = 0;
double RADAR_Latitude = 0;

extern uint8_t GUI_start_flag_received;  // [STM32-006] Legacy, unused -- kept for linker compat


//RADAR
// Radar parameters
const int m_max = 32;  // Number of chirps per beam position
const int n_max = 31;   // Number of beam positions
const float T1 = 30.0f; // Chirp duration in microseconds
const float PRI1 = 167.0f; // Pulse repetition interval in microseconds
const float T2 = 0.5f;  // Short chirp duration in microseconds
const float PRI2 = 175.0f; // Short PRI in microseconds
const float Guard = 175.4f; // Guard time in microseconds

uint8_t	m = 1; // m = N° of chirp/ position = 16 (made of T1 and PRF1)+ Guard = 175µs +16 (made of T2 and PRF2)
uint8_t	n = 1; // n =[1-31] N° of elevations/azimuth
uint8_t	y = 1;// y = N° of azimuths/revolution = 50 controlled by a microcontroller connected to a stepper motor
uint8_t y_max = 50;// y = N° of azimuths/revolution
uint64_t IF_freq = 120000000ULL;//120MHz

#define PowerAmplifier 1

//Stepper Motor
float Stepper_steps = 200.0f;//step per revolution

// DAC5578 handles (RF Power Amplifier DAC controlling Vg)
DAC5578_HandleTypeDef hdac1, hdac2;

/* ---- PA bias sequencing (PA_BIAS_SEQUENCE.h) --------------------------------
 * The order in which the gate bias and the drain may be applied is a safety
 * property of the array, so it lives in a tested library rather than inline here.
 * These callbacks are the only thing in this file that touches both.
 */
static bool pa_bias_set_gate_code(uint8_t code)
{
    uint8_t c = (uint8_t)PA_GATE_BIAS_ClampCode((int)code);
    bool ok = true;
    for (uint8_t ch = 0; ch < 8; ch++) {
        if (!DAC5578_WriteAndUpdateChannelValue(&hdac1, ch, c)) ok = false;
        if (!DAC5578_WriteAndUpdateChannelValue(&hdac2, ch, c)) ok = false;
    }
    return ok;
}

static bool pa_bias_set_drain_enable(bool on)
{
    GPIO_PinState st = on ? GPIO_PIN_SET : GPIO_PIN_RESET;
    HAL_GPIO_WritePin(EN_P_5V0_PA1_GPIO_Port, EN_P_5V0_PA1_Pin, st);
    HAL_GPIO_WritePin(EN_P_5V0_PA2_GPIO_Port, EN_P_5V0_PA2_Pin, st);
    HAL_GPIO_WritePin(EN_P_5V0_PA3_GPIO_Port, EN_P_5V0_PA3_Pin, st);
    HAL_GPIO_WritePin(EN_P_5V5_PA_GPIO_Port, EN_P_5V5_PA_Pin, st);
    HAL_GPIO_WritePin(EN_DIS_RFPA_VDD_GPIO_Port, EN_DIS_RFPA_VDD_Pin, st);
    return true;
}

static void pa_bias_delay_ms(uint32_t ms) { HAL_Delay(ms); }

static PA_BiasSequence_IO_t g_pa_bias_io = {
    pa_bias_set_gate_code, pa_bias_set_drain_enable, pa_bias_delay_ms
};
/* off = mid-scale (the documented shutdown state); the boot bias is where calibration starts */
static PA_BiasSequence_Params_t g_pa_bias_params = {
    PA_GATE_BIAS_CODE_OFF, PA_GATE_BIAS_CODE_BOOT, 5
};

/* ---- rail-good monitoring (RAIL_FAULT.h) -----------------------------------
 * Three regulators report PG on the power board, each on its own connector to PC0/PC1/PC2.
 * The pins are read with internal pull-downs, so an open harness reads LOW and is reported
 * as a fault rather than silently as "good".
 */
static bool rail_pg_adtr_ok(void) { return HAL_GPIO_ReadPin(GPIOC, GPIO_PIN_0) == GPIO_PIN_SET; }
static bool rail_pg_xo_ok(void)   { return HAL_GPIO_ReadPin(GPIOC, GPIO_PIN_1) == GPIO_PIN_SET; }
static bool rail_pg_2v5_ok(void)  { return HAL_GPIO_ReadPin(GPIOC, GPIO_PIN_2) == GPIO_PIN_SET; }

static const RailFault_Source_t g_rail_sources[3] = {
    { rail_pg_adtr_ok }, { rail_pg_xo_ok }, { rail_pg_2v5_ok }
};
static RailFault_Monitor_t g_rails;

/* ---- strobe acknowledgement (STROBE_ACK.h) ---------------------------------
 * The FPGA answers on PC3: a request clears the line, consumption sets it.  We score each
 * request *before* issuing the next one, because the FPGA clears the line as soon as it sees
 * the new request - checking afterwards would always read low.
 */
static StrobeAck_State_t g_strobe_ack;

/* One-shot bring-up test of the acknowledgement path itself: raise a strobe, watch for the
 * answer.  A chirp already in flight will drop the strobe, so a few attempts are allowed before
 * concluding the path is dead.  Harmless at bring-up because the PAs are still off. */
static StrobeAck_SelfTest_t g_ack_test;
static uint8_t  g_ack_test_attempts;
static bool     g_ack_test_done;
static bool     g_ack_test_passed;
static bool     g_ack_path_ok;

/* The FPGA's configuration status (issue #13).  The main board carries FPGA_DONE from the FPGA's
 * DONE_0/INIT_B_0 to U2.PC4, so the MCU can see a failed or partial configuration - which it
 * could not before, when the pins terminated in pull resistors only. */
static FpgaConfig_t g_fpga_cfg;
static bool         g_fpga_cfg_reported;

/* ---- AD9484 serial port (AD9484_SPI.h) -------------------------------------
 * The ADC's CSB used to be tied to a rail - which the datasheet names as the way to disable the
 * SPI - SCLK/DFS sat on solder jumper SJ1, and SDIO was unconnected.  The pins are
 * DRVDD-referenced 1.8 V logic (absolute maximum 2.0 V), so they reach the MCU through U92, a
 * TXS0104E translator; PC10 = CSB, PC11 = SCLK, PC13 = SDIO.
 */
static uint8_t g_adc_ovr_config;   /* read back at bring-up: 0x01 on a healthy part */
static bool    g_adc_spi_ok;

static void adc_spi_csb(bool level)  { HAL_GPIO_WritePin(GPIOC, GPIO_PIN_10, level ? GPIO_PIN_SET : GPIO_PIN_RESET); }
static void adc_spi_sclk(bool level) { HAL_GPIO_WritePin(GPIOC, GPIO_PIN_11, level ? GPIO_PIN_SET : GPIO_PIN_RESET); }
static void adc_spi_sdio_out(bool level) { HAL_GPIO_WritePin(GPIOC, GPIO_PIN_13, level ? GPIO_PIN_SET : GPIO_PIN_RESET); }

static void adc_spi_sdio_dir(bool output)
{
    GPIO_InitTypeDef gi = {0};
    gi.Pin   = GPIO_PIN_13;
    gi.Mode  = output ? GPIO_MODE_OUTPUT_PP : GPIO_MODE_INPUT;
    gi.Pull  = output ? GPIO_NOPULL : GPIO_PULLUP;
    gi.Speed = GPIO_SPEED_FREQ_LOW;
    HAL_GPIO_Init(GPIOC, &gi);
}

static bool adc_spi_sdio_in(void) { return HAL_GPIO_ReadPin(GPIOC, GPIO_PIN_13) == GPIO_PIN_SET; }

/* tCLK >= 40 ns, so a half bit needs 20 ns; a short busy loop is far more than that and does
 * not tie the port to a timer. */
static void adc_spi_delay(void) { for (volatile int i = 0; i < 30; i++) { } }

/* ---- IDQ calibration (PA_BIAS_CAL.h) ---------------------------------------
 * The loop used to be written out twice here, with the QPA2962's numbers inline: a start code of
 * 126, a step of 4, and a stopping window of an absolute 0.2 A.  Against the QPA1010's 0.600 A
 * target that window is +/-33 %, and one 4-code step is about 190 mA of drain current - comparable
 * to the whole window - so the old loop could step over its target and settle on the floor.  It now
 * lives in PA_BIAS_CAL.{h,c}, driven by the device's own constants and a bisection, and is tested
 * against a model device. */
typedef struct {
    DAC5578_HandleTypeDef *dac;
    ADC_HandleTypeDef     *adc;
    uint8_t                channel;
} PaBiasCalCtx_t;

static PaBiasCalCtx_t g_cal_ctx1, g_cal_ctx2;

static bool PaBiasCal_WriteCode(void *ctx, uint8_t code)
{
    PaBiasCalCtx_t *c = (PaBiasCalCtx_t *)ctx;
    return DAC5578_WriteAndUpdateChannelValue(c->dac, c->channel, code) != 0;
}

static float PaBiasCal_ReadIdq(void *ctx)
{
    PaBiasCalCtx_t *c = (PaBiasCalCtx_t *)ctx;
    return paSenseCodeToAmps(ADS7830_Measure_SingleEnded(c->adc, c->channel));
}

static const AD9484_SPI_IO_t g_adc_spi_io = {
    adc_spi_csb, adc_spi_sclk, adc_spi_sdio_out, adc_spi_sdio_dir, adc_spi_sdio_in, adc_spi_delay
};
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
int main(void)
{

  /* MPU Configuration--------------------------------------------------------*/
  MPU_Config();

  /* MCU Configuration--------------------------------------------------------*/

  /* Reset of all peripherals, Initializes the Flash interface and the Systick. */
  HAL_Init();

  /* Configure the system clock */
  SystemClock_Config();

  /* Configure the peripherals common clocks */
  PeriphCommonClock_Config();

  /* Initialize all configured peripherals */
  MX_GPIO_Init();
  RailFault_GPIOInit();
  StrobeAck_Init(&g_strobe_ack);
  AD9484_BringUp();
  MX_TIM1_Init();
  MX_TIM3_Init();  // B15 fix: init DELADJ PWM timer before LO manager uses it
  MX_I2C1_Init();
  MX_I2C2_Init();
  MX_I2C3_Init();
  MX_SPI1_Init();
  MX_SPI4_Init();
  MX_UART5_Init();
  MX_USART3_UART_Init();
  MX_USB_DEVICE_Init();
  MX_IWDG_Init();  /* GAP-3 FIX 2: start hardware watchdog (~4 s timeout) */
  /* USER CODE BEGIN 2 */

  HAL_TIM_Base_Start(&htim1);

  /* --- Enable DWT cycle counter for accurate microsecond delays --- */
  DWT_Init();

  DIAG_SECTION("SYSTEM INIT");
  DIAG("SYS", "DWT cycle counter initialized, TIM1 started");
  DIAG("SYS", "HAL tick at init start: %lu ms", (unsigned long)HAL_GetTick());

  //Wait for OCXO 3mn
  DIAG("CLK", "OCXO warmup starting -- waiting 180 s (3 min)");
  uint32_t ocxo_start = HAL_GetTick();
  /* [GAP-3 FIX 2] Cannot use HAL_Delay(180000) — IWDG would reset MCU.
   * Instead loop in 1-second steps, kicking the watchdog each iteration. */
  for (int ocxo_sec = 0; ocxo_sec < 180; ocxo_sec++) {
      HAL_IWDG_Refresh(&hiwdg);
      HAL_Delay(1000);
  }
  DIAG_ELAPSED("CLK", "OCXO warmup", ocxo_start);

  DIAG_SECTION("AD9523 POWER SEQUENCING");
  DIAG("PWR", "Asserting AD9523 reset (pin LOW)");
  HAL_GPIO_WritePin(AD9523_RESET_GPIO_Port,AD9523_RESET_Pin,GPIO_PIN_RESET);

  //Power sequencing AD9523
  DIAG("PWR", "Enabling 1.8V clock rail");
  HAL_GPIO_WritePin(EN_P_1V8_CLOCK_GPIO_Port,EN_P_1V8_CLOCK_Pin,GPIO_PIN_SET);
  HAL_Delay(100);
  DIAG("PWR", "Enabling 3.3V clock rail");
  HAL_GPIO_WritePin(EN_P_3V3_CLOCK_GPIO_Port,EN_P_3V3_CLOCK_Pin,GPIO_PIN_SET);
  HAL_Delay(100);
  DIAG("PWR", "Releasing AD9523 reset (pin HIGH)");
  HAL_GPIO_WritePin(AD9523_RESET_GPIO_Port,AD9523_RESET_Pin,GPIO_PIN_SET);
  HAL_Delay(100);
  DIAG("PWR", "AD9523 power sequencing complete -- all rails up, reset released");

  //Set planned Clocks on AD9523
  /*
  o Channel 0 = 300MHz LVDS (ADF4382 TX)
  o Channel 1 = 300MHz LVDS (ADF4382 RX) (Phase aligned with Channel 0)
  o Channel 4 = 400MHz LVDS (ADC)
  o Channel 5 = 400MHz LVDS (FPGA_ADC)(Phase aligned with Channel 4)
  o Channel 6 = 100MHz LVCMOS (FPGA system clock)
  o Channel 7 = 20MHz LVCMOS (FPGA test)
  o Channel 8 = 60MHz LVDS (ADF4382 TX sync)
  o Channel 9 = 60MHz LVDS (ADF4382 RX sync)(Phase aligned with Channel 8)
  o Channel 10 = 120MHz LVCMOS
  o Channel 11 = 120MHz LVCMOS (Phase aligned with Channel 10)
   */


  // Ensure stm32_spi.c and stm32_delay.c are compiled and linked

  DIAG("CLK", "Calling configure_ad9523()...");
  uint32_t ad9523_cfg_start = HAL_GetTick();
  if (configure_ad9523() != 0) {
      // configuration error - handle as needed
      DIAG_ERR("CLK", "configure_ad9523() FAILED -- entering infinite halt loop");
      while (1) { HAL_Delay(1000); }
  }
  DIAG_ELAPSED("CLK", "configure_ad9523()", ad9523_cfg_start);
  DIAG("CLK", "AD9523 configured successfully");

  //Power sequencing FPGA
  DIAG_SECTION("FPGA POWER SEQUENCING");
  DIAG("PWR", "Enabling 1.0V FPGA rail");
  HAL_GPIO_WritePin(EN_P_1V0_FPGA_GPIO_Port,EN_P_1V0_FPGA_Pin,GPIO_PIN_SET);
  HAL_Delay(100);
  DIAG("PWR", "Enabling 1.8V FPGA rail");
  HAL_GPIO_WritePin(EN_P_1V8_FPGA_GPIO_Port,EN_P_1V8_FPGA_Pin,GPIO_PIN_SET);
  HAL_Delay(100);
  DIAG("PWR", "Enabling 3.3V FPGA rail");
  HAL_GPIO_WritePin(EN_P_3V3_FPGA_GPIO_Port,EN_P_3V3_FPGA_Pin,GPIO_PIN_SET);
  HAL_Delay(100);
  DIAG("PWR", "FPGA power sequencing complete -- 1.0V -> 1.8V -> 3.3V");


// Initialize module IMU
  DIAG_SECTION("IMU INIT (GY-85)");
  DIAG("IMU", "Initializing GY-85 IMU...");
  if (!GY85_Init()) {
      DIAG_ERR("IMU", "GY85_Init() FAILED -- calling Error_Handler()");
      Error_Handler();
  }
  DIAG("IMU", "GY-85 initialized OK, running 10 calibration samples");
  for(int i=0; i<10;i++){
  if (!GY85_Update(&imu)) {
      Error_Handler();
  }

  ax = imu.ax;
  ay = imu.ay;
  az = imu.az;
  gx = -imu.gx;
  gy = -imu.gy;
  gz = imu.gz;
  mx = imu.mx;
  my = imu.my;
  mz = imu.mz;

  ax *= 6.10351e-5;   //2.0 / 32768.0;
  ay *= 6.10351e-5;
  az *= 6.10351e-5;

  ax -= abias[0];   // Convert to g's, remove accelerometer biases
  ay -= abias[1];
  az -= abias[2];

  gx *= 0.0152588f;   //500.0 / 32768.0;
  gy *= 0.0152588f;
  gz *= 0.0152588f;

  gx -= gbias[0];   // Convert to degrees per seconds, remove gyro biases
  gy -= gbias[1];
  gz -= gbias[2];

  mx *= 6.10351e-5;   //2.0 / 32768.0;
  my *= 6.10351e-5;
  mz *= 6.10351e-5;

  mxc = M11*(mx-mbias[0]) + M12*(my-mbias[1]) +M13*(mz-mbias[2]);
  myc = M21*(mx-mbias[0]) + M22*(my-mbias[1]) +M23*(mz-mbias[2]);
  mzc = M31*(mx-mbias[0]) + M32*(my-mbias[1]) +M33*(mz-mbias[2]);

  mx = mxc;
  my = myc;
  mz = mzc;

  float norm = sqrt((mx*mx) + (my*my) + (mz*mz));
  mx /=norm;
  my /=norm;
  mz /=norm;

  /***************************************************************/
  /*********************IMU Complementary Filter******************/
  /***************************************************************/
    RxAcc = ax;
    RyAcc = ay;
    RzAcc = az;

    Rate_Ayz_1 = gx;
    Rate_Axz_1 = gy;
    Rate_Axy_1 = gz;

    Rate_Ayz_1 = Rate_Ayz_1*0.01745;//Convertion from °/s to Radians/s
    Rate_Axz_1 = Rate_Axz_1*0.01745;
    Rate_Axy_1 = Rate_Axy_1*0.01745;

    /*Combining Accelerometer & Gyroscope Data*/
    Axz_0 = atan2(RxEst_0,RzEst_0);
    Ayz_0 = atan2(RyEst_0,RzEst_0);
    Axy_0 = atan2(RxEst_0,RyEst_0);

    now_timeperiod = micros();

    Time_Period = now_timeperiod - lasttime_timeperiod;

    Axz_1= Axz_0 + Rate_Axz_1*Time_Period*0.000001;
    Ayz_1= Ayz_0 + Rate_Ayz_1*Time_Period*0.000001;
    Axy_1= Axy_0 + Rate_Axy_1*Time_Period*0.000001;

    lasttime_timeperiod = now_timeperiod;

    RxGyro = sin(Axz_1)/(sqrt(1.0 + cos(Axz_1)*cos(Axz_1) * tan(Ayz_1)*tan(Ayz_1)));
    RyGyro = sin(Ayz_1)/(sqrt(1.0 + cos(Ayz_1)*cos(Ayz_1) * tan(Axz_1)*tan(Axz_1)));
    if(RzEst_0 >= 0){
      RzGyro = 1.0*sqrt(1 - RxGyro*RxGyro - RyGyro*RyGyro);
    }
    else {
      RzGyro = -1*sqrt(1 - RxGyro*RxGyro - RyGyro*RyGyro);
    }

    RxEst_1 = RxAcc*0.5 + RxGyro*0.5 ;// Weight of Gyro. over Acc.
    RyEst_1 = RyAcc*0.5 + RyGyro*0.5 ;
    RzEst_1 = RzAcc*0.5 + RzGyro*0.5 ;

    R_Est = sqrt(RxEst_1*RxEst_1+RyEst_1*RyEst_1+RzEst_1*RzEst_1);

    Pitch_Sensor = atan2(RxEst_1,sqrt(RyEst_1*RyEst_1)+(RzEst_1*RzEst_1))*180/PI;
    Roll_Sensor = atan2(RyEst_1,sqrt(RxEst_1*RxEst_1)+(RzEst_1*RzEst_1))*180/PI;

    float magRawX = mx*cos(Pitch_Sensor*PI/180.0f)  - mz*sin(Pitch_Sensor*PI/180.0f);
	float magRawY = mx*sin(Roll_Sensor*PI/180.0f)*sin(Pitch_Sensor*PI/180.0f) + my*cos(Roll_Sensor*PI/180.0f)- mz*sin(Roll_Sensor*PI/180.0f)*cos(Pitch_Sensor*PI/180.0f);
    Yaw_Sensor = (180*atan2(magRawY,magRawX)/PI) - Mag_Declination;

    if(Yaw_Sensor<0)Yaw_Sensor+=360;

    // Override magnetometer heading with UM982 dual-antenna heading when available
    if (um982_is_heading_valid(&um982)) {
        Yaw_Sensor = um982_get_heading(&um982);
    }

    RxEst_0 = RxEst_1;
    RyEst_0 = RyEst_1;
    RzEst_0 = RzEst_1;

    HAL_Delay(300);

  }

    ///////////////////////////////////////////////////////////////////////////////////
    ///////////////////////////////////BAROMETER BMP180////////////////////////////////
    ///////////////////////////////////////////////////////////////////////////////////
    DIAG_SECTION("BAROMETER INIT (BMP180)");
    DIAG("IMU", "Reading 5 barometer samples for altitude baseline");
  	for(int i = 0; i<5 ; i++){
		float BMP_Perssure = myBMP.getPressure();
		RADAR_Altitude = 44330*(1-(pow((BMP_Perssure/101325),(1/5.255))));
		HAL_Delay(100);
  	}
    DIAG("IMU", "Barometer init complete, RADAR_Altitude baseline set");

    ///////////////////////////////////////////////////////////////////////////////////
    ///////////////////////////////////////ADF4382/////////////////////////////////////
    ///////////////////////////////////////////////////////////////////////////////////
    DIAG_SECTION("ADF4382A LO INIT");
    printf("Starting ADF4382A Radar LO System...\n");
    printf("Using SPI4 with TIMED SYNCHRONIZATION (60 MHz clocks)\n");
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

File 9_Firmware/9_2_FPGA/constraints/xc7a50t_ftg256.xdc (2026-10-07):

# ============================================================================
# RADAR SYSTEM FPGA CONSTRAINTS
# ============================================================================
# Device: XC7A50T-2FTG256I (FTG256 package)
# Board:  AERIS-10 Phased Array Radar — Main Board
# Source: Pin assignments extracted from Eagle schematic (RADAR_Main_Board.sch)
#         FPGA = U42
#
# NOTE: The README and prior version of this file incorrectly referenced
#       XC7A100TCSG324-1. The physical board uses XC7A50T in a 256-ball BGA
#       (FTG256). All PACKAGE_PIN values below are FTG256 ball locations.
#
# I/O Bank Voltage Summary:
#   Bank 0:  VCCO = 3.3V (JTAG, flash CS)
#   Bank 14: VCCO = 2.5V (ADC LVDS_25 data + adc_or overrange; adc_pwdn LVCMOS25)
#   Bank 15: VCCO = 3.3V (DAC, clocks, STM32 SPI 3.3V side, DIG bus, mixer)
#   Bank 34: VCCO = 1.8V (ADAR1000 beamformer control, SPI 1.8V side)
#   Bank 35: VCCO = 3.3V (FT2232H USB 2.0 FIFO — 15 signals)
#
# DRC Fix History:
#   - PLIO-9: Moved clk_120m_dac from C13 (N-type) to D13 (P-type MRCC).
#     Clock inputs must use the P-type pin of a Multi-Region Clock-Capable pair.
#   - BIVC-1 / Place 30-372: Bank 14 must have a single VCCO. LVDS_25 forces
#     VCCO=2.5V, so adc_pwdn was changed from LVCMOS33 to LVCMOS25 to match.
#     IBUFDS input buffers are VCCO-independent. BIVC-1 also waived via
#     set_property SEVERITY in the build script as an additional safety net.
#     in the build script. adc_pwdn (LVCMOS25) coexists in the same bank.
#   - UCIO/NSTD: Unconstrained ports (FT601 ports inactive with USB_MODE=1,
#     status/debug outputs have no physical pins). Handled with SEVERITY
#     demotion + default IOSTANDARD.
#   - PLIO-9: FT2232H CLKOUT routed to C4 (IO_L12N_T1_MRCC_35, N-type).
#     Clock inputs normally use P-type MRCC pins, but IBUFG works correctly
#     on N-type. Demote PLIO-9 to warning in build script.
# ============================================================================

# ============================================================================
# CONFIGURATION
# ============================================================================
set_property CFGBVS VCCO [current_design]
set_property CONFIG_VOLTAGE 3.3 [current_design]

# ============================================================================
# DRC WAIVERS — Hardware-Level Known Issues (applied in build script)
# ============================================================================
# BIVC-1: Bank 14 VCCO=3.3V with LVDS_25 inputs + LVCMOS33 adc_pwdn.
# IBUFDS input buffers are VCCO-independent on 7-series — they use an
# internal differential amplifier that works correctly at any VCCO.
# The BIVC-1 DRC check is intended for OBUFDS *outputs* where VCCO
# directly affects the output swing. Since Bank 14 has only LVDS inputs
# and one LVCMOS33 output, this is safe to demote to a warning.
# → Applied in build_50t_test.tcl: set_property SEVERITY {Warning} [get_drc_checks BIVC-1]
#
# NSTD-1 / UCIO-1: Unconstrained ports — FT601 USB ports (inactive with
# USB_MODE=1 generate block), dac_clk (DAC clock comes from AD9523, not FPGA),
# and all status/debug outputs (no physical pins available). These ports are
# present in the shared RTL but have no connections on the 50T board.
# → Applied in build_50t_test.tcl: set_property SEVERITY {Warning} [get_drc_checks {NSTD-1 UCIO-1}]

# ============================================================================
# CLOCK CONSTRAINTS
# ============================================================================

# 100MHz System Clock (AD9523 OUT6 → FPGA_SYS_CLOCK → Bank 15 MRCC pin E12)
set_property PACKAGE_PIN E12 [get_ports {clk_100m}]
set_property IOSTANDARD LVCMOS33 [get_ports {clk_100m}]
create_clock -name clk_100m -period 10.0 [get_ports {clk_100m}]
set_input_jitter [get_clocks clk_100m] 0.1

# 120MHz DAC Clock (AD9523 OUT11 → FPGA_DAC_CLOCK → Bank 15 MRCC pin D13)
# NOTE: The physical DAC (U3, AD9708) receives its clock directly from the
#       AD9523 via a separate net (DAC_CLOCK), NOT from the FPGA. The FPGA
#       uses this clock input for internal DAC data timing only. The RTL port
#       `dac_clk` is an RTL output that assigns clk_120m directly. It has no
#       physical pin on the 50T board and is left unconnected here. The port
#       CANNOT be removed from the RTL because the 200T board uses it with
#       ODDR clock forwarding (pin H17, see xc7a200t_fbg484.xdc).
# FIX: Moved from C13 (IO_L12N = N-type) to D13 (IO_L12P = P-type MRCC).
#      Clock inputs must use the P-type pin of an MRCC pair (PLIO-9 DRC).
set_property PACKAGE_PIN D13 [get_ports {clk_120m_dac}]
set_property IOSTANDARD LVCMOS33 [get_ports {clk_120m_dac}]
create_clock -name clk_120m_dac -period 8.333 [get_ports {clk_120m_dac}]
set_input_jitter [get_clocks clk_120m_dac] 0.1
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

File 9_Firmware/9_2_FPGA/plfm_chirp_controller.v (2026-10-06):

`timescale 1ns / 1ps

module plfm_chirp_controller_enhanced (
    input wire clk_120m,
    input wire clk_100m,
    input wire reset_n,
    input wire new_chirp,
    input wire new_elevation,
    input wire new_azimuth,
    input wire mixers_enable,
    output reg [7:0] chirp_data,
    output reg chirp_valid,
	 output wire new_chirp_frame,
    output reg chirp_done,
    output reg rf_switch_ctrl,
    output wire rx_mixer_en,
    output wire tx_mixer_en,
    output wire adar_tx_load_1,
    output wire adar_rx_load_1,
    output wire adar_tx_load_2,
    output wire adar_rx_load_2,
    output wire adar_tx_load_3,
    output wire adar_rx_load_3,
    output wire adar_tx_load_4,
    output wire adar_rx_load_4,
    output reg adar_tr_1,
    output reg adar_tr_2,
    output reg adar_tr_3,
    output reg adar_tr_4,
    output reg [5:0] chirp_counter,
    output reg [5:0] elevation_counter,
    output reg [5:0] azimuth_counter,
    // Toggles on each strobe that arrived while the FSM was not idle, i.e. the
    // strobe was dropped (this FSM only reads new_chirp in IDLE).  A toggle
    // rather than a level: it is the same cross-domain pattern the frame
    // boundary already uses, and it survives even pulses.
    output reg chirp_reject_toggle
);

// Chirp parameters
parameter F_START = 30000000;       // 30 MHz (starting frequency)
parameter F_END = 10000000;         // 10 MHz (ending frequency)
parameter FS = 120000000;           // 120 MHz

// Timing parameters
parameter T1_SAMPLES = 3600;        // 30us at 120MHz
parameter T1_RADAR_LISTENING = 16440; //137us at 120MHz
parameter T2_SAMPLES = 60;          // 0.5us at 120MHz
parameter T2_RADAR_LISTENING = 20940; //174.5us at 120MHz
parameter GUARD_SAMPLES = 21048;    // 175.4us at 120MHz

// Chirp and beam parameters
parameter CHIRP_MAX = 32;
parameter ELEVATION_MAX = 31;
parameter AZIMUTH_MAX = 50;

// State parameters
parameter IDLE        = 3'b000;
parameter LONG_CHIRP  = 3'b001;
parameter LONG_LISTEN = 3'b010;
parameter GUARD_TIME  = 3'b011;
parameter SHORT_CHIRP = 3'b100;
parameter SHORT_LISTEN = 3'b101;
parameter DONE        = 3'b110;

reg [2:0] current_state;
reg [2:0] next_state;

// Control registers
reg [15:0] sample_counter;

// Edge detection for input signals
wire chirp__toggling, elevation__toggling, azimuth__toggling;

// LUTs for chirp waveforms
(* ram_style = "block" *) reg [7:0] long_chirp_lut [0:3599];  // T1_SAMPLES-1
reg [7:0] short_chirp_lut [0:59];   // T2_SAMPLES-1

// Registered BRAM read output (sync-only for BRAM inference)
reg [7:0] long_chirp_rd_data;

// Edge detection
assign chirp__toggling = new_chirp;
assign elevation__toggling = new_elevation;
assign azimuth__toggling = new_azimuth;
assign new_chirp_frame = (current_state == IDLE && next_state == LONG_CHIRP);

// A strobe is dropped when it does not start a frame -- either because the FSM
// is mid-sequence, or because it is idle with the mixers disabled.  In both
// cases the command is silently ignored today; this makes it observable.
// Resides in the clk_120m domain with current_state, so no CDC is needed here.
wire chirp_reject = new_chirp && !new_chirp_frame;

always @(posedge clk_120m or negedge reset_n) begin
    if (!reset_n)
        chirp_reject_toggle <= 1'b0;
    else if (chirp_reject)
        chirp_reject_toggle <= ~chirp_reject_toggle;
end

// Mixer TX/RX sequencing — mutually exclusive based on chirp FSM state.
// TX mixer active during chirp transmission, RX mixer during listen.
// Both require mixers_enable (STM32 master enable) to be high.
assign tx_mixer_en = mixers_enable && (current_state == LONG_CHIRP ||
                                       current_state == SHORT_CHIRP);
assign rx_mixer_en = mixers_enable && (current_state == LONG_LISTEN ||
                                       current_state == SHORT_LISTEN);

// ADTR1000 pull to ground tx and rx load pins if not used
assign adar_tx_load_1 = 1'b0;
assign adar_rx_load_1 = 1'b0;
assign adar_tx_load_2 = 1'b0;
assign adar_rx_load_2 = 1'b0;
assign adar_tx_load_3 = 1'b0;
assign adar_rx_load_3 = 1'b0;
assign adar_tx_load_4 = 1'b0;
assign adar_rx_load_4 = 1'b0;




// LUT Initialization
// Long PLFM chirp LUT loaded from .mem file for BRAM inference
initial begin
    $readmemh("long_chirp_lut.mem", long_chirp_lut);
end

// Synchronous-only BRAM read (no async reset) for BRAM inference
always @(posedge clk_120m) begin
    long_chirp_rd_data <= long_chirp_lut[sample_counter];
end

// Short PLFM chirp LUT initialization (too small for BRAM, keep inline)
initial begin
    // Complete Short PLFM chirp LUT (0.5us, 30MHz to 10MHz)
    short_chirp_lut[ 0] = 8'd255; short_chirp_lut[ 1] = 8'd237; short_chirp_lut[ 2] = 8'd187; short_chirp_lut[ 3] = 8'd118; short_chirp_lut[ 4] = 8'd 49; short_chirp_lut[ 5] = 8'd  6; short_chirp_lut[ 6] = 8'd  7; short_chirp_lut[ 7] = 8'd 54; 
    short_chirp_lut[ 8] = 8'd132; short_chirp_lut[ 9] = 8'd210; short_chirp_lut[10] = 8'd253; short_chirp_lut[11] = 8'd237; short_chirp_lut[12] = 8'd167; short_chirp_lut[13] = 8'd 75; short_chirp_lut[14] = 8'd 10; short_chirp_lut[15] = 8'd 10; 
    short_chirp_lut[16] = 8'd 80; short_chirp_lut[17] = 8'd180; short_chirp_lut[18] = 8'd248; short_chirp_lut[19] = 8'd237; short_chirp_lut[20] = 8'd150; short_chirp_lut[21] = 8'd 45; short_chirp_lut[22] = 8'd  1; short_chirp_lut[23] = 8'd 54; 
    short_chirp_lut[24] = 8'd167; short_chirp_lut[25] = 8'd249; short_chirp_lut[26] = 8'd228; short_chirp_lut[27] = 8'd118; short_chirp_lut[28] = 8'd 15; short_chirp_lut[29] = 8'd 18; short_chirp_lut[30] = 8'd127; short_chirp_lut[31] = 8'd238; 
    short_chirp_lut[32] = 8'd235; short_chirp_lut[33] = 8'd118; short_chirp_lut[34] = 8'd 10; short_chirp_lut[35] = 8'd 34; short_chirp_lut[36] = 8'd167; short_chirp_lut[37] = 8'd254; short_chirp_lut[38] = 8'd187; short_chirp_lut[39] = 8'd 45; 
    short_chirp_lut[40] = 8'd  8; short_chirp_lut[41] = 8'd129; short_chirp_lut[42] = 8'd248; short_chirp_lut[43] = 8'd201; short_chirp_lut[44] = 8'd 49; short_chirp_lut[45] = 8'd 10; short_chirp_lut[46] = 8'd145; short_chirp_lut[47] = 8'd254; 
    short_chirp_lut[48] = 8'd167; short_chirp_lut[49] = 8'd 17; short_chirp_lut[50] = 8'd 46; short_chirp_lut[51] = 8'd210; short_chirp_lut[52] = 8'd235; short_chirp_lut[53] = 8'd 75; short_chirp_lut[54] = 8'd  7; short_chirp_lut[55] = 8'd155; 
    short_chirp_lut[56] = 8'd253; short_chirp_lut[57] = 8'd118; short_chirp_lut[58] = 8'd  1; short_chirp_lut[59] = 8'd129; 
end

// chirp_counter is driven solely by the clk_120m FSM always block (line ~683).
// Removed redundant clk_100m driver that caused multi-driven register
// (synthesis failure, simulation race condition).
// The FSM internally sequences through CHIRP_MAX chirps per beam position,
// so external new_chirp edge counting is unnecessary here.

// Elevation counter
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

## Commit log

2026-10-06 fix(mcu): correct the PA sense chain and make the AGC recoverable
    Sense chain (feasibility review M4/M5):
    - The shunt value, INA241 gain, ADS7830 reference and firmware scaling were
    four independent copies of one physical fact, and they disagreed: the PA BOM
    names WSL2816R1000FEH (0.1 ohm) while the value column says 5 mR, and the
    firmware scaled with 3.3 V although the ADS7830 is initialised with its
    internal 2.5 V reference.
    - Constants now live in PA_SENSE.h. A static_assert rejects any combination
    whose full scale cannot reach the over-current threshold, which is exactly
    what the 0.1 ohm part sets up (saturates at 0.5 A, trip needs 2.5 A).
    - All six inline (3.3/255)*code/(50*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
    [PA_SENSE.h, main.cpp, test_agc_outer_loop.cpp]
2026-10-06 feat(fpga): export AGC hard-overload on DIG_7, add the 100T production build
    - DIG_7 (H12 -> STM32 PD15) was tied low; it now reports a hard overload
    (>= 8 clipped samples in a frame) so the MCU outer loop can take a larger
    attack step on a strong transient than on a marginal clip. XDC and port
    comments updated to match.
    - scripts/100t/build_100t.tcl: the published design needs ~142 DSP48E1 and does
    not fit the 50T (upstream #186). The 100T is pin-compatible (same FTG256
    package and XDC), so only the part changes; the 50T flow stays for bring-up.
    The BIVC-1 waiver is now documented as required *until* the Rev B board
    supplies 2.5 V to VCCO_14 -- the current schematic ties it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
    [xc7a50t_ftg256.xdc]
2026-10-06 feat(tools): generate BOM/DNP/rail artifacts from the boards, and gate them in CI
    The production BOMs were transcribed by hand and have drifted from the boards:
    BOM_Main_Board.xlsx never lists C353 although the board places it, and the PA
    sheet's R10 MPN (WSL2816R1000FEH, 0.1 ohm) contradicts its own value column
    (5 mR).
    - regenerate_bom.py: emits BOM + CPL + summary CSVs per board from the Eagle
    .brd files and diffs them against the committed spreadsheets. --check
    compares against a committed baseline (known_discrepancies.txt) so CI fails
    on a NEW discrepancy while the four known ones stay visible.
    - extract_dnp.py: the DNP markers only existed as free text in spreadsheet
    notes ("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
    [DNP_list.csv, FreqSynth_bom.csv, FreqSynth_bom_summary.csv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]
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2026-10-06 fix(bom): correct the shunt part number and the missing C353; make the gates check both sources
    Two production-BOM data defects, both found by the artifact gates:
    - BOM_Main_Board.xlsx listed C352 twice and omitted C353 -- a 0.1 uF C0201 the
    board places. An order built from that sheet would never buy it. The line
    item now carries C352 and C353 with the qty corrected from 6 to the 8 parts
    actually listed.
    - BOM_PA.xlsx declared R10 value "5mR" but named WSL2816R1000FEH, which is
    0.1000 ohm: a 20x error that makes the sense chain saturate at 0.5 A, below
    the 2.5 A trip, so over-current protection could never fire. The board
    silkscreen, the firmware constant and the bias loop a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
    [BOM_Main_Board.xlsx, BOM_PA.xlsx]
2026-10-06 feat(fpga): use the ADC out-of-range flag the hardware already routes
    The AD9484 OR pin is wired to bank-14 balls M6/N6, but the signal appeared in
    neither top module and was absent from the XDC: the one signal that reports
    *analog* overload was collected and thrown away. The digital clip count only
    sees the post-digital-gain value, so an overload the digital AGC has already
    backed off can be invisible to it.
    - ad9484_interface_400m.v gains the OR pair and buffers it with IBUFDS (that
    module owns the Xilinx primitives and is replaced by
    tb/ad9484_interface_400m_stub.v in simulation); the stub models the pair as a
    single-ended level, using case equality so an undriven port cannot inje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
    [xc7a50t_ftg256.xdc]
2026-10-06 feat(agc): make the AGC attack proportional to the saturation magnitude (WP4.2)
    The FPGA knew how badly the receiver was clipping -- an 8-bit per-frame count --
    but the MCU's outer AGC loop only ever saw two levels of it, because DIG_7 was a
    single bit. A bang-bang attack on a 1-bit error signal hunts around the
    threshold instead of converging, which is the review's complaint against the
    loop.
    The count now crosses the link as a pulse train on that same single wire:
    FPGA agc_magnitude_link.v emits one pulse per severity class of the frame's
    saturation count (class = bit length of the count, clamped to 7), 1 us
    high with a 3 us period, starting at the frame boundary -- 2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
    [main.cpp, test_agc_outer_loop.cpp]
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2026-10-06 fix(hw): take the first IF stage from 10 dB to 15 dB (Lane B B1.2)
    Stage 1 (`U4`) is set for 10 dB and stage 2 (`U8`) for 15 dB, so the cascade is
    25 dB against the ~30 dB the ADC wants. Both stages are AD8352s whose gain comes
    from R_G, and the datasheet (Table 5, 200 ohm load) gives 115 ohm for 10 dB and
    56 ohm for 15 dB.
    Table 5 also pairs each gain with a distortion-cancellation network -- CD of
    0.2 pF at 10 dB and 0.6 pF at 15 dB, RD = 4.3k either way -- and stage 2 is built
    exactly that way (R22 = 56R, C54 = 0.6pF). So stage 1 needs *two* parts changed,
    not one:
    R14 115R -> 56R (gain resistor, U4.RGN/U4.RGP)
    C43 0.2pF -> 0.6pF (CD, with R15 = 4.3k on U4.RDP/U4.RDN)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
    [BOM_Main_Board.xlsx, MainBoard_bom.csv, MainBoard_bom_summary.csv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]
2026-10-06 fix(hw): move the PA sense chain to the INA241A4 (Lane B B2.5)
    The current-sense amplifier is not on the PA board at all -- the shunt (`R10`,
    5 mOhm) is, and 16 x `INA241A3IDGKR` on the main board (`U11`, `U73`-`U87`) read
    it. At the A3's 50 V/V into the ADS7830's 2.5 V internal reference the span is
    10 A at 39.2 mA/LSB, so the 1.68 A bias target sits at only 17 % of span.
    Decision (owner): INA241A4 = 100 V/V. TI's datasheet lists the gain options as
    10/20/50/100/200 V/V for A1/A2/A3/A4/B4, and the A4 shares the A3's DGK/VSSOP-8
    package and pinout, so this is a part-number change with no layout impact:
    span 10 A -> 5 A
    resolution 39.2 -> 19.6 mA/LSB
    1.68 A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
    [BOM_Main_Board.xlsx, MainBoard_bom.csv, MainBoard_bom_summary.csv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]
2026-10-06 feat(hw): cavity-filter interface on the main board (Lane B B1.3)
    Decision (owner): cavity filters rather than microstrip, because >= 40 dB of image
    rejection 240 MHz from a 10.5 GHz passband is not a microstrip-with-tuning job.
    The filter is therefore off-board, which means the board needs launches and the
    two 2-pin `BPF2` placeholders (`U$2`, `U$3`) no longer represent anything.
    Added, using only devices that already exist in the repo's libraries:
    4 x SMA jack `142-0731-211` (J56-J59) -- the deviceset, symbol and
    package were already present
    2 x 0R bridge (R174, R175) -- R-EU_ R0201, MPN copied from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
    [BOM_Main_Board.xlsx, DNP_list.csv, MainBoard_bom.csv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]
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2026-10-06 feat(hw): gate-bias fail-safe, negative-rail margin, PA drain bulk (Lane B B2.2/B1.5/B2.3)
    B2.2 -- and this is the finding that matters. Every one of the 16 gate-bias
    channels is an inverting amplifier referenced to ground (Vout = -(Rf/Rin) x VDAC,
    + input on GND), so a DAC in reset puts **0 V on all 16 gates**. QPA2962 is a
    depletion-mode GaN HEMT, where 0 V means *fully on* -- with 22 V on the drains.
    That is a power-up hazard, not a nuance.
    The plan frames the fix as hardware default *plus* MCU sequence; the hardware half
    is here. One 10k pull-down per channel from VGn to the same negative rail that
    supplies its op-amp (R178-R193), so the gates sit at the negative rail whenever
    the op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
    [BOM_Main_Board.xlsx, BOM_PA.xlsx, MainBoard_bom.csv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]
2026-10-06 fix(hw/fw): the emergency stop was turning all 16 PAs hard on (Lane B B2.2 settled)
    The question I was asked to settle was whether the gate-bias stage needs reconfiguring so
    that a DAC in reset parks the PAs off. It does not. It already does, and the defect is
    somewhere else entirely.
    Hardware is correct as designed, on primary sources:
    * all 16 channels identical, Rf = 2.443k / Rin = 1k off the external 3.3 V reference
    (measured from the schematic, and it reproduces the firmware's own -3.98 V comment);
    * the DAC5578 has no internal reference -- the pin-compatible DAC7678 is the part that
    does -- so VREFIN really is the external 3.3 V rail;
    * RSTSEL is tied high, which the dat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
    [DA5578.c, DAC5578.H, main.cpp]
2026-10-06 test(fw): make the DAC5578 driver compilable host-side, then test its CLR contract
    Two errors were reported from the enum/contract check. Both are fixed, and the second one
    was a real gap in this repo rather than a bad command.
    Error 1 -- "DAC5578.h file not found". My ad-hoc compile used -I../9_1_1_C_Cpp_Libraries
    from 9_1_Microcontroller/, which resolves to a directory that does not exist. The harness's
    own include set (-Ishims -I. -I../9_1_1_C_Cpp_Libraries, as in tests/Makefile) is correct.
    Nothing to change in the repo; the check now runs through the suite instead of by hand.
    Error 2 -- "stm32f7xx_hal.h file not found", which survived the path fix because
    tests/shims/stm32f7xx_hal.h i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
    [stm32_hal_mock.c, stm32_hal_mock.h]
2026-10-06 fix(hw): stale sense-amp annotation, and +3V3_XO bulk (Lane B B3.5)
    Two grounded fixes, both from the progress audit rather than from the tracker's word.
    1. Stale annotation. The main-board sheet has read "6 X INA241A3" twice since before this
    work: once wrong in the part (B2.5 made every sense amplifier an INA241A4) and once
    wrong in the count (the netlist has 16 of them). They sit in two columns of 8
    (U11,U73-U79 at x=419.10 and U80-U87 at x=650.24), so each label annotates one column:
    now "8 X INA241A4" twice, and 2 x 8 = the 16 in the netlist. The neighbouring labels
    ("2 X DAC5578", "3 X ADS7830") already match the netlist, which is the check that made
    this one's stale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
    [BOM_Power_Board.xlsx, PowerBoard.brd, PowerBoard.sch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]
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2026-10-06 fix(hw): four netlist defects, and the gate that should have caught them
    Chasing the duplicated X36 board element turned up three more defects, and one of them was
    electrical. All four are mine, all from the B1.1 work.
    1. Duplicate X36. Upstream had 35 schematic X parts (X1-X35) but 36 board elements: X36
    existed *only* on the board, wired to +5V0_LO and GND, with no schematic counterpart.
    My B1.1 2.5 V connector then took the refdes X36 -- so the board carried two elements of
    that name while the BOM counted one, which is an assembly ambiguity, not a cosmetic one.
    Fixed the structurally correct way: my connector keeps X36 (it has a schematic part), and
    upstream's orphan ele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
    [BOM_Power_Board.xlsx, PowerBoard.brd, PowerBoard.sch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]
2026-10-06 fix(hw): revert B1.5, connect the PG pins, and generate the harness map
    Five fixes from the remaining-items plan. Two of them are corrections to work already
    committed, and one is a correction to the plan itself.
    REVERT B1.5. Its premise was wrong. The rail budget has -5V5_PA at 100 mA against a 200 mA
    LM2662 -- 50 %, not "100 % of rating" as the item claimed -- while -5V0_ADAR12/34 are the
    rails that are 1.2x over (240 mA vs 200 mA). What was moved is negligible anyway: the
    OPA4703 datasheet gives 200 uA per amplifier, so ~3 mA of quads plus ~1.6 mA of the new gate
    pull-downs. So the change added load to the two overloaded rails and left U22, C105 and one
    harness connector feeding noth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
    [BOM_Power_Board.xlsx, PowerBoard.brd, PowerBoard.sch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]
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2026-10-06 feat(backlog): close the six remaining Lane B decisions (#5 #7 #8 #9 #10 #24)
    #5 PA operating mode: PA_BIAS_SEQUENCE.{h,c} make the gate/drain order a tested
    contract (enable: gate off -> drain -> settle -> operating bias; disable: gate
    off -> drain off; every failure path lands safe). 17/17, wired into startup and
    Emergency_Stop in main.cpp.
    #7 harmonic filter: docs/harmonic-filter.md - spec, the existing SMA interface, the
    measurement that must set the filter order, and the three options.
    #8 rail-good routing: three TPS7A8300 PG signals each get their own 2-position
    connector pair (power X38-X40 -> main X25-X27 -> U2.PC0-PC2, verified free).
    RAIL_FAULT.{h,c} samples and l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
    [BOM_Main_Board.xlsx, BOM_Power_Board.xlsx, MainBoard_bom.csv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]
2026-10-06 fix(tools): the BOM gate now checks which row a part sits on, not just that it exists
    regenerate_bom.py compared designator *presence* between the board and the sheet, so a
    designator could sit on the wrong row and pass. That is exactly how the harness keying change
    went wrong earlier: the new rows were cloned and inherited the whole 2-position list, and the
    gate stayed green.
    It now compares the board's value against the value on the sheet row the designator appears in,
    normalising the micro glyph and accepting a containment match so that "100nF" vs "100nF/50V"
    is not a finding. Verified by fault injection: moving X31 onto the 22-23-2021 row makes the
    check name it, and restoring makes it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
    [MainBoard_bom.csv, MainBoard_bom_summary.csv, PowerBoard.brd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]
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2026-10-07 feat(hw): ADAR supply order, test points, strobe acknowledgement (#13 #15 #20)
    #20 ADAR1000 supply order - the requirement, verified and locked
    The pin table says AVDD3 (+3.3 V) must come up "before or at the same time as the
    AVDD1(-5V) supply"; the "−5 V first" sentence elsewhere in the same datasheet is about an
    external PA's drain (the gate-bias rule). The firmware already asserts the 3.3 V ADAR rails
    before the 5.0 V rail that creates -5 V through the LM2662 inverters, so this needed no code
    change - it needed the requirement written down at the call site and a test that fails if a
    later edit swaps the order. docs/power-up-order.md records every device's requirement with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
    [BOM_Power_Board.xlsx, PowerBoard.brd, PowerBoard.sch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]
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2026-10-07 feat(fw): bring-up self-tests, the real thermal budget, and the PA limit bug (#5 #13 #14)
    Research turned three of these from "needs a bench step" into either a document that already
    exists or a self-test:
    #5 the thermal number was never NDA-gated. The QPA2962 brief carries theta_JC = 2.83 degC/W at
    P_DISS = 36.96 W, and its own row is self-consistent (85 + 2.83 x 36.96 = 189 degC channel),
    so a measured case temperature converts to a channel temperature with one multiplication.
    PA_THERMAL.{h,c} hold the model and test_pa_thermal.c checks it against the brief's row, so
    the numbers cannot drift from the datasheet. The derived case limit is 95.4 degC.
    The same pass found a re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
    [main.cpp]
2026-10-07 feat(hw): the eight temperature channels, and a filter that meets the requirement (#5 #7)
    #5 The issue said the harness had no spare position, so the sensors could not reach the MCU. The
    second half was the wrong question: the main board already carries the whole interface.
    Three ADS7830s exist and are in the BOM - U10 (0x48), U88 (0x4A), U89 (0x4B) - and the firmware
    names exactly these hadc1/hadc2/hadc3. U89's eight channels run to eight 3-pin headers (JP5,
    JP6, JP11, JP12, JP14, JP15, JP16, JP19), each bringing out +3V3_AN4_F, the channel and GND.
    The probes are therefore external, on flying leads, and belong at the PA where the temperature
    is actually wanted.
    What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
    [BOM_Main_Board.xlsx, MainBoard_bom.csv, MainBoard_bom_summary.csv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]
2026-10-07 feat(hw): power-sequencing gate, and the BOM check now compares packages (#20 #26)
    #20 The issue asked whether three converters with EN tied to VIN break the power-up order, and
    whether to re-stage them. The answer is that they do not, for a structural reason:
    every negative rail on this board is an LM2662 charge pump, and a charge pump has no enable
    pin - it runs whenever its V+ is present. So a negative rail cannot precede the positive
    rail feeding it.
    Verified rail by rail: U18 (-3V3_SW) is fed from +3V3_SW, which is itself staged on MCU PE14;
    U20/U21/U36/U37 (-5V0_ADAR*) from +5V0_ADAR (staged, U13, PE10); U22 (-5V5_PA) from +5V5_PA
    (staged, U17); U19 (-3V4)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
    [PowerBoard.brd, PowerBoard_bom.csv, PowerBoard_bom_summary.csv]
2026-10-07 chore(#22): sweep the remaining production-BOM part numbers against distributors
    121 distinct part numbers were unchecked. A sweep of distributor pages confirms 94 of them,
    which moves the tool's count from 40 to 149 of 179 rows.
    The method and its limit, stated plainly: for each part number, a web search for the exact string
    was checked for a result whose URL, title or description names it. That is evidence of *existence*,
    not of suitability - suitability is what the rail, BOM and datasheet checks are for.
    27 part numbers were not resolved. They are not evidence of absence: they are recognizable
    manufacturer series (Yageo RC0201FR-07, Murata GRM033, Vishay CRCW, Mini-Circuits MTX2-143+,
    E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
    [bom_orderability.csv]
2026-10-07 fix(fw): the AD9484's writes never took effect - no DEVICE_UPDATE transfer (#14)
    The register write sent its frame and stopped there. The AD9484 memory map has a transfer
    register, 0xFF DEVICE_UPDATE, described as "synchronously transfers data from the master shift
    register to the slave" - so every write sat in the shift register and the part never changed.
    That made the two helpers added earlier for this issue actively misleading: SetTestPattern and
    SetDataFormat both reported success and did nothing. A test-pattern check that passes on a board
    whose test pattern was never enabled is worse than no check.
    * write_frame() is the shift-register write; AD9484_SPI_WriteRegister() is now th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
    [main.cpp]
2026-10-07 feat(fw): read the AD9523's outputs back, so "the unused ones are off" is a measurement (#17)
    The issue's finding was that four nets carry nothing but the driver (AD9523_OUT2+/-, OUT3+/-), and
    its acceptance criteria ask for confirmation that the unused outputs are off.
    That confirmation now exists in two independent forms, and both were checked before writing code:
    * The platform data initialises EVERY channel to TRISTATE with output_dis = 1, then explicitly
    enables only the ten in use - 0, 1, 4, 5, 6, 7, 8, 9, 10, 11. Channels 2, 3, 12 and 13 stay
    disabled, and channels 2 and 3 are exactly OUT2 and OUT3.
    * The driver independently writes DRIVER_MODE(TRISTATE) | PWR_DOWN_EN t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
    [main.cpp]
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2026-10-07 feat(fw): the MCU now reports a failed FPGA configuration (#13)
    The issue's second finding was that a failed or partial FPGA configuration is invisible to the
    firmware: the configuration pins terminated in pull resistors only. That is no longer true - the
    main board carries FPGA_DONE from the FPGA's DONE_0/INIT_B_0 (U42) to U2.PC4 - but the firmware
    never read it, so the acceptance criterion "force a failed configuration: the MCU must report it"
    was unmet in the code even though the wire existed.
    (Checked before writing: the net is on U2 pin PC3/PC4, referenced by pin NAME rather than pad
    number - which is why a first grep for pin="29"/"44" found nothing and nearly produced a wrong
    conclus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
    [main.cpp]
2026-10-07 chore(#22): re-check the unresolved part numbers with the right distributor scope
    The first sweep restricted itself to DigiKey, which silently excluded the Chinese manufacturers -
    Fenghua Advanced and Walsin among them - whose parts are carried by LCSC rather than DigiKey. Three
    part numbers I had privately written off as probably-generic codes (0201B103K250NT, 0201X334M6R3CT,
    0201CG101J500NT) are real and stocked: LCSC C285010, DigiKey/Walsin, and LCSC C62550 respectively.
    Re-checking the 27 unresolved with LCSC, Mouser, TTI and DigiKey in scope resolves 19 more. Eight
    remain - five Yageo RC0201FR-07 and three Murata GRM033 - and their SERIES is confirmed at DigiKey
    via known-good siblin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
    [bom_orderability.csv]
2026-10-07 docs(#22): the production BOM errata sheet, and restore the verified list
    The verified list lost its earlier entries when I rewrote it - a 'cut at the last marker' that
    discarded everything after the first one. Restored from git and re-appended, so the count is now
    171 of 179 rows rather than the 62 the broken file produced.
    BOM_ERRATA.md is the deliverable this issue asks for, attached to the PO:
    * 171 of 179 rows resolve at an authorised distributor (95.5%); 8 unchecked, all standard Yageo
    RC0201FR-07 and Murata GRM033 whose SERIES is confirmed at DigiKey via known-good siblings, so
    what is missing is the SKU page and not the part;
    * no substitution requires a footprint chan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
    [bom_orderability.csv]
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2026-10-07 fix(bom): correct five Yageo value codes to their E96 forms (#22)
    The errata found that RC0201FR / RC0402FR are Yageo's 1% (F) = E96 series and that none of the five
    values in the BOM is an E96 code - while the nearest E96 value resolves at a distributor in every case
    and the BOM's form resolves nowhere. This applies the correction.
    2.443k / RC0201FR-072K44L -> 2.43k / RC0201FR-072K43L (26 designators)
    3k2 / RC0201FR-073K2L -> 3.16k / RC0201FR-073K16L (R33)
    500R / RC0201FR-07500RL -> 499R / RC0201FR-07499RL (R110, R112-R114)
    840R / RC0201FR-07840RL -> 845R / RC0201FR-07845RL (R78-R81)
    830R / RC0402FR-07830RL -> 825R / RC0402FR-07825RL (R36)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
    [BOM_Main_Board.xlsx, MainBoard_bom.csv, MainBoard_bom_summary.csv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]
2026-10-07 fix(#17 #21): name the clock nets the issue suspected, and research the PA decision inputs
    #17 - the parenthetical in the issue ("AD9523_OUT6 is nearly as thin (only R39)") is a symptom, not a
    fault. Tracing it: the chain is complete - IC1.OUT6 -> R39 (22R) -> C15 (10nF) -> J7 - and it is
    structurally identical to OUT10 (R40) and OUT11 (R41), which nobody questioned. What made it read as
    a fault is that the driver side of the series resistor carries an anonymous N$ name, so a reader
    checking the netlist sees a connector with no source.
    So the fix is the naming, not the wiring: N$62 -> AD9523_OUT6_DRV, N$63 -> AD9523_OUT6_SER,
    N$65 -> AD9523_OUT10_SER, N$68 -> AD9523_OUT11_SER, in both the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
    [Clocks_Freq_Synth_board.brd, Clocks_Freq_Synth_board.sch]
2026-10-07 fix(bom): replace three Murata part numbers that do not exist (#22)
    The last three rows were recorded earlier as "a search limit rather than a BOM defect". That was
    wrong. DigiKey's own product search returns 0 results for all three, and for two of them offers a
    different capacitance as "did you mean" - the signature of a part number that does not exist rather
    than one that is merely hard to find.
    Each replacement was found by searching the real part-number prefix at DigiKey, so each is a stocked
    Murata part with the same capacitance, dielectric and case size:
    GRM033R60J475ME47D 4.7uF 6.3V X5R 0201 -> GRM033R60J475ME05D (real suffix ME05, not ME47)
    GRM033R71E472KA88D 4.7nF 25V X7R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
    [BOM_Main_Board.xlsx, bom_orderability.csv]
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

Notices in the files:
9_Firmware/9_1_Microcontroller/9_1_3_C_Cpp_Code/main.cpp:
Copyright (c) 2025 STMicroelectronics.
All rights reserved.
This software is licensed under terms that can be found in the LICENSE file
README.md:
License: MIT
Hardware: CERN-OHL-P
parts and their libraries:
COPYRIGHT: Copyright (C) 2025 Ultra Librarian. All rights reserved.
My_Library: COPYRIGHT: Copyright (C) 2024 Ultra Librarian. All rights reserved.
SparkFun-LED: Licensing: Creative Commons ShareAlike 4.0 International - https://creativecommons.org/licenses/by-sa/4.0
